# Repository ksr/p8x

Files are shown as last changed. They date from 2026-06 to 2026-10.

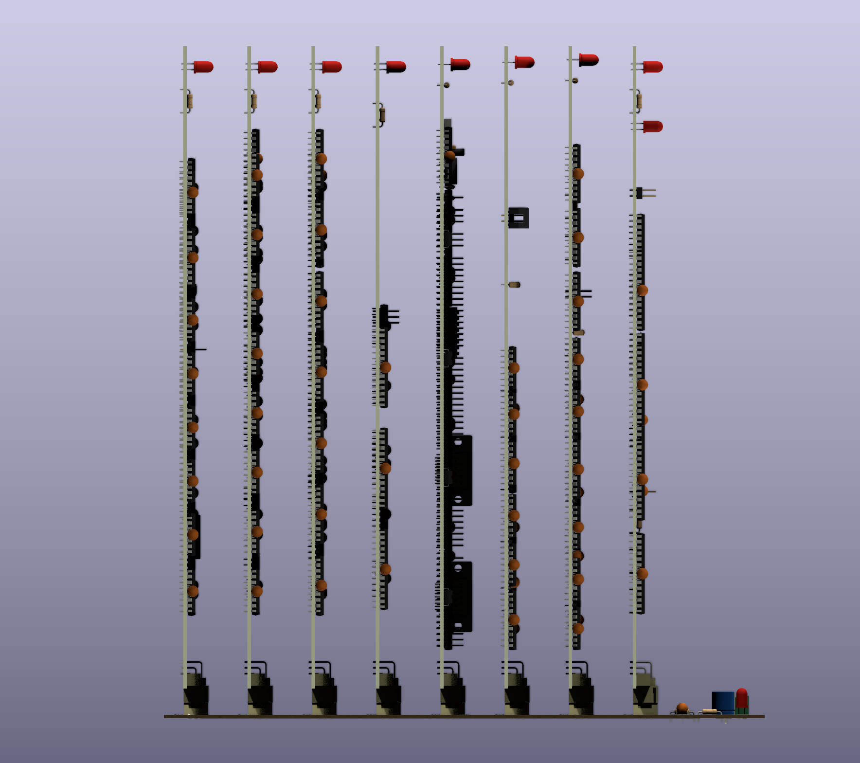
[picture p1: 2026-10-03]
hardware/assembly/p8x-assembly-render-side.png

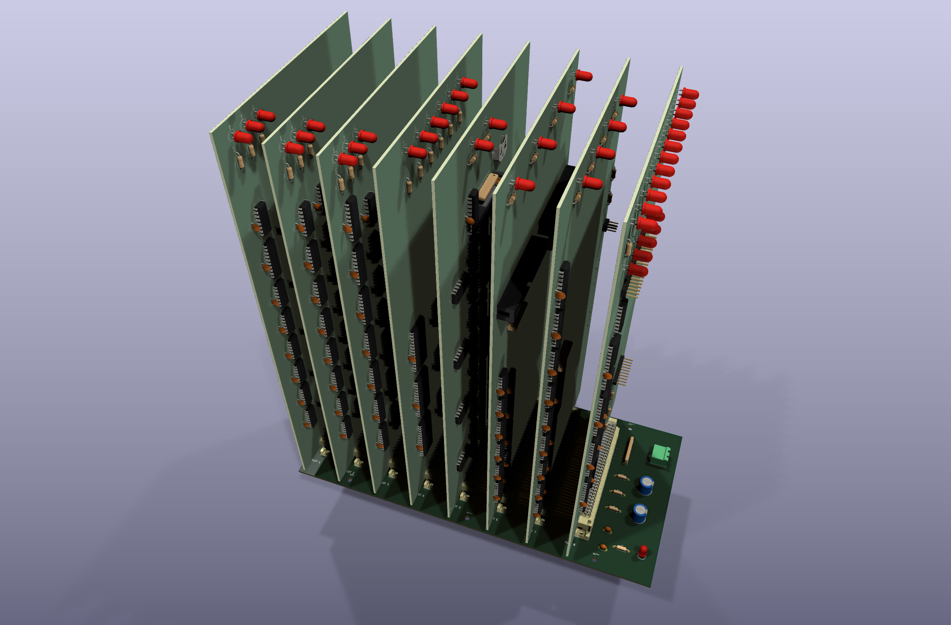
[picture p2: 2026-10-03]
hardware/assembly/p8x-assembly-render.png

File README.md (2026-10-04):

# P8X — Hand-Built 8-Bit TTL CPU

A from-scratch 8-bit CPU built from ~130 74HCT logic chips on an 8-slot DIN41612 backplane. Fully microcoded; the microcode ROM images burned to the EPROMs are the same images the emulator interprets.

The machine now exists **twice**: as the TTL card set, and as an [FPGA
implementation](fpga/) of the same microarchitecture that boots the same
unmodified monitor, OS and toolchain. Both run the microcode from
`microcode/genucode.py`, and the C emulator is the golden reference for both.

The FPGA build also carries a **PGC-class graphics engine** (480x272
RGB565 panel, hardware 3D transforms, command lists, a fabric-parsed
graphics language modeled on the Matrox PG-640A) — see the
[theory of operation](docs/p8x-graphics-theory.md) and the
[graphics programmer's guide](docs/p8x-graphics-guide.md).

New to the abbreviations and signal names? See [GLOSSARY.md](GLOSSARY.md).

**Who made it:** I designed P8X, and it runs on an FPGA. Claude, Anthropic's AI, has been directly involved in its design, coding and documentation. — Ken Rother

## Architecture

- **8-bit data bus, 16-bit address bus**
- **4 × 16-bit pointer registers** (74169 up/down counters): P0 = PC, P1/P2 = general-purpose, P3 = stack pointer (empty-descending). The address bus is *always* driven by one of these — no separate MAR.
- **Registers:** A, B (ALU operands), T/T2 (hidden microcode temporaries), FLAGS (C, Z, N, V)
- **ALU:** 2 × 74181 + 74182 carry-lookahead, with a post-ALU shifter
- **Microcoded control:** 4 × 28C64 EEPROMs; ROM address = IR | step<<8 | cond<<12; **143 opcodes** defined in `microcode/genucode.py` (256 encodings available)
- **Memory map (rev E):** `$0000–$17FF` ROM (6 KB; shrunk from 8 KB 2026-09-14), `$1800–$FEFF` RAM (2× 62256; $1800–$1FFF is a scratch island), `$FF00–$FFFF` I/O (every data address is single-sourced in [`generators/gen_memmap.py`](generators/gen_memmap.py) → `memmap.inc`/`.h`/`.py`; commands pull the scratch/graphics/TPA-base symbols via `//#use mem`)

## Cards

The TTL machine is six core cards plus a PS/2 input card on the backplane, and a
bus test card for bring-up. Every board is designed and routed in **KiCad** (4-layer;
the plug-in cards are 280 × 140 mm) with orderable Gerbers in `hardware/<board>/kicad/`;
none has been fabricated yet. See [hardware/KICAD-BOARDS.md](hardware/KICAD-BOARDS.md)
and [hardware/RECONCILIATION.md](hardware/RECONCILIATION.md) (build readiness).

| Card | Function |
|---|---|
| Control / Microcode | Clock, reset, sequencer, microcode EPROMs, IR, condition mux, front-panel |
| Register Bank | P0–P3 16-bit pointer registers, address bus drivers |
| ALU | A, B, T, T2 registers; 74181 ALU; shifter; FLAGS |
| Memory | 28C256 EEPROM (6 KB ROM window) + 2× 62256 SRAM, address decode (rev F) |
| I/O | Switches, LEDs, bus monitor, two 6850 ACIAs (RS-232, two DB9s) |
| CF-IDE | Two CompactFlash drives in 8-bit True IDE mode, at $FF10–$FF17 and $FF18–$FF1F |
| PS/2 | Keyboard + mouse ports at $FF58–$FF5F; an ATmega1284P behind a latch bridge |
| Bus test | Bring-up tool: a Raspberry Pi Pico drives the bus one microcycle at a time over USB |

The cards plug into a passive 8-slot backplane over a 96-pin DIN 41612 bus (rev C2).
The Eagle CAD of the first board generation is frozen (rev E) in each board's
`eagle-deprecated/` directory.

## Toolchain

| Tool | Location | Purpose |
|---|---|---|
| `microcode/genucode.py` | `microcode/` | Microcode generator → `u0–u3.bin` EPROM images |
| `assembler/p8xasm.py` | `assembler/` | Two-pass assembler, shares opcode table with genucode.py |
| `emulator/p8xemu.c` | `emulator/` | Cycle-accurate emulator, interprets the same u0–u3.bin images |
| `firmware/p8xmon.asm` | `firmware/` | ROM monitor (E/D/I/F/B/G/? commands) + BIOS jump table at `$0100` |
| `os/p8xos.asm` | `os/` | P8X/OS, RAM-resident disk OS booted from CF ([guide](os/README.md)) |
| `tools/p8xfs.py` | `tools/` | Host-side P8XFS disk-image tool (create/boot/put/get/ls) |
| `basic/p8xbasic.asm` | `basic/` | BASIC interpreter — disk-bootable or run-from-OS builds ([guide](basic/README.md)) |
| `apps/p8xedit.asm`, `apps/p8xasm.asm`, `apps/p8xcc.asm` | `apps/` | On-target toolchain: line editor + native two-pass assembler + native C compiler (`cc`), as `/bin` programs ([guide](apps/README.md)) |
| `compiler/p8cc.py` | `compiler/` | C cross-compiler (subset) → P8X asm → RUNnable `.bin` ([guide](compiler/README.md)) |
| `generators/gen_p8xopc.py` | `generators/` | Opcode table for the native assembler, generated from `genucode.OPC` |
| `generators/gen_eagle.py` | `generators/` | The canonical board netlists (`CARDS`, `busnet()`); its Eagle output is frozen at rev E |
| `generators/gen_kicad.py`, `build.sh` | `generators/` | KiCad boards from those netlists: placement, Freerouting, Gerbers, and the ERC/DRC readiness check |

**Generators are canon.** Never hand-edit board files (`.kicad_pcb`, and the frozen Eagle `.sch`/`.brd`) or ROM binaries — they are build artifacts. Edit the generator and regenerate. See [generators/README.md](generators/README.md) for what each script does and how to run it.

## Quick Start

Setting up a new machine? See [SETUP.md](SETUP.md) for the full toolchain, tier by
tier, and run `python3 tools/setup_check.py` to see what is installed and what each
work area still needs. Only the core-software tier is required to build and test.

```sh
# Build the emulator and regenerate microcode images
cd emulator && make

# Run the smoke tests (message print, JSR/RTS round-trip, branch countdown)
make test

# Rebuild a KiCad board: placement -> Freerouting -> Gerbers + renders -> the
# ERC/gate-sim/DRC/keepout/fab readiness check (needs KiCad 10 and a Freerouting
# jar; `all` builds every board). The netlists come from generators/gen_eagle.py.
cd ..
sh generators/build.sh memory-card
sh generators/check_card.sh memory-card          # the readiness check alone

# Reference PDFs (run from anywhere):
cd hardware
python3 ../generators/gen_bus_pdf.py              # bus definition PDF (hardware/backplane/)
python3 ../microcode/gen_progguide.py             # programmer's guide (-> docs/)
```

### EEPROM / programmer images

Both build paths emit **Intel HEX** alongside the raw `.bin`, for loading into an
EEPROM programmer:

- **Microcode** — `microcode/genucode.py` writes `u0–u3.bin` (what the emulator
  and tests load); the matching Intel HEX for the four 28C64 control-store EPROMs
  is produced into `rom/` by `make rom` (see below).
- **Program ROM** — the assembled monitor + BIOS for the 28C256 at `$0000`
  (about 4.9 KB of the 6 KB window; BASIC is no longer ROM-resident). `make rom` builds it into `rom/`.
- **Any other binary** — `python3 tools/bin2hex.py in.bin out.hex [base]`
  (e.g. a monitor built directly with `p8xasm.py`).

For a ready-to-burn set at fixed paths, run `cd emulator && make rom` (or
`sh tools/build_rom.sh`). It refreshes the four control-store EPROMs in
`microcode/` and writes the program ROM to `rom/p8x-prog-rom.{bin,hex}`. Both
are committed; see [rom/README.md](rom/README.md) for the chip map.

## Documentation

The documents below are also built into the project website, [p8x.cottageworker.com](https://p8x.cottageworker.com) (`website/`, MkDocs; published on every push to `main`).

| Document | Description |
|---|---|
| [hardware/backplane/p8x-bus-definition.md](hardware/backplane/p8x-bus-definition.md) | Authoritative 96-pin bus pinout, signal descriptions, DOE/DLD encoding, microcode word layout |
| [hardware/backplane/p8x-backplane-design.md](hardware/backplane/p8x-backplane-design.md) | PCB stackup, termination analysis, BOM |
| [docs/p8x-card-standards.md](docs/p8x-card-standards.md) | Design rules that apply to every plug-in card |
| [docs/p8x-system-design.md](docs/p8x-system-design.md) | System and card-by-card architecture reference |
| [hardware/cf-card/p8x-cf-os-design.md](hardware/cf-card/p8x-cf-os-design.md) | CF-IDE hardware + P8X/OS design |
| [hardware/cf-card/p8xfs-v2-hierarchical.md](hardware/cf-card/p8xfs-v2-hierarchical.md) | P8XFS v2 hierarchical filesystem spec |
| [docs/p8x-programmers-guide.pdf](docs/p8x-programmers-guide.pdf) | Generated instruction set reference |
| [basic/p8x-basic-guide.md](basic/p8x-basic-guide.md) | P8X BASIC language reference (statements, expressions, graphics, examples) |
| [fpga/README.md](fpga/README.md) | FPGA build: milestones, getting started, both paths |
| [fpga/docs/architecture.md](fpga/docs/architecture.md) | FPGA module hierarchy, peripheral map, graphics, co-sim spec |
| [fpga/rtl/README.md](fpga/rtl/README.md) | What is shared vs sim-only, and the `cen` / `sc_en` contracts |
| [fpga/sim/README.md](fpga/sim/README.md) | How the co-sim trace-diff works, and the graphics frame diff |
| [BACKLOG.md](BACKLOG.md) | Live work only: NEXT / IDEAS / VERIFY / WONT-DO |
| [BACKLOG-DONE.md](BACKLOG-DONE.md) | Completed work + the project log |

### Per-card guides

Each board has its own directory under `hardware/` holding everything about it —
the KiCad board and its Gerbers, placement PDF and renders (`kicad/`), a README
explaining how the circuit works chip by chip, any board-specific design docs, and
the frozen Eagle files (`eagle-deprecated/`):

| Card | Directory |
|---|---|
| Control / Microcode | [hardware/control-card/](hardware/control-card/README.md) |
| Register Bank | [hardware/regbank-card/](hardware/regbank-card/README.md) |
| ALU | [hardware/alu-card/](hardware/alu-card/README.md) |
| Memory | [hardware/memory-card/](hardware/memory-card/README.md) |
| I/O | [hardware/io-card/](hardware/io-card/README.md) |
| CF-IDE | [hardware/cf-card/](hardware/cf-card/README.md) |
| PS/2 | [hardware/ps2-card/](hardware/ps2-card/README.md) |
| Bus test | [hardware/bustest-card/](hardware/bustest-card/p8x-bustest-card-design.md) |
| Backplane | [hardware/backplane/](hardware/backplane/p8x-backplane-design.md) |

## FPGA implementation

A standalone [FPGA build](fpga/) on a **Sipeed Tang Nano 20K** (Gowin GW2AR-18)
runs the whole machine — CPU, memory, ACIA console, microSD disk, and a 4.3"
480x272 graphics panel — from one chip and a USB cable. It is a **parallel track to the TTL build, not a replacement**:
same horizontal microcode word, same sequencer, same pointer/address model, so
the monitor, OS, BASIC, C compiler and assembler run **unmodified**.

| Milestone | State |
|---|---|
| 0 First light (UART echo + heartbeat) | done |
| 1 CPU core in simulation, all 88 opcodes of the time | done |
| 2 ACIA + driven console in simulation | done |
| 3 Core on real hardware, full 64K map | done |
| 4 microSD disk — P8X/OS boots from card | done |
| 5 Clock-up + IRQ | next |
| 6 Graphics: 480x272 panel + drawing engine | done |

As built: **9 MHz** effective (27 MHz fabric, three phases per microcycle). The
CPU-only build is 40/46 block RAMs at ~48 MHz Fmax; adding the graphics panel takes
it to 44/46 and 13288/20736 LUT4, with Fmax measured at 38.8 MHz — still four times
the clock it runs at. P8X is programmed into the board's flash, so it comes up
standalone on power.

**Graphics** (`build.sh lcd`) adds the panel's native 480×272 framebuffer in
**RGB565 direct colour** — a pixel IS its colour, 65,536 of them — living in
the Tang Nano's in-package SDRAM behind a streaming controller, with a drawing
engine driven by BASIC in one window-space coordinate system (y up, the
PGC's own): `COLOR r,g,b` (or one packed value), `CLS`, `PIXELW`, `LINE`,
`BOX`, `CIRCLE` (a second radius gives an ellipse), `IMAGE` (draws a
P8I picture file — `tools/p8img.py` converts anything into one), the
`PIXELR(x,y)` and `RGB(r,g,b)` functions — plus the full PGC graphics
language as native statements (`MOVE`/`DRAW`/`POLY`/`RECT`, matrices, 3D,
command lists; see `man basic`). Text is the PGC's own stroke `TEXT`,
drawn card-side from the font the OS streams from `/FONT.GL` at boot
(GTEXT and its software rasterizer retired 2026-09-01). The drawing
statements emit that language; the engine lives in the device, so a
filled box costs the same handful of instructions as an empty one.
There is one geometry and no modes or palette to manage.
The same device is modelled in `p8xemu`, and the two are byte-compared frame
by frame.

**3D** (stages 7–8, `fpga/tang-nano-20k/sdram/STAGE*.md`): a wireframe
pipeline available three ways from C — all in software (`//#use gfx` +
`//#use g3d`), accelerated by the **MDU** (a memory-mapped hardware
multiply-divide unit at `$FF30`), or fully in fabric via the **geometry
engine** (`$FF40`): edge lists in SDRAM, an S7.8 matrix, one command to
transform/clip/project/draw, and page-flipped double buffering. The same
program picks the fastest fitted path at runtime; `cube` on the shipped disk
demonstrates all of them (`man cube`, `man g3d`).

**Verification is the point.** Every milestone is "make the RTL match the
emulator": the same program runs on both and their per-cycle architectural state
is diffed, so a divergence is a bug with an exact microcycle and signal rather
than a mystery. `fpga/sim/isa_test.asm` drives the original 88 opcodes through that diff;
the 55 added since are microcode only (no new hardware), and the RTL runs them from
the same images.

```sh
fpga/sim/run.sh 60000 isa_test.asm          # co-sim, the original 88 opcodes
fpga/sim/console.sh "" os/run-disk.img      # interactive console on the RTL
fpga/tang-nano-20k/build.sh cpu load        # build + program the board
```

## Status

- Emulator working: 143 opcodes, ACIA on stdin/stdout, CF-IDE disk model (`-c <img>`), interactive I/O card (switches `-s`, LED trace `-L`), verified against microcode images
- Assembler working: two-pass, full expression support, shares opcode table with microcode generator
- KiCad boards designed and routed for the six CPU cards, the PS/2 card, the bus test card and the backplane (9 boards, 0 unconnected, Gerbers in each `kicad/`); none fabricated yet. The Eagle files of the first generation are frozen in `eagle-deprecated/`. (The standalone LED test card was a CAD-workflow trial, never built — deprecated and moved to `hardware/deprecated/led-card/`; its I/O address `$FF0C` is now free.)
- ROM monitor boots in the emulator; its filesystem hooks (`I`/`F`/`B`) run end to end against a CF image (`make test-cf`)
- P8X/OS v1.0 — full shell over flat **and hierarchical (P8XFS v2)** volumes. Built-in commands: `cd`/`mkdir`/`rmdir`/`load`/`run`/`save`/`del`/`path`/`pack`/`fsck`/`format`/`mount`/`umount`/`help`/`exit`/`man`/`sh`/`make`/`bootload` (`make` builds a target from a CWD `Makefile`; `bootload file` installs a freshly-built OS image into the boot sectors so the next `exit`+`B` runs it — the on-target OS-update step, closing the self-hosting loop) (the minimal-kernel split moved the pure-viewer/memory commands to `/bin`, including `dump`/`dep` — only `pack`/`fsck` remain resident because they mutate/scan the filesystem). **Dual CompactFlash** — a second card is **mounted at `/d1`** in one unified namespace (drive 0 is the root), so ordinary paths reach it with drive-unaware commands: `cd /d1`, `cat /d1/NOTES`, `grep x /d1/SRC/*.C`, cross-mount `cp /d1/A /B`. A single mount redirect in `FRESOLVE`/`RV_START` does the routing; **`cp -r /d1/dir /dir`** recursively copies a subtree across the mount (card provisioning), creating directories via the `SYS_MKDIR` syscall. **Userland commands in `/bin`** (written in C, run by bare name via implicit RUN + a `/bin` search PATH, or explicit `run`): **`dir`/`pwd`/`tree`/`cat`/`wc`/`grep`/`cp`/`mv`/`head`/`tail`/`more`/`sort`/`uniq`/`sed`/`awk`/`find`/`diff`/`cmp`/`vi`/`touch`/`man`/`dump`/`dep`/`examine`/`disasm`** (`dir README.TXT` lists a file / `dir R*` a glob, `dir -R`, `cp -r`, a VT100 `vi` screen editor, `man <cmd>` reading `/man`, `awk '{print $2}'` field processing, `examine` = interactive memory examine/modify like the monitor's `E`, etc.) — see [os/commands/](os/commands/README.md). Path resolution + CWD-path prompt; I/O redirection (`<`/`>`) and two-stage pipes (`a | b`); line editing (backspace/DEL, Ctrl-D EOF, **up/down-arrow command history** — an 8-line RAM ring — and **Tab autocomplete** of commands/paths with common-prefix fill + a match list on the second Tab); **`pack`** compacts the directory tree and **`fsck`** checks integrity on-target; host-side `p8xfs.py` builds (`--v2`), navigates, and `fsck`s images (`make test-os`)
- BASIC builds two ways from one source: disk-bootable (`B`) and a run-from-OS TPA program (`run BASIC.bin`) — `make test-basic` (ROM-resident BASIC was removed to reclaim ROM space; the old standalone `$0000` build was retired in 2026-08 when BASIC's console I/O moved onto the BIOS, which needs the monitor resident)
- On-target toolchain: **EDIT** (line editor) + **ASM** (native two-pass assembler) + **CC** (a from-scratch C compiler written in asm) as `/bin` programs — edit → **compile (`cc x.c >x.asm`)** → assemble → run a program entirely on the machine; ASM output is byte-identical to the host assembler across the whole opcode table (`make test-os`, see [apps/](apps/README.md)). **Rebuild any command on-target** — every command's source rides along under `/src/commands/{c,asm}` (plus shared `lib_*` helpers), each dir carrying a real **`Makefile`** (`target: deps` + TAB recipe, with `all`/`clean`/`install` targets). The **`make`** built-in reads the CWD `Makefile`, resolves prerequisites depth-first (shared deps built once), and drives `cc`→`asm` (or `asm` alone): `cd /src/commands/c && make pwd` rebuilds one command, `make all` the whole dir into `bin/`, `make install` publishes them over `/bin`, `make clean` removes the build outputs — see [os/commands/](os/commands/README.md). (P8X shell scripts end in `.sh`; `make` uses proper Makefiles.)
- **Native C compiler — Milestone B achieved.** `apps/p8xcc.asm` (`/bin/cc`) is a from-scratch, single-pass C compiler written directly in assembly, small enough to compile C **entirely on the machine** (front *and* back end) where the optimizing `p8cc.c` codegen — ~82 KB, larger than the whole 64 KB address space — never could. Through v0.28 it covers: functions, direct **and mutual** recursion, pointers + pass-by-reference, `int`/`char` arrays with `[]` and decay, **structs** (`.`/`->`), globals, the full operator set (`+ - * / % << >> & ^ | && || ?:`, `++`/`--`/`+=`/`-=`, comparisons, unary `- ! * &`), hex/char/string literals with escapes, `//`+`/* */` comments, a recursive **`//#use`** preprocessor (splices `/lib/lib_*.c`) plus object-like **`//#define`** macros (e.g. `//#use abi` names the BIOS/OS addresses so a command writes `bios(FOPEN, RDBUF, 0)`), and the `putchar`/`puts`/`getchar`/`peek`/`poke`/`argstr`/`bios` builtins. It compiles real OS command source: **`pwd.c` → `cc` → `asm` → runs** correctly on-target. Known gaps are listed under "cc — KNOWN LIMITATIONS" in `BACKLOG-DONE.md` (with the Milestone A/B record).
- **Host C compiler** — `compiler/p8cc.py` (the primary build tool: every `/bin` command is compiled with it) plus `compiler/p8cc.c`, the same compiler rewritten in its own subset that **self-compiles** ("small C in small C", Milestone A). Full subset incl. `struct`/`union`, global initializers, and the operators above (`make test-c`, host-vs-self differential `c_selfhost_test`, see [compiler/](compiler/README.md)).
- BIOS **file API**: byte streams (`FOPEN`/`FGETB`, `FWOPEN`/`FPUTB`/`FCLOSE`), path resolution into subdirectories (`FRESOLVE`), name formatting (`FNORM`), and directory iteration (`FOPENDIR`/`FNEXT`) — the assembler rides on the streams and self-hosts (`make test-cf`)
- **FPGA (Tang Nano 20K):** the same microarchitecture in Verilog, verified against the emulator cycle-for-cycle across the original 88 opcodes, then run on real hardware — monitor over USB serial, full 64K map, and **P8X/OS booting from a microSD** with the whole `/bin` toolchain. The board wrote its own disk: `fpga/tang-nano-20k/tools/imgload.asm` streams a P8XFS image over the console and writes it with `CFWRITE`, so no host root or card reader is needed. See [fpga/](fpga/README.md)
- **Next:** multi-stage pipes (`a | b | c`); open-by-name as one syscall (`SYS_OPEN`); the IRQ-controller hardware card; hardware bring-up (DIN 41612 footprint check against the physical connectors, order the backplane first); FPGA milestone 5 (clock-up + IRQ). Current state in [docs/p8x-status.md](docs/p8x-status.md), the working list in [BACKLOG.md](BACKLOG.md)

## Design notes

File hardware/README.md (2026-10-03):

# hardware/

The physical machine: one passive backplane, six plug-in CPU cards, a PS/2 input
card, and a bus test card for bring-up. Each board has its own directory holding a
chip-by-chip README, a theory of operation or design doc, and the **KiCad** board
(`kicad/`: the `.kicad_pcb`, the Freerouting session, orderable Gerbers, a
placement PDF and renders). Every board is designed and routed; none has been
fabricated yet. Board status: **[KICAD-BOARDS.md](KICAD-BOARDS.md)**; build
readiness against the emulator and the FPGA: **[RECONCILIATION.md](RECONCILIATION.md)**.

| Board | Directory | Function |
|---|---|---|
| Control / Microcode | [control-card/](control-card/README.md) | Clock, reset, sequencer, microcode EPROMs, IR, condition mux, front panel |
| Register Bank | [regbank-card/](regbank-card/README.md) | P0–P3 16-bit pointer registers, address-bus drivers |
| ALU | [alu-card/](alu-card/README.md) | A/B/T/T2 registers, 74181 ALU, shifter, FLAGS |
| Memory | [memory-card/](memory-card/README.md) | 28C256 ROM (6 KB window, `$0000–$17FF`) + 2× 62256 SRAM, address decode (rev F) |
| I/O | [io-card/](io-card/README.md) | Switches, LEDs, bus monitor, two 6850 ACIAs (`$FF04/05`, `$FF08/09`) with two DB9s (rev B) |
| CF-IDE | [cf-card/](cf-card/README.md) | Two CompactFlash drives in 8-bit True IDE mode: `$FF10–$FF17` and `$FF18–$FF1F` (rev B) |
| PS/2 | [ps2-card/](ps2-card/README.md) | Keyboard + mouse at `$FF58–$FF5F`: an ATmega1284P behind a latch bridge (rev A) |
| Bus test | [bustest-card/](bustest-card/p8x-bustest-card-design.md) | Bring-up tool: a Raspberry Pi Pico drives the bus over USB, one microcycle at a time |
| Backplane | [backplane/](backplane/p8x-backplane-design.md) | 8-slot passive 96-pin DIN 41612 bus (rev C2), 262 × 128 mm |

The plug-in cards are all 280 × 140 mm, 4-layer (signals on the outer layers, GND
and +5 V planes inside).

**Eagle (frozen).** The first board generation was drawn in Eagle/Fusion from
`generators/gen_eagle.py`. On 2026-09-18 the KiCad flow replaced it: each board's
Eagle `.sch`/`.brd` and its schematic and placement PDFs moved to
`<board>/eagle-deprecated/`, frozen at rev E, and are no longer maintained (the
Eagle memory card still carries the old 8 KB ROM decode; the KiCad rev F board has
the 6 KB one). `gen_eagle.py` stays the source of the netlists.

> **Deprecated:** the standalone **LED test card** (a write-only 8-LED output
> latch that decoded `$FF0C`) was a CAD-workflow trial, never built. It has been
> moved to [`deprecated/led-card/`](deprecated/led-card/) and its I/O address
> `$FF0C` is now free. (This is unrelated to the `$FF02` LED latch the emulator
> traces, which stays.) The combined I/O + CF + PS/2 **peripheral card** is parked
> in `parked/peripheral-card/` (2026-09-19); the design went back to three cards.

### Not yet realised as TTL boards
See **[RECONCILIATION.md](RECONCILIATION.md)** for the full board-vs-emulator/FPGA
build-readiness pass. Subsystems the emulator and/or the FPGA already provide that
have **no TTL card** yet:

| Subsystem | Where it lives now | TTL board |
|---|---|---|
| MDU multiply/divide (`$FF30–$FF3F`) | emulator model + FPGA (`mdu_core.v`) | none yet |
| Graphics-language port (`$FF50–$FF54`) | emulator model + the Tang Nano 20K graphics card | none (the FPGA card *is* the graphics engine) |
| IRQ controller (`$FF06` device-IRQ model) | emulator model | none yet — the next card to design |

**[assembly/](assembly/README.md)** — 3D renders of the assembled machine: the
backplane with all eight cards standing in their slots, each card populated
(rendered from the boards by `generators/render_assembly.py`; slot order inside).

`p8x-bom.csv` — the orderable bill of materials for the whole machine
(ICs, sockets, connectors, passives), generated by
[`../generators/gen_bom.py`](../generators/).

## Rebuilding boards

**Generators are canon** — never hand-edit a `.kicad_pcb`. The netlists live in
[`../generators/gen_eagle.py`](../generators/) (`CARDS`, `busnet()`);
`gen_kicad.py` turns a card into a placed KiCad board (the memory, I/O, CF, PS/2
cards and the backplane have bespoke placement scripts in their `kicad/`
directories), Freerouting routes it, and `check_card.sh` runs the readiness check
(ERC, gate-level simulation where a testbench exists, DRC, mounting-hole keepout,
fab minimums). One command does all of it, from the repository root:

```sh
sh generators/build.sh memory-card      # one board (or: all)
sh generators/check_card.sh memory-card # the readiness check alone
```

It needs KiCad 10 and a Freerouting jar. See
[../generators/README.md](../generators/README.md) for the scripts and
[../docs/p8x-card-standards.md](../docs/p8x-card-standards.md) for the rules
every card follows.

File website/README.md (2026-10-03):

# website/ — the P8X project website

The project website is built from this repository's own documents with [MkDocs](https://www.mkdocs.org/) and the
[Material](https://squidfunk.github.io/mkdocs-material/) theme. The documents stay where they are; the site is
a readable view of them, with navigation and search.

| File | What |
|---|---|
| `home.md` | the visitor home page (the site's index) |
| `p8x-collage.jpg` | the home page's lead picture: the assembled-machine renders and the memory card (until there are photos of built boards) |
| `stage.py` | copies the documents the site uses into `stage/`, keeping their repository paths so the links between them work, and generates the extra pages |
| `hooks.py` | MkDocs hook: a link to a repository file that is not part of the site becomes a link to that file on GitHub (branch `main`) |
| `mkdocs.yml` | the site: navigation, theme, Markdown extensions |
| `mkdocs-publish.yml` | `mkdocs.yml` + the Google Analytics tag (G-X7P96DTCNE); only the published build carries it |
| `requirements.txt` | the Python packages, pinned |
| `build.sh` | stage + build (installs the packages into `venv/` on the first run, which needs the network) |

    website/build.sh            build into website/site/
    website/build.sh serve      ... and serve it at http://127.0.0.1:8766 (Ctrl-C stops it)
    website/build.sh publish    the build to publish (with Google Analytics)

`venv/`, `stage/` and `site/` are rebuilt each time and not committed. Previews leave the analytics tag out, so
looking at the site locally is not counted as a visit.

**Publishing.** `.github/workflows/website.yml` runs on every push to `main` (or by hand: Actions -> website -> Run
workflow): it builds `website/build.sh publish` on GitHub's machine, so every push proves the site builds. It deploys
to GitHub Pages only when the repository variable `PAGES_DEPLOY` is `true` (Settings -> Secrets and variables ->
Actions -> Variables) and Pages is on (Settings -> Pages -> Source: GitHub Actions); until then nothing is published.
The address will be `https://p8x.cottageworker.com` (a CNAME record at the domain's DNS host, Gandi, and the custom domain in
Settings -> Pages); `site_url` in `mkdocs-publish.yml` already names it.

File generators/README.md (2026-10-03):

# Generators

Python scripts that produce the P8X's boards, reference PDFs and shared tables from
code.

> **Generators are canon.** Board files (`.kicad_pcb`, and the frozen Eagle
> `.sch`/`.brd`), the schematic and reference PDFs and the ROM images are *build
> artifacts* — never hand-edit them. Change the generator and regenerate. See the
> project [CLAUDE.md](../CLAUDE.md) for the full rule set.

The PDF scripts need `reportlab` (`pip3 install reportlab`). The KiCad scripts run
under KiCad 10's bundled Python (they import `pcbnew`) and route with a Freerouting
jar (`FRJAR`, default `~/freerouting/freerouting.jar`).

## Boards (KiCad)

Every board is a 4-layer KiCad PCB in `hardware/<board>/kicad/` (signals on the
outer layers, GND and +5 V planes inside; plug-in cards 280 × 140 mm). The flow
replaced Eagle on 2026-09-18; see [`../hardware/KICAD-BOARDS.md`](../hardware/KICAD-BOARDS.md)
for the status of each board.

| Script | What it does |
|---|---|
| `gen_eagle.py` | **The netlists.** Device library (pin maps, packages), the 96-pin DIN 41612 bus map (`busnet()`), and every card's netlist (`CARDS`), imported by everything below. Its own Eagle output is frozen at rev E (see below). |
| `gen_kicad.py <card>` | Generic board builder: turns a `CARDS` netlist into a placed KiCad board — footprints, a bypass cap above each IC, the labelled LED bank, planes, outline |
| `hardware/<card>/kicad/gen_*.py` | Bespoke placement for the memory (`gen_mem.py`, which also applies the rev F 6 KB ROM decode), I/O (`gen_io.py`), CF (`gen_cf.py`) and PS/2 (`gen_ps2.py`) cards |
| `gen_backplane.py` | The backplane board (8 DIN 41612 sockets, power entry, bulk + per-slot caps, wired-OR pull-ups) |
| `kicad_tools.py` | DSN export, routing import, the heal steps after Freerouting, Gerbers and renders |
| `build_kicad_card.sh <card>` | The generic pipeline: generate → export DSN → Freerouting → import + stitch → Gerbers/renders → readiness check |
| `build.sh <card>` (or `all`) | One command per board: dispatches to the bespoke `kicad/build.sh` or to `build_kicad_card.sh` |
| `check_card.sh <card>` (or `all`) | The manufacture-readiness check: ERC, gate-level simulation (where a testbench exists), DRC, mounting-hole keepout, fab minimums → PASS/FAIL |
| `gen_erc.py` | The netlist electrical-rules check `check_card.sh` runs |
| `gen_bom.py` | The bill of materials → `hardware/p8x-bom.csv` |
| `render_assembly.py` | 3D renders of the assembled machine: each card exported as a STEP and seated in its backplane slot (transform derived from the connector pads and models) → `hardware/assembly/*.png`; driver `sh hardware/assembly/build.sh` |

```sh
sh generators/build.sh memory-card        # one board, build + verify
sh generators/build.sh all                # every board
sh generators/check_card.sh all           # the readiness check alone
```

### `gen_eagle.py` and the frozen Eagle boards

`gen_eagle.py` is the single source of truth for the hardware netlists. It also
still contains the Eagle emitter that drew the first board generation (Autodesk
Eagle/Fusion schematic + board pairs, forward-annotated but unplaced). Those files
were moved to each board's `eagle-deprecated/` directory on 2026-09-18 and are
frozen at rev E — the Eagle memory card keeps the old 8 KB ROM decode; the KiCad
rev F board has the 6 KB one. Running `gen_eagle.py` directly still writes the
Eagle pairs into per-board subdirectories of the current directory, so do not run
it from `hardware/` unless the Eagle files are what you want; the KiCad scripts
import it and do not need that step.

`render_traditional_auto.py` (schematic PDFs drawn from `CARDS`) and
`render_board_pdf.py` (placement views of the Eagle `.brd`) belong to the Eagle
flow; their PDFs are in the `eagle-deprecated/` directories with the boards. The
KiCad flow makes its own placement PDF per board.

## Reference documents and tables

| Script | Produces | Output |
|---|---|---|
| `gen_memmap.py` | **The memory map** — every data address: `memmap.inc` (assembler), `memmap.h` (C), `memmap.py`, and the command libraries `lib_mem.c`/`.inc` | `generators/`, `os/` |
| `gen_memmap_pdf.py` | The printable memory map | `docs/p8x-memory-map.pdf` |
| `gen_isa_card.py` | The instruction-set quick reference (Markdown + PDF), from `genucode.py` | `docs/p8x-isa-card.{md,pdf}` |
| `gen_bus_pdf.py` | Bus-definition PDF (pinout, DOE/DLD tables, microcode word layout) | `hardware/backplane/` |
| `gen_bus_card.py` | The bus reference card | `hardware/backplane/p8x-bus-card.pdf` |
| `render_bp_traditional.py` | Backplane schematic PDF (Eagle-era; the current copy is in `hardware/backplane/eagle-deprecated/`) | `hardware/backplane/` |
| `gen_p8xopc.py` | Opcode-table `.asm` for the native assembler (`OPCTAB`), from `genucode.OPC` | stdout / arg path |
| `gen_p8xdis.py` | The disassembler's opcode table, from `genucode.OPC` | `os/commands/lib_distab.c` (+ `.inc`) |
| `gen_glkw.py`, `gen_font.py`, `gen_chargen.py`, `gen_trig.py` | Graphics tables: the GL keyword table (`glkwtab.*`, `glvtab.inc`), the stroke font (`os/font.gl`), the text-overlay character generator (`chargen.h`/`.hex`), the trig tables (`trigtab.h`) | `generators/`, `basic/`, `os/` |
| `gen_logisim.py` | Logisim circuit export (proof of concept, memory card) | `hardware/memory-card/` |

`gen_p8xopc.py out.asm` emits the `(mnemonic, shape) → opcode` table that
[`apps/p8xasm.asm`](../apps/p8xasm.asm) (the on-target assembler) is built with;
the build concatenates it after the assembler logic. Sourcing it from
`genucode.OPC` keeps the native assembler's encodings locked to the microcode.

The programmer's guide (Markdown + PDF) is generated separately by
[`microcode/gen_progguide.py`](../microcode/gen_progguide.py).

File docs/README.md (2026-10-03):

# docs/

System-wide documentation. (Per-card guides live with their board under
[`../hardware/<card>/`](../hardware/); language and tool guides live next to
their source in `../basic/`, `../os/`, etc.)

| Document | Description |
|---|---|
| [p8x-status.md](p8x-status.md) | Where P8X stands (October 2026): what runs today, the TTL card set's state, what is next. The detail is in [`../BACKLOG.md`](../BACKLOG.md). |
| [p8x-system-design.md](p8x-system-design.md) | System and card-by-card architecture reference; §3.2 has the as-built control-word layout. |
| [p8x-card-standards.md](p8x-card-standards.md) | Design rules every plug-in card must follow (form factor, connector, decoupling, etc.). |
| [p8x-monitor.md](p8x-monitor.md) | ROM monitor command reference and memory map. |
| [p8x-graphics-theory.md](p8x-graphics-theory.md) | Graphics engine theory of operation — the machines inside the card, from bus window to panel. |
| [p8x-graphics-guide.md](p8x-graphics-guide.md) | Graphics programmer's guide — drawing from the shell, BASIC, C and assembly. |
| [p8x-programmers-guide.md](p8x-programmers-guide.md) | CPU programmer's guide (GENERATED — regenerate via `microcode/gen_progguide.py`, never edit; PDF twin beside it). |
| [p8x-isa-card.md](p8x-isa-card.md) | Instruction-set quick reference (GENERATED — `generators/gen_isa_card.py`; PDF twin beside it). |
| [mount-drives-design.md](mount-drives-design.md) | Design record for the Unix-style `/D1` mount of the second CF — shipped; kept for the reasoning. |
| [p8x-two-mode-design.md](p8x-two-mode-design.md) | Two-mode operation: the same OS runs headless-serial OR as a GL graphics desktop (Finder + full-screen apps), selected by a graphics-present flag. Design + phase log (P1–P5 shipped in the emulator). |
| [p8x-isa-c-extensions.md](p8x-isa-c-extensions.md) | **Design note (not shipped on the disk); Tier A implemented on the emulator 2026-09-11:** ISA additions to shrink `p8cc` output — Tier A pure-microcode ops (`(Pn+d8)` displacement addressing, 16-bit memory-word `LDW`/`STW`/`ADDW`/`SUBW`/`CMPW`/`INCW`/`DECW`, `LDPn #imm16`, `ADDP3`/`SUBP3`), Tier B one hardware register (frame pointer P4), Tier C a 16-bit accumulator — with opcodes, microcode step sketches, projected savings, ripple and open questions. Compiler-only wins (−15.1%) landed first; see BACKLOG. |
| [p8x-programmers-guide.pdf](p8x-programmers-guide.pdf) | Generated instruction-set reference (built by `../microcode/gen_progguide.py`). |

The **FPGA** track has its own documentation tree rather than living here:
[`../fpga/README.md`](../fpga/README.md) (milestones + layout),
[`../fpga/docs/architecture.md`](../fpga/docs/architecture.md) (module hierarchy,
memory/peripheral map, co-sim spec), [`../fpga/sim/README.md`](../fpga/sim/README.md)
(how the cycle-for-cycle diff against the emulator works) and
[`../fpga/tang-nano-20k/README.md`](../fpga/tang-nano-20k/README.md) (board build,
pinout, flashing).

The PDF is a generated artifact — regenerate it rather than editing:

```sh
python3 ../microcode/gen_progguide.py      # writes the guide PDF here
```

New to the abbreviations and signal names used throughout these docs? See the
root [GLOSSARY.md](../GLOSSARY.md).

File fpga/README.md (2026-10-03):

# P8X on FPGA

A **standalone** FPGA implementation of P8X — the whole machine (CPU, memory,
UART console, SD disk) in one FPGA, no backplane. It keeps the **same
microarchitecture** as the TTL build: the horizontal microcode word, the
sequencer, the pointer/address model, `DOE`/`DLD`/`PSEL` selects. The microcode
binary (from `microcode/genucode.py`) and the C emulator stay the reference, so
the monitor / OS / BASIC / C-compiler / assembler run **unmodified**.

This is a **parallel track** to the TTL / bus-connected hardware build, which
continues (just delayed). Nothing here touches `generators/` or the card designs.

Target board: **Sipeed Tang Nano 20K** (Gowin GW2AR-18). See
[`tang-nano-20k/`](tang-nano-20k/) for the board-specific files and the
Milestone-0 build.

## The verification spine

Every milestone is "make the RTL match the emulator." We run the **same program**
on an Icarus sim of the RTL and on the C emulator (`emulator/`), and **diff
architectural state** (PC, registers, flags, memory writes) cycle by cycle. The
emulator is the golden model; a divergence is a bug with an exact cycle and
signal. Same adversarial-diff discipline used elsewhere in the project.

## Getting started

Two independent paths. **The simulator needs no hardware** and is the whole of
Milestones 1-2; the board adds 0, 3 and 4.

### Prerequisites

| For | You need |
|-----|---|
| Everything | `python3`, a C compiler (Apple clang / gcc) |
| Simulation | **`iverilog`** — `brew install icarus-verilog` |
| The board | **oss-cad-suite** (yosys, nextpnr-himbaechel, apicula, openFPGALoader) |
| The board | a **Sipeed Tang Nano 20K** and a USB-C **data** cable |

oss-cad-suite is a tarball, not a package: download the `darwin-arm64` (or your
platform's) release from
[oss-cad-suite-build](https://github.com/YosysHQ/oss-cad-suite-build/releases),
extract to `~/oss-cad-suite`, then — on macOS, or every binary refuses to launch:

```sh
xattr -dr com.apple.quarantine ~/oss-cad-suite
```

No admin rights are needed for any of this; `build.sh` sources the environment
itself.

### Step 0 — build the emulator first (both paths need it)

The microcode images `u0-u3.bin` are build products and are **not** in the repo,
and the emulator is the co-sim's reference model. From the repo root:

```sh
cd emulator && make
```

### Path A — simulation only, no hardware

```sh
fpga/sim/run.sh 20000                        # monitor boot, RTL vs emulator
fpga/sim/run.sh 60000 isa_test.asm           # the original 88 opcodes
fpga/sim/run.sh 200000 "" console_in.txt     # driven monitor + console diff
fpga/sim/run.sh 2000000 "" boot_in.txt os/run-disk.img   # boots P8X/OS
```

Each prints `PASS: RTL matches emulator for N cycles`, or a `DIVERGENCE` dump
naming the exact microcycle. To drive the machine by hand instead of diffing:

```sh
fpga/sim/console.sh "" os/run-disk.img       # real terminal into the RTL
```

(The graphics engine is byte-compared against the emulator by the GL RTL
battery, `emulator/test/c_gl_rtl_test.sh` — the old `sim/gfx.sh` device-door
co-sim retired with the single-interface migration.)

`B` boots the OS, then `pwd` / `dir` / `cat README.TXT`. Ctrl-D or Ctrl-C quits.
Writes persist for the session — they land in `fpga/sim/work/disk.img`, a copy, so
your real image is untouched and your changes are replaced next launch.
It is slow but usable — roughly 30-50k CPU cycles/second.

### Path B — the real board

```sh
fpga/tang-nano-20k/build.sh cpu load     # build + program (volatile SRAM)
fpga/tang-nano-20k/build.sh cpu flash    # ... or persist it across power cycles
```

Then talk to it. The onboard bridge enumerates **two** serial devices and the
**higher-numbered one is the console** (the other is JTAG and returns garbage);
use `/dev/cu.*`, not `/dev/tty.*`:

```sh
tang-nano-20k/tools/term.py               # auto-picks the port; Ctrl-] quits
```

`term.py` is a dependency-free terminal that picks the console port for you and
quits with Ctrl-]. A stock terminal is equally fine —
`screen /dev/cu.usbserial-<N>1 115200`, exit with Ctrl-A then k — because the
firmware expands newlines itself (see [`docs/p8x-monitor.md`](../docs/p8x-monitor.md)).

Press Enter for the monitor's `*` prompt. `?` for help, `I` to identify the
microSD, `B` to boot the OS from it.

### Updating the board — TWO surfaces, not one

A change may live in either place, and a feature can need both:

| Surface | Carries | Update with |
|---|---|---|
| **bitstream** | CPU, microcode, monitor ROM, graphics RTL | `build.sh lcd load` |
| **SD card** | P8X/OS, `/bin`, BASIC | `tools/imgsend.py os/run-disk.img` |

The graphics ellipse is the cautionary example: it is RTL **and** a BASIC
statement. Rebuilding only the bitstream left the hardware understanding a
command that nothing on the card could issue, which presents as `?SYNTAX ERROR`
from BASIC — nothing about it points at the card being stale.

**Check `p8x_cpu.fs`'s timestamp after a build.** This concealed two separate
build failures here. The script itself is no longer the hole — it runs under
`set -euo pipefail` and each of synthesise / place-and-route / pack exits `1` on
failure, so `load` cannot be reached after a failed build. What remains is that
**`cpu` and `lcd` write the same `p8x_cpu.fs`**: a failed `lcd` build leaves the
previous file sitting there looking perfectly valid, and it may well be a `cpu`
bitstream with no graphics in it at all. Note also that a `| tail`-style pipeline
hides the exit status, which is how the failure reads as success. If a fix appears
to do nothing on the board, check the mtime before debugging anything else — and if that is current, reload once: a freshly loaded
bitstream has come up not answering more than once, and the same file loaded
again fixed it.

A card needs a P8XFS image on it. Writing one from the host needs root, so if you
do not have it the board can install its own over the serial console — see
[`tang-nano-20k/tools/`](tang-nano-20k/tools/README.md).

**If the board goes silent**, load the Milestone-0 echo bitstream
(`build.sh echo load`) as a known-good baseline; if that is silent too, the USB
bridge has wedged and a replug fixes it. After any replug, drain the port before
testing — the factory boot text sits buffered and reads like a reply.

## Milestones

| # | Milestone | Board? | Proves |
|---|---|---|---|
| **0** | First light: UART echo + heartbeat LED ✅ | yes | toolchain, bitstream, console path |
| **1** | CPU core in simulation ✅ | no | the microarchitecture is correct (all 88 opcodes) |
| **2** | Peripherals in simulation (ACIA-UART) ✅ | no | monitor boots to a sim console; console output diffed |
| **3** | Core on real hardware ✅ | yes | P8X talks over USB for real, full 64K map |
| **4** | SD disk (SD-over-SPI behind the BIOS block API) ✅ | yes | OS boots from SD, full FS |
| **5** | Polish: clock-up, IRQ (backlog #26), stretch goals | yes | performance + extras |
| **6** | Graphics: 480x272 panel + drawing engine ✅ | yes | BASIC draws on a real panel; the engine matches the emulator pixel for pixel across all three payloads |

Milestones 0–2 are most of the effort and only 0 needs the board — the CPU is
built and proven in simulation before the hardware ever runs it.

**Status 2026-08-12: 0–4 done.** P8X/OS boots from a microSD on the Tang Nano
20K. The CPU runs at 27/3 = 9 MHz (three fabric phases per microcycle, see
`tang-nano-20k/rtl/p8x_top.v`) with the full 64K map — affordable because the
microcode ROM is compacted from 8192 to 4096 words, so no SDRAM controller was
needed. Build and flash with `tang-nano-20k/build.sh cpu load`.

P8X is written to the board's **onboard flash**, so it comes up standalone on
power with no host involvement. (`build.sh cpu load` puts a build in volatile
SRAM instead, which is what you want while iterating — but note that a power
cycle then reverts to whatever is in flash, and the factory LiteX demo answers on
the same serial port and will silently swallow anything a script sends it.)

## Layout

```
fpga/
├── README.md                 this file
├── docs/architecture.md      module hierarchy, memory/peripheral map, co-sim spec
├── rtl/                      board-independent core (shared by sim and board)
│   ├── README.md             what is shared vs sim-only, and the `cen` contract
│   ├── p8x_cpu.v             the CPU. `cen` clock enable; otherwise one
│   │                         microcycle per clock, matching the emulator
│   ├── gfx.v                 graphics: registers, drawing engine, framebuffer
│   ├── video_rgb.v           480x272 panel timing + 2x-doubled scanout
│   └── p8x_soc.v             sim-only SoC: async-read arrays + modelled I/O
├── sim/                      co-simulation against the C emulator
│   ├── README.md             how the trace-diff works, and why -N exists
│   ├── run.sh                build + run + diff  [CYCLES] [ROM] [RX] [CF]
│   ├── console.sh            interactive console on the RTL (not diffed)
│   ├── mk_ucode_mem.py       4 ROM images → 32-bit ucode.hex
│   ├── tb_p8x.v              testbench: canonical per-cycle trace, ACIA, CF
│   ├── isa_test.asm          directed exerciser, the original 88 opcodes
│   └── console_in.txt, cf_id.txt, boot_in.txt   scripted keystrokes
└── tang-nano-20k/            the board build
    ├── README.md             toolchain, pinout, flashing, board-sim benches
    ├── build.sh              [echo|cpu|lcd] [build|load|flash]
    ├── mk_compact_ucode.py   8192→4096-word microcode remap (buys the 64K map)
    ├── tangnano20k.cst       pin constraints (verified)
    ├── rtl/
    │   ├── top.v             Milestone-0: UART echo + heartbeat
    │   ├── p8x_top.v         the real SoC: 3-phase microcycle, BRAM, ACIA, CF
    │   ├── uart.v            8N1 UART (TX+RX)
    │   ├── cf_sd.v           $FF10-$FF17 CF task file over the SD controller
    │   └── sd_spi.v          microSD in SPI mode: init, read block, write block
    ├── sim/                  board-level benches (see tang-nano-20k/README.md)
    │   ├── tb_top.v          Milestone-0 echo path
    │   ├── tb_p8x_top.v      whole board top: monitor + OS boot off a card
    │   ├── tb_video.v        panel frame geometry (480x272, 54.11 Hz)
    │   ├── tb_scanout.v      which fb pixel reaches which panel pixel
    │   ├── sd_model.v        behavioural SPI card, with +sdfail fault injection
    │   └── tb_sd_spi.v       sd_spi's error paths
    └── tools/                host-side helpers, none needing root
        ├── README.md
        ├── term.py           serial terminal; translates P8X's bare-LF output
        ├── osload.asm        N sectors → LBA 1.., patch OSCNT
        └── imgload.asm       clone a whole P8XFS image from LBA 0
```

## How we work

- RTL + testbenches + co-sim harness written here; board bitstreams flashed and
  reported from hardware.
- **Sim green before hardware** — never debug unproven RTL and an unproven board
  at once.
- Small commits into `fpga/`, docs alongside, emulator stays the spec.

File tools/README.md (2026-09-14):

# tools/

Host-side (Mac/PC) utilities for building images and managing disks.

| Tool | Purpose |
|---|---|
| `fput.py` | **The everyday transfer tool**: copy host files into the standard disk image (`os/run-disk.img`) — several at once, replacing existing names. The emulator mounts that image directly, so a put is live on its next boot; `--board` then clones the image to the FPGA's card via `imgsend`. |
| `p8xfs.py` | P8XFS disk-image tool — create, boot, put/get/rm/ls/mkdir/tree, and `fsck` disk images (v2 hierarchical, the only format; `rm` tombstones like the on-target FDELETE). `fput.py` is the friendly front end for the transfer case. |
| `p8img.py` | Convert any image (PNG/JPEG/…) to P8I, the display's own RGB565 format, for BASIC's `IMAGE` statement. Floyd–Steinberg dither by default; `--preview` renders what the panel will show. |
| `build_rom.sh` | Build the full persistent **burn set** into [`../rom/`](../rom/): the four control-store EPROM images and the program ROM (the assembled monitor — BASIC is no longer ROM-resident), each as `.bin` + `.hex`. Wired up as `make rom`. |
| `p8cc_sizes.sh` | **Compiler size benchmark**: compile every `/bin` C command through the `run.sh` pipeline (`clib.py` → `p8cc.py` → `p8xasm.py`) and print bytes per command plus a TOTAL; `FAIL` rows expose a compiler regression. Save a baseline before a codegen change and `diff` after. |
| `tierA_rewrite.py` | **Hand-asm Tier A pass**: rewrites the old byte-by-byte 16-bit idioms in a hand-written source (word moves, word constants, `TAPnL/H` pointer loads, `LDA #</#>` pointer constants, `INC`/`ADD #k`/`DEC` carry chains) into single `MOVW`/`LDW`/`LPWn`/`LDPn`/`INCW`/`ADDW`/`DECW` instructions -- only where the next executed instruction cannot observe the A/flags the old sequence left (`--allow` names callees that ignore A). Dry run by default; `--apply` writes in place. Emits native-parseable shapes only, so byte-identity with the on-target assembler holds. Always run the module's tests after it. |
| `bin2hex.py` | Convert any binary to Intel HEX for an EEPROM programmer. Importable (`write(data, path, base=0)`) or CLI (`bin2hex.py in.bin out.hex [base]`). |
| `mkbacklogpdf.py` | Render [`../BACKLOG.md`](../BACKLOG.md) to `../BACKLOG.pdf` — a full, readable render of the live backlog: each section (NEXT/IDEAS/VERIFY/WONT-DO) on its own page, colour-coded `[ ]`/`[x]`/`[~]` markers (kept as bracket tokens so state survives B/W printing), nested items hang-indented, bold/`code`/links inline. Done work lives in `BACKLOG-DONE.md` and is excluded. Needs `reportlab`. The PDF is generated and git-ignored; re-run after the backlog changes. |
| `mkgitignorepdf.py` | Render `../GITIGNORE-TREE.pdf` — a printable reference of everything git ignores: a count table by location, all tracked `.gitignore` files verbatim, and the complete indented tree of currently-ignored files (runs `git` itself). Needs `reportlab`. The PDF is generated and git-ignored; re-run after the ignore set changes. |

## Typical use

```sh
# Build everything an EEPROM programmer needs
cd ../emulator && make rom

# Make a bootable hierarchical OS disk and check it
python3 p8xfs.py create disk.img
python3 p8xfs.py fsck disk.img

# Put files on the standard image (and optionally the real board)
./fput.py notes.txt game.bas          # -> / of os/run-disk.img, replacing
./fput.py photo.p8i --board           # ...then clone the image to the FPGA card
```

See [`p8xfs.py`](p8xfs.py) `--help` for the full subcommand list, and
[GLOSSARY.md](../GLOSSARY.md) for filesystem terms.

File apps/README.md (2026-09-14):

# P8X applications

Standalone **TPA programs** — assembled to load and execute at `$5900` (the
transient program area), launched from P8X/OS with `RUN`. Each is built entirely
on the BIOS jump table (`$0100..`); none depend on OS internals, so they return
to the shell with a plain `RTS`.

Build one with the host assembler and place it on a disk:

```sh
python3 assembler/p8xasm.py apps/p8xedit.asm -o edit.bin --base 0x5900
python3 tools/p8xfs.py put disk.img edit.bin --name /BIN/EDIT.BIN --load 0x5900 --exec 0x5900
```

`os/run.sh` already builds and installs these into a fresh demo disk under
`/BIN`, so a clean `./os/run.sh` boots an OS where `RUN EDIT.BIN NAME` works.

## EDIT — line-oriented text editor (`p8xedit.asm`)

```
RUN EDIT.BIN NAME.EXT
```

On entry the OS hands the program its argument tail in `P2` (the program-arg
ABI); EDIT copies it to `FNAME` and loads that file if it exists, else starts an
empty buffer. Text is held as LF-separated lines in `$C000..$F000` (12 KB).

A file larger than that buffer is **refused** — `FILE TOO LARGE (MAX 12K)`, and
EDIT returns to the OS without a buffer or a filename. It deliberately does not
load the first 12 KB: a part-loaded file is indistinguishable from a short one,
and the first `W` would write it back over the original. Input lines are capped
at 255 characters (`LBUF` is one page at `$BE00`, and the editor's own state
begins at `$BF00`).

| cmd | action |
|-----|---|
| `L` | list every line with its 1-based number |
| `A` | append: type lines, end with a line containing only `.` |
| `I n` | insert before line `n` (n past the end appends); end with `.` |
| `D n` | delete line `n` |
| `W` | write the buffer back to the file (`FDELETE` then `FCREATE`) |
| `Q` | quit to the shell |
| `?` | command summary |

Notes / current limits: line numbers are 8-bit (≤255 lines); `W` rewrites the
whole file, orphaning the old data sectors until the next `PACK`; the editor
reads/writes the **root** directory (the BIOS FS layer is flat — path-aware
saves are a future item). Files use LF (`$0A`) line endings — the form the
on-target assembler (`ASM`) expects as input.

## ASM — native two-pass assembler (`p8xasm.asm`)

```
RUN ASM.BIN SRC.ASM OUT.BIN
```

Assembles `SRC.ASM` (read from the disk) and writes the binary `OUT.BIN`. The
output carries `load/exec = 0` from `FCREATE`, which the OS reads as the TPA
base `$5900` — so a program written `.org $5900` is **directly RUNnable** right
after assembling it. Pair with `EDIT` for a complete on-target edit → assemble →
run loop.

Accepted syntax is a subset of the host assembler, with identical encodings:

| form | example |
|---|---|
| label | `loop:` |
| equate | `COUNT = 3` |
| instruction | `LDA #COUNT` · `STA $C000` · `LDA (P1)+` · `JSR done` |
| two-operand forms | `MOVW __ax,__V+4` · `ADDW __ax,__t0` · `CMPW __ax,#300` · `LDW __V+2,(P3+3)` · `STW (P3+1),__ax` — since 2026-09-12 the native parser handles every Tier A shape the host assembler does (`a,b`, `a,#imm8`, `a,#imm16`, `(Pn+d)`, `a,(Pn+d)`, `(Pn+d),a`; `PARSEOP`/`CLASSOP`, byte-literal rule `LIT8` = the host's), so `cc`'s output and hand sources assemble byte-identically on both. Only the relative branches (`.relax`/`.R`) stay host-only |
| `LDPn #imm16` | `LDP1 #msg` → the 3-byte `LDPn` opcode (`$38`–`$3A`) + imm16 (Tier A; was the `LPLn`/`LPHn` pair) |
| directives | `.org .byte .word .ascii .asciiz .fill` — a string decodes `\n \t \r \0` and `\\ \" \'` as the host assembler does (since 2026-09-13; the on-board `cc` emits C escapes raw for the assembler to decode) |
| expressions | `$hex` · decimal · `'c'` · symbol, joined with `+`/`-`, optional `<`/`>` prefix |

A `;#use NAME` line (at column 0) appends the shared include `/lib/NAME.inc`
after the program body (up to 4 per file, in declared order) — the on-target
mirror of the host `mkasm.sh`, letting a hand-asm command share the same helper
includes (`stdin`/`glob`/`globx`/`regex`) that the C `//#use` shares.

> **`;#use` is live here but inert host-side.** The host `assembler/p8xasm.py`
> sees the leading `;` and skips the line as an ordinary comment; only this
> assembler acts on it. So a source spliced host-side must not keep the
> directive, or the on-target build hunts for an include that isn't on the disk
> while host builds stay green — `mkasm.sh` therefore rewrites the line as it
> splices. The same asymmetry applies to any `;`-prefixed pseudo-directive:
> reproduce toolchain bugs **on-target**, not just on the host. Both the
`SRC` and `OUT` arguments are **path-aware** (a full path, not a 12-char
root-only name), so a source under `/src` can be assembled straight into a
build-output dir: `asm /src/commands/asm/pwd.asm /src/commands/asm/bin/pwd.bin`.
Together these let ASM rebuild the hand-asm `/bin` commands from source on the
machine — the `asm` half of the on-target rebuild loop (`cc` handles the C
half); the `sh` built-in drives it (see
[os/commands/](../os/commands/README.md)).

The opcode table is **generated** from `genucode.OPC` by
`generators/gen_p8xopc.py` and concatenated after the assembler logic at build
time, so the mnemonic/encoding map can never drift from the microcode.

Source and output are both **streamed to/from disk** through the BIOS file
streams — input via `FOPEN`/`FGETB` (a line at a time), output via
`FWOPEN`/`FPUTB`/`FCLOSE` (a sector at a time). So source and output size are
bounded by the disk, not RAM, and the freed RAM gives a large symbol table
(1,664 entries at `$8000`–`$E7FF`). As a result the assembler can **assemble
its own source** on-target, producing a binary byte-identical to the host build
(`emulator/test/asm_selfhost_test.sh`, `make test-asm-selfhost`).

Correctness is checked by assembling a feature source both on-target and with
the host assembler and comparing the bytes (`emulator/test/os_asm_test.sh`).
Limits: 1,664 symbols, 12-char names, 127-char source lines, single `.org`
(use `.org $5900`; a backward `.org` is rejected).

**Redesigned for the Tier A ISA (2026-09-12).** `p8xasm.asm` was rewritten
from scratch as a drop-in (same syntax, same error messages, byte-identical
output; the four `os_asm*`/`asm_selfhost` tests lock it to the host): 16-bit
values are word variables handled with `ADDW`/`SUBW`/`CMPW`/`INCW`/`MOVW`; the
symbol table is a 256-bucket **chained hash** of 16-byte entries (`name[12]
value[2] next[2]`) read and written through `(P2+d)` — `LDW CNT,(P2+12)` fetches
a value in one instruction — instead of a linear scan comparing all 12 bytes of
every entry; the opcode table gets a first-letter index at startup so a mnemonic
lookup scans only its letter group, shape byte first; operand emission is a
jump table (`DISPTAB` + `LPW1`/`JSR (P1)`); `MOVW` and `LDPn` need no special
cases (a lone `#` that fails as imm8 is retried as imm16); `.org` pads forward
itself so `EMIT` is a plain write-and-`INCW`; fixed-size copies are `MOVW`/`STW`
runs. Binary 5,178 → 4,065 B. Cycles (`p8xemu -L`): the coverage source 6.40 M →
2.62 M (2.4×), assembling its own source 282 M → 49.5 M (5.7×), a 1,000-symbol
stress source > 900 M (did not finish) → 29 M. The code + opcode table must
stay below `$8000` (the table start); `os_asm_test.sh` asserts it.

**The C version (`asm.c`, 2026-09-13) — size and speed against the asm one.**
`apps/asm.c` is the same assembler in the p8cc subset: same syntax, error
messages and output, the same raw-memory map above the image (source and
include sectors, path buffers, chain heads). Built by the host toolchain — the
opcode table as C (`opctab.c`, from `gen_p8xopc.py --c`) concatenated ahead of
the source, `//#use abi` spliced, `p8cc.py` — and installed as `/binc/asm.bin`;
`emulator/test/asm_c_test.sh` assembles the coverage source, the feature
program, a `;#use` command, a relative `.include` and the asm assembler's own
source with it, all byte-identical to the host.

| | asm `p8xasm.asm` | C `asm.c` | ratio |
|---|---|---|---|
| binary | 4,116 B | 9,945 B | 2.4× |
| the all-opcode coverage source | 2.62 M cycles | 11.0 M | 4.2× |
| its own 71 KB source (self-host) | 49.5 M | 194 M | 3.9× |
| symbol capacity | 1,664 | 480 (the table starts above the larger image, at `$A800`) | |

Tuned for the compiler like the C BASIC (an add-only hash instead of a 7-step
shift per character, the identifier scan and the byte loop inlined), which
took it from 4.7× to the figures above. The remaining gap is the per-call frame
and the byte-at-a-time pointer walks the compiler emits around every `bios`
byte in and out.

## CC — native C compiler (`p8xcc.asm`)

A from-scratch, single-pass C compiler written directly in assembly — small
enough (~10 KB) to compile C **entirely on the machine**, front and back end.
It streams the source in (BIOS `FOPEN`/`FGETB`, one-char pushback) and emits P8X
assembly to stdout (`SYS_PUTC`, shell-redirectable), which the native `asm`
turns into a RUNnable binary — so C is compiled, assembled, and run on-target:

```
cc hello.c >hello.asm      # native compiler
asm hello.asm HELLO.BIN    # native assembler
run HELLO.BIN
```

This is **Milestone B** (the native route) — the host `p8cc.c` codegen compiles
to far more than the 64 KB address space (its tables are host-sized), so it
can't run on the machine; `cc` uses a deliberately small static-slot codegen
instead.

**Tier A output (2026-09-12).** `cc` now emits the new instructions: a literal is
`LDW __ax,#n`, `+ - & | ^` are `ADDW`/`SUBW`/`ANDW`/`ORW`/`XORW` on the `__ax`/`__t0`
words, a struct offset is `ADDW __ax,#k`, `++`/`--` are `INCW`/`DECW` in place, a
condition test is `CMPW __ax,#0`, an ordering is one `CMPW` and one branch (only
`==`/`!=` still call the 16-bit `__cmp`), unary minus is `XORW #65535`/`INCW`.
Arguments no longer go through the software arg stack: the caller pushes them
left to right with `PHW`, the callee copies them into its static slots with
`LDW __V+2s,(P3+d)` (arg *i* at `P3+3+2(n-1-i)`), and the caller drops them
with `ADDP3`; the caller's live-slot saves (re-entrancy) now precede the
arguments and are discarded rather than restored when an argument took an
address. Programs start like `p8cc`'s: the caller's `P3` is kept in `__sp0` and
the program runs on a stack below `CSTACKTOP` unless launched nested. The
`__add`/`__sub`/`__and`/`__or`/`__xor`/`__neg`/`__pusharg`/`__pop` runtime texts
are gone. **Condition mode:** `if`/`while`/`for` hand `GEXPR` a false-label
(`CONDF`/`CONDLBL`); a relational that ends the condition emits its compare and
ONE branch to that label (`EMITCF`) instead of a 0/1 value and a re-test, and
the statement skips its own `CMPW #0`/`JZ` (`CONDDONE`). A nested `GEXPR`
(call arguments, parentheses, an index) sees the flag cleared and still
produces a value. A statement-level `NAME++`/`NAME--` is one `INCW`/`DECW` on
the slot. Results on the same test program compiled and run on the board:
5,546 → 2,041 bytes (−63%), identical output; `vi.c` built on the board
26,632 → 25,228 bytes. For scale, the Python compiler makes 1,066 bytes of the
same (subset) program and the C-written host compiler 1,107: the on-board
compiler's static-slot model and single pass cost about 2× in size, by design.
**The compiler's own body** went through `tools/tierA_rewrite.py` too (88 word
moves / pointer loads / carry chains → one instruction each; `cc.bin`
22,924 → 20,905 bytes including the new condition-mode code), as did the
assembler's (36 sites; verified byte-identical by `asm_selfhost_test`).

**Rewritten from scratch for the Tier A ISA (2026-09-13).** `p8xcc.asm` is a
drop-in: the code it GENERATES is the same instruction for instruction (checked
by compiling the spliced `pwd`, `wc`, `grep` and `vi` sources with the old and
the new compiler on the machine and diffing the text; only the indentation of
the emitted lines changed, from eight spaces to one tab, which makes the output
about 35% smaller and the following `asm` step correspondingly quicker). What
changed inside: every name table (locals, globals, functions, macros, struct
tags and members, spliced libraries) is one mechanism — arena entries
`[next][len][flag][value][chars]` chained from a 32-way first-letter head
array, read and written through `(P1+d)`, an entry rejected on its length
before a character is compared (the old packed pools walked every name byte by
byte, and every identifier paid that for the macro table alone); the lexer
classifies keywords once (`KWFIND` → `CURKW`) instead of the parser running up
to ten string compares per statement; slot numbers, literals and the decimal
emitter use the word ops; emitted text is walked with one pointer (the OS's
`SYS_PUTC` preserves it); the tables live at `$B000`–`$DFFF` (free TPA while the
compiler runs, cleared at start) so the binary is code only. `cc.bin` 20,915 →
10,075 bytes (the old file carried 7.6 KB of tables as zeros; code alone
13.3 KB → 10.1 KB). Compile cycles on the machine: `pwd.c` 2.60 M → 2.10 M,
`wc.c` 30.8 M → 20.6 M, `grep.c` 55.8 M → 36.1 M, `vi.c` 48.8 M → 30.0 M (1.2–1.6×,
the rest being the BIOS byte stream and `SYS_PUTC` themselves). Three
behaviour changes, all fixes: a `char` array declared after an `int` array in
the same function was compiled with word elements (the differential run caught
it in `grep.c`'s `collect`; `puts` of such an array printed one character),
a call to a function not yet declared now emits its name (the assembler resolves
it) instead of a garbage label, and a syntax error stops with `cc: syntax
error` instead of looping. Limits (raised later the same day, for the C twin
below): 250 functions, 250 `//#define`s, 5 nested `//#use`; the arenas hold
11.5 KB of global names (the tables now start at `$A000`) and 768 bytes of
locals per function (`cc: symbol table full` past that).

**Three more fixes (2026-09-13, found by diffing the C twin's output against
this compiler's on the machine):** the right operand of `&&` now leaves
condition mode — `if (a && b == c)` emitted the relational's single branch and
then fell into the body when `a` was false (`||` was always right; the `&&`
form is what real sources use, e.g. `while (*a && *a == *b)`); label numbers
are 16-bit — the byte counter wrapped at 256, so any on-board build of
`grep.c` (600 labels) or `vi.c` (353) got duplicate labels; and a local
array's size is 16-bit arithmetic — `char b[300]` was given 21 slots instead
of 150. `cc.bin` 10,075 → 10,182 bytes. `cc_c_test.sh` guards all three.

**The C version (`cc.c`, 2026-09-13) — size and speed against the asm one.**
`apps/cc.c` is the same compiler in the p8cc subset, mirroring `p8xcc.asm`
routine for routine: the same static-slot codegen, the same name-table
mechanism (arena entries chained from first-letter heads, as raw memory above
the image from `$B800`), the same messages and — the point — the same emitted
text. `emulator/test/cc_c_test.sh` compiles six sources with both compilers on
the machine and diffs the text (that differential is what found the three
bugs above); compiling `cc.c` itself with both gives 136,032 identical bytes.
Built by the host toolchain (`//#use abi` spliced, `p8cc.py`) as `/binc/cc.bin`.

| | asm `p8xcc.asm` | C `cc.c` | ratio |
|---|---|---|---|
| binary | 10,182 B | 18,089 B | 1.8× |
| `pwd.c` | 2.09 M cycles | 4.54 M | 2.2× |
| `wc.c` | 20.6 M | 37.7 M | 1.8× |
| `vi.c` | 30.2 M | 54.4 M | 1.8× |
| `cc.c` (its own source) | 68.0 M | 130.2 M | 1.9× |

The gap is the smallest of the three twins (BASIC 3.6–4.9×, the assembler
3.9–4.2×) because both compilers spend most of their cycles in the BIOS byte
stream and `SYS_PUTC`. The source keeps to the subset BOTH compilers accept
(no `break`/`continue`, no initialised globals, no string literal over 127
characters, byte stores through pointers written `p[0] = v` because the
on-board compiler stores a word through `*p =`), so the on-board compiler
compiles it — and **the self-hosting round trip now WORKS** (2026-09-14): `cc.c`
uses the P3-stack-frame codegen (recursion-correct, ~13% smaller), which brings
its self-compile to 30,843 bytes; the native assembler assembles that (its
symbol table grew 1,120 → 1,664 for the 1,548-symbol output), and the
self-compiled compiler **runs and reproduces its own output byte-for-byte** — a
fixed point. It took the frame model plus the +2 KB of TPA (the ROM 8K → 6K
reclaim dropped `TPABASE` to `$5900`) plus a raised table layout so the 30.8 KB
image clears its own tables. Regression test: `emulator/test/cc_selfhost_test.sh`.

**Language (through v0.28):** functions, direct **and mutual** recursion (via a
forward prototype), pointers + pass-by-reference, `int`/`char`, arrays with `[]`
and name decay, **structs** (`.`/`->`), file-scope globals, the full operator set
(`+ - * / % << >> & ^ | && || ?:`, `++ -- += -=`, comparisons, unary `- ! * &`),
hex/char/string literals with escapes, `//` and `/* */` comments, a recursive
**`//#use`** preprocessor (splices `/lib/lib_*.c`) plus object-like **`//#define`**
macros, and the `putchar`/`puts`/`getchar`/`peek`/`poke`/`argstr`/`bios` builtins.
It compiles real OS command
source (e.g. `pwd.c`). Codegen is verified **behaviourally** (compile → asm →
run → diff output; `emulator/test/os_cc_test.sh`).

Known gaps are listed under "cc — KNOWN LIMITATIONS" in [`BACKLOG.md`](../BACKLOG.md)
(highlights: 16-bit `int` only; no `unsigned`/`typedef`/`enum`/`union`/`sizeof`;
struct member names must be unique program-wide, no struct params/returns; `+`
doesn't scale pointers by element size; preprocessor is `//#use` + object-like
`//#define` only — no `#include`/`#if`/function-like macros).

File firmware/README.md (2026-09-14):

# firmware/

`p8xmon.asm` — the P8X ROM monitor, the firmware that runs from the memory-card
EEPROM at reset (origin `$0000`).

## What it provides

- **Interactive monitor commands** over the ACIA: `E` (examine/edit memory),
  `D` (dump, with paging — CR = next block, `.` = exit), `I`/`F`/`B` (CF init /
  format / boot), `G` (go), `?`/`H` (help).
- **BIOS jump table at `$0100`** — a stable call interface (ABI) for P8X/OS and
  other programs: `CONIN`, `CONOUT`, `CONST`, `CFINIT`, `CFREAD`, `CFWRITE`,
  `PUTS`, `PHEX8`. Programs call fixed addresses here so they keep working even
  if the monitor internals move.

## Build

Assembled by [`../assembler/p8xasm.py`](../assembler/) into a 6 KB ROM image (`$0000–$17FF`; shrunk from 8 KB 2026-09-14)
(the monitor + BIOS use ~4.3 KB; the rest is erased). The burnable image (and its
Intel HEX) is built into [`../rom/`](../rom/) by:

```sh
cd ../emulator && make rom        # -> rom/p8x-prog-rom.{bin,hex}
```

## Reference

- Command reference: [docs/p8x-monitor.md](../docs/p8x-monitor.md)
- Memory map, BIOS ABI, signal names: [GLOSSARY.md](../GLOSSARY.md)

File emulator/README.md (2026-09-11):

# emulator/

`p8xemu.c` — a cycle-accurate P8X emulator. It does not hard-code instruction
behavior; it loads the microcode images `u0–u3.bin` and steps the same control
word the real hardware does, so it is a faithful model of the machine, not an
approximation.

## Build & run

```sh
make            # builds p8xemu and regenerates the microcode (u0-u3.bin)
./p8xemu [-t] [-T] [-N] [-i F] [-l N] [-c disk.img] [-c2 disk2.img] [-s NN] [-L]
         [-g out.ppm] [-G] rom.bin
```

- `rom.bin` — the EEPROM image (origin `$0000`), e.g. the monitor or combined
  the monitor. The emulator expects `u0–u3.bin` in the current directory.
- `-c disk.img` — attach a CompactFlash image as **drive 0** (boot); models the
  8-bit True IDE task file at `$FF10–$FF17`.
- `-c2 disk2.img` — attach a second CompactFlash image as **drive 1**. Both cards
  share the `$FF10` task-file port and are selected by the ATA device-select bit
  (`CFHEAD`/`$FF16` bit 0), which the firmware drives from its `DRVSEL`. An absent
  drive 1 (no `-c2`) reads back `$FF`, so the firmware's bounded CF waits detect
  it instead of hanging. The task-file (feature + LBA) is a **shared bus**: both
  drives latch those register writes and the device bit only picks who executes
  the command — so loading the LBA *before* selecting the drive (as `CFSETL` does)
  still targets the right card.
- `-s NN` — value the I/O card switches present at `$FF00` (hex or decimal, e.g.
  `-s 0xA5`); defaults to 0. So `PEEK(65280)` / monitor reads see it.
- `-L` — trace LED writes: each change to `$FF02` prints to stderr as
  `[LED $FF02] $NN  *.*..*.*` (`*` = lit). The final LED byte is always shown in
  the halt status line.
- `-g out.ppm` — write the graphics display to `out.ppm` when the run ends, and
  `-G` — render it as text to stderr. "Ends" includes **Ctrl-C**, so you can drive
  BASIC by hand and then quit to get the picture.
- **Ctrl-\\ shows the display without ending the run** (SIGQUIT), so you can draw,
  look, and carry on in the same session — which is the only way experimenting
  with graphics is bearable. It works with or without `-g`/`-G`: with neither, you
  get the text view anyway, since pressing it means you want to see something. The display itself is **always present** behind
  the GL port at `$FF50`; these flags only decide whether you get to see it. See
  [The graphics display](#the-graphics-display) below.
- `-t` — instruction trace. `-l N` — halt after N cycles.
- The 6850 ACIA is wired to stdin/stdout, so the monitor/OS/BASIC are interactive.

### FPGA co-simulation flags

These exist so [`fpga/sim/run.sh`](../fpga/sim/README.md) can diff the emulator
against the Verilog RTL cycle for cycle. They are all off by default and change
nothing about a normal run.

- `-T` — the **canonical machine trace**: one line per cycle on stderr,
  `cyc IR stp A B T T2 P0..P5 flags`. The RTL emits the identical line, so the
  two traces `diff` directly.
- `-N` — console RX always reports empty. Needed because `$FF04`'s RDRF bit
  otherwise depends on *what stdin happens to be*: a TTY with no keystrokes reads
  not-ready, but a redirected or closed stdin is at EOF, which `select()` calls
  readable. Without `-N` the same command passes from a terminal and fails from a
  script. `-N` also suppresses interactive mode, so an explicit `-l` is honoured
  rather than silently dropped.
- `-i FILE` — scripted console input. RDRF is simply "the script still has a
  byte" and one byte is consumed per `$FF05` read, with no host timing in it, so
  the RTL can mirror the rule exactly and both models step identically.

On halt it prints `PC/A/B/...` register state (`A=00` is the convention for "test
passed" in the self-checking suites).

## Tests

```sh
make test        # everything below
make test-quick  # representative ~3 min subset: ISA, compiler core + self-host
                 #   differential + BIOS-file library, a command pipeline, host/native
                 #   assembler identity, disassembler twins, nested launch, glass TTY.
                 #   After every change; the full `make test` before committing a
                 #   compiler/microcode/assembler/OS change and before a sync.
make test-isa    # per-instruction self-check (halts A=00 on success)
make test-cf     # monitor format/boot against the CF model
make test-os     # P8X/OS boot + shell on flat and v2 volumes
make test-basic  # monitor smoke test, disk BASIC (B), SAVE/LOAD
make test-io     # switch input (-s) -> $FF00 and LED writes ($FF02, -L)
make test-gfx    # graphics: the GL port, the C library, the image twins
```

Test scripts and fixtures live in [`test/`](test/); their build artifacts
(`*.bin`, `*.img`, `*.hex`, …) are gitignored.

## The graphics display

A 480x272 framebuffer in **RGB565 direct colour** — a pixel IS its colour —
with a drawing engine behind the GL/PGC graphics-language port at
`$FF50–$FF57`, the ONE graphics interface since the single-interface
migration. On the board the device is the Tang Nano 20K graphics card: two
framebuffer pages live in the FPGA's in-package SDRAM behind a streaming
controller (`FLIP` swaps them). The emulator is the golden model — the RTL
is byte-compared against it frame by frame.

(The original stage-4 device was 240x136 with four palettized pens in block
RAM; direct colour retired the palette, `SETPAL` and the modes in stages
5–6, and the SDRAM controller bought the full panel resolution. Until
2026-09-01 the engine was also CPU-poked directly through a register window
at `$FF20–$FF2F` — the "device door". That window is CLOSED: those
addresses float `$FF` here and on the fabric, and the register file behind
it survives only as the GL walker's internal property. Its primitives —
PIXELW, LINE, BOXFILL, PIXELR, ELLIPSE(FILL), the LINPAT latch — are
exactly what the walker issues while interpreting GL.)

**The drawing engine is in the card, not in software.** Software streams GL
bytes; the `gpu_*` functions here are the engine those bytes drive, and the
RTL must reproduce them step for step.

**Inside the walker's register file, coordinates are 16-bit pairs and a
low-byte write CLEARS its high partner** — the rule that once protected
8-bit software from stale high bytes, now simply how the walker loads its
own registers. The pairs exist because 480x272 needs 9 bits of X.

That matters for speed: a filled box is a handful of stream bytes instead of
a read-modify-write per pixel through a data port -- and bulk pixel traffic
rides the GL `BLIT` verb, whose payload is two wire bytes per pixel.

Two engine behaviours are load-bearing, and the GL RTL battery
(`test/c_gl_rtl_test.sh`) pins both down because the RTL engine has to match
them exactly:

- **Endpoints are inclusive.** A box from (0,0) to (479,271) paints all four
  extreme edges.
- **Off-screen pixels are discarded, not clipped.** The engine's coordinates
  are 16-bit, so far-off-screen values are reachable, and the address
  arithmetic would fold them onto the *start of the next row*. Discarding per
  pixel is the one rule that is trivially identical in C and in Verilog; a
  real clipper would be two implementations that have to agree. (The GL 2D
  primitives ALSO window-clip before the engine sees them -- this rule is
  about what the engine itself does with what arrives.)

`p8xemu` is the golden model for the FPGA, so this is the specification the
Verilog engine gets written against — including `gpu_line`'s Bresenham, which
the RTL must reproduce step for step. The battery streams identical GL bytes
to both and byte-compares whole frames.

### BUSY is real on hardware, and this model hides it

**Software must poll `GLSTAT` bit 6 to see its own GL work finish.** Here,
interpretation and drawing are instantaneous and busy always reads 0 — but the
RTL walker takes real clocks (a full-screen fill is milliseconds), and inside
the engine **a command issued while another is running aborts it** — which is
why the RTL walker polls the engine's busy between every primitive it issues,
the discipline software used to carry when the device door was open.

That asymmetry is deliberate and it is the same licence the CF model takes with
BSY, but it is worth stating plainly because of how it fails: code developed
against this model alone looks perfect here and misbehaves on the FPGA.
Because the poll costs nothing when busy is never set, one binary is correct
on both — which is exactly what makes the battery's frame comparisons
meaningful. BASIC drains through `glv_dn` after every drawing statement.

## Other targets

`make rom` builds the persistent burnable image set into [`../rom/`](../rom/).

---

# Theory of operation

This section explains, in detail, *how `p8xemu.c` works* — and therefore how the
real P8X works, because the emulator is a direct model of the hardware rather
than a behavioral re-implementation. If you understand this file you understand
the machine.

## 1. The central idea: a microcode interpreter

The P8X is a **microcoded** CPU. It has no hard-wired instruction logic; instead
every machine instruction is carried out by a short sequence of **micro-steps**,
and each micro-step is one 32-bit **control word** read from a control store
(four 28C64 EEPROMs on the real control card). The control word's bits are wired
directly to the datapath's enables, selects, and load lines.

The emulator does exactly the same thing. It loads the *same* four ROM images
(`u0.bin`…`u3.bin`, produced by [`../microcode/genucode.py`](../microcode/genucode.py))
that get burned to the hardware, and its main loop reads one control word per
iteration and applies its bits to a modeled datapath. There is no `switch` on
opcode that "implements ADD"; ADD happens because the microcode for opcode
`$09` drives the ALU select lines to the add function across a couple of steps.
**Emulator and silicon cannot drift, because they execute the identical control
store.** The only things the C file hard-codes are the *physical building blocks*
the control word commands: the 74181 ALU, the shifter, the register file, the
bus multiplexer, memory, and the I/O devices.

## 2. The micro-cycle

One pass of the `while(!halted && cycles<lim)` loop = one micro-step = one
hardware clock. Each pass does four things in order, mirroring a real clocked
datapath (combinational settle, then a clock edge that latches results):

1. **Form the micro-address** from current state and read the control word.
2. **Compute combinational results** — the ALU, the shifter, the next flags, and
   the value currently on the **bus** — from the *current* register contents.
3. **Commit on the (modeled) clock edge** — load whatever register/memory the
   control word selects from the bus, bump pointers, latch flags.
4. **Advance the micro-sequencer** — pick the next micro-step (or reset to step 0
   to fetch the next instruction).

## 3. The control store and the micro-address

The control store is addressed by a 13-bit micro-address built from three
fields (`int ad = IR | stp<<8 | cond<<12;`):

| Bits | Field | Meaning |
|---|---|---|
| 0–7  | `IR` | the current opcode (instruction register) — 256 instructions |
| 8–11 | `stp`  | the micro-step counter, 0–15 within the instruction |
| 12 | `cond` | the **condition plane** (A12): selects taken vs not-taken microcode |

Each ROM is 8 KB = 2¹³, so the four ROMs together supply a 32-bit word at every
address. The word is reassembled little-endian across the four images:

```c
uint32_t cw = rom[0][ad] | rom[1][ad]<<8 | rom[2][ad]<<16 | rom[3][ad]<<24;
```

## 4. The 32-bit control word

Every micro-step is fully described by these fields (exactly the bit positions
the C decodes, which match `genucode.py`'s packing — the single source of truth):

| Bits | Field | Function |
|---|---|---|
| 0–3 | `DOE` | **bus source** / output-enable — who drives the internal bus this cycle |
| 4–7 | `DLD` | **load destination** — who latches the bus on the clock edge |
| 8–10  | `PSEL`  | pointer select: `P0`=PC, `P1`, `P2`, `P3`=SP, `P4`=PT, `P5`=PT2 (hidden scratch) |
| 11 | `PINC`  | post-increment the selected pointer |
| 12 | `PDEC`  | post-decrement the selected pointer |
| 13–16 | `ALUS`  | 74181 function select S3–S0 |
| 17 | `M` | 74181 mode: 0 = arithmetic, 1 = logic |
| 18 | `CINP`  | 74181 carry-in **pin** (active-low at the silicon) |
| 19 | `SH0` | shifter stage 1 enable (shift **left**) |
| 20 | `SH1` | shifter stage 2 enable (shift **right**) |
| 21 | `LDF` | latch C/Z/N/V from the ALU+shifter result this cycle |
| 22–24 | `FCOND` | condition code that selects the **next** cycle's condition plane |
| 25 | `URST`  | micro-reset: next step = 0 (i.e. the instruction retires → fetch) |
| 26 | `HALT`  | stop the machine |
| 27 | `LDZN`  | set Z and N from the bus byte (used by load/move ops) |
| 28 | `SHCIN` | shift-in bit = current C (rotate-through-carry); else 0 |
| 29 | `SETC`  | force C = 1 (`SEC`) |
| 30 | `CLRC`  | force C = 0 (`CLC`) |
| 31 | `BSEL`  | ALU B-input mux: 0 = `B` register, 1 = `T` register |

## 5. The datapath and the internal bus

Registers modeled: accumulator `A`, operand `B`, temporaries `T`/`T2`, the
instruction register `IR`, and the six 16-bit pointers `P[0..5]`
(`P0`=program counter, `P1`/`P2` general, `P3`=stack pointer, `P4`=`PT` hidden
scratch for absolute addressing in call/return/16-bit-move microcode,
`P5`=`PT2` hidden scratch — the write cursor for `MOVW`).

Exactly one source drives the bus per cycle (`DOE`); exactly one destination
latches it (`DLD`). `addr = P[PSEL]` is the address presented to memory.

| `DOE` | bus source | | `DLD` | latches bus into |
|---|---|---|---|---|
| 1 | `A` | | 1 | `A` |
| 2 | `B` | | 2 | `B` |
| 3 | `T` | | 3 | `T` |
| 4 | `T2` | | 4 | `T2` |
| 5 | ALU+shifter result `r` | | 5 | flags (C/Z/N/V from bus bits 0–3) |
| 6 | flags packed as C,Z,N,V in bits 0–3 | | 6 | `IR` (instruction fetch) |
| 7 | `memrd(addr)` | | 7 | `memwr(addr, bus)` |
| 8 | `addr` low byte | | 8 | `P[PSEL]` low byte |
| 9 | `addr` high byte | | 9 | `P[PSEL]` high byte |
| 0 | idle (`0xFF`) | | 0 | nothing |

A memory→register move is thus two coordinated fields in one word: `DOE=7`
(read `[addr]`) and `DLD=1` (latch into `A`), with `PSEL` choosing which pointer
addresses memory and `PINC` optionally walking it — that is the `LDA (P1)+`
primitive.

## 6. The ALU (74181), flags, and shifter

`alu181()` models a 74181 with **active-high** data. It computes the arithmetic
result for the chosen function `ALUS`, adds the logical carry-in
(`c = !CINP`, because the pin is active-low), and reports the **conventional**
carry-out in `*cn4`: `C=1` means carry (after ADD) or "no borrow / A≥B" (after
SUB/CMP) — this rev-B convention is what the firmware's `JC`/`CMP` rely on. The
carry chain is computed **regardless of `M`**, so a logic op still latches the
carry the silicon would (a deliberate fidelity detail). When `M=1` the function
table switches to the bitwise-logic column.

The **shifter** is two stages fed by the ALU result `f`: stage 1 (`SH0`) shifts
left, stage 2 (`SH1`) shifts right. The bit shifted out is captured; with
`SHCIN` the bit shifted *in* is the current carry (rotate through carry),
otherwise 0. The final datapath result `r` is what `DOE=5` puts on the bus.

Flag updates at the clock edge:
- `LDF` → latch all four flags from this cycle's results: `C` = shifted-out bit
  for shift ops else the ALU carry-out; `Z` = (`r`==0); `N` = bit 7 of `r`;
  `V` = signed overflow.
- else `LDZN` → set only `Z`/`N` from the **bus byte** (so a plain load reflects
  the value moved).
- `SETC`/`CLRC` force `C` independently (the `SEC`/`CLC` instructions).

**V (signed overflow)** is derived by the sign-bit method, matching the ALU
card's XOR+AND nets exactly: `V = (A7 ^ F7) & (A7 ^ B7 ^ isADD)`, where `F7` is
the raw (pre-shifter) result sign and `isADD = ~ALUS2`. It is computed every op
but only *meaningful* after ADD/SUB/CMP — which is exactly where the signed
branches are documented.

## 7. The micro-sequencer and conditional branching

After the commit, the sequencer chooses the next micro-step:

```c
stp = URST ? 0 : (stp+1)&15;
```

`URST` ends an instruction (next address has `stp=0`, so the next fetch reads a
fresh opcode into `IR` via `DLD=6`). Otherwise the step counter simply advances.

**Conditional execution is pipelined.** The `FCOND` field of the word *currently*
in the pipeline selects the condition plane (ROM A12) used for the *next*
look-up — so the emulator remembers it in `prev_fcond` and evaluates it at the
top of the next loop:

| `FCOND` | condition | used by |
|---|---|---|
| 0 | false | (fall through) |
| 1 | true (unconditional) | `JMP`/`JSR` |
| 2 | `C` | `JC` / `BCP` |
| 3 | `Z` | `JZ` / `BZ` |
| 4 | `N` | (negative) |
| 5 | `V` | (overflow) |
| 6 | `N ^ V` | `BLT` / `BGE` (signed <) |
| 7 | `(N ^ V) \| Z` | `BLE` / `BGT` (signed ≤) |

The branch microcode places its two possible continuations on the `cond=0` and
`cond=1` planes; the condition simply routes the sequencer to one or the other,
so the hardware never "stalls" to decide.

## 8. Reset

```c
P[0]=0; P[1]=P[2]=0; P[3]=0xFEFF; P[4]=P[5]=0; stp=0; IR=0;
```

PC is forced to `$0000` (the reset vector — a `JMP` to the monitor cold start),
the stack pointer starts at `$FEFF` (top of RAM, growing down), and step 0 with
`IR=0` begins the first fetch.

## 9. Memory map and I/O

```
0000–1FFF  ROM   (8K, decoded from the EEPROM image)
2000–FEFF  RAM   (56K: 2×62256, $2000–7FFF and $8000–FEFF)
FF00–FFFF  I/O
```

`memrd`/`memwr` implement the decode. Writes below `$2000` are refused with a
warning (you can't write ROM). The I/O page:

| Addr | R/W | Device |
|---|-----|---|
| `$FF00` | R | I/O-card switches — value set with `-s` |
| `$FF02` | W | LEDs — traced with `-L` |
| `$FF04` | R | 6850 ACIA status: bit1 `TDRE` (always ready), bit0 `RDRF` (key waiting) |
| `$FF05` | R/W | ACIA data: read = next console byte, write = transmit |
| `$FF06` | W | raise a maskable IRQ (models an external device, rev C) |
| `$FF10–$FF17` | R/W | CF-IDE task file (only when `-c` attaches an image) |

## 10. The CompactFlash model

When `-c disk.img` is given, `$FF10–$FF17` model a CompactFlash in **8-bit True
IDE** mode, matching the driver in `firmware/p8xmon.asm`. The firmware writes the
24-bit LBA (`$FF13–$FF15`), sector count/head, then a command to `$FF17`, polls
the status register for `BSY`/`DRQ`, and streams 512 bytes through the data port
`$FF10`. The model implements that handshake: **`BSY` is never asserted** (the
host-side transfer is instantaneous), and `DRQ` is raised while a 512-byte buffer
is draining/filling and dropped when it empties. Commands handled: `SET FEATURES`
(`$EF`), `IDENTIFY` (`$EC`, returns a byte-swapped model string in words 27–46
for the monitor's `I` command), `READ SECTORS` (`$20`), `WRITE SECTORS` (`$30`).
The image is a flat file of 512-byte sectors at `LBA×512`; a missing file is
created and zero-filled to 256 sectors.

## 11. Interrupts (rev C)

Three pieces model the maskable-interrupt path:

- **`IE`** — interrupt-enable latch. It is *not* a microcode bit; it is set/cleared
  by an **opcode decode** as the instruction retires (`URST`): `EI`/`RTI`
  (`IR=$02`/`$04`) set it, `DI` (`IR=$03`) clears it. This mirrors the control
  card's discrete decode.
- **`irq_pending`** — raised when a device writes `$FF06`.
- **The forcing buffer** — at fetch (`stp==0`, `DOE==7`) with `IE` set and an IRQ
  pending, the buffer overrides the memory read and injects opcode **`$08`** onto
  the bus, then acknowledges the interrupt (`irq_pending=0; IE=0`, masking nesting).
  While the `$08` micro-routine then runs with an idle `DOE`, the buffer keeps
  driving `$08`, so the two pointer-load micro-steps build `P0 = $0808` — the
  ROM interrupt vector. `RTI` later re-enables `IE` and returns.

## 12. Console / ACIA host integration

The 6850 ACIA is bridged to the host's stdin/stdout so the monitor, OS, and
BASIC are interactive:

- **Interactive (a TTY):** the terminal is put in raw mode — `ICANON`/`ECHO` off
  (the firmware echoes), and `ICRNL` off so **Enter arrives as CR**, matching the
  hardware serial line. A one-character lookahead (`peeked`) lets the `RDRF`
  status read and the data read stay consistent.
- **Non-blocking RX with idle-block:** `$FF04` RX-ready must never block, because
  the same status register carries `TDRE`, which `PUTC` polls before every
  transmitted byte — a blocking status read would freeze all output until a key
  is pressed. So RX-ready is non-blocking; but to keep an idle prompt from
  spinning the host at 100% CPU, after `RX_SPIN` (4000) consecutive "no key, no
  output" polls it blocks for a single key. Any console output (`$FF05` write)
  resets that counter, so transmit and bulk output never block.
- **Batch (piped stdin):** RX-ready uses `select()`, reads consume the stream,
  and EOF exits cleanly — which is how the test scripts drive the machine.

The cycle cap (`-l`, default 200M) bounds batch runs; an interactive session
sets it to unlimited.

## 13. Fidelity summary

**Exact:** instruction semantics (same control store as hardware); the 74181
function set and conventional-carry convention; V by the card's sign-bit nets;
the two-stage shifter and rotate-through-carry; pipelined conditional branching;
the reset vector and stack origin; the CF True-IDE register handshake; switch and
LED I/O.

**Idealized (timing only, not behavior):** one host loop iteration ≈ one clock,
so the cycle count is a micro-step count, not wall-clock nanoseconds; CF
transfers complete instantly (`BSY` never set); propagation delays, refresh, and
bus capacitance are not modeled. None of these affect the values a program
computes — they are exactly why the emulator is trusted as the reference oracle
for the firmware and the differential compiler tests.

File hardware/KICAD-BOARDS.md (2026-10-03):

# P8X KiCad Boards — Status

KiCad 4-layer boards (F/B signals, In1=GND, In2=VCC planes), generated from the
canonical gen_eagle netlists by `generators/gen_kicad.py` (per-card) /
`gen_backplane.py`, autorouted with Freerouting via
`generators/build_kicad_card.sh <card>`. Standard per card: bypass cap above each
IC, LED/jumper labels + part values on silk, placement PDF + top/3D renders +
gerbers.

**Uniform card size: 280 × 140 mm** — status LEDs on the edge opposite the connector. Every plug-in card is the same dimensions
(the connector-edge is 140 mm — the DIN41612 is only ~94 mm, so the extra room
lets components use more rows and keeps the depth down). The backplane is the
motherboard (262 × 128 mm).

**None of these boards has been fabricated yet.** Each `kicad/` directory holds the
orderable Gerbers (`p8x-<board>-gerbers.zip`), the DRC report, a placement PDF and
the renders. The DRC reports list 0 unconnected pads on every board; the remaining
DRC items are silkscreen warnings.

| Board | Routed | Unconn. | Notes |
|---|---|---|---|
| memory-card | ✅ | 0 | rev F, bespoke `gen_mem.py` |
| cf-card | ✅ | 0 | **rev B: two 8-bit True IDE drives** — drive 0 `$FF10-17` (J2), drive 1 `$FF18-1F` (J5), each own 74245 buffer + strobe glue + pull-ups + activity LED; headers 71mm apart for two CF-IDE adapters; bespoke `gen_cf.py`. **NOTE:** drive 1 needs the firmware/emulator port-base change (pending); drive 0 works on current firmware |
| control-card | ✅ | 0 | 14-pin oscillator |
| alu-card | ✅ | 0 | |
| io-card | ✅ | 0 | **rev B: 2x ACIA/DB9** — ACIA1 `$FF04/5` + ACIA2 `$FF08`, two DB9 sockets with RX/TX-swap jumpers (one MAX232 for both), switches, LED bars, bus monitor; bespoke `gen_io.py` (DB9s+switch bottom, LED bars top). RTC/coin cell is DNP |
| ps2-card | ✅ | 0 | keyboard + mouse, **ATmega1284P** latch-bridge at `$FF58-5F`; custom mini-DIN-6 sockets (bottom edge), 4 status LEDs (right edge), ICSP; no level-shift (5V-native); bespoke `gen_ps2.py` |
| regbank-card | ✅ | 0 | 95 parts — routed (5m45s auto + ~13min optimizer) |
| bustest-card | ✅ | 0 | Pico (RP2040) + 5× MCP23S17 + 16 LEDs; routed with right-edge LED bank |
| backplane | ✅ | 0 | **8-slot** DIN41612 motherboard, 262×128mm (28mm slot pitch, slots left-justified, power/pull-up parts on the right; power entry = Phoenix MSTBA 2,5/2-G-5,08, Digikey 1729128). Routes clean at **0.13mm clearance** (netclass in the `.kicad_pro`) with **nylon-screw** 2mm keepouts. |

> **Deprecated:** the **led-card** (previously routed here) was a CAD-workflow
> test card, never planned to be built. It was moved to
> `hardware/deprecated/led-card/` on 2026-09-18 and its I/O address `$FF0C` freed.
> Not rebuilt or maintained going forward.

> **Parked:** the **peripheral-card** (combined I/O + CF + PS/2, bespoke
> `gen_periph.py`, routed + PASS) was moved to `hardware/parked/peripheral-card/`
> on 2026-09-19 when the design reverted to three separate cards (io + cf + ps2).
> Its netlist is kept intact behind `PARK_PERIPHERAL` in `gen_eagle.py` so it can
> return whole; it is not built or checked in the active flow. Its I/O extras (a
> 2nd ACIA at `$FF08` and two DB9s with RX/TX-swap jumpers) were carried over to
> the standalone io-card rev B the same day.

**Assembly render.** [`assembly/`](assembly/README.md) holds 3D renders of the
backplane with all eight cards seated in their slots, built from these boards by
`generators/render_assembly.py` (`sh hardware/assembly/build.sh`). Rebuild it after
a board's placement or parts change.

## Known follow-ups
- **Cosmetic silk crowding** on the densest cards — part values on every part get
  tight; readable and fab-clipped over pads, but not as clean as the memory card.
- **Placement is auto** (courtyard-spaced flow, 0 overlaps) — a hand pass would
  tidy grouping/silk further; the MiniDIN-6 / DB9 connectors are auto-placed, not
  yet guaranteed on a board edge for cable access.

## Not built
- **Graphics card** — Tang Nano 20K FPGA/video board; no TTL netlist.

Exotic parts use the closest standard KiCad footprint (flagged at build time).

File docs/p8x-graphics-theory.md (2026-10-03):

# P8X Graphics Engine — Theory of Operation

How the display subsystem actually works, from the bus window to the
panel. This is the hardware-facing narrative: what the machines inside
the card are, how work flows between them, and why the design is shaped
the way it is. For *using* the engine, see
[p8x-graphics-guide.md](p8x-graphics-guide.md); for the GL language
reference card, `man gl` on-target; for the design history with its
decision records, `fpga/tang-nano-20k/sdram/STAGE*-DESIGN.md`.

The authoritative register map is generated by
`generators/gen_memmap.py`; addresses quoted here are correct as of
stage 10f but the generator wins.

## 1. The one front door

The CPU sees the graphics engine as ONE register window on the I/O
page:

    $FF50-$FF57   the GL PORT       a byte FIFO speaking the graphics
                                    LANGUAGE (stage 10); text or hex

There used to be a second: the 2D DEVICE window at $FF20-$FF2F, a
coordinate/pen register file plus a command register where pokes drew
immediately. The single-interface migration (2026-09-01) closed it —
those addresses float $FF now, on the fabric and in the emulator alike
— but the register file it exposed did not go anywhere: the GL
interpreter's walker *masters it internally*, issuing the same
line/box/circle commands through the same registers a CPU poke used to
reach. One Bresenham, one span filler, one pixel path; one way of
asking.

Presence probe: `GLID` ($FF54) reads 'G' when the engine is fitted. An
absent card floats the bus — software must know before poking. Since
2026-09-09 the monitor probes `GLID` **once** at wake and records the
result in the resident byte `GFXPRES` ($1FA4); the OS re-affirms it at
boot. Programs read that flag — `has_graphics()` in `lib_gfx.c`, which
`gpresent()` now sources from — rather than re-probing the bus. This is
the two-mode selector (headless serial console vs. graphics desktop; see
p8x-two-mode-design.md). (The old two-byte "PG" signature at GID0/GID1
retired with its window.)

## 2. The 2D engine (the walker's private register file)

A register file (X0/Y0/X1/Y1 as low+high byte pairs, a 16-bit pen,
scalar parameters for radii) and a command register: PIXELW, LINE,
BOXFILL, PIXELR (a read), ELLIPSE, ELLIPSEFILL, and the LINPAT latch.
(BOX outline, CLS and CIRCLE/CIRCLEFILL were retired by the stage-10
diet: four LINEs, a full-screen BOXFILL and the ellipse with rx=ry are
the same pixels, and their walkers' fabric bought the PGC's curves,
patterns and text. RESET and the IDENT record retired with the CPU
window — GL RF owns reset, GLID and the bridge PING answer identity.)
Writing the command register starts the operation; the busy flag holds
until it completes, and a command issued while busy aborts the running
one — which is why the WALKER polls it between every primitive it
issues, the same discipline the libraries used from outside.

The drawing algorithms are integer state machines chosen to be
*step-for-step identical* to the emulator's C: Bresenham with dy held
negative, midpoint circle, two-region midpoint ellipse. That identity
is load-bearing — see §8.

Coordinates are 16-bit and treated as unsigned; off-screen pixels are
DISCARDED, not clipped (the one rule trivially identical in C and
Verilog). Screen space is 480x272, y down, RGB565 direct colour: a
pixel IS its colour.

`GMODE` ($FF2E's write side, stage 10f) selects the pixel-write mode
for lines, points and outlines: 0 replace, 1 complement (dest
inverted, pen ignored), 2 OR, 3 AND, 4 XOR. Fills and CLS always
replace — the burst filler is not modal. A nonzero mode turns the
single-pixel write into a read-modify-write against the framebuffer.

## 3. The GL port and its three FIFOs ($FF50)

    GLDATA $FF50  write: one command-stream byte
    GLSTAT $FF51  read:  bit7 command FIFO full, bit6 BUSY (interpreter
                         AND walker), bit1 error queued, bit0 read-back
                         byte available
    GLRB   $FF52  read:  pop one read-back byte (reserved; live when a
                         read-back stage is fitted)
    GLERR  $FF53  read:  pop one error byte (0 = none)
    GLID   $FF54  read:  'G'

The PGC's three-FIFO contract shrunk to a byte port. The host checks
bit7 before pushing (or trusts a depth-guaranteed burst), drains GLERR
after a stream, and treats bit6 as "the card is still working". Errors
are code bytes: 1 unknown command, 2 bad parameter, 4 FIFO overflow,
5 list op out of place, 6 undefined list, 7 list full.

Two encodings share the stream, switchable in-band: HEX (opcode byte +
int16 little-endian parameters; power-up default) and ASCII (keywords +
decimal numbers, any of space/tab/comma/semicolon/CR/LF as
separators). `CA` enters ASCII, `CX` returns to hex — each is its own
byte sequence in both modes, and in hex mode the switch is the literal
three bytes `"CA "` (space-terminated).

## 4. The interpreter: translator, consumer, walker

Three machines in a pipeline, all in `fpga/rtl/p8x_geom.v`:

**The translator** (stage 10d) sits ahead of the byte source in ASCII
mode. It matches keywords against a 118-entry ROM (long and short
forms, generated by `generators/gen_glkw.py` — the same table the
emulator and BASIC use), converts decimal numbers to width-correct
parameters, and feeds the result — pure hex — through a small queue
into the consumer. Error recovery is deterministic: an unknown keyword
logs 1 and swallows its numbers; a keyword arriving early logs 2 and
zero-fills; an orphaned number logs 2. The stream stays in sync.

**The consumer** decodes one command at a time: opcode → parameter
count (a wire table), collect parameters, dispatch. Most 2D state
changes (pen, window, current point) happen in the dispatch cycle;
anything that draws or computes launches the walker and waits — the
consumer only dispatches when the walker is idle, which is what makes
GLSTAT bit6 a single honest busy flag.

**The walker** is the execution back end, a ~110-state FSM that owns
three resources: the scratchpad RAM, the muldiv core, and the 2D
device's register port. Its jobs: the vertex transform MAC, near/far
clipping, perspective projection, Cohen-Sutherland window clipping,
viewport mapping, polygon fan filling, the box issuer
(CLEARS/FLOOD/RECT), matrix composition, single-register device
writes (the LINFUN mode, which must WAIT for the device to go idle so
a mode change never overtakes a primitive still drawing), and the
AREA flood-fill walker (stage 10g): a scanline seed fill that probes
the framebuffer through real device POINT commands, paints spans as
device LINEs, and keeps its 16384-entry seed stack in SDRAM at
$180000 — the emulator's `gl_afill` reproduced state for state, with
error 2 for an off-window seed and error 8 (deterministic partial
fill) when the stack caps out. Vector text (stage 10h) adds almost no
datapath at all: a glyph IS a command list in a second SDRAM slot bank
($140000), TDEFIN records into it through the unchanged recording
machinery (one bank-select bit), and TEXT is a small per-char loop
that replays glyph lists through the unchanged replay fetcher --
TSIZE/TANGLE are compose aliases of MDSCAL/MDROTZ, so size, angle and
the baseline advance all ride the ordinary matrix path.

## 5. Transforms: the matrix pipeline (stage 10b)

All 3D state lives on the card. Two master matrices — modeling M
(composed by MD* verbs about the MDORG pivot) and viewing VR (VW*
verbs, angles negated: the viewer orbits) — are kept in a scratchpad
RAM and recomposed into a parameter file on every matrix verb:

    v_screen = project( (VR*((M*v>>8) + Tm - r))>>8 + (0,0,dist) )

Everything expensive happens at COMMAND time (a matrix verb costs a
compose microprogram run); the per-vertex datapath is untouched from
stage 9. Angles are integer degrees through a shared quarter-wave sine
table (`generators/gen_trig.py` emits both the emulator's C table and
the RTL ROM from one formula). Projection: K = 256 native at power-up
(the stage-9 camera; DISTAN 0 keeps old streams pixel-identical), or
PGC-style `PROJCT angle` deriving K from the window width. Hither/yon
planes live in the parameter file; the near clip is always on (floor
16 — the divide guard), the far clip costs nothing when disabled.

The scratchpad is ONE true-dual-port BSRAM (port A write-else-read,
port B read-only) holding the master matrices, compose scratch, the
polygon lanes, the working vertices, and the keyword ROM — the
register arrays that once made placement impossible, serialized behind
two registered read ports.

## 6. Command lists (stage 10c)

64 slots x 4KB in SDRAM at $100000 (a second, identical bank at
$140000 holds the stage-10h GLYPHS -- same format, one address bit);
slot n holds a byte length in its first halfword and hex command bytes
from byte 2. The stage-10g fill's seed stack lives at $180000. CLBEG records —
bytes ride the normal decoder (execution suppressed, boundaries
tracked, unknown opcodes skipped not stored), CLEND finalizes, CLAPP
(P8X-only) appends. CLRUN replays once; CLOOP replays n times — the
interpreter's byte source switches from the FIFO to a fetcher walking
the slot, and the decode machinery neither knows nor cares. Matrix
deltas inside a looped list accumulate: a list that nudges MDROTY,
erases, draws and FLIPs is a self-running animation with the CPU
idle. Lists store hex regardless of the input encoding, so an
ASCII-recorded scene replays identically. Nesting is refused (error
5); an undefined slot is error 6; outgrowing a slot aborts the
recording and leaves the slot undefined (error 7).

## 7. Pixels: memory, spans, scanout, pages

The framebuffer lives in the in-package SDRAM behind an arbiter that
serves four masters: the pixel back-end (`gfx_mem` — single pixel
reads/writes, and the LINFUN read-modify-write), the span filler
(`gfx_span` — burst fills for boxes/CLS/triangle spans), the GL list
fetcher/recorder, and the scanout.

The address is pure wiring: stride 1024 bytes means
{page, y[8:0], x[8:0], 0} — no multiplier, no width-wrap bugs. Scanout
streams each line into a line buffer with its CAS issued every OTHER
cycle: gapless bursts proved electrically marginal on real hardware
(snow, missing edges), and half-rate streaming is still 3x faster than
the panel needs.

Two pages. Drawing targets the DRAW page, the panel shows the DISPLAY
page; `FLIP` (applied at a frame boundary) swaps them and `PGSYNC`
rejoins them. `CLEARS` erases BOTH pages (they power up as garbage).
`WAIT n` paces on real frame ticks — the pacing primitive inside
animation lists.

## 8. The golden-model discipline

The emulator (`emulator/p8xemu.c`) is the reference implementation:
the RTL must reproduce it byte-for-byte, and the claim is enforced,
not asserted. The proof chain, in escalating strength:

1. Directed op-level benches (`tb_gl.v`): the interpreter's exact
   operation stream, error sequences, FIFO backpressure.
2. Eleven cross-implementation FRAMES (`emulator/test/c_gl_rtl_test.sh`):
   the same command bytes rendered by the emulator on the emulated
   machine and by the real RTL stack (geometry + gfx + arbiter + SDRAM
   controller + a protocol-checking chip model), compared pixel for
   pixel — the 10a scene, the 10b matrix scene, the 10c fly-through,
   the 10d ASCII scene, the 10f LINFUN scene, the 10g AREA fills, the
   10h TEXT scene (the whole generated font TDEFIN'd, then sized,
   tilted and folded), the 10i curve scene (both midpoint regions,
   both aspects, the r=1/r=0 edges), the 10j pattern scene, the 10k
   text2 scene and the BLIT frame — plus self-checking PIXRD/BLIT
   read-back rungs that compare RB words instead of frames.
3. On-board probes: the same programs typed at the real machine, with
   PIXELR read-backs checked against the emulator's golden values.

The corollary rules: algorithms are written once in C and transcribed,
never re-derived; a divergence is a bug in the RTL by definition; and
anything the frame tests cannot see (scanout mapping, electrical
margin) needs its own bench or a human eye on the panel.

## 9. What is deliberately NOT here

Read-back (FLAGRD/MATXRD/CLRD/CLMOD — stage 10e) is built and proven
in simulation but not fitted: it costs more logic than the current
FPGA has free. Its port plumbing (GLRB, GLSTAT bit0) is already in the
contract. AREA seed fill (10g) and vector TEXT (10h) are scoped in
BACKLOG.md. The stage-8 record engine and its $FF40 window are retired
— a scene is a command list now.

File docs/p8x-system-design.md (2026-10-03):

# P8X: An 8-Bit TTL CPU — Bus/Backplane Card Architecture

Reorganized around a passive backplane with six plug-in CPU cards (plus a PS/2 input card) and the 4×16-bit pointer register bank as the architectural centerpiece. The PC, SP, and MAR of the original SAP-8X design are all subsumed by the pointer bank.

**Cards:**
1. Control / Microcode card (clock, reset, sequencer, microcode EPROMs, IR, front-panel run controls)
2. Register Bank card (P0–P3, the 16-bit up/down pointer set)
3. ALU card (A, B, T, T2 registers, 74181 ALU, shifter, flags)
4. Memory card (ROM, RAM, address decode)
5. I/O card (toggle-switch input port, LED output port, RS-232 via 6850 ACIA)
6. CF-IDE card (CompactFlash in 8-bit True IDE mode, memory-mapped at $FF10–$FF17)
7. PS/2 card (keyboard + mouse at $FF58–$FF5F; optional — see [ps2-card/](../hardware/ps2-card/README.md))

(The optional front-panel LED display card of the first plan was dropped; the I/O
card carries the bus-monitor LEDs. A bus test card for bring-up, and the backplane,
complete the board set: [hardware/](../hardware/README.md). All boards are designed
and routed in KiCad, 280 × 140 mm for the plug-in cards; none is fabricated yet.)

Total: ~130 logic ICs across the six CPU cards. Each card is independently testable on the backplane.
(The per-card "≈ N chips" notes below are original design estimates; the
authoritative live count is `generators/gen_bom.py` → `hardware/p8x-bom.csv`.)

---

## 1. Programmer's Model

| Register | Width | Role |
|---|---|---|
| P0 | 16 | Program counter |
| P1, P2 | 16 | General pointers (Forth IP/W, BASIC text pointer, etc.) |
| P3 | 16 | Stack pointer (empty-descending: points at next free byte) |
| A | 8 | Accumulator (ALU operand A) |
| B | 8 | Operand register (ALU operand B) |
| FLAGS | 4 | C, Z, N, V |
| T, T2 | 8 | Hidden microcode temporaries (not programmer-visible) |

Every pointer supports synchronous **load, hold, increment, decrement** (full 16-bit carry/borrow). The address bus is *always* driven by the currently selected pointer — there is no separate MAR and no address mux. An instruction fetch is simply "select P0, read memory, increment."

All I/O is memory-mapped in page **$FF00–$FFFF**.

Memory map (rev E, single-sourced in `generators/gen_memmap.py` — see the memory card):
- `$0000–$17FF` EEPROM, 6 KB (monitor + BIOS, ~4.9 KB used; a 28C256, or a 28C64) — shrunk from 8 KB on 2026-09-14
- `$1800–$FEFF` SRAM, 58 KB (2× 62256); `$1800–$1FFF` is the OS/BIOS scratch island, the OS loads at `$2000`, programs at `$5900`
- `$FF00–$FFFF` I/O page (RAM disabled here)

Reset forces P0 to $0000 (pointer clear via 74169 synchronous load of zeros — see §4.2).

---

## 2. Backplane

Passive backplane, **DIN 41612 96-pin (rows A/B/C)** connectors; the cards were first planned as 100×160 mm Eurocards and are laid out in KiCad at 280×140 mm. Row B is mostly ground guard between the signal rows, but B3–B26 alternate: odd pins are GND, even pins are spare bus lines SPARE12–SPARE23 (rev D); B27 = CLRC, B28 = BSEL, B29 = IRQ (rev C), B30 = SPARE11. See [p8x-bus-definition.md](../hardware/backplane/p8x-bus-definition.md) for the full pin map.

### 2.1 Bus signals

| Group | Signals | Count | Driven by |
|---|---|---|---|
| Data bus | D0–D7 | 8 | one card per microcycle (one-hot by decode) |
| Address bus | A0–A15 | 16 | Register Bank card (always) |
| Data source select | DOE0–3 | 4 | Control card |
| Data destination select | DLD0–3 | 4 | Control card |
| Pointer select | PSEL0–2 | 3 | Control card |
| Pointer count | PINC, PDEC | 2 | Control card |
| ALU function | ALUS0–3, ALUM, CIN | 6 | Control card |
| Shifter | SH0–SH1 | 2 | Control card |
| Flag latch | LDF | 1 | Control card |
| Clock | CLK, CLK̄ | 2 | Control card |
| Reset | RES̄ | 1 | Control card |
| Power | +5 V, GND | rest | PSU |

≈ 48 signals + power/ground, plus FC/FZ/FN/FV flag lines and 20 spares (SPARE4–11 plus the rev-D row-B SPARE12–23) — fits the 96-pin connector with room to spare.

### 2.2 Distributed field decoding

The 4-bit **DOE** (data output enable) and **DLD** (data load) fields are broadcast *encoded* on the backplane; **each card carries its own 74154 (or 74138) decoder** and responds only to its assigned codes. This keeps the backplane narrow, makes bus contention structurally impossible (one-hot per field), and means adding a card never requires rewiring the others.

**DOE field assignments (who drives D0–D7):**

| Code | Source | Card |
|---|---|---|
| 0 | none (bus idle, pulled up) | — |
| 1 | A | ALU |
| 2 | B | ALU |
| 3 | T | ALU |
| 4 | T2 | ALU |
| 5 | ALU result (via shifter) | ALU |
| 6 | FLAGS | ALU |
| 7 | MEM (read) | Memory / I/O |
| 8 | PTRL — low byte of selected pointer | Reg Bank |
| 9 | PTRH — high byte of selected pointer | Reg Bank |

**DLD field assignments (who latches D0–D7 at the clock edge):**

| Code | Destination | Card |
|---|---|---|
| 0 | none | — |
| 1 | A | ALU |
| 2 | B | ALU |
| 3 | T | ALU |
| 4 | T2 | ALU |
| 5 | FLAGS (restore) | ALU |
| 6 | IR | Control |
| 7 | MEMW — memory/I-O write strobe | Memory / I/O |
| 8 | PTRL — low byte of selected pointer | Reg Bank |
| 9 | PTRH — high byte of selected pointer | Reg Bank |

Note `MEMW` is just another destination: the Memory and I/O cards decode DLD=7 and generate a write pulse (gated with CLK̄ for clean timing).

---

## 3. Control / Microcode Card

### 3.1 Microcode addressing (13 bits → 8K × 32)

| Bits | Source |
|---|---|
| 12–5 | IR (opcode, 74273) |
| 4–1 | Step counter (74161) |
| 0 | Selected condition (74151 mux: 0, 1, C, Z, N, V, …) |

### 3.2 Control word (32 bits, 4× 28C64 EPROM)

As implemented (rev C). The authoritative bit map is the `w()` encoder + header
comment in `microcode/genucode.py`; this table mirrors it.

| Bits | Field |
|---|---|
| 0–3 | DOE |
| 4–7 | DLD |
| 8–10 | PSEL (P0–P3 + PT=4 + PT2=5 hidden scratch; 3-bit since rev B) |
| 11 | PINC |
| 12 | PDEC |
| 13–16 | ALU S0–S3 |
| 17 | ALU M |
| 18 | CIN (pin, active-low carry) |
| 19 | SH0 (shift left) |
| 20 | SH1 (shift right) |
| 21 | LDF (latch all four flags) |
| 22–24 | FCOND (condition mux: never/always/C/Z/N/V/LT=N^V/LE=(N^V)\|Z) |
| 25 | µRESET (step counter → 0, ends instruction) |
| 26 | HALT (gates clock off; resume via front panel) |
| 27 | LDZN (latch Z,N from the bus on loads) |
| 28 | SHCIN (shifter shift-in = C, for rotates) |
| 29 | SETC (force C=1) |
| 30 | CLRC (force C=0) |
| 31 | BSEL (ALU B-input mux: 0=B register, 1=T register) |

**Pipeline latch:** the 32 EPROM outputs are registered in 4× **74374** clocked on the opposite edge (CLK̄), so glitching ROM outputs never reach the backplane. Non-negotiable for reliability.

### 3.3 Also on this card
- Crystal oscillator + 74161 divider (÷1/2/4/8 selectable)
- Power-on/pushbutton reset (RC + 7414), drives RES̄ and clears step counter and IR
- **Front-panel run controls:** RUN/HALT toggle, single-STEP pushbutton (debounced 74279), clocked through a 7474 synchronizer so the machine always stops on a microcycle boundary. HALT microcode bit ORs into the same stop logic.

**BOM:** 4× 28C64, 4× 74374, 74273 (IR), 74161 (step), 74161 (clk div), 74151 (cond), 74154 (DLD decode for IR), 7414, 7474, 74279, osc, glue ≈ **15 chips**

---

## 4. Register Bank Card

The biggest card, and the heart of the machine.

### 4.1 Structure
- **16× 74169** synchronous up/down counters: 4 chips per pointer, RCO→ENT cascaded for full 16-bit carry
- **Pointer selection:** PSEL → 74139; the selected pointer's outputs are enabled onto an on-card 16-bit *pointer bus* via 2× 74244 per pointer (8× 74244 total)
- **Address bus drivers:** pointer bus → 2× 74244 → backplane A0–A15 (always enabled — this card owns the address bus)
- **Byte readback:** pointer bus hi/lo → 2× 74257 mux → 74244 → data bus (DOE codes 8/9)
- **Byte loads:** DLD codes 8/9 + PSEL → 74138 → eight load strobes (4 pointers × 2 bytes). A byte load asserts L̄D̄ on just the two 74169s of that byte; the other byte's chips hold
- **Inc/Dec:** PINC ∨ PDEC → count-enable on the selected pointer's slices (gated through the 74139 selection); PDEC drives U/D̄. Count direction/enable apply to all 4 slices so carry propagates 16 bits

### 4.2 Reset behavior
RES̄ forces a synchronous load of $0000 into P0 (gates the P0 load strobes and pulls the load inputs low via the data-bus pull-downs / forced-zero buffer). One 74244 wired to all-zeros, enabled at reset, does this cleanly.

### 4.3 Timing note
74169s are synchronous: during a microcycle the *current* value drives the address bus; load/inc/dec take effect at the clock edge. So "read MEM at P3 and decrement P3" in one microcycle uses the pre-decrement address — which is exactly what the empty-descending stack convention wants (write-then-dec for push, inc-then-read for pop).

**BOM:** 16× 74169, 8× 74244 (select), 2× 74244 (addr drive), 2× 74257 + 74244 (readback), 74139, 74138, zero-buffer 74244, gates ≈ **32 chips**

(If one Eurocard gets crowded, this splits naturally into two half-bank cards — P0/P1 and P2/P3 — sharing the bus pinout.)

---

## 5. ALU Card

- **A, B, T, T2:** each 74377 (load) + 74244 (bus drive) = 8 chips. A and B feed the 74181 inputs directly
- **ALU:** 2× 74181 + 74182, function lines straight from backplane
- **Shifter:** 2× 74157 after the ALU (pass / <<1 / >>1, carry in/out for rotates), then 74244 to the bus
- **Flags:** 74175 (C, Z, N, V), Z from 74260+gate over the shifter output, latched on LDF. FLAGS↔bus paths for push/pop of status
- **Decode:** 1× 74154 for DOE codes 1–6, 1× 74154 for DLD codes 1–5

**BOM:** ≈ **18 chips**

---

## 6. Memory Card

- **28C256** EEPROM, selected when A15 = 0
- **62256** SRAM, selected when A15 = 1 **and not** the I/O page: 7430 (8-input NAND on A8–A15) detects $FFxx and inhibits RAM CS
- **74245** transceiver to the data bus: direction from read (DOE=7) vs write (DLD=7); enabled only for on-card addresses
- Write pulse: DLD=7 ∧ CLK̄ → W̄Ē, giving address/data setup in the first half-cycle and a clean strobe in the second

**BOM:** 28C256, 62256, 74245, 7430, 74154 or 74138 + gates ≈ **6 chips**

---

## 7. I/O Card

Decodes the $FFxx page (same 7430 trick) plus A1–A2 via a 74138 → up to 8 port selects.

| Address | Port |
|---|---|
| $FF00 | **Switch input**: 8 toggle switches → 74244 → data bus on read |
| $FF02 | **LED output**: 74374 latch → 8 LEDs (write) |
| $FF04–05 | **6850 ACIA** control/status + data, RS-232 |

- **6850 ACIA** + **MAX232** (the one non-TTL concession for RS-232 levels — alternatively 1488/1489 with ±12 V) + baud clock from a 74161 divider chain or a dedicated 2.4576 MHz can ÷16
- **Bus-monitor LEDs (passive)**: 3× 74244 permanently buffering A0–A15 and D0–D7 to LED banks. Costs nothing logically, and with the single-step button on the control card it gives you a full Altair-style "watch the machine think" front panel
- Software handles everything: the monitor program in ROM polls the switches and ACIA — no bus-mastering front panel needed since the ROM bootstraps the machine

**BOM:** 6850, MAX232, 74244 (switches), 74374+LEDs, 7430, 74138, baud divider, 3× 74244 monitors ≈ **10 chips**

> **Expansion I/O beyond this card.** The I/O card owns only `$FF00–$FF0F`.
> Later ports live on their own cards / on the FPGA graphics card and are
> recorded in [p8x-bus-definition.md §5](../hardware/backplane/p8x-bus-definition.md):
> the 2nd ACIA (`$FF08`), the MDU (`$FF30–$FF3F`), the GL graphics port
> (`$FF50–$FF54`), and the PS/2 keyboard+mouse window (`$FF58–$FF5F`, see
> [ps2-card/](../hardware/ps2-card/README.md) — a standalone design). Every I/O
> symbol is single-sourced in `generators/gen_memmap.py`.

---

## 8. Microcode Examples

Notation: one line per microcycle. Every instruction begins with the shared fetch cycle.

### Fetch (all instructions, step 0)
```
PSEL=P0, DOE=MEM, DLD=IR, PINC
```

### LDA (P1)+   — load A indirect via P1, post-increment
```
0: fetch
1: PSEL=P1, DOE=MEM, DLD=A, PINC, LDF, µRESET
```
**Two cycles.** This is the instruction that makes the interpreter easy.
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

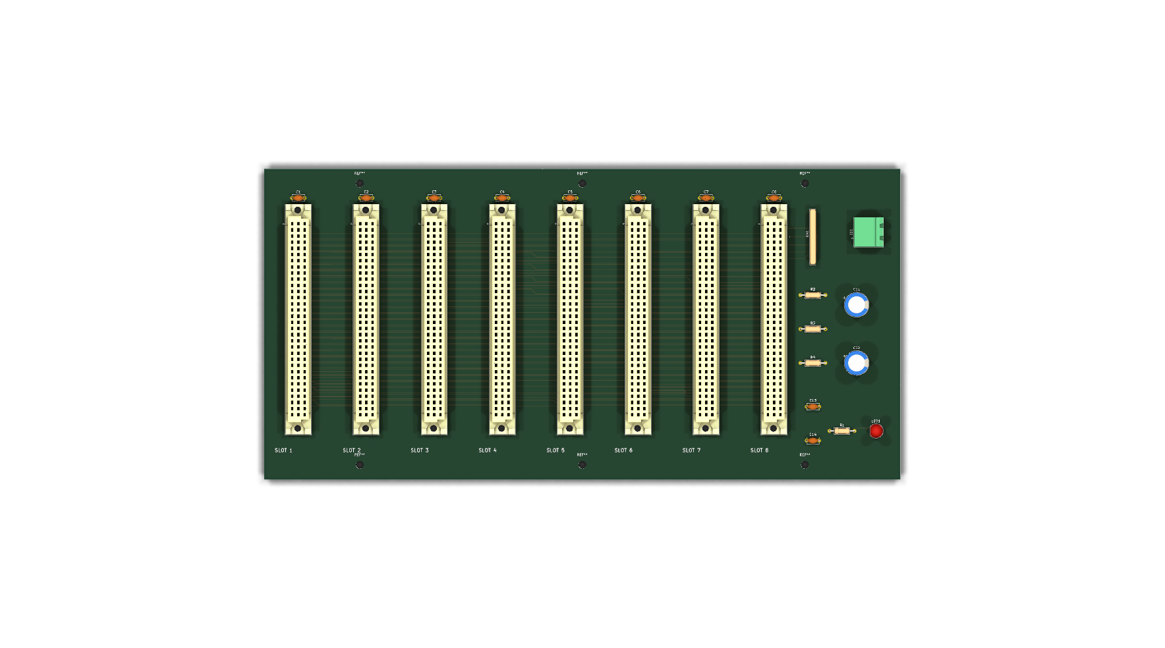
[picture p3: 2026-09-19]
hardware/backplane/kicad/p8x-backplane-render-top.png

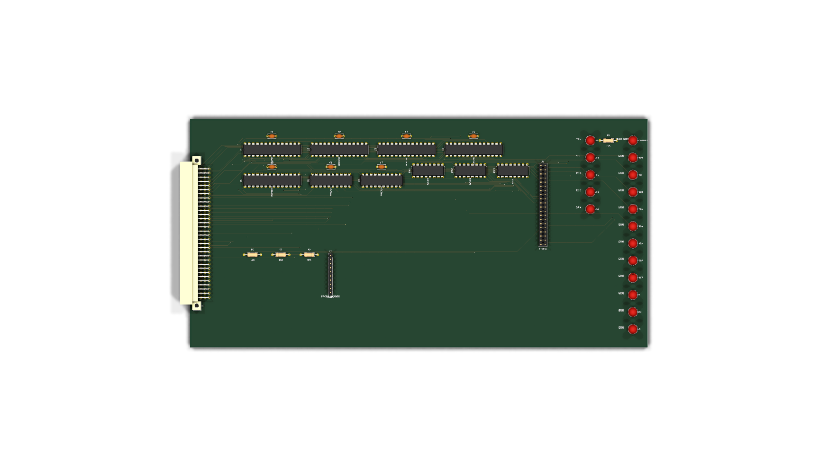
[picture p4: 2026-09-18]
hardware/bustest-card/kicad/p8x-bustest-card-render-top.png

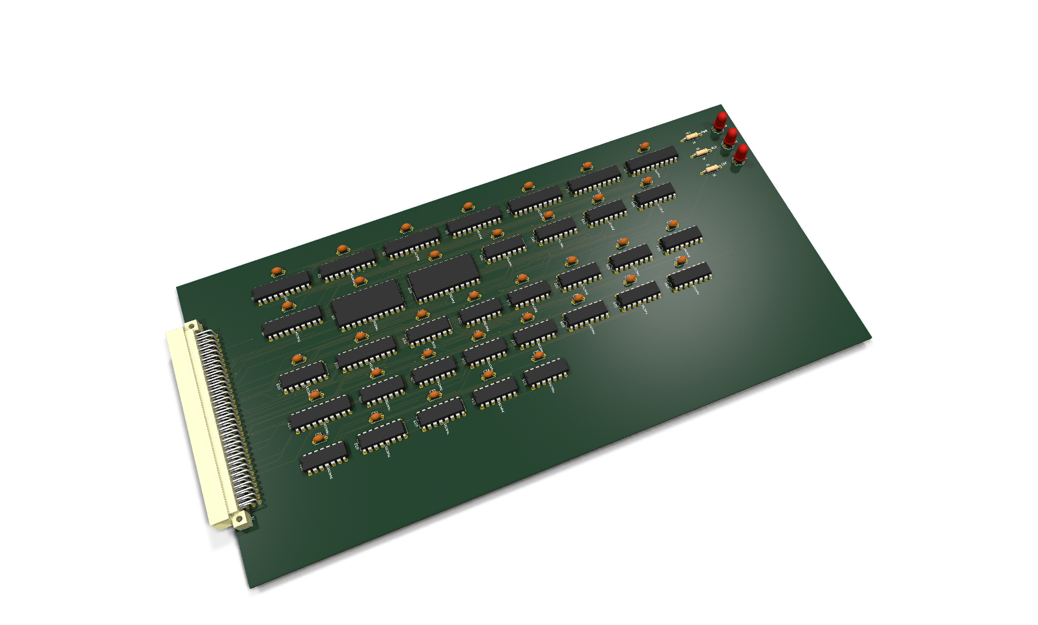
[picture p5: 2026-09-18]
hardware/alu-card/kicad/p8x-alu-card-render-3d.png

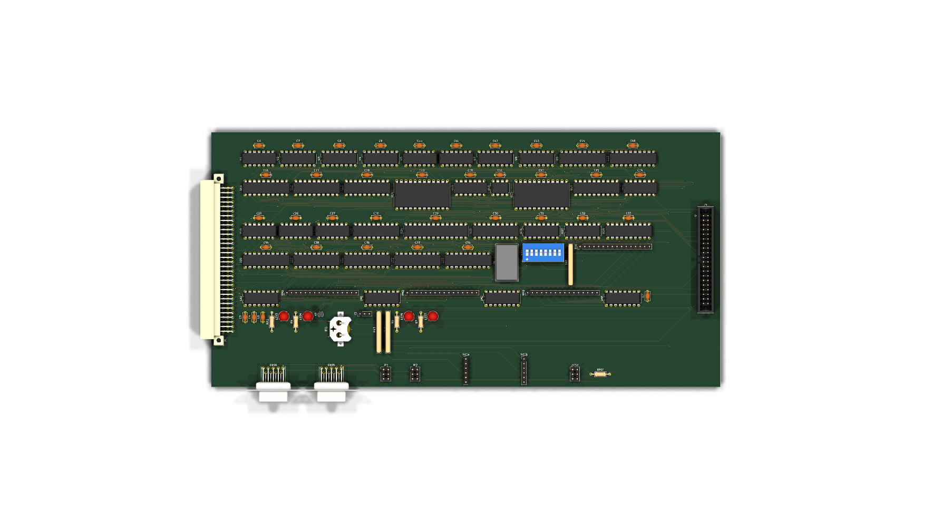
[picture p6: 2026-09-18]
hardware/parked/peripheral-card/kicad/p8x-peripheral-card-render-top.png

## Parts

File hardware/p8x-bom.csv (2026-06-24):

Qty | Part (generic — verify on DigiKey) | Package | Category | Populate | Notes | RefDes
1 | CR2032 coin-cell holder | CP_RADIAL | Battery | yes |  | io:BT1
2 | Ceramic cap 150P | C_DISC | Capacitor | yes |  | backplane:CT1 backplane:CT2
5 | Ceramic cap 1U | C_DISC | Capacitor | yes |  | control:C1 io:C2 io:C3 io:C4 io:C5
2 | Electrolytic cap 470U | CP_RADIAL | Capacitor | yes |  | backplane:CB1 backplane:CB2
1 | 40-pin boxed header (IDC, CF/IDE) | HDR40 | Connector | yes |  | cf:J2
10 | DIN41612 96-pin (backplane receptacle, mates FABC96R) | FABC96S | Connector | yes |  | backplane:J1 backplane:J10 backplane:J2 backplane:J3 backplane:J4 backplane:J5 backplane:J6 backplane:J7 backplane:J8 backplane:J9
7 | DIN41612 96-pin, FABC96R (card edge connector, +M2.5 mounting holes) | MABC96R | Connector | yes |  | alu:J1 cf:J1 control:J1 io:J1 led:J1 memory:J1 regbank:J1
3 | Pin header 3-pin 0.1in | HDR3 | Connector | yes |  | io:J2 io:J3 memory:JWP
1 | Pin header 4-pin 0.1in | HDR4 | Connector | yes |  | control:JP1
1 | Terminal block, 4-pos 5mm | TB4 | Connector | yes |  | backplane:J11
1 | 32.768kHz crystal | C_DISC | Crystal | yes |  | io:X3
13 | LED 3mm green | LED5 | LED | yes |  | alu:LED3 alu:LED4 backplane:LED1 cf:LED3 cf:LED5 control:LED3 control:LED4 io:LED3 led:LED3 memory:LED3 memory:LED5 regbank:LED3 regbank:LED4
2 | LED 3mm red | LED5 | LED | yes |  | control:LED5 memory:LED6
8 | LED 3mm yellow | LED5 | LED | yes |  | alu:LED5 cf:LED4 io:LED4 led:LED4 memory:LED2 memory:LED4 memory:LED7 regbank:LED5
5 | LED bar array, 8-segment (DIP) | DIP16 | LED | yes |  | io:LA1 io:LM1 io:LM2 io:LM3 led:LA1
4 | 74HCT00 | DIP14 | Logic IC | yes |  | alu:U25 control:U4 io:U15 memory:U7
1 | 74HCT02 | DIP14 | Logic IC | yes |  | regbank:U34
9 | 74HCT08 | DIP14 | Logic IC | yes |  | alu:U19 alu:U31 alu:U35 cf:U8 control:U5 io:U6 memory:U9 regbank:U37 regbank:U38
2 | 74HCT10 | DIP14 | Logic IC | yes |  | cf:U6 cf:U7
15 | 74HCT138 | DIP16 | Logic IC | yes |  | alu:U20 alu:U21 cf:U3 cf:U4 control:U8 io:U2 io:U3 io:U4 led:U2 led:U3 memory:U5 memory:U6 regbank:U30 regbank:U31 regbank:U33
2 | 74HCT139 | DIP16 | Logic IC | yes |  | regbank:U32 regbank:U39
4 | 74HCT14 | DIP14 | Logic IC | yes |  | cf:U5 control:U2 led:U5 regbank:U35
1 | 74HCT151 | DIP16 | Logic IC | yes |  | control:U9
10 | 74HCT157 | DIP16 | Logic IC | yes |  | alu:U12 alu:U13 alu:U14 alu:U15 alu:U22 alu:U28 alu:U29 alu:U30 alu:U32 alu:U33
3 | 74HCT161 | DIP16 | Logic IC | yes |  | control:U1 control:U18 io:U7
16 | 74HCT169 | DIP16 | Logic IC | yes |  | regbank:U1 regbank:U10 regbank:U11 regbank:U12 regbank:U13 regbank:U14 regbank:U15 regbank:U16 regbank:U2 regbank:U3 regbank:U4 regbank:U5 regbank:U6 regbank:U7 regbank:U8 regbank:U9
1 | 74HCT175 | DIP16 | Logic IC | yes |  | alu:U17
2 | 74HCT181 | DIP24W | Logic IC | yes | ALU slice — HCT uncommon; may need 74F181/NOS | alu:U10 alu:U9
1 | 74HCT182 | DIP16 | Logic IC | yes | look-ahead carry — uncommon; 74F182/NOS | alu:U11
25 | 74HCT244 | DIP20 | Logic IC | yes |  | alu:U16 alu:U2 alu:U23 alu:U4 alu:U6 alu:U8 control:U20 io:U11 io:U12 io:U13 io:U9 regbank:U17 regbank:U18 regbank:U19 regbank:U20 regbank:U21 regbank:U22 regbank:U23 regbank:U24 regbank:U25 regbank:U26 regbank:U29 regbank:U36 regbank:U43 regbank:U44
2 | 74HCT245 | DIP20 | Logic IC | yes |  | cf:U1 memory:U3
2 | 74HCT257 | DIP16 | Logic IC | yes |  | regbank:U27 regbank:U28
2 | 74HCT260 | DIP14 | Logic IC | yes | dual 5-in NOR — uncommon; verify HCT avail or NOS | alu:U18 alu:U27
4 | 74HCT30 | DIP14 | Logic IC | yes |  | cf:U2 io:U1 led:U1 memory:U4
6 | 74HCT32 | DIP14 | Logic IC | yes |  | alu:U24 control:U6 io:U5 led:U4 memory:U8 regbank:U40
7 | 74HCT374 | DIP20 | Logic IC | yes |  | cf:U9 control:U14 control:U15 control:U16 control:U17 io:U10 led:U6
7 | 74HCT377 | DIP20 | Logic IC | yes |  | alu:U1 alu:U3 alu:U5 alu:U7 control:U7 regbank:U41 regbank:U42
3 | 74HCT74 | DIP14 | Logic IC | yes |  | alu:U26 control:U21 control:U3
2 | 74HCT86 | DIP14 | Logic IC | yes |  | alu:U34 control:U19
2 | 62256 SRAM | DIP28W | Memory IC | yes | 32Kx8 SRAM (e.g. AS6C62256-55) | memory:U10 memory:U2
1 | AT28C256 | DIP28W | Memory IC | yes | parallel EEPROM 32Kx8, 150ns | memory:U1
4 | AT28C64 | DIP28W | Memory IC | yes | parallel EEPROM 8Kx8 (microcode ROMs) | control:U10 control:U11 control:U12 control:U13
1 | 2.4576MHZ full-can oscillator | OSC4 | Oscillator | yes |  | io:X2
1 | 4MHZ full-can oscillator | OSC4 | Oscillator | yes |  | control:X1
151 | 100N | C_DISC1 | Other | yes |  | alu:CD1 alu:CD10 alu:CD11 alu:CD12 alu:CD13 alu:CD14 alu:CD15 alu:CD16 alu:CD17 alu:CD18 alu:CD19 alu:CD2 alu:CD20 alu:CD21 alu:CD22 alu:CD23 alu:CD24 alu:CD25 alu:CD26 alu:CD27 alu:CD28 alu:CD29 alu:CD3 alu:CD30 alu:CD31 alu:CD32 alu:CD33 alu:CD34 alu:CD35 alu:CD4 alu:CD5 alu:CD6 alu:CD7 alu:CD8 alu:CD9 backplane:C1 backplane:C10 backplane:C2 backplane:C3 backplane:C4 backplane:C5 backplane:C6 backplane:C7 backplane:C8 backplane:C9 cf:CD1 cf:CD2 cf:CD3 cf:CD4 cf:CD5 cf:CD6 cf:CD7 cf:CD8 cf:CD9 control:CD1 control:CD10 control:CD11 control:CD12 control:CD13 control:CD14 control:CD15 control:CD16 control:CD17 control:CD18 control:CD19 control:CD2 control:CD20 control:CD21 control:CD3 control:CD4 control:CD5 control:CD6 control:CD7 control:CD8 control:CD9 io:CD1 io:CD10 io:CD11 io:CD12 io:CD13 io:CD14 io:CD15 io:CD16 io:CD2 io:CD3 io:CD4 io:CD5 io:CD6 io:CD7 io:CD8 io:CD9 led:CD1 led:CD2 led:CD3 led:CD4 led:CD5 led:CD6 memory:CD1 memory:CD10 memory:CD2 memory:CD3 memory:CD4 memory:CD5 memory:CD6 memory:CD7 memory:CD8 memory:CD9 regbank:CD1 regbank:CD10 regbank:CD11 regbank:CD12 regbank:CD13 regbank:CD14 regbank:CD15 regbank:CD16 regbank:CD17 regbank:CD18 regbank:CD19 regbank:CD2 regbank:CD20 regbank:CD21 regbank:CD22 regbank:CD23 regbank:CD24 regbank:CD25 regbank:CD26 regbank:CD27 regbank:CD28 regbank:CD29 regbank:CD3 regbank:CD30 regbank:CD31 regbank:CD32 regbank:CD33 regbank:CD34 regbank:CD35 regbank:CD36 regbank:CD37 regbank:CD38 regbank:CD39 regbank:CD4 regbank:CD40 regba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
1 | DS1302 | DIP8 | Peripheral IC | yes | RTC (DNP option) | io:U16
1 | MAX232 | DIP16 | Peripheral IC | yes | RS-232 level shifter (+ its 1uF caps) | io:U8
1 | MC6850 | DIP24W | Peripheral IC | yes | ACIA — OBSOLETE, source NOS (eBay/specialist) | io:U14
2 | Resistor 100R | R_AXIAL | Resistor | yes |  | backplane:RT1 backplane:RT2
3 | Resistor 10K | R_AXIAL | Resistor | yes |  | control:R1 control:R2 control:R3
22 | Resistor 1K | R_AXIAL | Resistor | yes |  | alu:R4 alu:R5 alu:RP1 backplane:RL1 cf:R4 cf:RP1 control:R4 control:R5 control:RP1 io:R4 io:RP1 led:R4 led:RP1 memory:RP1 memory:RS1 memory:RS2 memory:RS3 memory:RS4 memory:RS5 regbank:R4 regbank:R5 regbank:RP1
1 | Resistor 330R | R_AXIAL | Resistor | yes |  | cf:R5
3 | Resistor network 8X10K (bussed, 9-pin SIP) | SIP9 | Resistor network | yes |  | backplane:RN1 cf:RN1 io:RNP
4 | Resistor network 8X330R (isolated, SIP) | SIP16 | Resistor network | yes |  | io:RL1 io:RM1 io:RM2 io:RM3
1 | Resistor network 8x330R (isolated, SIP) | SIP16 | Resistor network | yes |  | led:RL1
1 | DIP switch, 8-position | DIP16 | Switch | yes |  | io:SW1
3 | Switch SPST (momentary/toggle) | SW2P | Switch | yes |  | control:SWR control:SWS control:SWT

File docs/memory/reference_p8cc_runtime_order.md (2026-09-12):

---
name: p8cc-runtime-order-gate
description: "compiler/p8cc.py emit_runtime only emits helpers named in its explicit `order` list; a new __helper missing from it makes EVERY command fail with \"undefined symbol\""
metadata: 
  node_type: memory
  type: reference
  originSessionId: 6ffcfef7-73ca-445b-bcdb-f57735fdc98f
  modified: 2026-09-11T11:15:02.778Z
---

In `compiler/p8cc.py`, `emit_runtime` builds a dict `R["__name"] = [...]` of
runtime routines, but only the names in the explicit `order` list are emitted
(in that order). Adding a routine to `R` without adding it to `order` compiles
silently and then fails at ASSEMBLY of every command that references it:
`undefined symbol '__cmp16'` across 44/45 /bin commands (2026-09-05, the
compiler-only size wins: `__cmp16`, `__ldtw`, `__ldtb` all needed `order` entries).

Since 2026-09-11 the runtime is only `__mul`, `__div`/`__mod`/`__divmod`,
`__shl`/`__shr` and `__cmp16` (var==var equality); `+ - & | ^` and every other
compare are inline word instructions (`gen_wordop`/`gen_relcond`), and the
`__add/__sub/__and/__or/__xor/__eq/__lt/__not` helpers no longer exist — do not
re-add them, emit the instruction.

**How to apply:** any new p8cc runtime helper = two edits (R[...] AND `order`).
Measure size with `sh tools/p8cc_sizes.sh` (compiles all /bin C commands via the
run.sh pipeline, prints per-command bytes + TOTAL, FAIL rows for regressions);
diff against a saved baseline. Related: [[p8cc-int-is-unsigned]] — `__cmp16`
compares are deliberately UNSIGNED (JC/JNC after 16-bit CMP), matching the old
helpers; signed compares are a separate deliberate change, not a bug fix.

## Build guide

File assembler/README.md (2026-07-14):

# assembler/

`p8xasm.py` — the P8X two-pass assembler.

It shares its opcode table with the microcode generator: mnemonics and encodings
come straight from `genucode.OPC`, so the assembler and the hardware can never
disagree about what an opcode means. (Edit the instruction set in
[`../microcode/genucode.py`](../microcode/genucode.py), not here.)

## Usage

```sh
python3 p8xasm.py src.asm [-o out.bin] [-l listing.txt] [--base ADDR] [-D NAME=VAL ...]
```

- **No `--base`** → an 8 KB ROM image (origin `$0000`, `$0000–$1FFF`), ready for the
  memory-card EEPROM. This is how the monitor (program ROM) is built.
- **`--base A`** → a RAM-resident blob: labels resolve to run address `A`, and
  only the `A..high` bytes are emitted. This is how P8X/OS and disk BASIC are
  assembled to load somewhere other than `$0000`.
- **`-D NAME=VAL`** → define an assembly-time symbol (used to parameterize BASIC
  via `BASORG`/`BASRAM`, for example).
- **`-l`** → write a listing file (address + bytes + source per line).

## Directives

- `.org`, `.byte`, `.word`, `.fill`, `.ascii`, `.asciiz`, `.equ`
- **`.include "file"`** → splice another source file at this point (recursively;
  path resolved relative to the *including* file; cycles are an error). Lets
  sources share a committed equates file — e.g. the generated `memmap.inc` — so a
  memory-map constant lives in one place instead of being copied into firmware,
  the OS, and `p8xcc`.

## Notes

- Two passes: pass 1 builds the symbol table, pass 2 emits bytes.
- `;` starts a comment **even inside a quoted string** — avoid `;` in `.ascii`
  strings.

See [GLOSSARY.md](../GLOSSARY.md) for mnemonics and the [programmer's guide](../docs/p8x-programmers-guide.pdf)
for the full instruction set.

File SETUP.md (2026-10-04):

# Setting up a machine to work on P8X

P8X is a macOS project. The whole machine — every KiCad board, the emulator,
microcode, OS, compiler, firmware, docs, and the committed ROM/Gerber artifacts
— lives in this one repository, so setup is: install the toolchain, clone, and
verify.

The toolchain splits into four tiers. **Only Tier 1 is required** — it is enough
to write and build the emulator, microcode, assembler, OS, compiler and firmware,
and to run the tests. The higher tiers are needed only for the work that uses
them, so a machine meant purely for software development can stop after Tier 1.

| Tier | Area | Needed for |
|---|---|---|
| 1 | Core software | emulator, microcode, assembler, OS, compiler, `make test` |
| 2 | Hardware / CAD | regenerating the KiCad boards (placement → Freerouting → Gerbers → DRC) |
| 3 | Documentation | the reference PDFs (programmer's guide, bus definition, memory map) |
| 4 | Website & FPGA | the MkDocs site and the Icarus/Tang-Nano simulation + board flow |

## Check what is already present

After cloning, run the checker. It reports every tier and names the fix for
anything missing; its exit code is non-zero only when a **Tier 1** tool is absent.

```sh
python3 tools/setup_check.py
```

Re-run it after installing something to confirm the gap is closed. `--tier N`
limits it to one tier; `-q` prints only the summary line.

## Clone

The remote is HTTPS, so cloning needs no special setup:

```sh
git clone https://github.com/ksr/p8x.git ~/Developer/p8x
```

Pushing over HTTPS needs a credential. The simplest is the GitHub CLI, which
stores a token in the macOS keychain — install it (Tier-0 tools, below), then run
`gh auth login` and choose HTTPS.

## Verify Tier 1

```sh
cd ~/Developer/p8x/emulator && make && make test
```

A healthy machine prints `P8X lives! same ucode as the EPROMs` and then HALTs.
Once that passes, the machine is ready for all core development.

---

## Tier 0 — base system

On a Mac with administrator access, the base tools come from Apple's Command Line
Tools and Homebrew.

Command Line Tools provide `cc`/clang, `make` and `git`:

```sh
xcode-select --install
```

Homebrew is the package manager for everything else:

```sh
/bin/bash -c "$(curl -fsSL https://raw.githubusercontent.com/Homebrew/install/HEAD/install.sh)"
```

The GitHub CLI handles push authentication:

```sh
brew install gh
```

### A managed Mac without administrator access

On an IT-managed Mac the standard Homebrew install fails (it cannot write to
`/opt/homebrew` and cannot use `sudo`). Two facts make this a non-problem for
software development:

1. **Core development needs no administrator rights.** If the checker shows
   Tier 1 already green — managed dev Macs usually ship with the Command Line
   Tools — clone and build straight away; nothing else is required.
2. **Homebrew installs into a home directory without `sudo`.** Unpack it under
   `~/homebrew` and add it to the shell:

   ```sh
   mkdir -p ~/homebrew && curl -L https://github.com/Homebrew/brew/tarball/master | tar xz --strip-components 1 -C ~/homebrew
   ```

   ```sh
   echo 'eval "$($HOME/homebrew/bin/brew shellenv)"' >> ~/.zprofile && eval "$($HOME/homebrew/bin/brew shellenv)"
   ```

   A home-directory Homebrew cannot use Apple's prebuilt bottles, so some
   formulae compile from source (slower), but it installs CLI tools —  `gh`,
   `temurin`, `icarus-verilog` — without administrator rights.

Casks that install into `/Applications` (KiCad, Google Chrome) still need a
writable `/Applications`; where that is locked down, those Tier 2–3 tools need
IT to install them, or a copy kept in a home directory with the generator paths
pointed at it. A machine doing only Tier 1 software work needs none of them.

## Tier 1 — core software

Provided entirely by Tier 0 (clang + `make` + `git` + `python3`). No third-party
Python packages are required to build the emulator or run the tests.

## Tier 2 — hardware / KiCad board regeneration

The board generators call KiCad's **bundled** Python (for `pcbnew`) and
`kicad-cli` at fixed paths under `/Applications/KiCad/KiCad.app`, and route with
Java-based Freerouting.

```sh
brew install --cask kicad
```

```sh
brew install temurin
```

Freerouting is a single jar. The build scripts look for it at
`~/freerouting/freerouting.jar` (override with the `FRJAR` environment variable).
Download the Freerouting 1.9.0 release jar and place it there:

```sh
mkdir -p ~/freerouting
```

With those present, a board regenerates and passes its readiness check end to
end — for example:

```sh
sh generators/build.sh memory-card
```

## Tier 3 — documentation PDFs

The reportlab PDFs (programmer's guide, bus definition, ISA card) import
`reportlab` into the **host** Python:

```sh
python3 -m pip install reportlab
```

The memory-map PDF renders through headless Google Chrome (override the binary
with the `CHROME` environment variable):

```sh
brew install --cask google-chrome
```

Regenerate, for example:

```sh
python3 microcode/gen_progguide.py
```

```sh
python3 generators/gen_memmap_pdf.py
```

## Tier 4 — website and FPGA

The website build creates its own Python virtual environment from
`website/requirements.txt`, so it needs no manual package install — only a
working `python3` with `venv`:

```sh
sh website/build.sh serve
```

The FPGA co-simulation needs Icarus Verilog; the Tang Nano 20K board build and
flashing additionally need oss-cad-suite (which provides `openFPGALoader`):

```sh
brew install icarus-verilog
```

---

## Working from two machines

With more than one machine on the same branch, pull before starting and push when
finishing on each, or the two clones diverge. Commit directly per the project
workflow; branch only when a feature needs it, and never merge a branch to `main`
without explicit confirmation.

Claude Code's cross-session memory is **not** part of the repository — it lives
under `~/.claude/` on each machine — so a fresh Claude Code on another Mac starts
without those notes. The repository's own documentation (CLAUDE.md, the READMEs,
BACKLOG.md) travels with the clone and carries the load-bearing facts.

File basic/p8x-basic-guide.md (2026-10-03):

# P8X BASIC — Programmer's Guide

P8X BASIC is a small integer BASIC that runs on the P8X TTL CPU, written in P8X
assembly (`p8xbasic.asm`) and assembled by `p8xasm.py`. It talks to you over the
6850 ACIA serial console. This guide documents the language **as implemented** —
if something isn't listed here, it isn't supported yet (see *Limits*).

> Source of truth: `basic/p8xbasic.asm`. The companion [README](README.md) covers
> build internals and milestones; this is the language reference.

## Running it

From the repo root:

```sh
./basic/run.sh
```

That assembles BASIC, builds the microcode, compiles the emulator, and drops you
at a live prompt. Type lines and press **Enter**. Quit with **Ctrl-C** (or
**Ctrl-D**). The terminal runs raw/no-echo (BASIC echoes), so it behaves like a
real serial console.

### Versions of BASIC

The same interpreter ships four ways (identical language; they differ only in
where the code and its data live and how you start it):

| Build | Code | Data | Invoked by |
|---|---|---|---|
| ~~Standalone~~ | `$0000` | `$8000` | **retired 2026-08** — BASIC's console I/O now goes through the BIOS, which this build replaces. See [README](README.md). |
| Disk | `$2000` | `$A000` | a bootable P8XFS image, started with the monitor's `B` command (rev E loads the OS region at `$2000`) |
| Run-from-OS | `$5900` | `$C500` | a TPA program (`BASIC.BIN`); `RUN` it from the OS, `BYE` returns to the OS |

`Code` is where the interpreter runs and `Data` is the base of its variables and
program storage; everything else about the language is the same. The usual way
in is **`RUN BASIC.BIN`** from the OS (`BYE` returns to the OS); a standalone
BASIC disk also boots with the monitor's **`B`**. (BASIC is no longer in the
monitor ROM — the old `X` command was removed.) Build commands are in the
[README](README.md).

## The two modes

- **Immediate mode** — a line with *no* leading line number runs at once:
  ```
  PRINT 2+3*4      ->  14
  LET A=10 : PRINT A*A   ->  100
  ```
- **Program mode** — a line that *starts with a number* is stored, not run:
  ```
  10 PRINT "HELLO"
  20 GOTO 10
  ```
  Type `RUN` to execute the stored program.

### Editing a program

| You type | Effect |
|---|---|
| `30 PRINT X` | insert line 30 (or **replace** it if it exists) |
| `30` (number alone) | **delete** line 30 |
| `LIST` | print the program in line-number order |
| `NEW` | erase the whole program |
| `SAVE "NAME"` | write the program to a file on the CompactFlash card (`Saved`) |
| `LOAD "NAME"` | replace the program with a saved file (`Loaded`) |

Lines are always kept sorted by number regardless of entry order. Keywords are
tokenized on entry (stored as single bytes) and expanded again by `LIST`.

`SAVE`/`LOAD` store programs as files in the P8XFS filesystem (via the
BIOS filesystem calls), so they work in the **disk** and **run-from-OS** builds —
the standalone whole-ROM build has no card access and can't use them.

The name may be a **path**. A bare name (`SAVE "GAME"`) is relative to the
**current directory**, so under P8X/OS `cd SRC` then `SAVE "GAME"` writes
`/SRC/GAME`; a leading slash is absolute (`SAVE "/SRC/GAME"`, `LOAD "/SRC/GAME"`)
and works from anywhere. BASIC resolves the path through the same filesystem
resolver the OS uses, so it can save into any existing directory — make one with
`MKDIR` in the OS first.

> Before 2026-08 a bare name always went to the **root**, whatever directory you
> were in, because BASIC handed the name straight to the BIOS resolver (which
> starts at the root) without first prefixing the current directory the way the
> `/bin` commands do. The disk-boot build still resolves from the root, correctly:
> there is no OS underneath it and so no current directory to be relative to.

Each leaf name is up to 12 characters and
**case-sensitive** (`GAME` and `game` are different files). `SAVE` reports
`?Save failed` if the name exists or the disk is full, `LOAD` reports `?No file`
if it isn't found. Files created here are visible to P8X/OS (`DIR`) and the host
`p8xfs.py` too.

## Numbers, variables, strings

- **Numbers** are **signed 16-bit integers**, range **−32768 to 32767**, written
  in decimal *or* hex with a `0x` prefix (`0x1F`, `0xFF`, up to `0xFFFF`).
  Arithmetic wraps modulo 65536, so `0xFFFF` prints as `-1`.
- **Variables** have **names** that start with a letter and continue with
  letters or digits (e.g. `X`, `I`, `COUNT`, `X1`, `TOTAL`). Names are
  case-insensitive and **significant to 6 characters** (`COUNTER` and `COUNTED`
  are the same variable); up to 32 distinct variables. Each holds one integer
  and starts at 0 on first use. A name may begin with a keyword (`TOTAL`,
  `FORK`) as long as it's followed by more letters/digits — `TO X` is the `TO`
  keyword, `TOTAL` is a variable. (No arrays.)
- **Strings** are sequences of characters, up to **32** long. They appear as
  **literals** (`"HI"`) and as **string variables**, whose names end in `$`
  (`A$`, `NAME$`). A string variable is a *separate* variable from the numeric
  one of the same base name (`A` and `A$` are unrelated) and starts out empty
  (`""`). Up to **16** string variables. Strings are joined with `+`
  (`A$ + "!"`), and a value longer than 32 characters is truncated to 32.

## Expressions

Operators, highest precedence first:

| Level | Operators | Notes |
|---|---|---|
| unary | `-` `+` | `-5`, `--A` (both apply to the following factor) |
| 1 | `*` `/` `%` | integer multiply / divide (`/` truncates toward zero) / modulus (remainder of `/`) |
| 2 | `+` `-` | add / subtract |
| 3 | `=` `<>` `<` `>` `<=` `>=` | comparisons; yield **1** (true) or **0** (false) |

Parentheses override precedence: `(2+3)*4` → 20. Comparisons are signed and can
be used anywhere a number can: `PRINT 5>3` prints `1`; `LET F = A<0`.

**String expressions** use `+` to concatenate (`A$ + "!"`), and the same six
comparison operators compare two strings, character by character (a shorter
string sorts before a longer one with the same prefix) — yielding `1`/`0` just
like numeric comparisons, so they slot straight into `IF`:
`IF A$ = "Y" THEN ...`, `IF N$ < "M" THEN ...`.

### Functions

| Call | Returns |
|---|---|
| `ABS(x)` | absolute value of `x` |
| `RND(n)` | a pseudo-random integer **1..n** (LCG; `RND(6)` is a die) |
| `PIXELR(x,y)` | the COLOUR at a pixel — the GL `PIXRD` verb, so it maps through the current `WINDOW`/`VWPORT` like `PIXELW`; 0 if off-screen (was `POINT()`) |
| `PEEK(addr)` | the byte (0–255) at memory address `addr` |
| `LEN(s$)` | number of characters in the string `s$` |
| `ASC(s$)` | code (0–255) of the first character (0 if empty) |
| `CHR$(n)` | a one-character string with character code `n` |
| `LEFT$(s$,n)` | the first `n` characters of `s$` |
| `RIGHT$(s$,n)` | the last `n` characters of `s$` |
| `MID$(s$,i[,n])` | `n` characters of `s$` starting at position `i` (1-based); to the end if `n` is omitted |
| `STR$(x)` | the decimal text of number `x` (e.g. `STR$(-7)` is `"-7"`) |
| `VAL(s$)` | the number parsed from the start of `s$` (signed; stops at the first non-digit; `0` if none) |
| `EOF(n)` | `1` if the input data file is at end (or not open), else `0` (see *Data files*) |

`LEN`/`ASC`/`VAL`/`EOF` return numbers; `CHR$`/`LEFT$`/`RIGHT$`/`MID$`/`STR$`
return strings (their names end in `$`). `STR$` and `VAL` are inverses — the
number↔string conversion pair. Counts are clamped to what the source actually holds, so
`LEFT$("HI",9)` is just `"HI"`. `POKE addr,val` is a *statement* (below).

## Statements

A line may hold several statements separated by `:` —
`A=1 : B=2 : PRINT A+B`.

| Statement | Meaning |
|---|---|
| `PRINT items` | print numbers/strings (see below); empty `PRINT` = blank line |
| `LET v = expr` | assign; the `LET` is optional, so `A=5` works too. Works for string variables too: `A$ = "HI"`, `N$ = F$ + L$` |
| `IF expr THEN ...` | if `expr` is non-zero, run the rest of the line; the `THEN` part may be a statement (`THEN PRINT X`) **or** a line number (`THEN 100`, an implicit `GOTO`) |
| `FOR v = a TO b [STEP s]` | begin a counting loop (`STEP` defaults to 1; negative start/limit OK) |
| `NEXT [v]` | end of loop body: add the step, loop back if still ≤ limit |
| `GOTO line` | jump to `line` |
| `GOSUB line` | call a subroutine; execution resumes after the `GOSUB` on `RETURN` |
| `RETURN` | return from the most recent `GOSUB` |
| `INPUT v` | print `? ` and read a value from the console into `v`; for a string variable (`INPUT A$`) the whole reply line becomes the string |
| `REM text` | comment; the rest of the line is ignored |
| `END` | stop the running program |
| `OPEN s$ [FOR] OUTPUT` / `OPEN s$ [FOR] INPUT` | open the data-file channel for writing / reading (see *Data files*) |
| `PRINT# expr` | write one value + newline as a record to the open output file |
| `INPUT# v` | read one record from the open input file into `v` (numeric or string) |
| `CLOSE` | close the data-file channel (commits an output file) |
| `COLOR r,g,b` / `COLOR c` | set the drawing colour: three numbers (`r`,`b` 0–31, `g` 0–63), or one PACKED RGB565 value (for `RGB()` and `PIXELR()` round-trips) — see *Graphics* |
| `CLS` | clear the screen; the current `COLOR` is **not** changed |
| `PIXELW x,y` | one pixel (was `PLOT`) |
| `LINE x0,y0,x1,y1` | draw a line, both endpoints included |
| `BOX x0,y0,x1,y1[,FILL\|,NOFILL]` | rectangle — outline by default, solid with `FILL` |
| `CIRCLE x,y,r[,FILL\|,NOFILL]` | circle of radius `r` about `x,y` |
| `CIRCLE x,y,rx,ry[,FILL\|,NOFILL]` | **ellipse** — a second radius gives separate x and y radii |
| `RGB(r,g,b)` | *function*: pack a colour — `r`,`b` 0–31, `g` 0–63 |
| `IMAGE x,y,name$` | draw a P8I image file with its bottom-left at `x,y` |
| `GL s$` | send one raw graphics-language line as text — see *The graphics language* |
| `WINDOW` `VWPORT` `MOVE3` `DRAW3` `POLY3` `MDROTY` `CLBEG` `FLIP` … | the GL engine's verbs as native statements (51 of them) — see *The graphics language* |

### Graphics

Drawing goes to the display device. If none is fitted these statements print
`?No display` rather than quietly doing nothing.

> **Seeing it under the emulator.** There is no live window: press **Ctrl-\\** to
> render the screen to your terminal and keep going, or **Ctrl-C** to render it
> and quit. Run `p8xemu` with `-g out.ppm` as well and each of those also writes
> a real image file.

The screen is **480 × 272** in **RGB565 direct colour** — a pixel *is* its
colour, 0 is black; see *The screen* below for the colour model.

**One coordinate system: window space, y UP** — `x` runs 0–479 left to
right and `y` runs 0–271 **bottom to top**, mathematical convention,
the PGC's own, for *every* graphics statement. The drawing statements
emit the graphics language directly: they transform under
`WINDOW`/`VWPORT`, honour `LINPAT`/`LINFUN`, clip to the window, and
RECORD inside `CLBEG`/`CLEND`. BASIC establishes the full-screen window
at startup and again after a `RESETF` statement. `IMAGE` is the GL
`BLIT` verb since 2026-09-01 (one per row, the P8I file bytes streamed
verbatim), anchored at the image's **bottom-left** corner and mapped
through the current window like everything else — the last caveat is
gone, and BASIC no longer writes the device door at all; `PIXELW x,y` /
`PIXELR(x,y)` round-trip the same pixel through the GL port. Image
pixels stay 1:1 device pixels and do not scale
under a program's `WINDOW`/`VWPORT`.

```basic
10 COLOR 31,63,31               : REM white
20 BOX 0,0,479,271              : REM a border, outline
30 COLOR 0,63,0                 : REM green
40 LINE 0,0,479,271             : REM corner to corner
50 LINE 479,0,0,271
60 COLOR RGB(31,0,0)            : REM red, via the packing function
70 BOX 180,100,300,172,FILL     : REM a solid block
80 END
```

Any two opposite corners work for `BOX` — they are sorted for you, so
`BOX 150,86,90,50` draws the same rectangle.

**Ellipses.** A second radius turns `CIRCLE` into an ellipse — `rx` first, then
`ry`:

```basic
10 CIRCLE 240,136,80            : REM circle, radius 80
20 CIRCLE 240,136,180,60        : REM wide ellipse
30 CIRCLE 240,136,40,120,FILL   : REM tall, filled
```

The parser tells a second radius from the `FILL` modifier by looking at the
token: `FILL` and `NOFILL` are keywords, anything else begins an expression. That
is the second reason `NOFILL` had to be a real keyword rather than merely the
default — otherwise `CIRCLE x,y,r,NOFILL` would try to evaluate `NOFILL` as a
radius.

**Reading the screen back.** `PIXELR(x,y)` is a *function*, not a statement, and
returns the COLOUR at a pixel — 0 for anything off-screen — so a colour read
back compares exactly against the `RGB()` you drew with:

```basic
100 IF PIXELR(X,Y) = 0 THEN PIXELW X,Y
```

**Text on the screen** is the PGC's own stroke text: the OS streams
`/FONT.GL` to the card at boot, and `GTEXT` (reborn 2026-09-01 as *pure GL
emission* — the PGC port, never the device) is the easy way to use it:

```basic
10 COLOR 1
20 GTEXT 4,250,2,"P8X BASIC"    : REM window coords, absolute 2x
30 COLOR 2
40 GTEXT 4,236,1,"SCORE "+S$    : REM any string expression
```

It places correctly in *any* session state because it resets the modeling
matrix and camera itself (`PROJCT 0 : MDIDEN : TSIZE : MDTRAN : MOVE3 :
TEXT` under the hood) — which is also its deliberate cost: 3D programs
should use the raw verbs instead:

```basic
50 MOVE3 4,220,0 : TEXT "RAW"   : REM composes with TSIZE/TANGLE/TJUST
```

The anchor is the **baseline-left at the 3D current point** (`MOVE3 x,y,0`
— the 2D `MOVE` does not feed it), glyphs rising 7 units. `TSIZE n`
(256 = 1×) and `TANGLE` **compose into the modeling matrix** like every
matrix verb — `TSIZE 512` twice is 4×, and `TSIZE 256` is a ×1 no-op,
*not* a restore: reset with `MDIDEN` (or `RESETF`, which also restores
the native camera — reissue `PROJCT 0` after it). The anchor transforms
too: under 2×, `MOVE3` coordinates are model units, so model (30,20)
lands at screen (60,40). `TJUST h,v` justifies. Codes `$20`–`$5F` have glyphs, lowercase folds to uppercase, and
off-window strokes clip. BASIC cold-starts with `PROJCT 0` because text
strokes live at z=0, which the native camera near-clips; a `RESETF`
restores the native camera, so issue `PROJCT 0` again before text after it.
The glyph bank survives `RESETF` — a font is *installed*, not drawn — and a
program may replace any glyph with `TDEFIN`.

**The screen.** 480×272 in **RGB565 direct colour** — a pixel *is* its
colour, 65,536 of them, no palette and no modes. `RGB(r,g,b)` packs one:
five bits of red, six of green (the eye is fussiest there), five of blue.

```basic
10 COLOR 31,0,0 : BOX 0,0,479,271,FILL    : REM a red screen
20 COLOR 31,63,31                          : REM white
30 C=PIXELR(240,136) : COLOR C              : REM draw with a colour off the screen
```

`COLOR` takes either three numbers — `r,g,b` — or one *packed* colour: what
`RGB(r,g,b)` builds and `PIXELR(x,y)` returns. The comma decides, the same
way `CIRCLE`'s optional second radius does.

Arguments are masked to their fields. One wart, worn openly: BASIC's
integers are signed 16-bit, so a bright colour **prints** as a negative
number — `PRINT RGB(31,0,0)` says `-2048` — but stores and compares
bit-for-bit, so `IF PIXELR(x,y) = RGB(31,0,0)` works exactly.

`PALETTE` is gone with the palette: there is nothing to install a colour
into. Recolour-by-redraw is the trade stage 6 made for true colour.

**Images.** `IMAGE x,y,name$` draws a **P8I** file — the machine's own
picture format, ten self-describing header bytes (magic, version, geometry,
depth) and raw RGB565. The file knows its own size, so the statement cannot
be lied to about it; anything that is not P8I says `?NOT P8I`. Convert any
picture on the host with `tools/p8img.py photo.png` — it scales to fit the
screen and dithers to the 565 grid. Off-screen pixels are discarded, so an
image may hang off any edge. `IMAGE` borrows the data channel: a file
`OPEN`'d for `INPUT` is closed by it, like `SAVE` and `LOAD`.

**Colours.** There is no palette and no `PALETTE` statement (both retired
with direct colour, stage 6): the pen IS a colour. Set it either way —

```basic
10 COLOR 31,0,0                 : REM three numbers: r,b 0-31, g 0-63
20 COLOR RGB(0,63,0)            : REM or one packed value
30 C=PIXELR(10,10) : COLOR C     : REM ...including one read off the screen
```

Bright colours *print* as negative numbers (`PRINT RGB(31,0,0)` says
`-2048` — signed 16-bit ints), but store and compare bit-for-bit.

`NOFILL` exists so you can say it out loud; it is the default. It is a real
keyword rather than just an absence, because otherwise `NOFILL` would be read as
the word `NO` followed by the keyword `FILL` — and your outline would silently
come out solid.

**The device does the drawing, not BASIC.** `LINE` and `BOX` load a few hardware
registers and issue one command, so a filled box costs the same handful of
instructions as an empty one. That is why there is no speed penalty for `FILL`,
and why these statements are far faster than the equivalent `POKE` loop.

`GTEXT` is the exception, and deliberately so. The display has no text command,
and adding one would mean a font ROM and a glyph state machine in the FPGA, which
that build has no room for. So BASIC walks the glyph itself and issues one device
operation per lit pixel — fast enough for labels and titles, and it needs no
bitstream change at all, which is why `GTEXT` reached the board as nothing more
than a new `BASIC.BIN`.

Pen colours are chosen from 4096; the defaults are 0 black, 1 white, 2 red,
3 green. Every drawing command the device implements is now reachable from
BASIC; the one exception is its built-in self-test, which exists only in the
emulator (see [BACKLOG.md](../BACKLOG.md)) and can be triggered with `POKE` —
see the port table below.

### The graphics language (3D)

With a GL engine fitted (stage 10 — `man gl` on the machine documents the
device itself), the graphics language's verbs are **BASIC statements in
their own right**. Arguments are ordinary expressions, comma-separated,
the first one bare — so a rotation angle can be a variable, and a vertex
can be computed:

```basic
10 RESETF                       : REM power-up state (see below!)
20 CLEARS 0,0,0                 : REM both pages black (r,g,b)
30 WINDOW -120,120,-120,120     : REM 2D window -- x1,x2,y1,y2 order!
40 VWPORT 104,375,0,271         : REM where it lands on the screen
50 COLOR RGB(31,0,0)            : REM ONE pen statement, BOTH engines
60 PRMFIL 1                     : REM closed primitives fill
70 MDROTY A                     : REM compose a rotation, in degrees
80 POLY3 3,-80,-80,300,80,-80,300,0,40,420
90 FLIP
```

The full set, grouped the way `man gl` groups the device's verbs:

| Group | Statements |
|---|---|
| 2D | `MOVE` `MOVER` `DRAW` `DRAWR` `RECT` `RECTR` `POLY` `POLYR` `PRMFIL` `WINDOW` `VWPORT` `FLOOD` `CLEARS` |
| 3D | `MOVE3` `MOVER3` `DRAW3` `DRAWR3` `POINT3` `POLY3` `POLYR3` `CONVRT` |
| modeling matrix | `MDIDEN` `MDORG` `MDROTX` `MDROTY` `MDROTZ` `MDSCAL` `MDTRAN` `MDMATX` |
| viewing matrix | `VWIDEN` `VWRPT` `VWROTX` `VWROTY` `VWROTZ` `VWMATX` `DISTAN` `PROJCT` `DISTH` `DISTY` `CLIPH` `CLIPY` |
| command lists | `CLBEG` `CLEND` `CLRUN` `CLOOP` `CLDEL` `CLAPP` |
| pages & control | `FLIP` `PGSYNC` `WAIT` `RESETF` |

Parameters, units and order are exactly the device's — angles in degrees,
`WINDOW`/`VWPORT` in the PGC's `x1,x2,y1,y2` order, `FLOOD`/`CLEARS`
taking `r,g,b`. `POLY`/`POLY3` take a count and then that many vertices.
Two deliberate absences: `COLOR` (the ordinary `COLOR` statement now
sets the GL pen too, so one pen statement drives both drawing paths)
and `NOOP`. The GL `POINT` verb IS native now: the pixel-read function
became `PIXELR()` and freed the name (`GL "CIRCLE r"` remains the only
name BASIC's own centre-taking `CIRCLE x,y,r` still shadows).

**Recording.** Between `CLBEG n` and `CLEND` these statements *record*
into command list `n` instead of drawing, so a BASIC loop can build a
scene once and replay it — `CLOOP n,count` replays with matrix deltas
accumulating, which is how a stored scene spins with the CPU idle:

```basic
10 CLBEG 1 : MDROTY 5 : CLEND   : REM a list that nudges the world 5deg
20 CLOOP 1,7                    : REM 35 degrees, applied by the card
```

**Start with `RESETF`.** The machine draws its on-screen console text through
this same engine, and matrix verbs *compose* — without a reset, your first
rotation lands on top of whatever the console (or the last program) left
behind.

**`GL s$` is the text escape hatch** for anything without a native
statement — short forms, verbs newer than this guide:

```basic
50 GL "MDY "+STR$(A)
```

Mind the 32-character string limit: a GL line longer than that
truncates — a 9-coordinate `POLY3` does not fit in a string, which is
precisely why the native statements exist. Native statements also skip
the card's ASCII translator entirely (BASIC sends the binary opcode and
parameters), so they are faster and cannot mis-tokenize.

Native statements are **synchronous**: each one waits for the card to
finish before BASIC continues, so `PIXELR()` right after a draw reads
finished pixels — on silicon exactly as in the emulator. The price is
that a native `CLOOP` blocks until the whole replay ends; launch a
long fly-through with `GL "CLOOP 0 100"` instead — the text path does
not wait, and the card animates while BASIC runs on.

### Drawing modes — LINFUN (stage 10f)

`LINFUN m` picks how drawn pixels combine with what is already on the
screen: `0` replace (the default), `1` complement (invert the pixel
underneath — the pen is ignored), `2` OR, `3` AND, `4` XOR. It applies
to **lines, points and outlines from every drawing statement** — the
mode lives in the display device, so BASIC's own `LINE` and `PIXELW`
honour it just like the GL verbs. Fills always replace.

XOR is the one to know: drawing the same thing twice removes it and
restores whatever was underneath, pixel-perfect — rubber-band cursors,
crosshairs, and erase-by-redraw animation without touching the scene:

```
10 LINFUN 4 : COLOR RGB(31,0,0)
20 FOR I=1 TO 20
30 LINE 50,100,430,200
40 LINE 50,100,430,200
50 NEXT I
60 LINFUN 0
```

The line strobes across the picture and everything under it survives.
`RESETF` (and a reboot) returns the mode to replace, so a scene that
begins with `RESETF` never inherits a stale mode.

### Flood fill — AREA / AREABC (stage 10g)

`AREA` seed-fills from the GL 2D current point (set it with `MOVE`)
using the pen, bounded by pen-coloured pixels: outline any closed
shape, `MOVE` inside it, `AREA`. `AREABC r,g,b` bounds on a stated
colour instead, so the fill and the outline can differ:

```
10 RESETF : CLEARS 0,0,0
20 WINDOW 0,479,0,271 : VWPORT 0,479,0,271
30 COLOR RGB(0,0,31)
40 POLY 4,300,200,350,150,400,200,350,250
50 COLOR RGB(0,63,0) : MOVE 350,200
60 AREABC 0,0,31
```

draws a blue diamond and fills it green. The fill walks real
framebuffer pixels, so anything already drawn bounds it. A seed
outside the window raises a GL error; a seed sitting on the boundary
(or on pen-coloured pixels) quietly fills nothing. `PRMFIL 1` remains
the way to draw primitives filled in the first place; `AREA` fills
what exists only as an outline — always in replace mode, whatever
`LINFUN` says.

### Vector text — TEXT / TSIZE / TANGLE / TDEFIN (stage 10h)

`TEXT s$` draws vector text at the GL current 3D point — any string
expression. The font is a set of stroke glyphs the OS ships as
`/FONT.GL`; load it once per power-up (`gl /FONT.GL` from the shell,
or stream it with `GL` from a program). Text rides the 3D pipeline, so
use the ortho camera and place with `MOVE3`:

```
10 RESETF : PROJCT 0 : CLEARS 0,0,0
20 WINDOW 0,479,0,271 : VWPORT 0,479,0,271
30 COLOR RGB(31,63,0) : TSIZE 512
40 MOVE3 40,100,0 : TEXT "HELLO"
```

`TSIZE s` (8.8 fixed point — 256 is design size, 512 doubles) and
`TANGLE d` (degrees) are compose aliases of `MDSCAL s,s,s` and
`MDROTZ d`: they transform the letterforms and the baseline together,
compose like every matrix verb (`MDIDEN` resets), and scale about
`MDORG` — anchor big or tilted text with `MDORG` at the same point as
the `MOVE3`. `TDEFIN c` records a custom glyph for char c from native
stroke statements (`MOVER3`/`DRAWR3`, closed by `CLEND`), so a program
can add its own symbols. Characters without a glyph skip silently;
lowercase folds to uppercase (the font covers ASCII 32–95).

### PRINT details

Items are separated by `,` or `;`:
- `;` — no space between items.
- `,` — one space between items.
- A **trailing** `;` or `,` suppresses the newline (so the next `PRINT`
  continues the same line).

```
PRINT "X="; X            ->  X=42
PRINT 1, 2, 3            ->  1 2 3
FOR I=1 TO 3 : PRINT I; : NEXT   ->  123
```

## Commands (immediate mode)

`RUN` (execute the stored program from the lowest line), `LIST`, `NEW`,
`SAVE "NAME"` / `LOAD "NAME"` (persist the program to the CompactFlash
filesystem — ROM/disk builds; see *Editing a program* above),
`HELP` (print the supported statements, commands, functions, and operators),
and `BYE` (leave BASIC — returns to the monitor in the ROM/disk builds).

## Data files

Beyond `SAVE`/`LOAD` (which store the *program*), BASIC can read and write its own
**data files** on the CompactFlash card — one sequential channel at a time, in the
disk and run-from-OS builds (the standalone whole-ROM build has no card access).

```
10 OPEN "SCORES" FOR OUTPUT      write mode: creates/overwrites the file
20 FOR I=1 TO 3
30   PRINT# I*I                  each PRINT# writes ONE value as a record
40 NEXT
50 PRINT# "DONE"                 numbers and strings both work
60 CLOSE                         CLOSE commits the file

70 OPEN "SCORES" FOR INPUT       read mode
80 IF EOF(1) THEN 120            EOF(n) is 1 once the file is exhausted
90 INPUT# N : PRINT N            read until end — no count needed
100 GOTO 80
120 CLOSE
```

- The filename is any string expression (`OPEN F$ FOR INPUT`) and may be a
  **path** — a bare name is relative to the **current directory**, and a leading
  slash is absolute: `OPEN "/LOGS/A" FOR OUTPUT` writes into that subdirectory
  wherever you are (like `SAVE`/`LOAD` above; the leaf is up to 12 characters).
  Under P8X/OS that means `cd LOGS` then `OPEN "A" FOR OUTPUT` and
  `OPEN "/LOGS/A" FOR OUTPUT` are the same file. The files are visible to `DIR`
  and the host `p8xfs.py`. The `FOR` is optional.
- `PRINT#` writes exactly **one value per record** (its text form followed by a
  newline). `INPUT#` reads exactly **one record**: into a numeric variable it
  parses the decimal number, into a string variable (`INPUT# A$`) it takes the
  whole record text.
- One channel is open at a time. Opening a missing file `FOR INPUT` prints
  `?No file`. `EOF(n)` returns `1` once the input file is exhausted (and `1` if
  no file is open), so `IF EOF(1) THEN ...` cleanly ends a read loop; the channel
  number `n` is accepted but there is only one channel.

## Memory & hardware access

`PEEK`/`POKE` reach the full memory map (addresses in decimal):

| Address (dec / hex) | What |
|---|---|
| 0–6143 / `$0000–$17FF` | EEPROM (the monitor + BIOS ROM — read-only; 6 KB on rev-E hardware) |
| 6144–8191 / `$1800–$1FFF` | RAM — the OS/BIOS scratch island (input line, sector buffer, BIOS scratch); leave it alone |
| 8192–65279 / `$2000–$FEFF` | RAM, 56 KB (the OS from `$2000`; the run-from-OS BASIC at `$5900`, its data from `$C500`) |
| 65280 / `$FF00` | switch input port (`PEEK`) |
| 65282 / `$FF02` | LED output port (`POKE`) |
| 65284–65285 / `$FF04–05` | 6850 ACIA status / data |
| 65360–65367 / `$FF50–57` | the graphics display's GL port (see below) |

So `POKE 65282, 170` lights an LED pattern, and `PRINT PEEK(65280)` reads the
switches.

The display's GL port is reachable too. The statements above cover the whole
language, so this is for poking at the hardware directly rather than for
reaching anything you otherwise could not:

| Address | |
|---|---|
| 65360 | `GLDATA` — write one GL command byte |
| 65361 | `GLSTAT` — bit 7 FIFO full, bit 6 busy, bit 1 error queued, bit 0 read-back byte ready |
| 65362 | `GLRB` — pop one read-back byte (a `PIXRD` reply, low then high) |
| 65363 | `GLERR` — pop one error byte (0 = none) |
| 65364 | `GLID` — reads `"G"` (71) when the engine is fitted |

Poll `GLSTAT` bit 7 before each `GLDATA` write (the FIFO can fill), and use
`GLID` to tell a missing display from a broken one — an absent card floats
every address to 255. A hand-poked white pixel at the centre of the window:

```basic
10 POKE 65360,6 : POKE 65360,31 : POKE 65360,63 : POKE 65360,31
20 POKE 65360,16 : POKE 65360,240 : POKE 65360,0 : POKE 65360,136 : POKE 65360,0
30 POKE 65360,8
```

(The `GL` statement does exactly this with less typing.) The old device
register window at `$FF20–2F` closed with the single-interface migration —
those addresses read 255 now. **Caution:** BASIC keeps its program and
variables from its data base upward (`$C500` in the run-from-OS build, `$A000` in
the disk build); poking there can corrupt your program.

## Examples

Countdown:

```
10 LET I=5
20 PRINT I
30 LET I=I-1
40 IF I>0 THEN 20
50 END
```

Sum 1..N with INPUT and a loop:

```
10 INPUT N
20 LET S=0
30 FOR I=1 TO N
40 LET S=S+I
50 NEXT
60 PRINT "SUM="; S
```

Subroutine called from a loop (prints 1, 4, 9, 16, 25, one per line):

```
10 FOR I=1 TO 5 : GOSUB 100 : NEXT
20 END
100 PRINT I*I
110 RETURN
```

Guess-a-number (uses RND and INPUT):

```
10 LET T=RND(100)
20 INPUT G
30 IF G=T THEN PRINT "GOT IT" : END
40 IF G<T THEN PRINT "LOW"
50 IF G>T THEN PRINT "HIGH"
60 GOTO 20
```

## Error messages

| Message | Cause |
|---|---|
| `?` | unrecognized statement/command |
| `?SYNTAX ERROR` | malformed expression or statement (e.g. unbalanced `)`) |
| `?SYNTAX ERROR IN 100` | the same, hit during `RUN` — names the failing line |
| `?UNDEF'D LINE` | `GOTO`/`GOSUB` to a line that doesn't exist |
| `?RETURN WITHOUT GOSUB` | `RETURN` with no matching `GOSUB` |

On any error the running program stops and returns to the prompt. A syntax error
raised while a program is running reports the line it happened on
(`?SYNTAX ERROR IN 100`); the bare form is used for mistakes typed at the prompt.

### Syntax checking at entry

Every line is checked for structural problems **the moment you enter it**, before
it is stored or run — so a typo is caught immediately, with the program left
unchanged, instead of only surfacing later at `RUN`. A line is rejected with
`?SYNTAX ERROR` (and *not* stored) if it has:

- **unbalanced parentheses** — `10 PRINT (1+2` or a stray `)`;
- an **unterminated string** — `20 PRINT "HI`;
- an **illegal statement start** — a line that begins with `THEN`, `TO`, `STEP`,
  or a function name (`ABS`/`RND`/`PEEK`), an operator, or a digit.

The check is deliberately *structural* only. It does **not** validate forward
references — `GOTO 100` before line 100 exists is legal and is still checked at
`RUN` (`?UNDEF'D LINE`) — and the tail of a `REM` is treated as free-form text,
so `10 REM (unbalanced "quotes` is accepted.

## Limits (current implementation)

- Numbers are integers only (16-bit signed); no floating point.
- Numeric variables: names ≤ 6 significant chars, up to 32; no arrays.
- String variables (`A$`): up to 16, each holding up to 32 characters; longer
  values are truncated. Not arrays. (`STR$`/`VAL` convert number↔string.)
- `FOR` loops nest **3 deep**; `GOSUB` nests **3 deep** (one more of either is a
  `?SYNTAX ERROR`).
- Data files: one channel open at a time, one value per record; `EOF(n)` tests
  for end of file — see *Data files*.
- No `DATA`/`READ`, `DIM`, `DEF FN`, `ON…GOTO`, or `WHILE`.
- Numbers are decimal only on input; `PRINT` shows signed decimal.

These reflect what `p8xbasic.asm` implements today; see [README](README.md) and
the project `BACKLOG.md` for what may come next.

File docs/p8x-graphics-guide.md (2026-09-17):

# P8X Graphics Engine — Programmer's Guide

How to draw things, from every seat in the house. The engine has four
doors, cheapest first:

| From | You write | Best for |
|---|---|---|
| the shell | `gl DRAW3 90,-90,300` or `gl FILE.GL` | exploring, scene files, demos |
| BASIC | native verbs: `MDROTY 20 : POLY3 3,...` | programs, animation, teaching |
| C | `//#use gfx` / `//#use g3d` / GL bytes | commands, tools |
| assembly | `;#use gfx` equates + the same registers | when it must be small |

All four reach the same silicon; the same scene renders identically
from any of them, and identically in the emulator and on the board.
Hardware internals: [p8x-graphics-theory.md](p8x-graphics-theory.md).
Reference cards on-target: `man gl`, `man gfx`, `man g3d`, `man basic`.

## 1. First light (any door)

Probe first — an absent display floats the bus:

    BASIC:  IF PIXELR(0,0) ... only after the OS booted with a display
    C:      if (!gpresent()) { puts("?No display"); return 1; }
    shell:  gl (prints ?No display / ?No GL engine itself)

Then, at the shell:

    gl VWPORT 0 479 0 271 WINDOW 0 479 0 271
    gl COLOR 0 63 0 PRMFIL 1
    gl MOVE 100,100 RECT 380,171

Everything after `gl` is one ASCII GL line (wrapped `CA ... CX` for
you). Numbers separate on spaces or commas; `man gl` is the verb card.

## 2. Coordinate spaces — the one thing to internalize

- **Screen space**: 480x272, origin top-left, y DOWN. The C gfx
  library and the shell `image` command keep this historical contract
  as an API convention — underneath they emit GL and map y through the
  identity flip (271−y); nothing speaks the old $FF20 device door any
  more. BASIC doesn't use screen space at all: since 2026-08-30/31
  EVERY BASIC graphics statement takes window coordinates (y up). The
  drawing statements emit GL; PIXELR() is the GL `PIXRD` verb
  (2026-08-31) and maps through the CURRENT window; text is PGC `TEXT`
  with the boot-loaded font (GTEXT is pure-GL 2D sugar over it); IMAGE
  is the GL `BLIT` verb (2026-09-01, one per row, bottom-left anchor
  mapped through the current window).
- **Window space**: the GL 2D world, y UP. `WINDOW x1 x2 y1 y2` (PGC
  order: both x's first!) declares the world extent; `VWPORT x1 x2 y1
  y2` maps it to screen pixels, flipping y. GL 2D primitives
  (MOVE/DRAW/POLY/RECT) are clipped to the window — off-window
  geometry is CUT, not discarded.
- **Model space**: 3D verbs (MOVE3/DRAW3/POLY3) pass through the
  modeling matrix, the viewing matrix, projection, and near/far
  clipping before landing in window space.

A faithful PGC stream may set WINDOW and assume the PGC's power-on
full-screen viewport; the P8X powers up with a degenerate viewport, so
lead scene files with `VWPORT 0 479 0 271` (BACKLOG has the note).

## 3. Drawing 2D

    gl COLOR 31 0 0                       red pen (r 0-31, g 0-63, b 0-31)
    gl MOVE 0,0 DRAW 239,135              line in window space
    gl PRMFIL 1 POLY 4 10 10 100 10 100 80 10 80    filled quad
    gl RECT 200,100                       rect from current point
    gl FLOOD 0 0 0                        erase the viewport

BASIC's statements ARE this language now (migrated 2026-08-30/31):
`LINE 0,0,479,271` is `MOVE`+`DRAW` in window space, corner to corner
under the default window and re-mapped by `WINDOW`/`VWPORT` like any
GL drawing. The C gfx library remains the raw screen-space path.

## 4. Drawing 3D

    gl RESETF
    gl VWPORT 104 375 0 271 WINDOW -120 120 -120 120
    gl COLOR 0 63 0 PRMFIL 1
    gl MDY 30                             compose: rotate model 30 deg
    gl POLY3 3 -80 -80 300 80 -80 300 0 40 420

Rules of thumb:

- **Matrices compose.** `MDY 20` twice is 40 degrees. `MDIDEN` resets
  the modeling matrix; `VWIDEN` the camera; `RESETF` everything.
- **The camera**: `VWRPT x y z` picks the point the viewer orbits,
  `VWX/VWY/VWZ deg` orbit it, `DISTAN d` backs the viewer off, `PROJCT
  angle` sets the lens (0 = orthographic; power-up = the native
  focal-256 camera, which is also what `DISTAN 0` means).
- **Fills are fans**: `PRMFIL 1` + `POLY3 n ...` fan-fills convex
  polygons through the triangle engine. Outlines clip per edge.
- **Depth**: near clipping is always on (z >= 16 in eye space); yon
  arrives with `DISTY d CLIPY 1`.

## 5. Scenes that persist: command lists

Immediate commands draw and are gone. A LIST is a recorded byte stream
on the card (64 slots x 4KB):

    gl CLBEG 2 CLEARS 0 0 0 POLY3 3 ... FLIP CLEND
    gl CLRUN 2                            one full frame
    gl MDIDEN MDY 40 CLRUN 2              redraw at a new angle

Record the erase and the FLIP INSIDE the list and every CLRUN is a
complete frame. For self-running animation, put the matrix delta
inside and loop — deltas accumulate per pass, the CPU is idle:

    gl CLBEG 1 MDY 5 CLRUN 2 CLEND       (a list may not run a list --
    gl CLOOP 1 72                         so spin via a second list that
                                          redraws the scene... see below)

(Nesting is refused, so the idiomatic spinner records the WHOLE frame
— delta, erase, draw, FLIP, WAIT 1 — in one list and CLOOPs it; `cube`
is the worked example, `man cube`.) `tri`/`rotate`/`camera` maintain
list 0 as "the scene"; `CLAPP` grows a list in place; `CLDEL` frees a
slot. Lists survive anything except power (SDRAM) and `RESETF`.

## 6. Drawing modes (LINFUN)

    gl LINFUN 4                           XOR mode
    gl MOVE 10,10 DRAW 200,200            draw...
    gl MOVE 10,10 DRAW 200,200            ...and un-draw: ground restored
    gl LINFUN 0                           back to replace

Modes: 0 replace, 1 complement (invert dest, pen ignored), 2 OR,
3 AND, 4 XOR. They apply to lines, points and outlines from EVERY door
(the mode lives in the display device), take effect between
primitives, and fills always replace. XOR is the rubber-band idiom;
complement is visible on any background. `RESETF`, reset, and power-up
restore replace mode.

## 7. Filling arbitrary shapes (AREA)

    gl COLOR 31,0,0                       red pen
    gl MOVE 100,100 RECT 200,150          an outline...
    gl MOVE 150,125 AREA                  ...seed-filled from inside

`AREA` flood-fills from the 2D current point with the pen, bounded by
pen-coloured pixels. `AREABC r g b` bounds on a stated colour instead,
so the fill and the outline can differ:

    gl COLOR 0,0,31                       blue outline
    gl POLY 4 300,200 350,150 400,200 350,250
    gl COLOR 0,63,0 MOVE 350,200          green pen, seed at centre
    gl AREABC 0,0,31                      fill up to the blue

The fill walks real framebuffer pixels (a scanline flood), so anything
already drawn is a boundary candidate. A seed outside the window is
error 2; a seed sitting ON the boundary colour (or on pen-coloured
pixels) quietly fills nothing. `PRMFIL 1` remains the right tool for
filled primitives you are about to draw; `AREA` is for shapes that
exist only as outlines — and it always paints in replace mode,
whatever `LINFUN` says.

## 8. Curves and patterns

    gl M 240,136 CI 60                    a circle at the current point
    gl PF 1 CI 40                         a filled disc
    gl EL 80,30                           an ellipse

`CIRCLE`/`ELIPSE` rasterize on the device with radii mapped through the
window→viewport scale (they clip to the screen; radii cap at 255 device
pixels). The PGC's `ARC` and `SECTOR` were removed 2026-08-30 for card
placement headroom (opcodes 3C/3D report error 1) — draw a partial arc
as a chain of short `D` segments; the card stepped 4° per segment, and
so can you.

    gl LPT -21846                         dashed lines ($AAAA)
    gl LPT -1                             solid again

`LINPAT` lives in the device like the LINFUN mode — every line from
every door is patterned, BASIC's `LINE` included, restarting at the
pattern's MSB each primitive. `AREA` forces solid+replace to protect
its own fill invariant, and `RESETF` restores everything. (The PGC's
`AREAPT` patterned fill mask was removed 2026-08-30 to buy placement
headroom on the full card — a successor-board candidate; its opcode
E7 reports error 1.)

## 9. Vector text (TEXT)

    gl /FONT.GL                           load the font (once per power-up)
    gl PRO 0                              text lives in window space
    gl M3 40,200,0 TX "HELLO WORLD!"      draw at the current 3D point

A glyph is a command list of relative strokes in a second 64-slot
bank — `TDEFIN c` records one exactly like `CLBEG`…`CLEND` records a
list, and the shipped `/FONT.GL` defines ASCII 32–95 (lowercase folds
to uppercase). Because strokes ride the ordinary 3D pipeline, `TSIZE`
(an alias of `MDSCAL s s s`, 8.8 fixed point: 256 = design size) and
`TANGLE` (an alias of `MDROTZ deg`) scale and rotate the letterforms
*and* the baseline walk together:

    gl MDI MDO 240,136,0 TS 1024 TA 20    4x, tilted 20 degrees,
    gl M3 240,136,0 TX "BIG"              anchored by MDORG

The aliases compose like every matrix verb — `MDIDEN` resets, and big
or tilted text wants `MDORG` at its anchor (scaling happens about the
model origin). Use `PROJCT 0` (ortho): at the perspective camera's
power-up settings, z=0 geometry sits behind the near plane and nothing
draws. Chars without a glyph skip silently; a font survives `RESETF`
but not power loss (it lives in SDRAM — stream `/FONT.GL` again).

Justify with `TJUST h v` (1/2/3 = left/centre/right and
bottom/middle/top): the offset applies in model units, so size and
angle transform it with the string. `TEXTP` is the same engine under
its PGC name, and since 10k `TEXT` records into command lists and
replays with the scene.

## 10. From BASIC

Every GL verb is a native statement (no quotes, expressions allowed):

    10 RESETF : CLEARS 0,0,0
    20 WINDOW -120,120,-120,120 : VWPORT 104,375,0,271
    30 COLOR RGB(0,63,0) : PRMFIL 1
    40 FOR A=0 TO 350 STEP 10
    50 MDIDEN : MDROTY A
    60 POLY3 3,-80,-80,300,80,-80,300,0,40,420
    70 NEXT A

`COLOR` is the GL pen, nothing else (GTEXT's old GPEN colour shadow retired 2026-09-01 -- GTEXT itself lives on as pure-GL 2D sugar that draws with the COLOR pen); `GL s$` sends a raw ASCII line when you need
string-building (`GL "MDY "+STR$(A)`); native list verbs
(CLBEG/CLEND/CLRUN) are synchronous, `GL "CLOOP 1 72"` is the
non-blocking spin. PIXELR(x,y) reads pixels through the GL `PIXRD` verb (single-interface, 2026-08-31): window coordinates through the CURRENT window map, fully symmetric with PIXELW in any window. The full
statement list: `man basic`, GRAPHICS; the language guide chapter in
`basic/p8x-basic-guide.md`.

## 11. From C

    //#use gfx      screen-space primitives, GL underneath (man gfx)
    //#use g3d      the software 3D pipeline / GL-era compatibility (man g3d)

For the GL port itself the idiom is three lines (as used by gl.c,
tri.c, cube.c):

    int glb(int v) { while (peek(0xFF51) & 128) { } poke(0xFF50, v); return 0; }
    int glw(int v) { glb(v & 255); glb((v / 256) & 255); return 0; }
    /* hex: glb(opcode); params glw(...)  --  drain GLERR when done */

Wait for idle with `while (peek(0xFF51) & 64) { }` before reading
results or exiting. Named constants: `//#use abi` + the `//#define`
header pattern; never raw magic numbers in shipped code.

## 12. Scene files

A `.GL` file is the ASCII language verbatim — `gl FILE.GL` streams it.
Start files with `CA ` (the hex-mode escape is the literal
space-terminated three bytes) and end with `CX `; lead with a VWPORT.
The PG-640A manual's examples convert mechanically (its hex files
carry 4-byte coordinates; re-emit as ASCII). `docs/reference/pg640a.pdf`
chapter 3 is effectively this engine's extended manual.

## 13. Performance model

- Command bytes are cheap; PIXELS are the cost. A fullscreen fill is
  ~65k pixel-pairs through the burst filler; a spinning cube is ~40
  bytes per frame.
- Matrix verbs cost a compose run at COMMAND time (microseconds);
  vertices then transform at fixed per-vertex cost.
- LINFUN modes add a read-modify-write per pixel — noticeable only in
  principle; invisible at panel rates.
- `WAIT n` inside lists paces to real frames; poll GLSTAT bit6 from
  outside rather than sleeping.
- The serial console is slower than everything above: stream scene
  FILES rather than typing long lines (the line editor keeps 63
  chars).

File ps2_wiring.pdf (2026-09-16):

# PS/2 keyboard + mouse → Tang Nano 20K

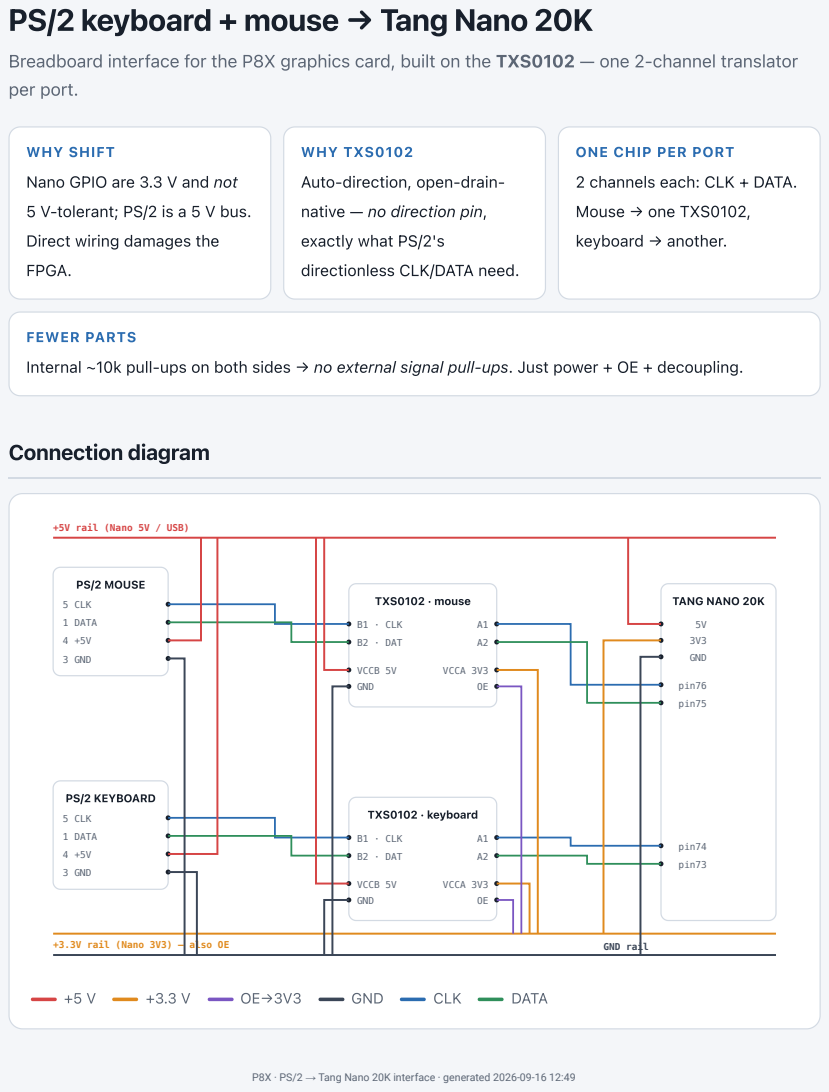
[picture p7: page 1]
Connection diagram; +3.3V rail (Nano 3V3) —; also OE; GND rail; PS/2 MOUSE; 5 CLK; 1 DATA; 3 GND; PS/2 KEYBOARD; TXS0102 · mouse; B1 · CLK; B2 · DAT; VCCB 5V GND; VCCA 3V3 OE; TXS0102 · keyboard; TANG NANO 20K; 5V 3V3 GND; pin76; pin75; pin74; pin73; GND; CLK; DATA

Breadboard interface for the P8X graphics card, built on the TXS0102 — one 2-channel translator
per port.

WHY SHIFT
Nano GPIO are 3.3 V and not
5 V-tolerant; PS/2 is a 5 V bus.
Direct wiring damages the
FPGA.

WHY TXS0102
Auto-direction, open-drain-
native — no direction pin,
exactly what PS/2's
directionless CLK/DATA need.

ONE CHIP PER PORT
2 channels each: CLK + DATA.
Mouse → one TXS0102,
keyboard → another.

FEWER PARTS
Internal ~10k pull-ups on both sides → no external signal pull-ups. Just power + OE + decoupling.

+5V rail (Nano 5V / USB)

P8X · PS/2 → Tang Nano 20K interface · generated 2026-09-16 12:49

No external pull-ups on the signal lines. The TXS0102 has ~10 kΩ pull-ups to VCCA and VCCB built into each channel — that is the PS/2 bus pull-up. Adding your own would fight the chip's edge-rate one-

## Wiring table — the authoritative reference

PS/2 | PIN | NET | TXS0102 | → B SIDE | A SIDE → | NANO
Mouse | 5 | CLK | #1 (mouse) | B1 | A1 | pin76
Mouse | 1 | DATA | #1 (mouse) | B2 | A2 | pin75
Keyboard | 5 | CLK | #2 (kbd) | B1 | A1 | pin74
Keyboard | 1 | DATA | #2 (kbd) | B2 | A2 | pin73
Both | 4 | +5V | both | VCCB | Nano 5V
— | — | +3.3V | both | VCCA + OE (both chips) | 3V3
Both | 3 | GND | both | chip GND | | GND

Nano pins 76/75/74/73 are examples — free on the current card build (used: 4, 15–20, 27–42, 48, 69, 70, 77, 81–84). Confirm they're broken out on your board and add them to tangnano20k.cst (below). Any four free GPIO work.

## How the TXS0102 does it (one channel)

Each channel is a bidirectional pass gate with an edge-rate accelerator (a one-shot that briefly drives hard on a rising edge, then hands back to the internal pull-up) and ~10 kΩ pull-ups to VCCA and VCCB. It senses which side goes low first and mirrors it to the other — no direction pin, which is why it suits PS/2, where either the host or the device can pull a line low at any time.

VCCA ≤ VCCB (3.3 ≤ 5 ✓) sets the two voltage domains. OE high enables all channels — tie it to VCCA so it comes up after both supplies. 0.1 µF on each VCC.

TXS0102 PIN | CONNECT TO
VCCA | 3.3 V (the lower rail)
VCCB | 5 V (the higher rail)
GND | GND
OE | 3.3 V (enable)
A1 / A2 | FPGA GPIO (3.3 V side)
B1 / B2 | PS/2 CLK / DATA (5 V side)

## Bill of materials

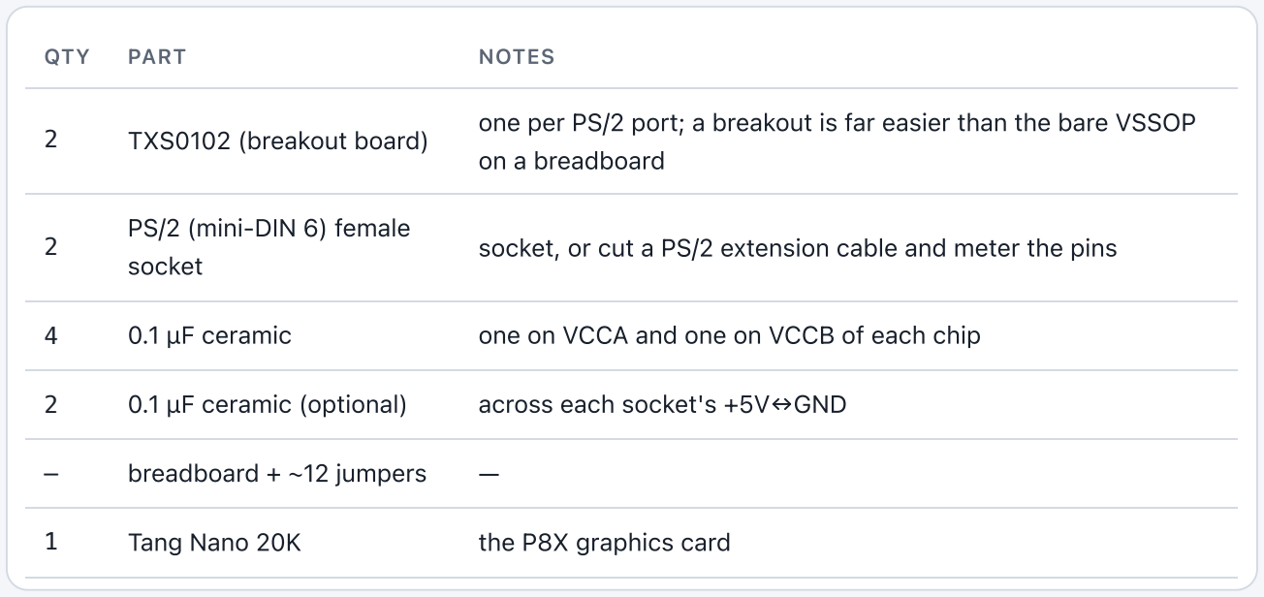
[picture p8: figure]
QTY; PART; NOTES; 2 TXS0102 (breakout board); on a breadboard; PS/2 (mini-DIN 6) female socket; 0.1 µF ceramic (optional); across each socket's +5V↔GND; breadboard + ~12 jumpers; Tang Nano 20K; the P8X graphics card

one per PS/2 port; a breakout is far easier than the bare VSSOP

socket, or cut a PS/2 extension cable and meter the pins

4 | 0.1 µF ceramic | one on VCCA and one on VCCB of each chip

No BSS138s, no discrete pull-up resistors — the two TXS0102s replace the 4-channel module and its pull-ups.

## Build order

### 1. Rails first. Nano 5V → red rail, 3V3 → a second rail, GND → blue rail. Meter 5.0 V and

3.3 V before anything else.

### 2. Each TXS0102: VCCB→5 V, VCCA→3.3 V, GND→GND, OE→3.3 V, 0.1 µF on each VCC. (OE low = all channels Hi-Z, so don't forget it.)

3. Sockets. pin 4→5 V, pin 3→GND, optional 0.1 µF across them. Meter the pins if you cut a cable — colours aren't standard.
4. Signals. Mouse CLK(5)→#1 B1, DATA(1)→#1 B2; keyboard CLK(5)→#2 B1, DATA(1)→#2 B2. Then #1 A1→pin76, A2→pin75; #2 A1→pin74, A2→pin73.

### 5. Constrain + build. Add the pins to tangnano20k.cst, wire them to the (future) PS/2

receiver in the RTL, rebuild the bitstream.

## FPGA side — constraints & the open-drain rule

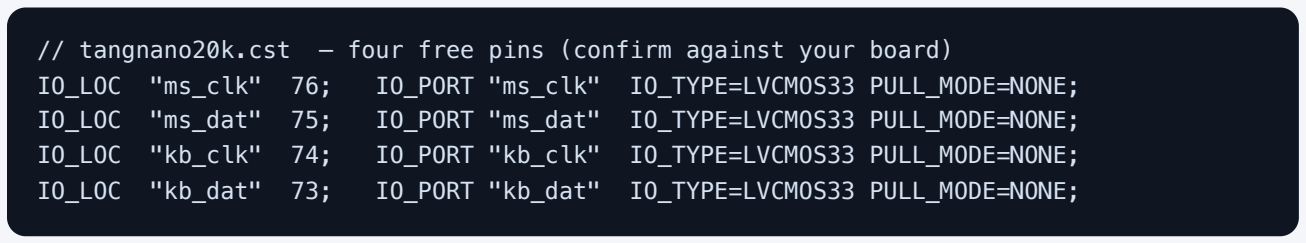
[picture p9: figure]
IO_LOC "ms_clk" 76;; IO_PORT "ms_clk" IO_TYPE=LVCMOS33 PULL_MODE=NONE;; IO_LOC "ms_dat" 75;; IO_PORT "ms_dat" IO_TYPE=LVCMOS33 PULL_MODE=NONE;; IO_LOC "kb_clk" 74;; IO_PORT "kb_clk" IO_TYPE=LVCMOS33 PULL_MODE=NONE;; IO_LOC "kb_dat" 73;; IO_PORT "kb_dat" IO_TYPE=LVCMOS33 PULL_MODE=NONE;

// tangnano20k.cst — four free pins (confirm against your board)

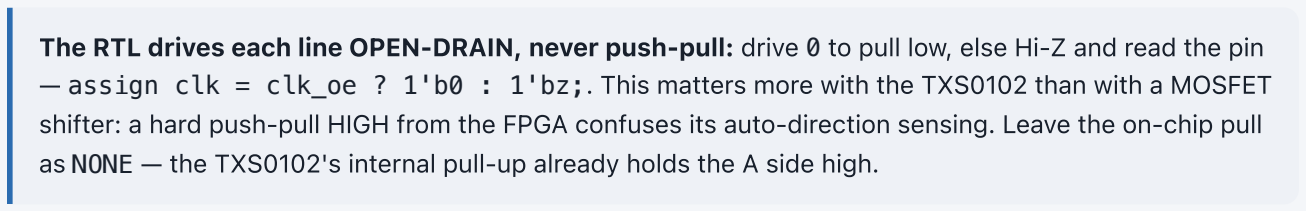
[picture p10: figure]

The RTL drives each line OPEN-DRAIN, never push-pull: drive 0 to pull low, else Hi-Z and read the pin — assign clk = clk_oe ? 1'b0 : 1'bz;. This matters more with the TXS0102 than with a MOSFET shifter: a hard push-pull HIGH from the FPGA confuses its auto-direction sensing. Leave the on-chip pull as NONE — the TXS0102's internal pull-up already holds the A side high.

Don't wire any PS/2 pin straight to the Nano, don't add external pull-ups on A/B, and don't power the devices from 3.3 V — a PS/2 keyboard/mouse needs 5 V.

P8X · PS/2 interface (TXS0102) for the Tang Nano 20K graphics card. Pairs with the emulator $FF58 model and lib_ps2; the RTL receiver (a shift register clocked by the device CLK) is the next hardware step.

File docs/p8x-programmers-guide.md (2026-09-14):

# P8X Programmer's Guide

Instruction set rev 1 — generated from the microcode source (`genucode.py`); opcode values, byte and cycle counts are extracted from the same tables that build the EPROM images, so this document cannot drift from the hardware.

## Programming model

**A, B** — 8-bit ALU operand registers; results land in A. **P0-P3** — four 16-bit pointer registers; the address bus is always driven by one of them. **P0** is the program counter. **P3** is the stack pointer (empty-descending: push writes then decrements; initialise it early — see note 3). P1 and P2 are general pointers used by the (Pn) addressing modes. **FLAGS** — C, Z, N, V, latched only by instructions marked in the Flags column.

**Memory map** (single-sourced in generators/gen_memmap.py): $0000-$17FF ROM (6K) | $1800-$FEFF RAM ($1800-$1FFF scratch island) | $FF00-$FFFF I/O: $FF00 switches (r), $FF02 LEDs (w), $FF04 ACIA status (bit0 RX ready, bit1 TX ready), $FF05 ACIA data.

**Reset:** P0 is forced to $0000; execution begins there. All other registers (including P3) are undefined on real hardware.

## Instruction set

### System

| Op | Mnemonic | Bytes | Cycles | Flags | Description |
|---|---|---|---|---|---|
| $00 | `NOP` | 1 | 2 | - | No operation. |
| $01 | `HLT` | 1 | 2 | - | Halt the clock. Resume only by reset (or emulator exit). |
| $72 | `CLC` | 1 | 2 | C | C := 0. |
| $73 | `SEC` | 1 | 2 | C | C := 1. |

### Interrupts (rev C)

| Op | Mnemonic | Bytes | Cycles | Flags | Description |
|---|---|---|---|---|---|
| $02 | `EI` | 1 | 2 | - | Enable maskable interrupts (IE := 1). |
| $03 | `DI` | 1 | 2 | - | Disable maskable interrupts (IE := 0). |
| $04 | `RTI` | 1 | 8 | - | Return from interrupt: pop flags then PC; re-enables IE. |
| $08 | `IRQ` | 1 | 10 | - | Software interrupt: push PC+flags, vector to $0808. Also the opcode the hardware forcing buffer injects on a maskable IRQ. |

### Load / store

| Op | Mnemonic | Bytes | Cycles | Flags | Description |
|---|---|---|---|---|---|
| $10 | `LDA #imm` | 2 | 2 | - | A := immediate byte. |
| $11 | `LDB #imm` | 2 | 2 | - | B := immediate byte. |
| $12 | `LDA addr` | 3 | 6 | Z N | A := byte at addr (absolute). |
| $13 | `LDB addr` | 3 | 6 | Z N | B := byte at addr (absolute). |
| $14 | `STA addr` | 3 | 6 | - | Byte at addr := A (absolute). |
| $15 | `LDA (P1)+` | 1 | 2 | - | A := memory at P1, then P1 := P1 + 1. |
| $16 | `LDA (P2)+` | 1 | 2 | - | A := memory at P2, then P2 := P2 + 1. |
| $17 | `LDA (P3)+` | 1 | 2 | - | A := memory at P3, then P3 := P3 + 1. |
| $19 | `STA (P1)+` | 1 | 2 | - | Memory at P1 := A, then P1 := P1 + 1. |
| $1A | `STA (P2)+` | 1 | 2 | - | Memory at P2 := A, then P2 := P2 + 1. |
| $1B | `STA (P3)+` | 1 | 2 | - | Memory at P3 := A, then P3 := P3 + 1. |
| $1D | `STA (P1)` | 1 | 2 | - | Memory at P1 := A. |
| $1E | `STA (P2)` | 1 | 2 | - | Memory at P2 := A. |
| $1F | `STA (P3)` | 1 | 2 | - | Memory at P3 := A. |
| $51 | `LDA (P1)` | 1 | 2 | Z N | A := memory at P1 (P1 unchanged). |
| $52 | `LDA (P2)` | 1 | 2 | Z N | A := memory at P2 (P2 unchanged). |
| $53 | `LDA (P3)` | 1 | 2 | Z N | A := memory at P3 (P3 unchanged). |
| $88 | `LDA (P1+d)` | 2 | 7 | C Z N | A := byte at P1 + d (d unsigned 0..255). C/V from the address add, then Z/N from A. P1 unchanged. |
| $89 | `LDA (P2+d)` | 2 | 7 | C Z N | A := byte at P2 + d (d unsigned 0..255). C/V from the address add, then Z/N from A. P2 unchanged. |
| $8A | `LDA (P3+d)` | 2 | 7 | C Z N | A := byte at P3 + d (d unsigned 0..255). C/V from the address add, then Z/N from A. P3 unchanged. |
| $8C | `STA (P1+d)` | 2 | 9 | C Z N | Byte at P1 + d := A. A preserved; flags clobbered by the address add. |
| $8D | `STA (P2+d)` | 2 | 9 | C Z N | Byte at P2 + d := A. A preserved; flags clobbered by the address add. |
| $8E | `STA (P3+d)` | 2 | 9 | C Z N | Byte at P3 + d := A. A preserved; flags clobbered by the address add. |

### ALU  (operands A,B; result to A unless noted)

| Op | Mnemonic | Bytes | Cycles | Flags | Description |
|---|---|---|---|---|---|
| $20 | `ADD` | 1 | 2 | C Z N | A := A + B. |
| $21 | `SUB` | 1 | 2 | C Z N | A := A - B. |
| $22 | `AND` | 1 | 2 | C Z N | A := A AND B. |
| $23 | `OR` | 1 | 2 | C Z N | A := A OR B. |
| $24 | `XOR` | 1 | 2 | C Z N | A := A XOR B. |
| $25 | `CMP` | 1 | 2 | C Z N | Flags from A - B; A unchanged. |
| $26 | `INC` | 1 | 2 | C Z N | A := A + 1. (B not used.) |
| $27 | `DEC` | 1 | 2 | C Z N | A := A - 1. (B not used.) |
| $28 | `SHL` | 1 | 2 | C Z N | A := A << 1, 0 into bit 0. (1) |
| $29 | `SHR` | 1 | 2 | C Z N | A := A >> 1, 0 into bit 7. (1) |
| $2A | `ROL` | 1 | 2 | C Z N | Rotate A left through carry. |
| $2B | `ROR` | 1 | 2 | C Z N | Rotate A right through carry. |

### ALU with T (rev C; 2nd operand = T register via B-mux; B preserved)

| Op | Mnemonic | Bytes | Cycles | Flags | Description |
|---|---|---|---|---|---|
| $80 | `ADDT` | 1 | 2 | C Z N | A := A + T. (B preserved.) |
| $81 | `SUBT` | 1 | 2 | C Z N | A := A - T. (B preserved.) |
| $82 | `ANDT` | 1 | 2 | C Z N | A := A AND T. (B preserved.) |
| $83 | `ORT` | 1 | 2 | C Z N | A := A OR T. (B preserved.) |
| $84 | `XORT` | 1 | 2 | C Z N | A := A XOR T. (B preserved.) |
| $85 | `CMPT` | 1 | 2 | C Z N | Flags from A - T; A and B unchanged. |
| $86 | `LDT #imm` | 2 | 2 | - | T := immediate byte. (No flags.) |
| $87 | `LDT addr` | 3 | 6 | - | T := byte at addr (absolute). (No flags.) |

### Pointer registers

| Op | Mnemonic | Bytes | Cycles | Flags | Description |
|---|---|---|---|---|---|
| $31 | `LPL1 #imm` | 2 | 3 | - | Low byte of P1 := immediate. |
| $32 | `LPL2 #imm` | 2 | 3 | - | Low byte of P2 := immediate. |
| $33 | `LPL3 #imm` | 2 | 3 | - | Low byte of P3 := immediate. |
| $35 | `LPH1 #imm` | 2 | 3 | - | High byte of P1 := immediate. |
| $36 | `LPH2 #imm` | 2 | 3 | - | High byte of P2 := immediate. |
| $37 | `LPH3 #imm` | 2 | 3 | - | High byte of P3 := immediate. |
| $54 | `INP1` | 1 | 2 | - | P1 := P1 + 1. |
| $55 | `INP2` | 1 | 2 | - | P2 := P2 + 1. |
| $56 | `INP3` | 1 | 2 | - | P3 := P3 + 1. |
| $58 | `DEP1` | 1 | 2 | - | P1 := P1 - 1. |
| $59 | `DEP2` | 1 | 2 | - | P2 := P2 - 1. |
| $5A | `DEP3` | 1 | 2 | - | P3 := P3 - 1. |
| $5E | `TAP1L` | 1 | 2 | - | Low byte of P1 := A. |
| $5F | `TAP1H` | 1 | 2 | - | High byte of P1 := A. |
| $60 | `TAP2L` | 1 | 2 | - | Low byte of P2 := A. |
| $61 | `TAP2H` | 1 | 2 | - | High byte of P2 := A. |
| $62 | `TAP3L` | 1 | 2 | - | Low byte of P3 := A. |
| $63 | `TAP3H` | 1 | 2 | - | High byte of P3 := A. |
| $68 | `TPA1L` | 1 | 2 | Z N | A := low byte of P1. |
| $69 | `TPA1H` | 1 | 2 | Z N | A := high byte of P1. |
| $6A | `TPA2L` | 1 | 2 | Z N | A := low byte of P2. |
| $6B | `TPA2H` | 1 | 2 | Z N | A := high byte of P2. |
| $6C | `TPA3L` | 1 | 2 | Z N | A := low byte of P3. |
| $6D | `TPA3H` | 1 | 2 | Z N | A := high byte of P3. |

### Stack

| Op | Mnemonic | Bytes | Cycles | Flags | Description |
|---|---|---|---|---|---|
| $70 | `PHA` | 1 | 2 | - | Push A onto the P3 stack. |
| $71 | `PLA` | 1 | 3 | Z N | Pop A from the P3 stack. |

### 16-bit memory ops (rev D; compiler space savers). PHW/PLW/LPW pure-microcode; MOVW adds the PT2 scratch pointer

| Op | Mnemonic | Bytes | Cycles | Flags | Description |
|---|---|---|---|---|---|
| $74 | `PHW addr` | 3 | 9 | - | Push the 16-bit word at addr onto the P3 stack: high byte first, then low, so the word lies LITTLE-ENDIAN at P3+1..P3+2 (readable with LDW a,(P3+d); same layout as a JSR return address). |
| $75 | `PLW addr` | 3 | 10 | - | Pop a 16-bit word from the P3 stack into addr (low then high). |
| $76 | `LPW1 addr` | 3 | 9 | - | P1 (16-bit) := the word at addr. |
| $77 | `LPW2 addr` | 3 | 9 | - | P2 (16-bit) := the word at addr. |
| $78 | `MOVW dst,src` | 5 | 13 | - | 16-bit memory->memory move: the word at src -> dst (via the PT/PT2 scratch pointers). |
| $79 | `LPW3 addr` | 3 | 9 | - | P3 (16-bit) := the word at addr -- restore a saved stack pointer. |
| $BD | `PHW (P1+d)` | 2 | 10 | C Z N | Push the 16-bit word at P1 + d onto the P3 stack, high byte first (little-endian at the new P3+1) -- the C compiler's argument push straight from a frame slot. A! (the address add); flags from that add. |
| $BE | `PHW (P2+d)` | 2 | 10 | C Z N | Push the 16-bit word at P2 + d onto the P3 stack, high byte first (little-endian at the new P3+1) -- the C compiler's argument push straight from a frame slot. A! (the address add); flags from that add. |
| $BF | `PHW (P3+d)` | 2 | 10 | C Z N | Push the 16-bit word at P3 + d onto the P3 stack, high byte first (little-endian at the new P3+1) -- the C compiler's argument push straight from a frame slot; d is measured BEFORE the push. A! (the address add); flags from that add. |

### Tier A: the C-compiler ISA (2026-09; pure microcode. A! = clobbers A; d = unsigned 8-bit displacement)

| Op | Mnemonic | Bytes | Cycles | Flags | Description |
|---|---|---|---|---|---|
| $38 | `LDP1 #imm16` | 3 | 5 | - | P1 := imm16. A real 3-byte instruction (was the LPL1/LPH1 pseudo-op pair). |
| $39 | `LDP2 #imm16` | 3 | 5 | - | P2 := imm16. |
| $3A | `LDP3 #imm16` | 3 | 5 | - | P3 := imm16. |
| $3C | `ADDP3 #imm` | 2 | 6 | C Z N | P3 := P3 + imm8 (free a stack frame). A!; flags are the low byte's. |
| $3D | `SUBP3 #imm` | 2 | 6 | C Z N | P3 := P3 - imm8 (allocate a stack frame). A!; flags are the low byte's. |
| $90 | `LDW addr,(P1+d)` | 4 | 14 | C Z N | Word at addr := the word at P1 + d (a frame local into a memory word). A! |
| $91 | `LDW addr,(P2+d)` | 4 | 14 | C Z N | Word at addr := the word at P2 + d (a frame local into a memory word). A! |
| $92 | `LDW addr,(P3+d)` | 4 | 14 | C Z N | Word at addr := the word at P3 + d (a frame local into a memory word). A! |
| $94 | `STW (P1+d),addr` | 4 | 14 | C Z N | Word at P1 + d := the word at addr (a memory word into a frame local). A! |
| $95 | `STW (P2+d),addr` | 4 | 14 | C Z N | Word at P2 + d := the word at addr (a memory word into a frame local). A! |
| $96 | `STW (P3+d),addr` | 4 | 14 | C Z N | Word at P3 + d := the word at addr (a memory word into a frame local). A! |
| $98 | `LDW addr,#imm8` | 4 | 8 | - | Word at addr := imm8 zero-extended (4 bytes; the compiler's constant idiom). |
| $99 | `LDW addr,#imm16` | 5 | 9 | - | Word at addr := imm16 (5 bytes). |
| $9A | `ADDW dst,src` | 5 | 15 | C Z N V | Word a := a + b (16-bit, carry chained). C = carry out; N/V from the high byte; Z from the HIGH byte only. A! |
| $9B | `SUBW dst,src` | 5 | 15 | C Z N V | Word a := a - b (16-bit, borrow chained). C=1 means no borrow (unsigned a >= b). Z high byte only. A! |
| $9C | `CMPW dst,src` | 5 | 15 | C Z N V | Flags from a - b (16-bit), memory unchanged: C = unsigned a >= b; BLT/BGE/BLE/BGT give the signed order. Z high byte only. A! |
| $9E | `INCW addr` | 3 | 9 | C Z N | Word at addr := word + 1. A!; flags are the low byte's (C = carry out of it). |
| $9F | `DECW addr` | 3 | 9 | C Z N | Word at addr := word - 1. A!; flags are the low byte's (C=1: no borrow). |
| $A0 | `ADDW addr,#imm8` | 4 | 15 | C Z N V | Word a := a + imm8 (zero-extended), 16-bit; C = carry out; Z of the FULL word. A! |
| $A1 | `SUBW addr,#imm8` | 4 | 15 | C Z N V | Word a := a - imm8; C=1 means no borrow (unsigned a >= imm); Z of the full word. A! |
| $A2 | `CMPW addr,#imm8` | 4 | 15 | C Z N V | Flags from a - imm8 (16-bit), memory unchanged: C = unsigned a >= imm; Z = (a == imm) over the full word; BLT/BGE signed. A! |
| $A4 | `LEAW addr,(P1+d)` | 4 | 14 | C Z N | Word at addr := P1 + d -- the ADDRESS of a frame local (arrays, &x). A! |
| $A5 | `LEAW addr,(P2+d)` | 4 | 14 | C Z N | Word at addr := P2 + d -- the ADDRESS of a frame local (arrays, &x). A! |
| $A6 | `LEAW addr,(P3+d)` | 4 | 14 | C Z N | Word at addr := P3 + d -- the ADDRESS of a frame local (arrays, &x). A! |
| $B1 | `ADDW addr,#imm16` | 5 | 15 | C Z N V | Word a := a + imm16; C = carry out; Z of the full word. A! (5 bytes: `x + &table`.) |
| $B2 | `SUBW addr,#imm16` | 5 | 15 | C Z N V | Word a := a - imm16; C=1 means no borrow; Z of the full word. A! |
| $B3 | `CMPW addr,#imm16` | 5 | 15 | C Z N V | Flags from a - imm16, memory unchanged: C = unsigned a >= imm; Z = (a == imm); BLT/BGE/BLE/BGT signed. A! |
| $B4 | `ANDW dst,src` | 5 | 15 | Z N | Word a := a AND b (16-bit). Z from the high byte only. A! |
| $B5 | `ORW dst,src` | 5 | 15 | Z N | Word a := a OR b (16-bit). Z high byte only. A! |
| $B6 | `XORW dst,src` | 5 | 15 | Z N | Word a := a XOR b (16-bit). Z high byte only. A! |
| $B7 | `ANDW addr,#imm8` | 4 | 15 | Z N | Word a := a AND imm8 -- the high byte is ANDed with 0, i.e. cleared (a mask is a mask). Z of the full word, so `ANDW x,#1 ; JZ` tests a bit of a word. A! |
| $B8 | `ORW addr,#imm8` | 4 | 15 | Z N | Word a := a OR imm8 (high byte kept). Z of the full word. A! |
| $B9 | `XORW addr,#imm8` | 4 | 15 | Z N | Word a := a XOR imm8 (high byte kept). Z of the full word. A! |
| $BA | `ANDW addr,#imm16` | 5 | 15 | Z N | Word a := a AND imm16. Z of the full word. A! |
| $BB | `ORW addr,#imm16` | 5 | 15 | Z N | Word a := a OR imm16. Z of the full word. A! |
| $BC | `XORW addr,#imm16` | 5 | 15 | Z N | Word a := a XOR imm16; #$FFFF is a 16-bit bitwise NOT (the compiler's ~x, and -x with INCW). Z of the full word. A! |

### Control flow

| Op | Mnemonic | Bytes | Cycles | Flags | Description |
|---|---|---|---|---|---|
| $40 | `JMP addr` | 3 | 4 | - | P0 (PC) := addr. |
| $41 | `JSR (P1)` | 1 | 9 | - | Push return address (high byte first) onto P3 stack, then P0 := P1. Target must already be in P1. |
| $42 | `RTS` | 1 | 6 | - | Pop return address from P3 stack into P0. |
| $43 | `JSR addr` | 3 | 10 | - | Push return address, then P0 := addr (absolute call). |
| $48 | `BZ addr` | 3 | 4 | - | Branch to addr if Z=1. |
| $49 | `BNZ addr` | 3 | 4 | - | Branch to addr if Z=0. |
| $4A | `BCP addr` | 3 | 4 | - | Branch if C=1, i.e. the RAW 74181 Cn+4 pin is high. Pin high means NO carry out - see note (2). |
| $4C | `JNC addr` | 3 | 4 | - | Branch to addr if C=0. (JC/JZ/JNZ are aliases of BCP/BZ/BNZ.) |
| $A8 | `JMP rel8` | 2 | 9 | C Z N V | P0 := P0 + rel8 (signed, from the next instruction). 2 bytes; A! flags!; via .relax or JMP.R. An always-taken jump is cheaper as the 3-step absolute JMP (JMP.A), which the compiler emits. |
| $A9 | `BZ rel8` | 2 | 9 | C Z N V | Branch rel8 if Z=1. Taken: A and the flags are clobbered (8 steps); not taken: 2 steps, nothing changes. (JZ.R alias.) |
| $AA | `BNZ rel8` | 2 | 9 | C Z N V | Branch rel8 if Z=0. Taken: A and the flags are clobbered (8 steps); not taken: 2 steps, nothing changes. (JNZ.R alias.) |
| $AB | `BCP rel8` | 2 | 9 | C Z N V | Branch rel8 if C=1. Taken: A and the flags are clobbered (8 steps); not taken: 2 steps, nothing changes. (JC.R alias.) |
| $AC | `JNC rel8` | 2 | 9 | C Z N V | Branch rel8 if C=0. Taken: A and the flags are clobbered (8 steps); not taken: 2 steps, nothing changes. |

### Signed branches (rev C; after CMP — N^V/Z)

| Op | Mnemonic | Bytes | Cycles | Flags | Description |
|---|---|---|---|---|---|
| $44 | `BLT addr` | 3 | 4 | - | Branch if signed A <  B (N^V=1). Use after CMP. |
| $45 | `BGE addr` | 3 | 4 | - | Branch if signed A >= B (N^V=0). Use after CMP. |
| $46 | `BLE addr` | 3 | 4 | - | Branch if signed A <= B ((N^V)\|Z). Use after CMP. |
| $47 | `BGT addr` | 3 | 4 | - | Branch if signed A >  B (not (N^V)\|Z). Use after CMP. |
| $AD | `BLT rel8` | 2 | 9 | C Z N V | Branch rel8 if signed A < B (N^V=1). Use after CMP. Taken: A and the flags are clobbered (8 steps); not taken: 2 steps, nothing changes. |
| $AE | `BGE rel8` | 2 | 9 | C Z N V | Branch rel8 if signed A >= B (N^V=0). Taken: A and the flags are clobbered (8 steps); not taken: 2 steps, nothing changes. |
| $AF | `BLE rel8` | 2 | 9 | C Z N V | Branch rel8 if signed A <= B ((N^V)\|Z). Taken: A and the flags are clobbered (8 steps); not taken: 2 steps, nothing changes. |
| $B0 | `BGT rel8` | 2 | 9 | C Z N V | Branch rel8 if signed A > B. Taken: A and the flags are clobbered (8 steps); not taken: 2 steps, nothing changes. |

## Notes

1. **Shifts & rotates:** SHL/SHR shift in 0 and latch the shifted-out bit into C. ROL/ROR rotate through C (the shifted-in bit is the current C). This makes multi-byte shifts work the conventional way (SHL low byte, then ROL high byte).
2. **C flag (rev B):** CONVENTIONAL active-high carry. After ADD, C=1 means a carry occurred; after SUB/CMP, C=1 means no borrow (A >= B). JC/BCP branch on C=1, JNC on C=0. CLC/SEC clear/set C without disturbing Z/N/V.
3. **Stack:** JSR pushes the return address high byte then low byte, decrementing after each write (empty-descending). RTS increments then reads. Software must initialise P3 (e.g. `LDP3 #$FEFF`) before the first JSR.
4. **V flag:** reads 0 in rev A.
5. **Absolute addressing:** LDA/LDB/STA/JSR accept an absolute address; the hardware forms it in the hidden PT scratch pointer.

## Assembler quick reference (p8xasm.py)

```
label:  MNEMONIC operand        ; comment
operands:   #expr (immediate)  |  (Pn) / (Pn)+  |  expr (16-bit address)
exprs:      $1F  0x1F  31  'c'  symbol   with +/-,  <expr = low byte, >expr = high
directives: .org e   .byte e,...   .word e,...   .ascii "s"   .asciiz "s"
            .fill n[,v]    NAME = expr    .equ NAME, expr
pseudo-op:  LDPn #imm16              ; expands to LPLn #<imm, LPHn #>imm
usage:      python3 p8xasm.py prog.asm -o eeprom.bin [-l prog.lst]
```

## Example: print a string

```
ACIA_D = $FF05
        .org 0
        LDP2 #ACIA_D        ; P2 -> ACIA data register
        LDP1 #msg           ; P1 -> string
        LDB  #0
loop:   LDA  (P1)+          ; fetch byte, advance
        OR                  ; A := A|0 - sets Z on the terminator
        BZ   done
        STA  (P2)           ; transmit
        JMP  loop
done:   HLT
msg:    .asciiz "P8X lives!\r\n" 
```

## Writing a program for P8X/OS

Programs launched by the OS **RUN** command load into the transient program area at **$5900** and run via a **JSR** to their exec address. The program ABI: **return to the shell with RTS** (P3, the stack, is the OS's — leave it balanced); on entry **P2 points at the argument tail** — the command text after the program name, NUL-terminated (so `RUN EDIT FOO.ASM` enters with P2 -> `"FOO.ASM"`); programs that take no arguments ignore P2. Build with `.org $5900` and the host assembler's `--base 0x5900`, or assemble on-target with ASM. A file created on-target carries load/exec 0, which the OS maps to $5900, so it is directly RUNnable. The BIOS jump table at $0100 (console + CF, the FFIND/FCREATE/FDELETE/FCOMMIT file calls, the FOPEN/FGETB and FWOPEN/FPUTB/FCLOSE byte streams, and FRESOLVE/FNORM/FOPENDIR/FNEXT) is the only entry point a program needs — it must not call into OS internals.

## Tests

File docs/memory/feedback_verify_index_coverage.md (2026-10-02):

---
name: feedback-verify-index-coverage
description: Before saying a file "is not in any copy", prove the index covers the disk (count files on disk vs indexed per folder); the YACCS inventory silently skipped every CAMOutputs dir for a day
metadata:
  type: feedback
---

On 2026-09-20 I told Ken the Index Registers 1.1 gerbers were "in none of the 13 copies nor anywhere on this Mac".
They were in `PCB/Production/Index Registers 1.1/CAMOutputs/` all along: my `inventory.py` had `CAMOutputs` in
SKIP_DIRS (2,984 files invisible), so every "none in tree" claim and the whole first fab layout were built on a
hole in the index. Ken caught it by asking "did you look into PCB/Production in the original tree?".

**Why:** an index is only as good as its skip list; negative claims ("not anywhere") are the ones that mislead.
**How to apply:** before any "X does not exist" statement, run `find <dir> -type f | wc -l` against the indexed
count for the same dir; whenever a skip list exists, print it in the report. Keep both index files
(`yaccs-index-2026-09-19.json` = the broken one, `-20` = complete). See [[project-yacc1-kicad]].

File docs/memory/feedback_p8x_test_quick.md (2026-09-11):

---
name: p8x-test-quick
description: user wants a representative fast test subset (`make test-quick`) instead of the ~25-minute full suite for routine changes; full suite only before commits that touch compiler/microcode/assembler/OS and before sync
metadata:
  type: feedback
---

The user asked (2026-09-11) for "a representative set of tests that gives a high
degree of confidence without running such a large suite". Agreed set, added as
`make test-quick` in emulator/Makefile (measured 3 min 10 s vs ~25 for `make test`):
test-isa (ISA + wordops + include), c_test, c_struct, c_bios (self-host
differential), c_libfile (caught the P3-frame buffer bug), c_filters (real
commands piped), asm_selfhost (host = native assembler), c_disasm (C/asm twin;
caught the relative-branch A clobber), c_finder_ret (nested launch; caught the
startup relocation bug), c_glasstty.

**Why:** the slow soak tests (os_bigfile, c_desk's 8 runs, c_textutils,
c_findiff, wm_*) rarely fail alone and cost most of the wall time.

**How to apply:** run `make test-quick` after every change; run the full
`make test` only before committing a change to the compiler, microcode,
assembler or OS, and before a sync. Report the numbers of both. Related:
[[p8x-test-scope]], [[p8x-test-streaming]].

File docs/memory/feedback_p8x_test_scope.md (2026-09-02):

---
name: feedback_p8x_test_scope
description: "P8X — run only the relevant test(s); full `make test` suite only for broad changes or on request"
metadata: 
  node_type: memory
  type: feedback
  originSessionId: df90e3f3-8668-416d-bc7b-83f2952ba723
---

On P8X, be selective about test scope. Run only the test(s) relevant to the change; do NOT default to the full `make test` suite after every edit.

**Why:** the full suite is slow (~10 min, dominated by `asm_selfhost`), and most changes are localized. The user called this out after I reran the complete suite repeatedly during the wildcards-on-filters work.

**How to apply:**
- Single command change (e.g. one `.c` in `os/commands/`) → run just its test (`sh emulator/test/c_<area>_test.sh`), e.g. cat→c_cat, wc/grep→c_filters, sort/uniq/sed→c_textutils, head/tail/more→c_pager, dir→c_dir/c_dirglob.
- Run the **full suite** when the change is broad and could affect everything: the **compiler** (`p8cc.py`/`p8cc.c`/`p8lib.c`), **microcode** (`genucode.py`), **firmware** (`p8xmon.asm`), the **assembler**, or **shared `//#use` libs** every command pulls in (`lib_stdin.c`, etc.) — or when the user asks. (The full reruns during the compiler/ISA-shrink/remap work WERE justified for this reason.)
- Still stream `make test` to a logfile, not through grep — see [[feedback_p8x_test_streaming]].

c_demo_test.sh (b2adee6) closes the demo-fleet gap: all ten C graphics
clients compile via clib.py and are asserted BELOW CSTACKTOP (read from
generators/memmap.py), plus frame-pixel smoke for house/tri/camera/
rotate/page. Any lib_gfx/lib_g3d/lib_g3cam growth now fails loudly
instead of corrupting a client's pool at run time. Part of make
test-gfx.

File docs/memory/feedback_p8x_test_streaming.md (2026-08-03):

---
name: feedback_p8x_test_streaming
description: "Run P8X regression suite with raw streaming output to a logfile, not piped through grep"
metadata: 
  node_type: memory
  type: feedback
  originSessionId: df90e3f3-8668-416d-bc7b-83f2952ba723
---

When running the P8X regression suite (`make test` in `emulator/`), write **raw, unbuffered** output to a logfile so progress streams line-by-line and can be watched live — e.g. `make test > /tmp/reg.log 2>&1` run in the background, then tail/read the log.

**Why:** piping `make test` through `grep` (to count PASS/FAIL) block-buffers the output when stdout isn't a TTY, so nothing appears until the whole run finishes — the user can't see running progress. Writing straight to a file flushes per line (the test scripts echo `NAME TEST: PASS` on completion).

**How to apply:** background the run writing to a logfile; for a status check, read the log and count `TEST: PASS` lines and show the last line. Do the PASS/FAIL tally by grepping the finished log afterward, not in the live pipe. The full suite is ~50 tests; `test-c` (C compiler) is the slowest phase. See [[project_p8x]] and [[feedback_p8x_docs_before_sync]].

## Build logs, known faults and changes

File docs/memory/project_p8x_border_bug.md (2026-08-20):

---
name: p8x-border-bug-open
description: "RESOLVED — p8x border-edge bug was marginal capture on gapless CAS; stream now half-rate; lesson: snow = analogue, sim-exact + panel-wrong = electrical"
metadata: 
  node_type: memory
  type: project
  originSessionId: eb839e7b-2183-47af-84cd-a059555f72b5
  modified: 2026-08-19T17:56:47.213Z
---

RESOLVED 2026-08-19 (commit 985d896): the splash border's missing-left/
doubled-right edges were marginal electrical capture on fully gapless CAS
streams — first burst word lost at bus turn-on, last word mangled at drain,
mid-burst bit flips visible as SNOW in drawn lines. Fixed by half-rate stream
issue (every other cycle) in p8x_sdram.v; verified on the panel; flashed.
Full story in fpga/tang-nano-20k/sdram/HANDOFF.md "RESOLVED" section.

Durable lessons (also in the HANDOFF traps list):
- The chip model cannot see electrical margin: sim-exact + panel-wrong means
  analogue, and temporal noise (snow) is the discriminator — logic bugs are
  deterministic, sparkle is not.
- Pasted images never reach the filesystem; have the user save to ~/Desktop.
- The board's serial-open reset is UNRELIABLE (sometimes fires, sometimes
  not) — never assume a fresh boot from a connect.
- TWO serial clients (user terminal + script) silently shred each other's
  characters — no error either side. ASK if the user's terminal is closed
  before scripting the board. And chars sent while a command RUNS are lost
  (no flow control): scripted waits must exceed the slowest command — a
  256x256 image draw is ~2+ MINUTES. Cheap on-board tests should grab the
  BOOT SPLASH (already on screen) instead of drawing something big first.

Related: [[p8x-project]] [[p8x-fpga-plan]]

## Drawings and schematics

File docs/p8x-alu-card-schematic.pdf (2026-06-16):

P8X ALU CARD REV A (V FLAG UNIMPLEMENTED - SEE BACKLOG) - traditional wiring (auto-drafted)

Bus rails top with taps in column gaps; dot = junction, plain crossing = no connection; rail glyphs = +5V/GND; X = no connect.

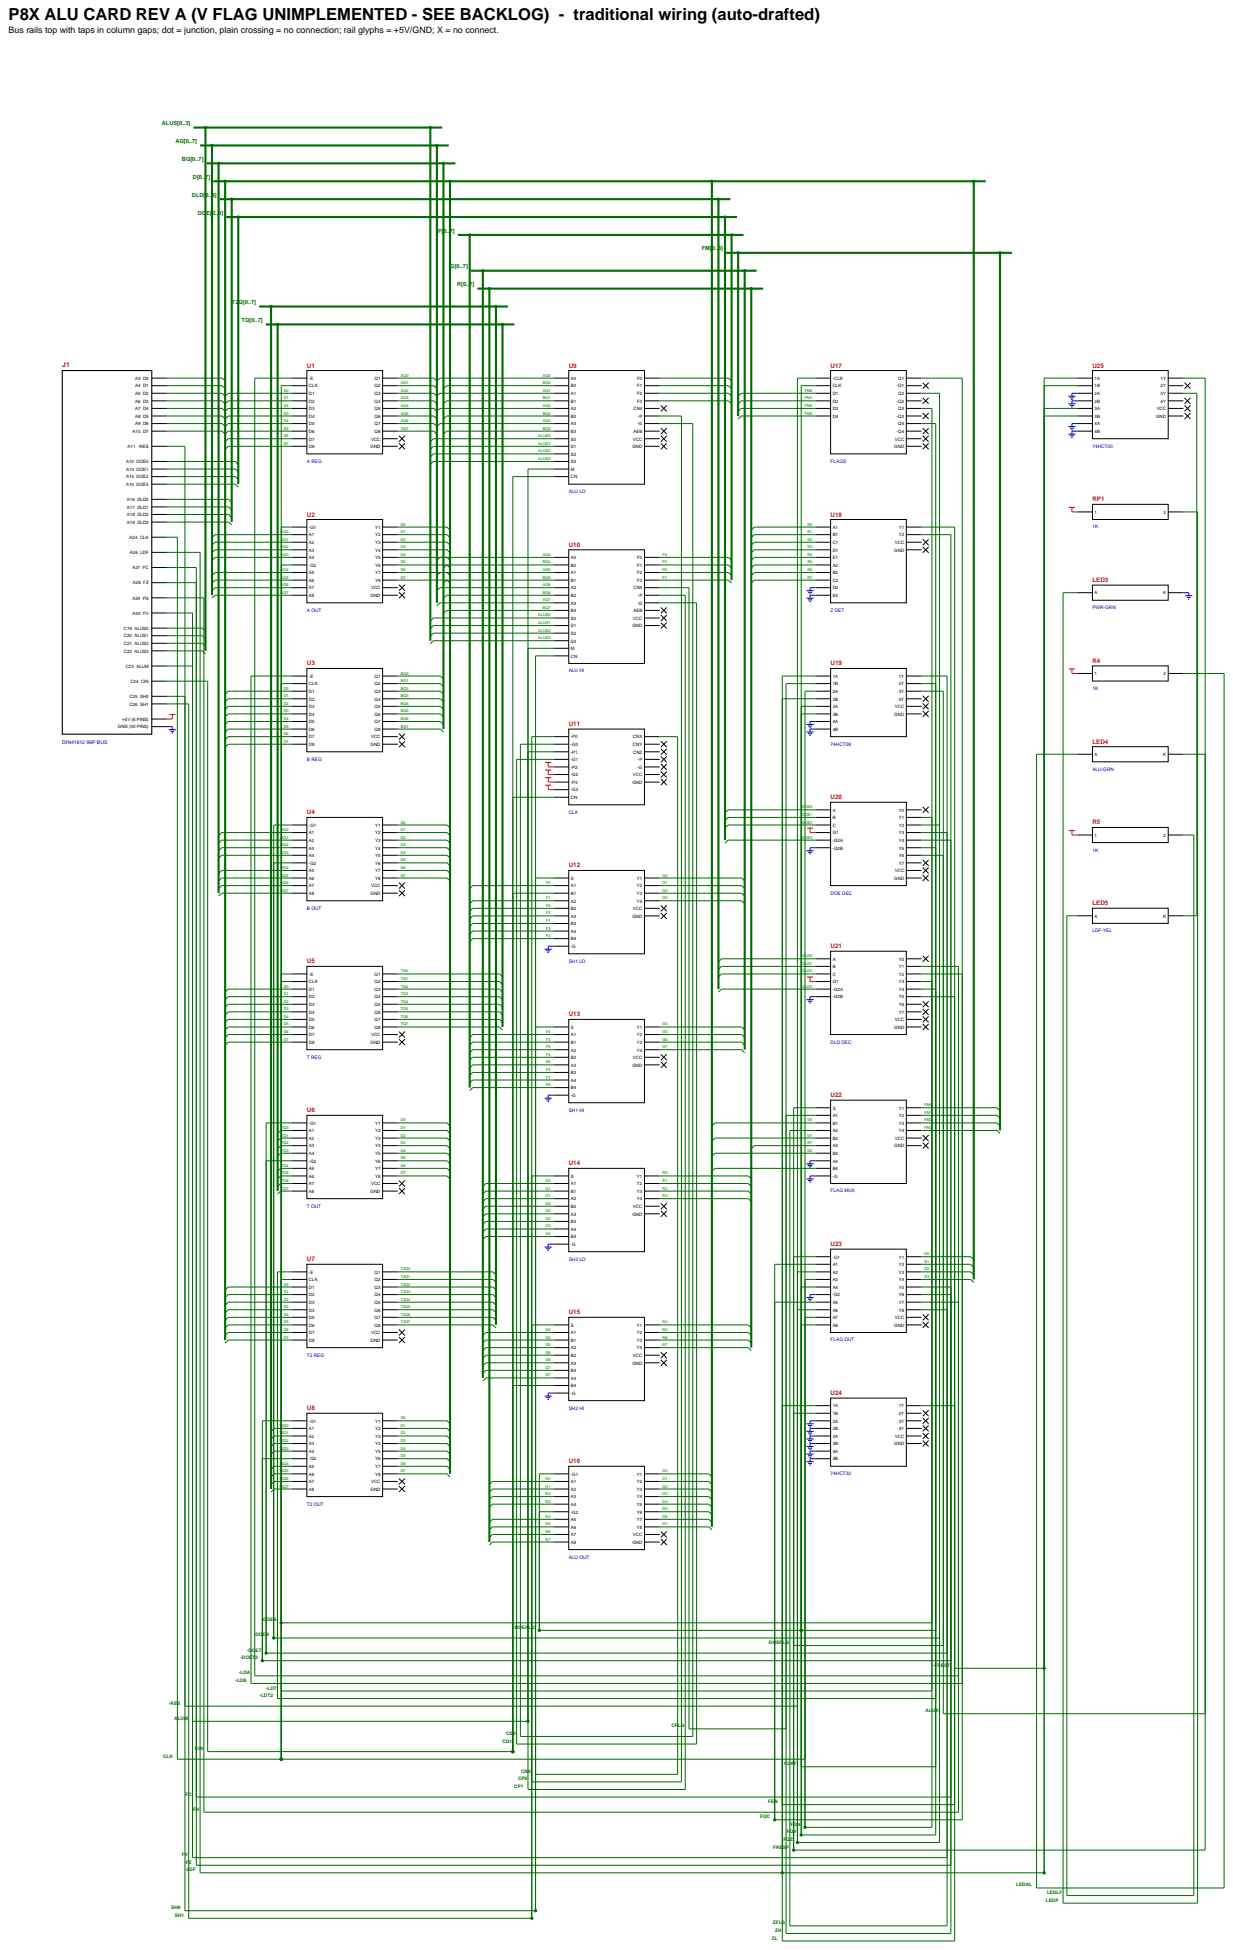
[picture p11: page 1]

-DOEALU

-DOEFLG

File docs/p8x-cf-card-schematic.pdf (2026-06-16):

# P8X CF-IDE CARD REV A - 8-BIT TRUE IDE AT 0xFF10 - traditional wiring (auto-drafted)

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

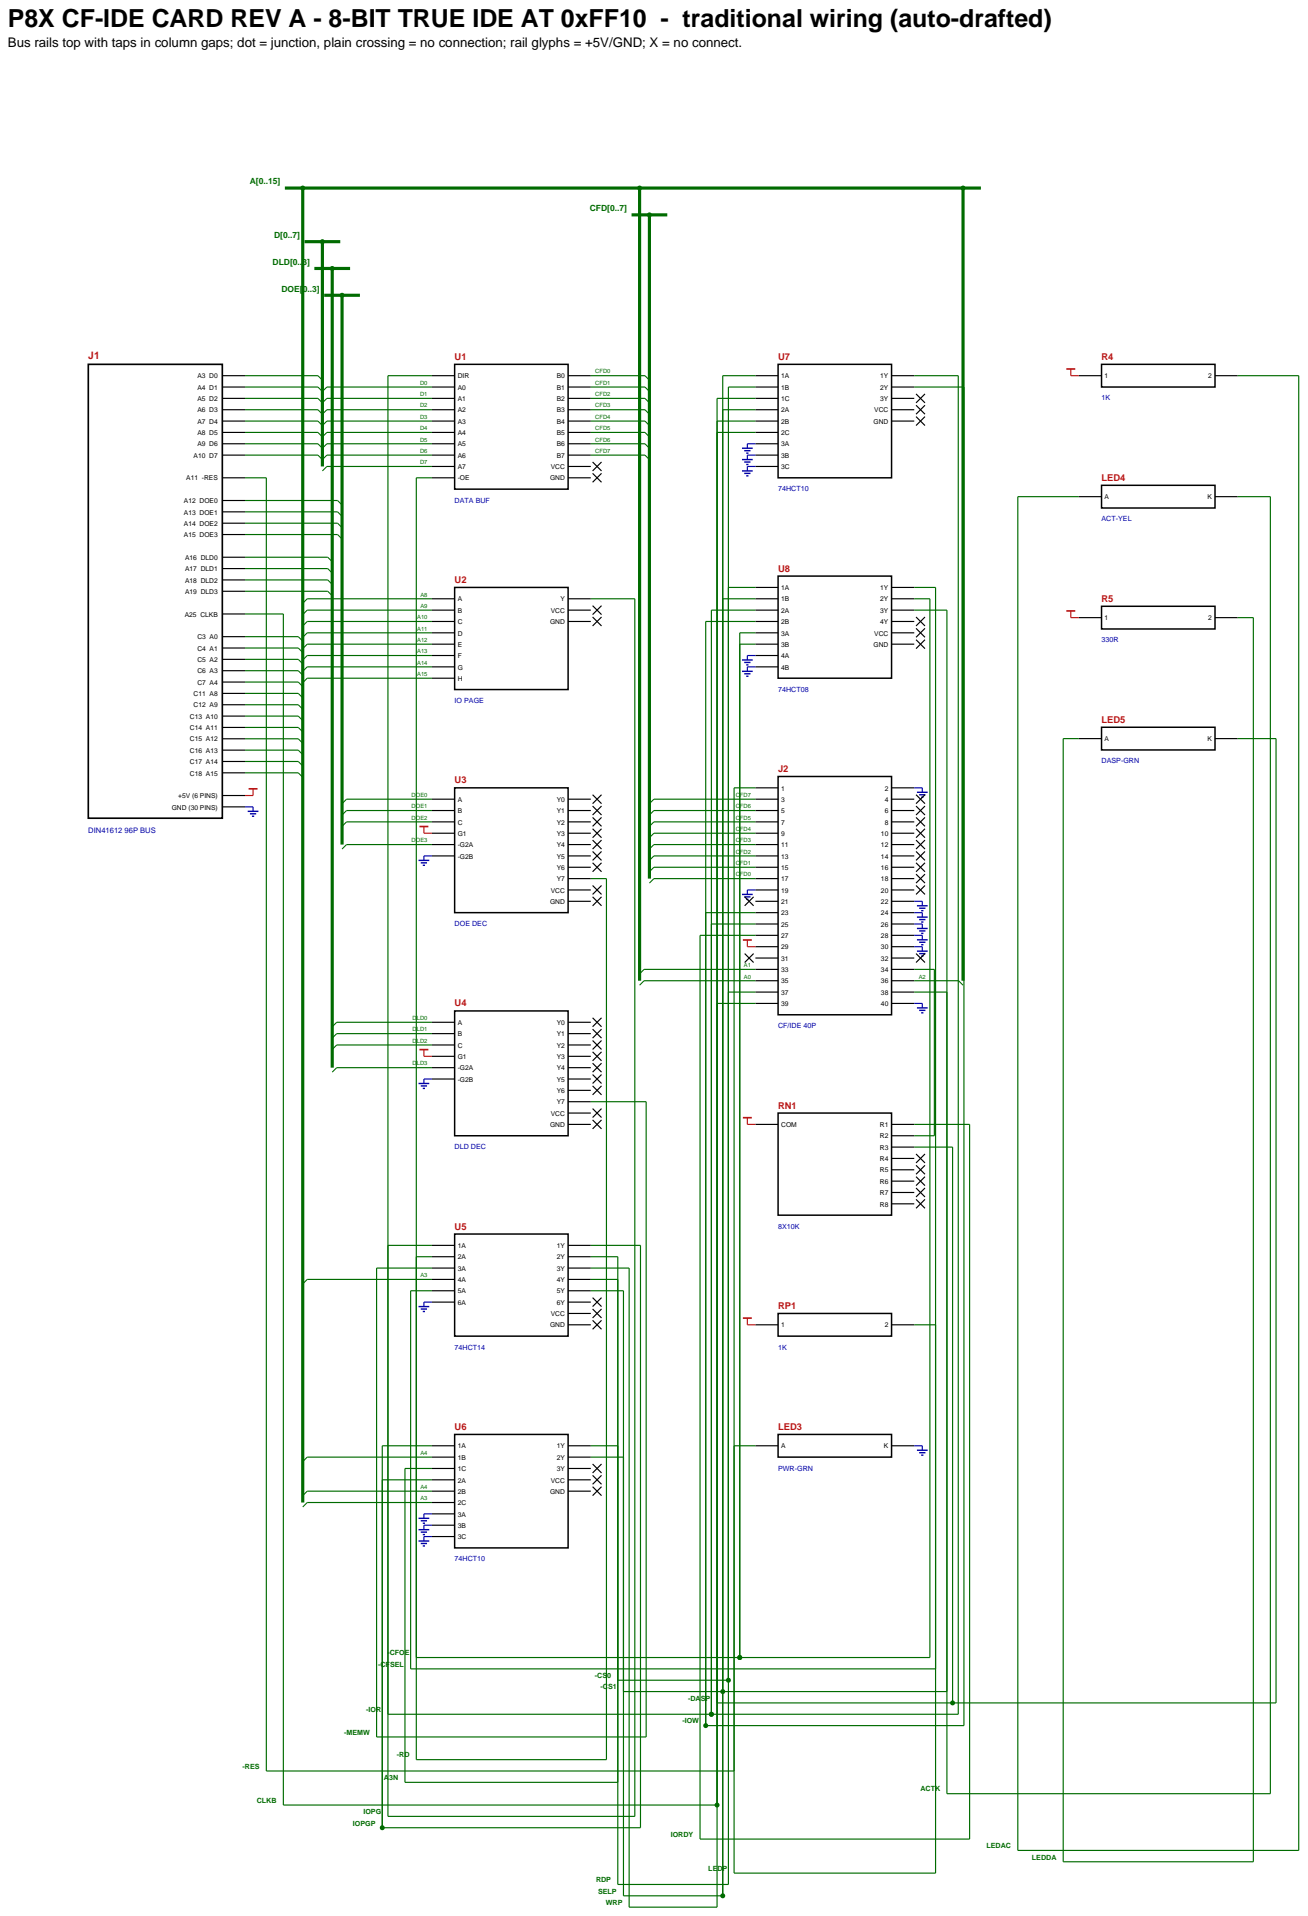
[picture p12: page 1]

-DASP

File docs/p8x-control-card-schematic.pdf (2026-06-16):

# P8X CONTROL/MICROCODE CARD REV A - traditional wiring (auto-drafted)

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

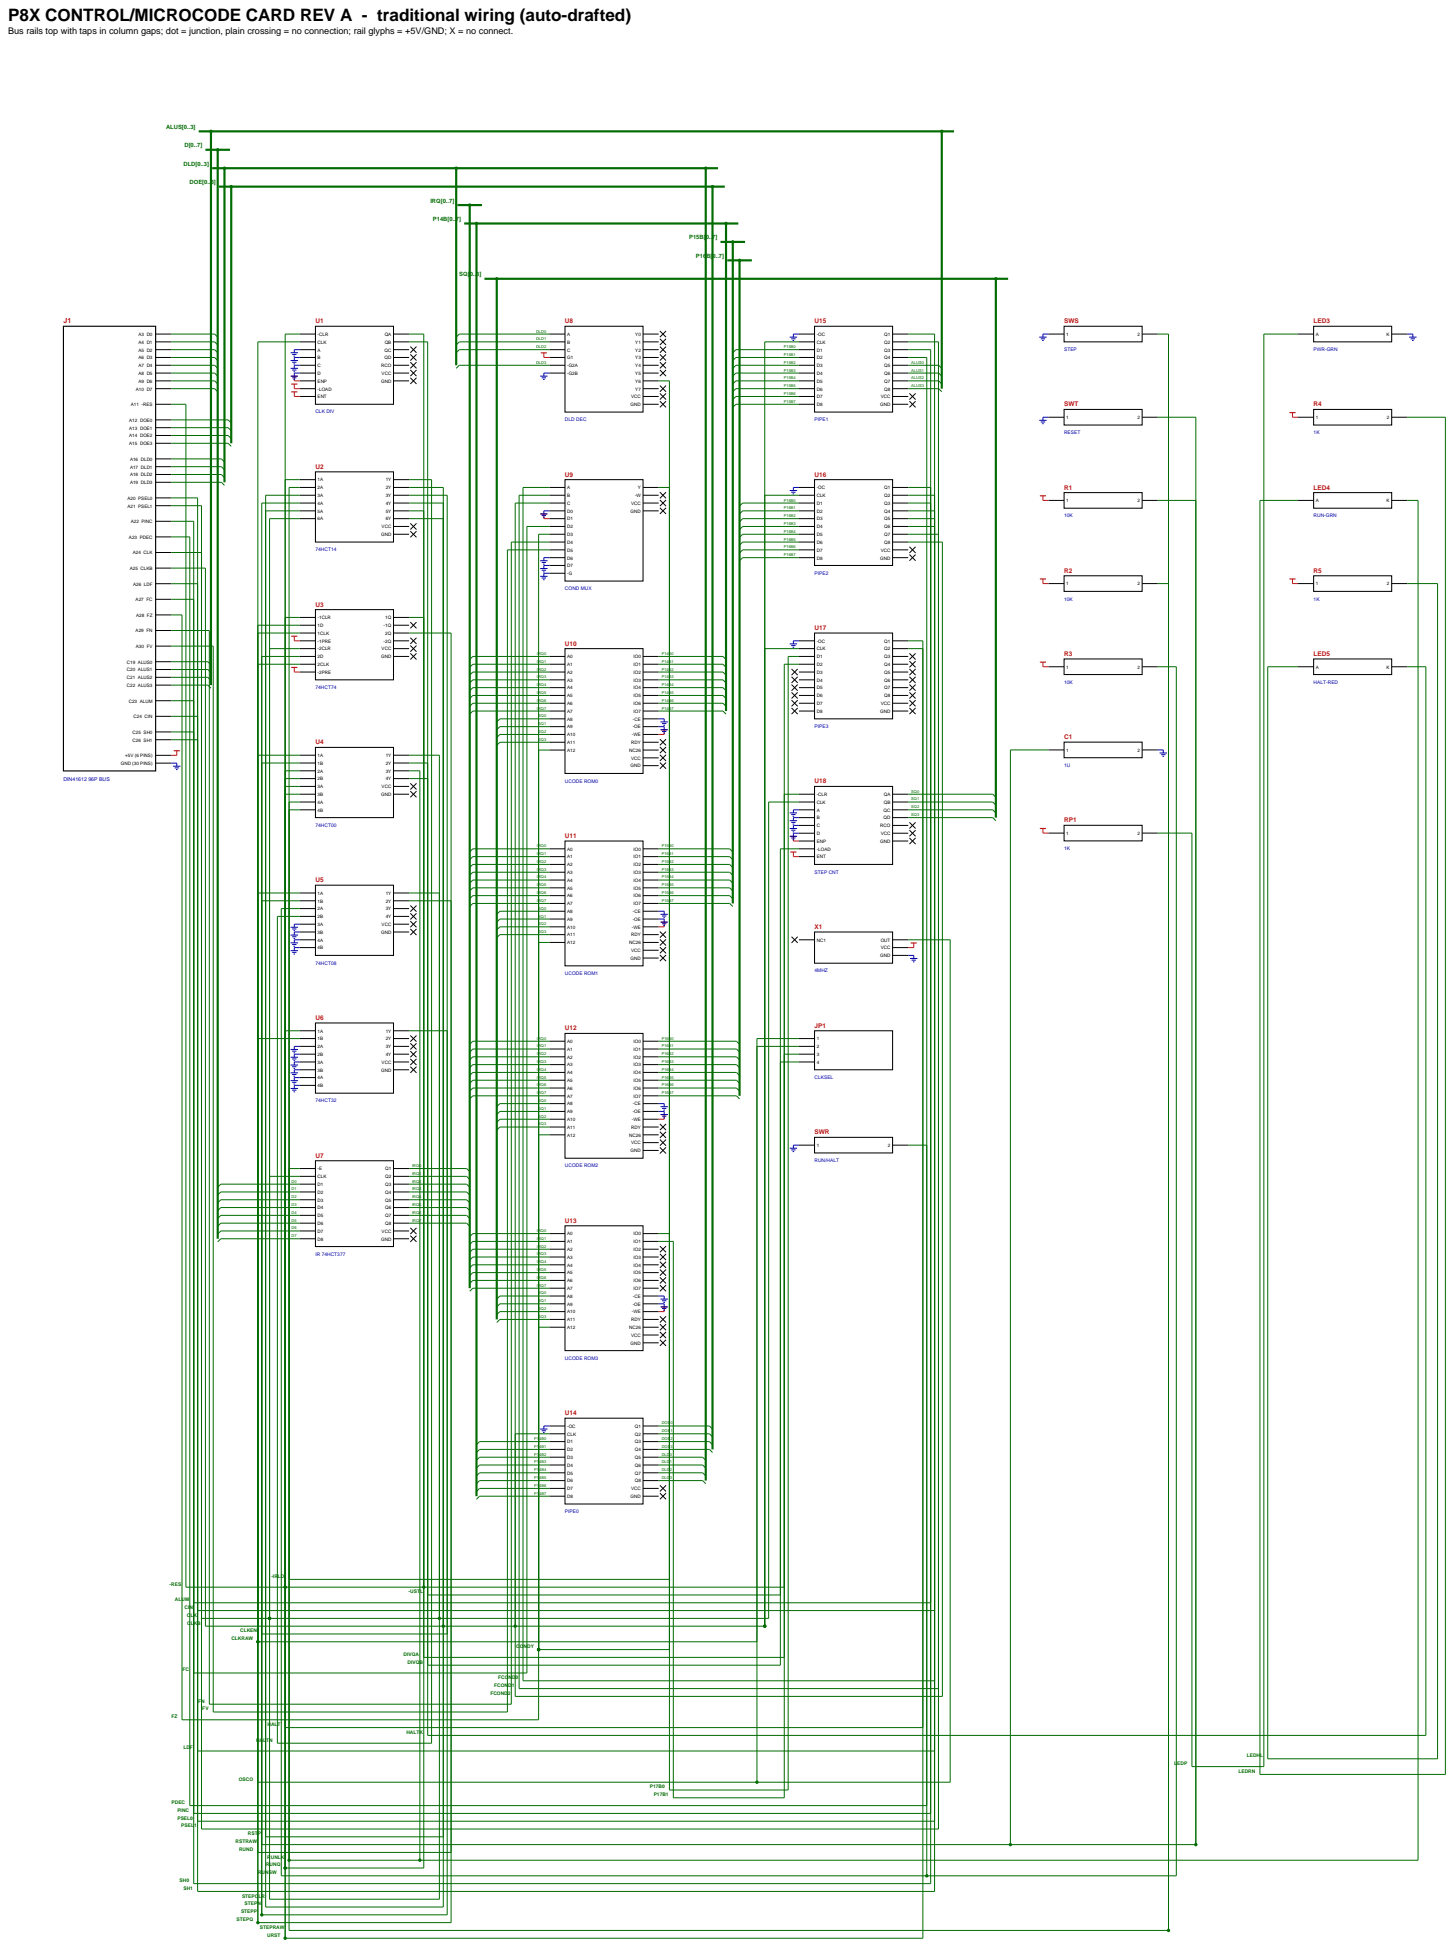
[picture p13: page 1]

CLKEN CLKRAW

FCOND2

HALT

OSCO

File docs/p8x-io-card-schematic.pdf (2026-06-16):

P8X I/O CARD REV A - ACIA + SWITCHES + LEDS + BUS MONITOR - traditional wiring (auto-drafted)

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

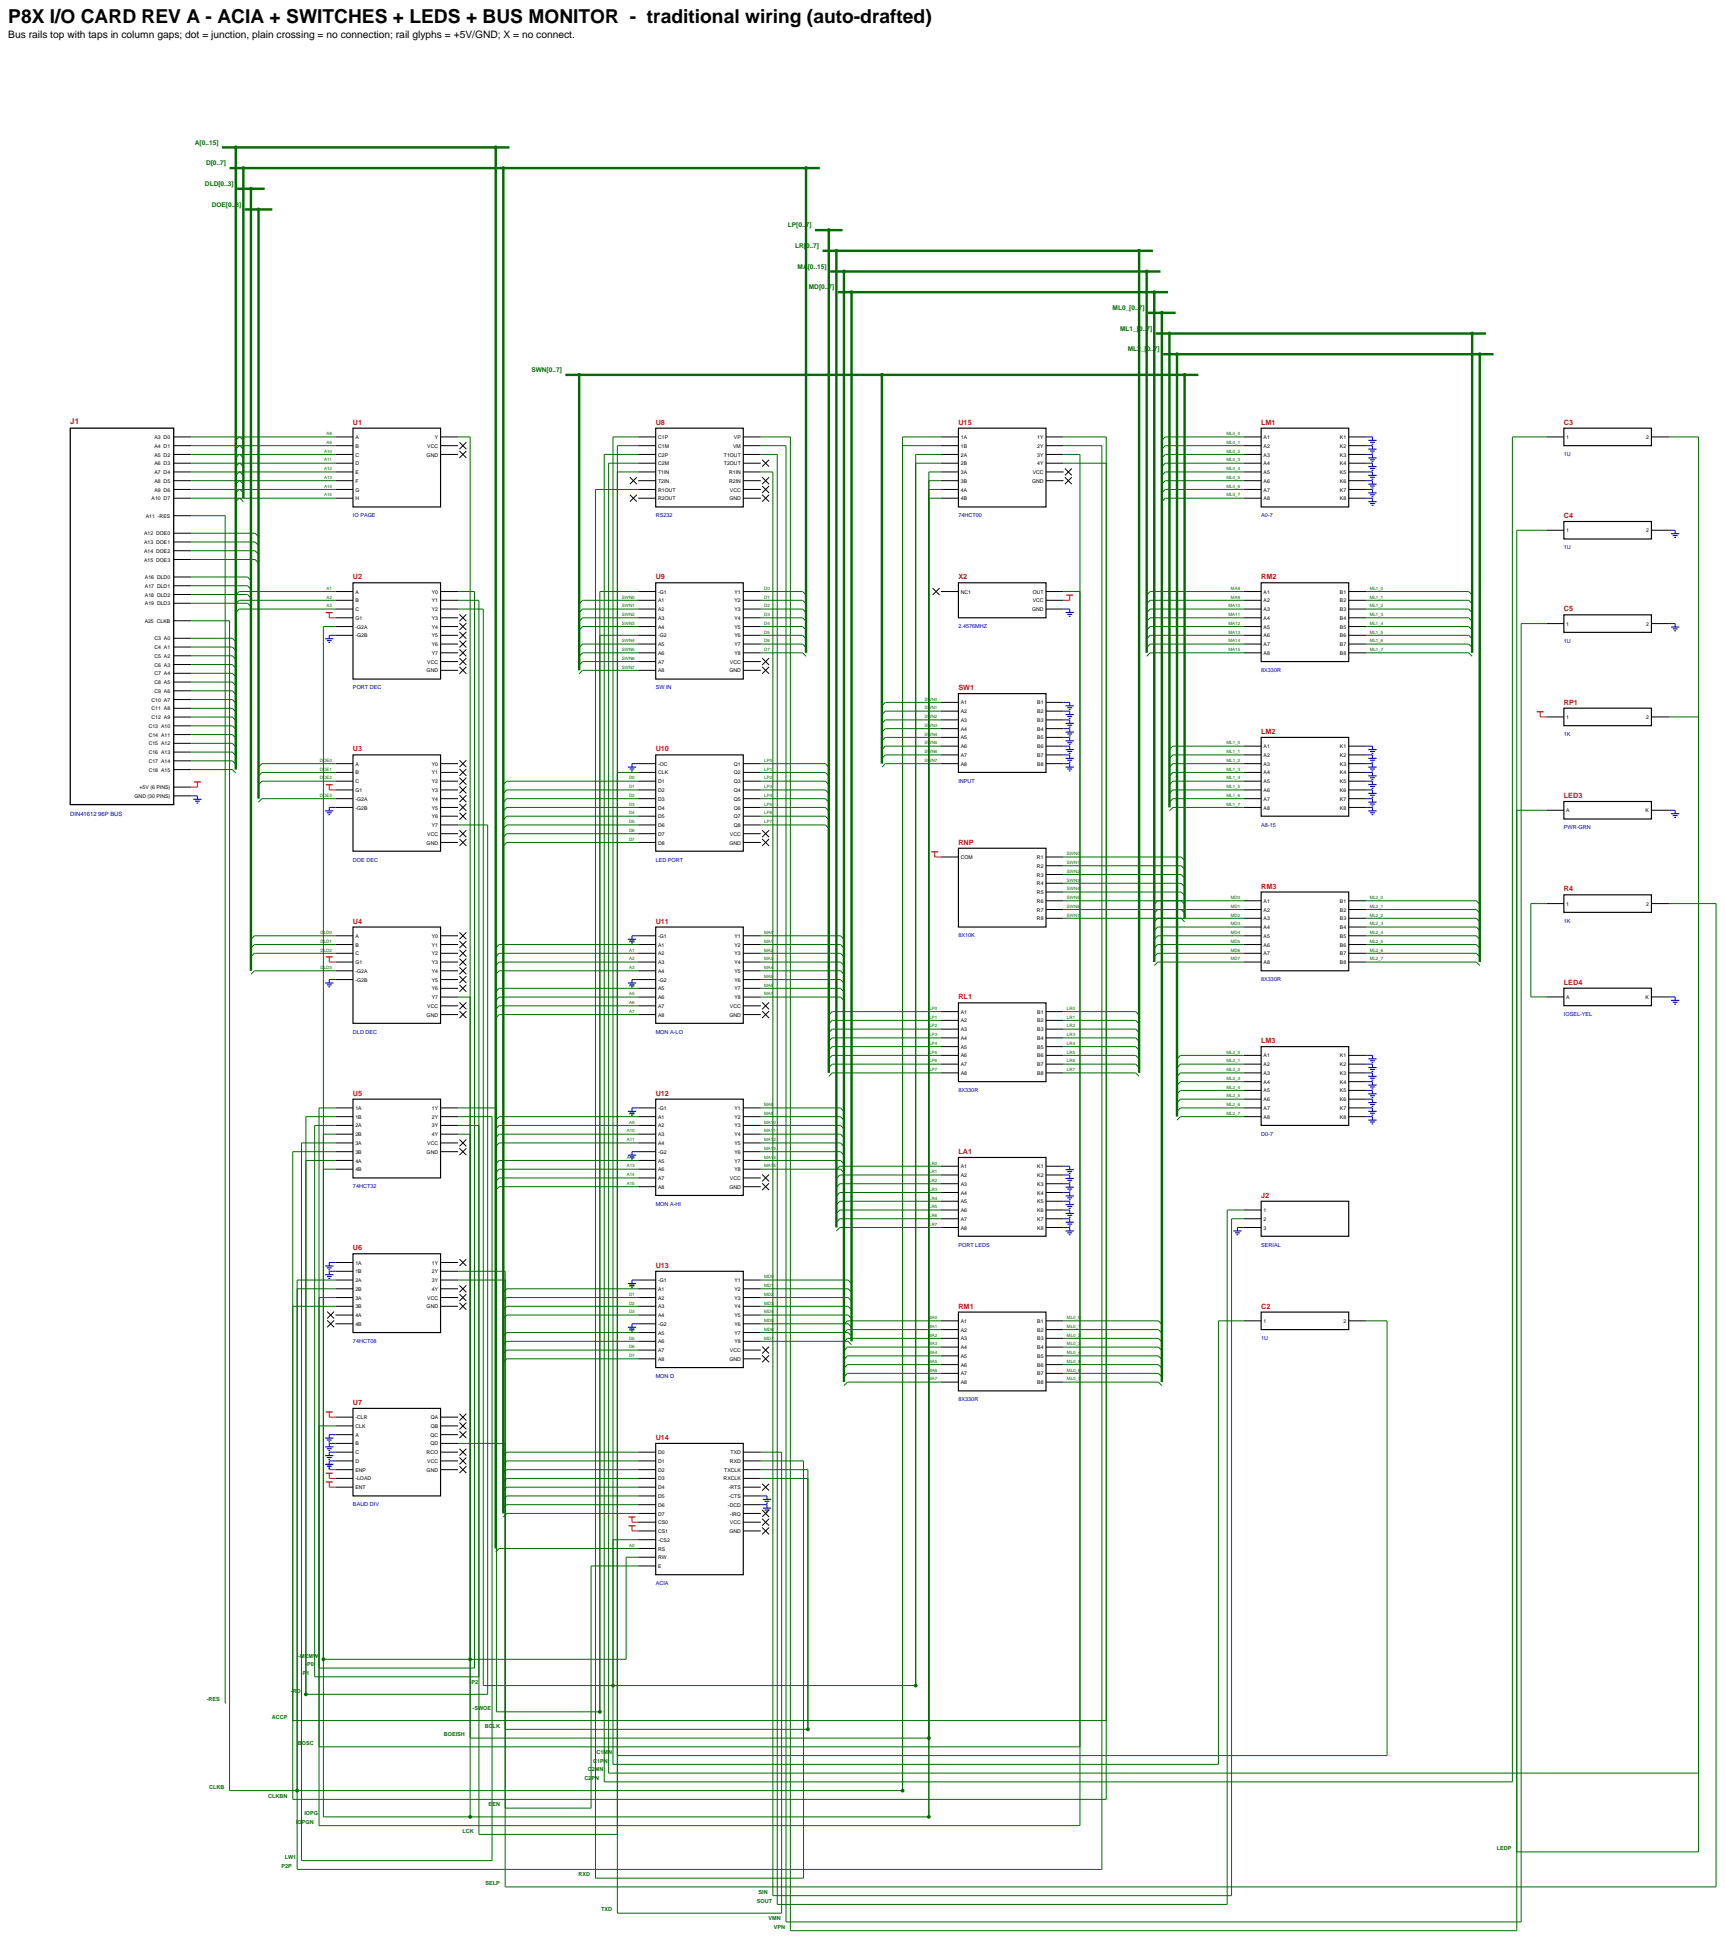
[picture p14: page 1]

-SWOE

BOSC | BOEISH | BCLK

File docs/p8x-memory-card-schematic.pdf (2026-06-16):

# P8X MEMORY CARD REV C - SCHEMATIC (traditional wiring)

Buses drawn as spines with angled entries; junction dot = connection, plain crossing = no connection; rail glyphs = +5V/GND planes.

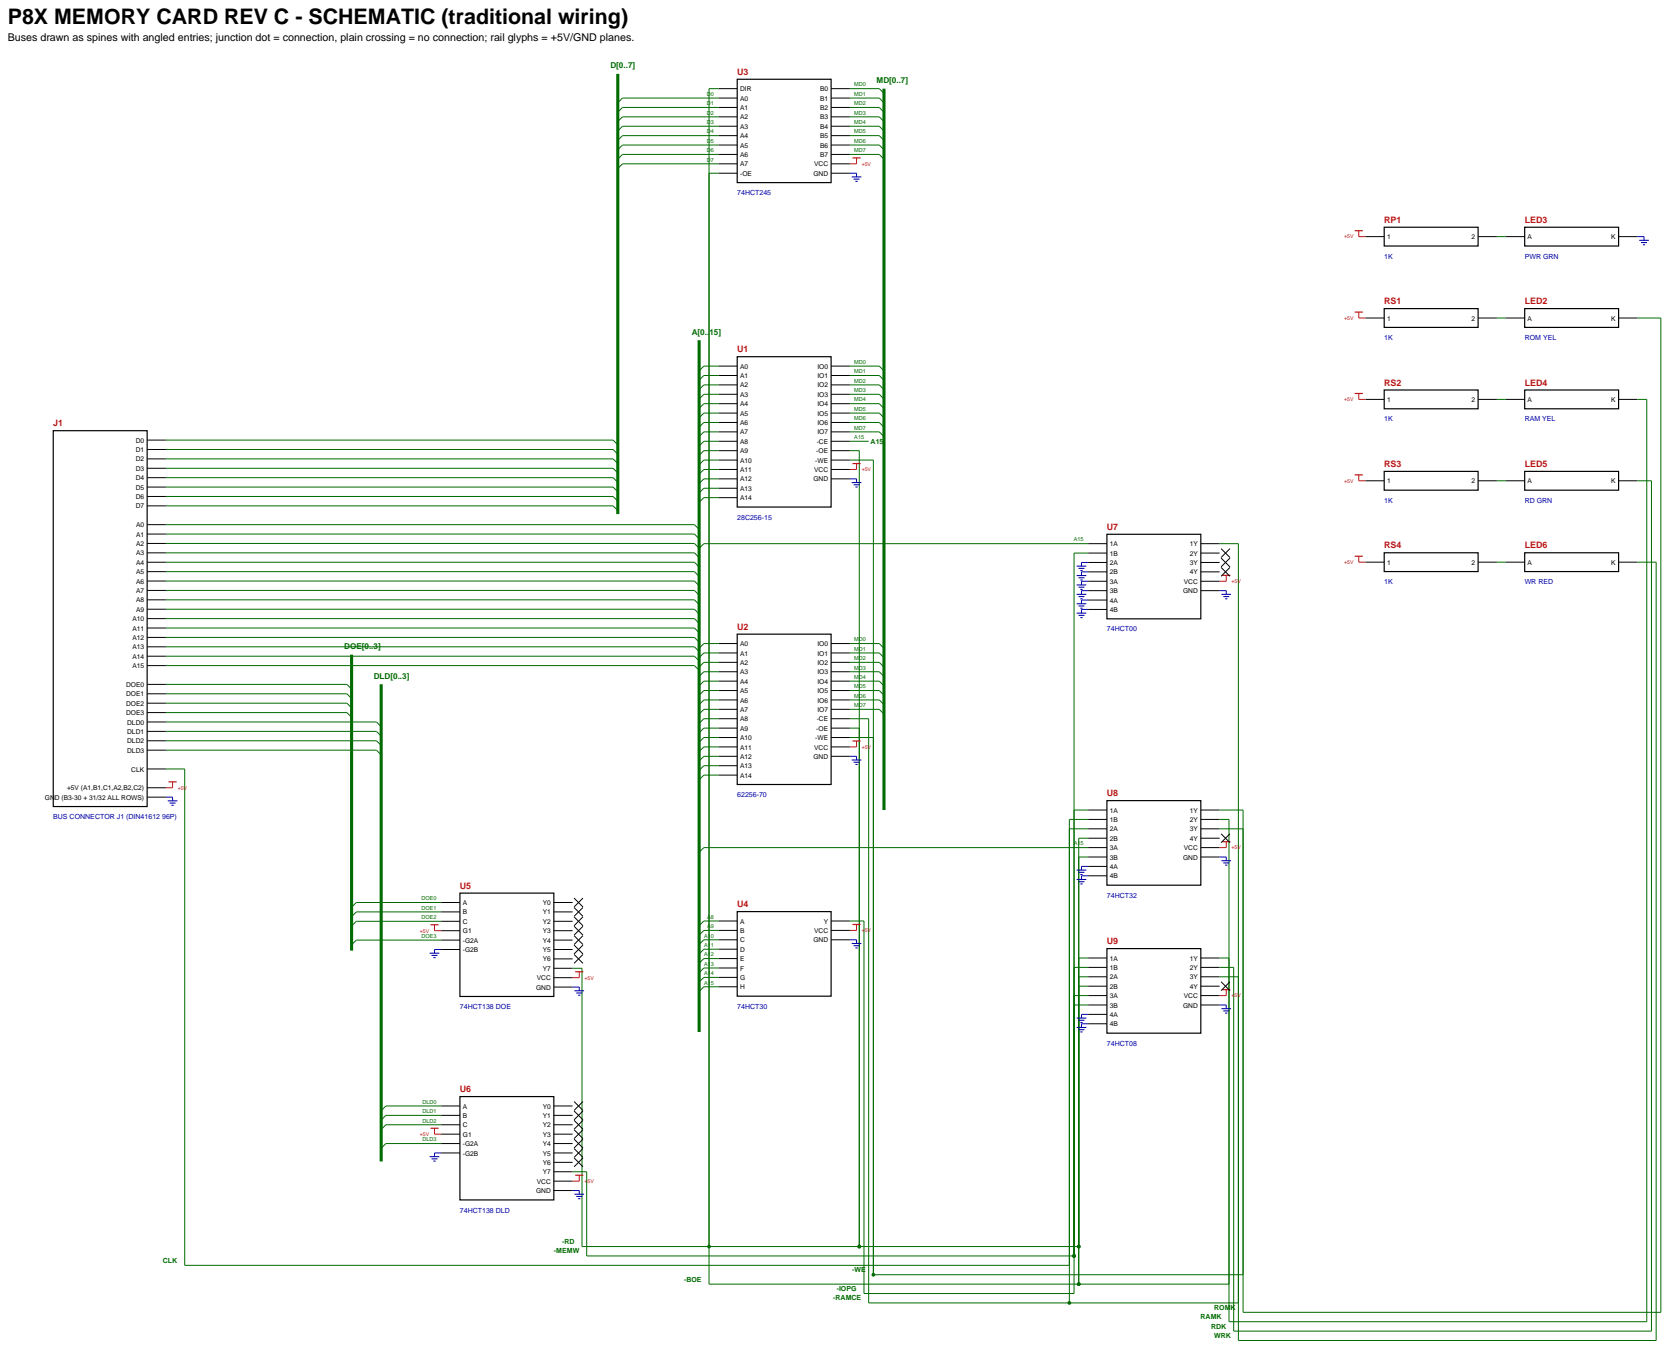
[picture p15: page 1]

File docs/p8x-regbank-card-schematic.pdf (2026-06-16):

# P8X REGISTER BANK CARD REV A (P0=PC P3=SP) - traditional wiring (auto-drafted)

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

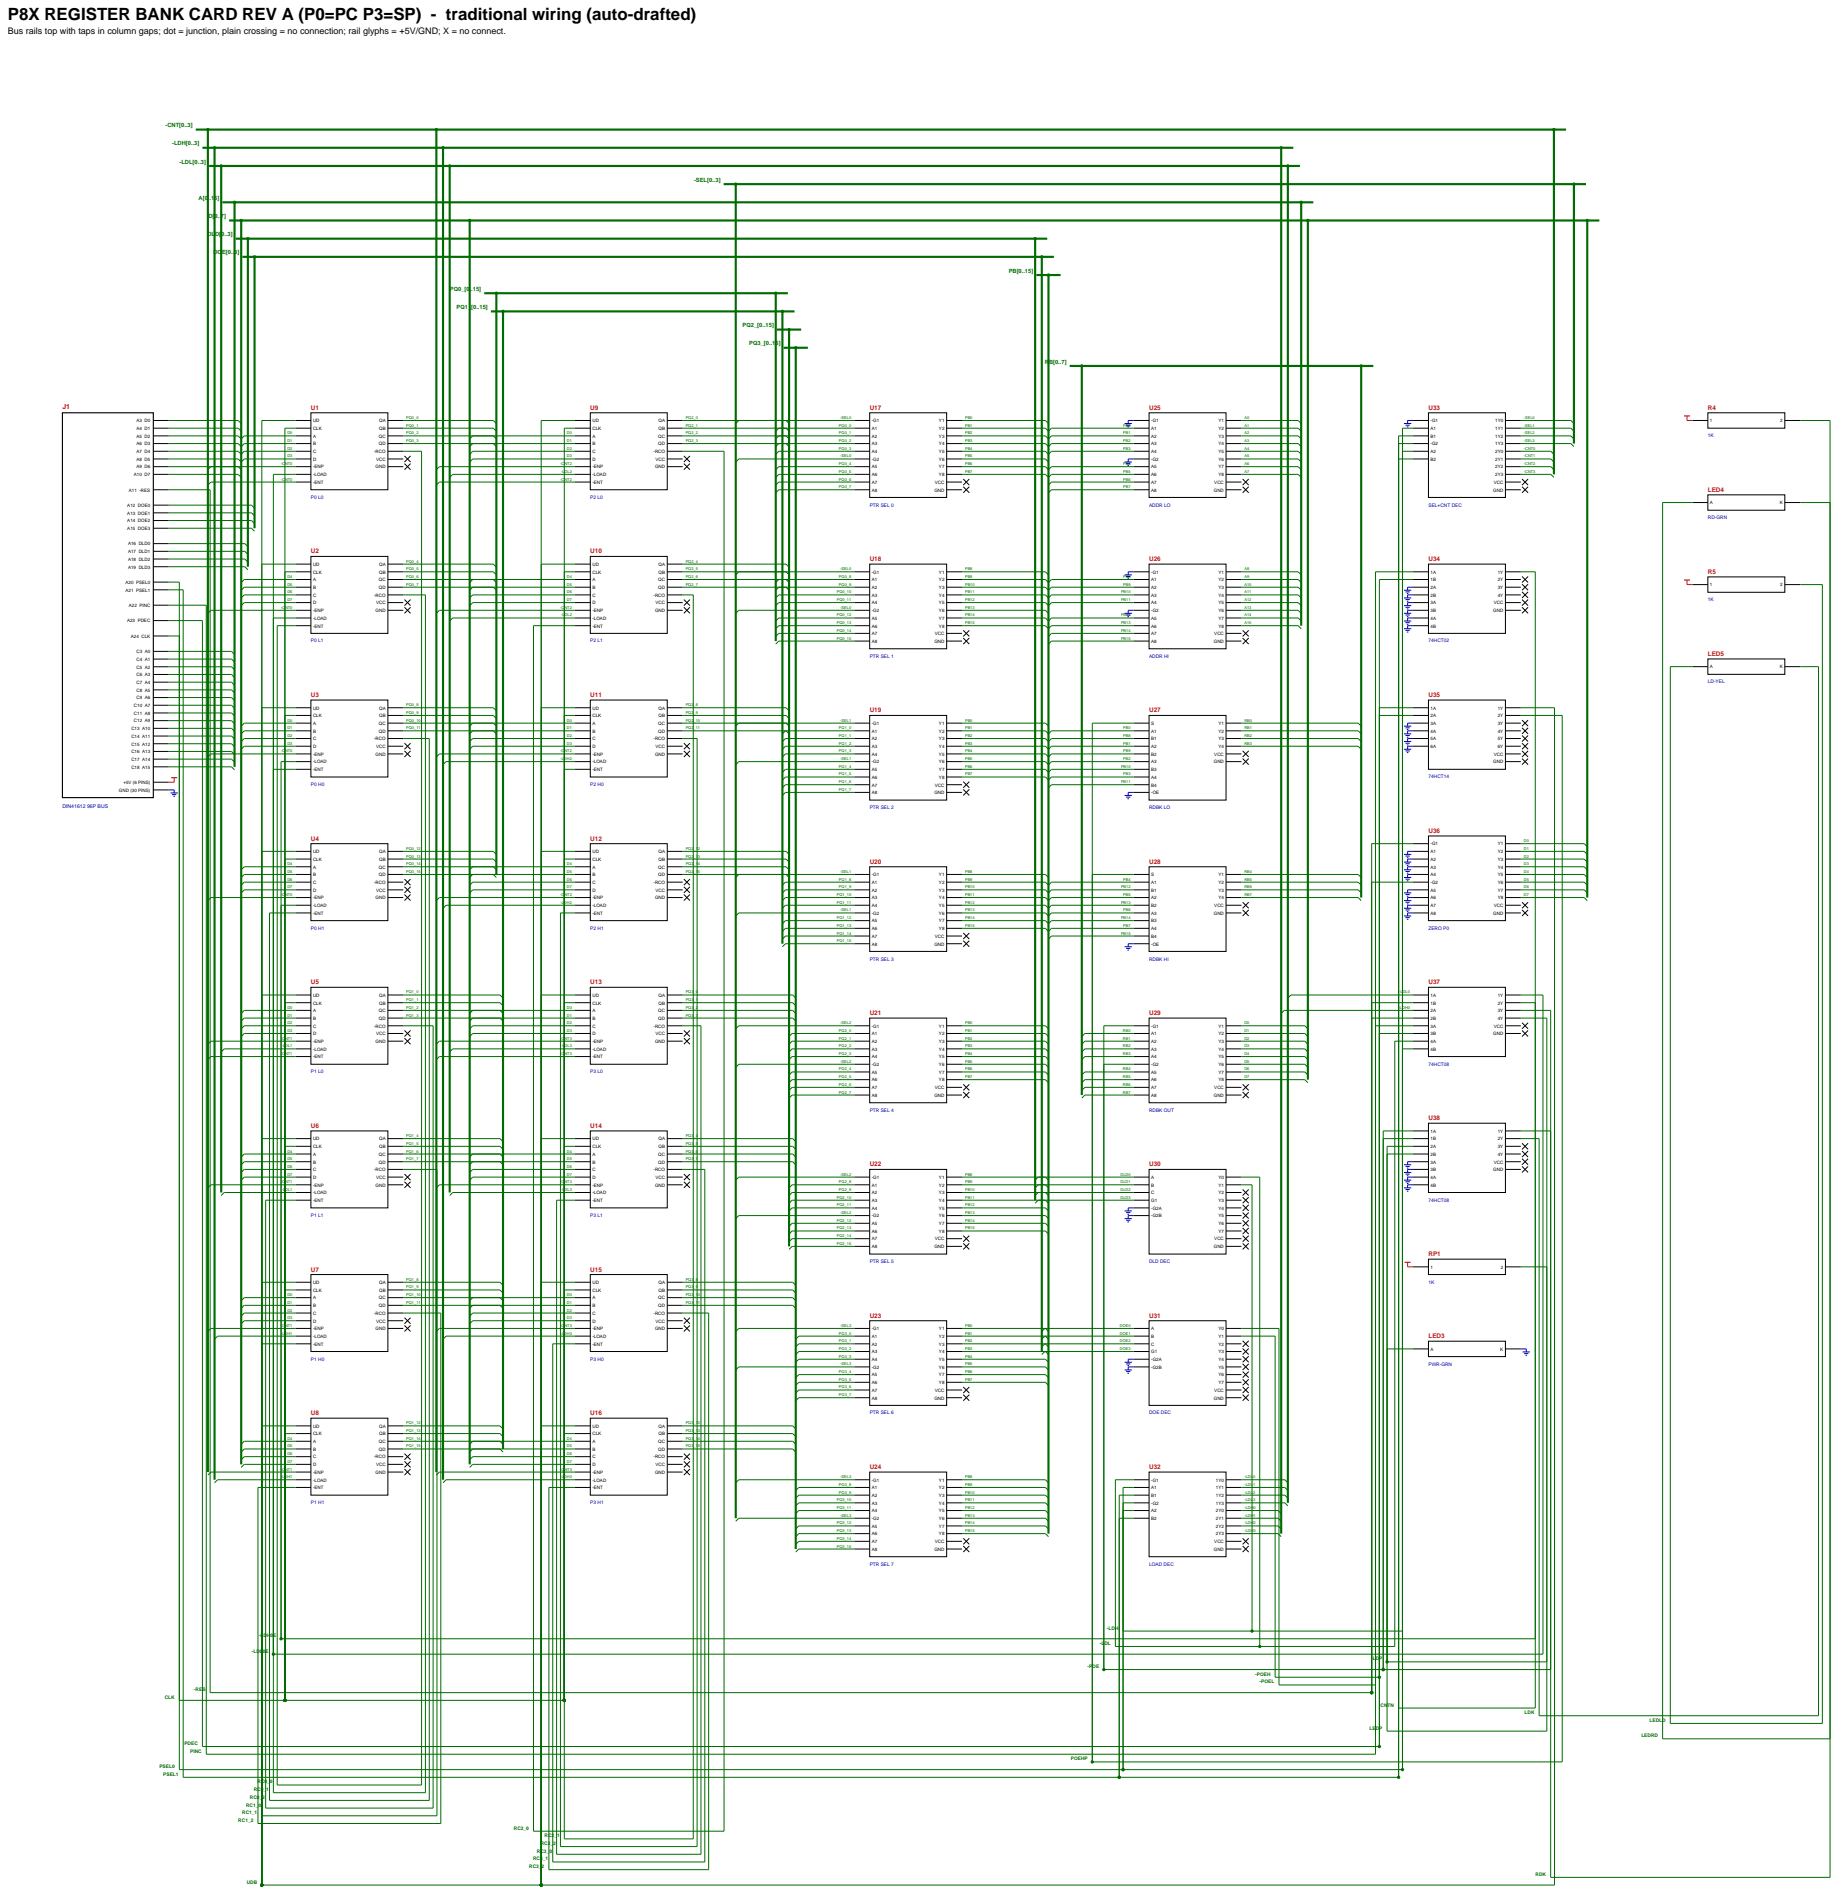
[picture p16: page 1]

-LDP

CNTN

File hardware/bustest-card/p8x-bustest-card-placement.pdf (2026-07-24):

U1 MCP23S17 | C1 | U2 MCP23S17 | C2 | U3 MCP23S17 | C3 | U4 MCP23S17 | C4 | U5 MCP23S17 | C5 | U6 74HCT244 | C6 | U7 74HCT244 | C7

## LED1

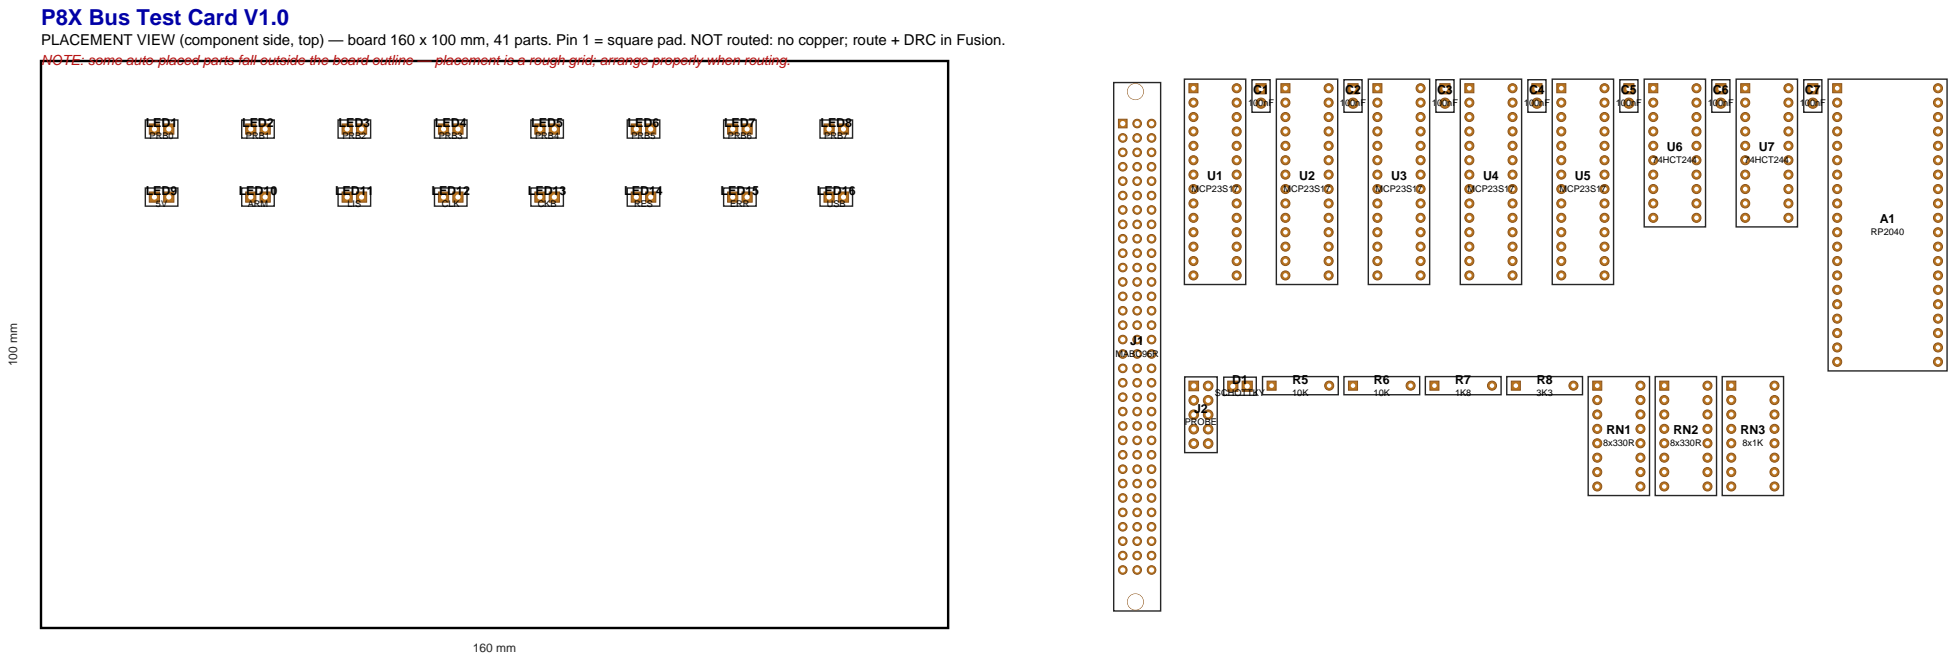
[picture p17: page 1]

P8X Bus Test Card V1.0
PLACEMENT VIEW (component side, top) — board 160 x 100 mm, 41 parts. Pin 1 = square pad. NOT routed: no copper; route + DRC in Fusion.
NOTE: some auto-placed parts fall outside the board outline — placement is a rough grid; arrange properly when routing.

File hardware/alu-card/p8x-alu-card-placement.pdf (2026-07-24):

U1 74HCT377 | C1 | U2 74HCT244 | C2 | U3 74HCT377 | C3 | U4 74HCT244 | C4 | U5 74HCT377 | C5 | U6 74HCT244 | C6 | U7 74HCT377 | C7 | U8 74HCT244 | C8

# P8X ALU CARD REV B (conventional carry, LDZN, SETC/CLRC, carry-coupled shifter)

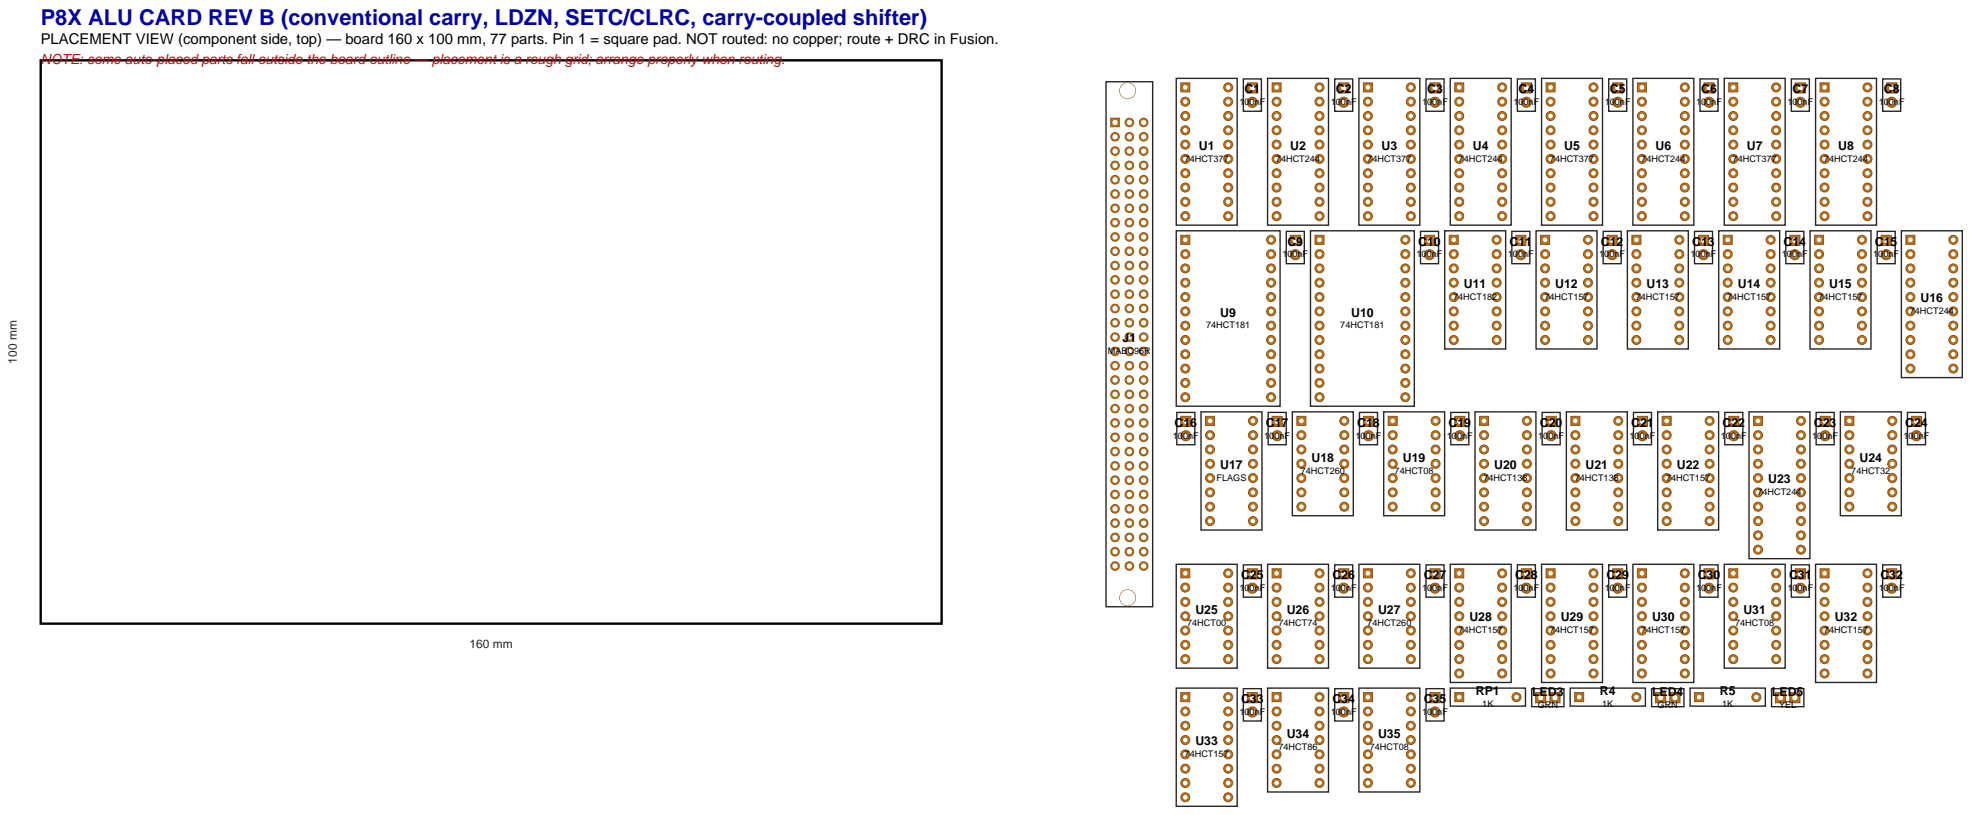
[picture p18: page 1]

PLACEMENT VIEW (component side, top) — board 160 x 100 mm, 77 parts. Pin 1 = square pad. NOT routed: no copper; route + DRC in Fusion.
NOTE: some auto-placed parts fall outside the board outline — placement is a rough grid; arrange properly when routing.

U9 74HCT181 | C9 | U10 74HCT181 | C10 | 74HCT182 | U11 | C11 | 74HCT157 | U12 | C12 | 74HCT157 | U13 | C13 | 74HCT157 | U14 | C14 | 74HCT157 | U15 | C15 | 74HCT244 | U16

U25 74HCT00 | C25 | U26 74HCT74 | C26 | U27 74HCT260 | C27 | U28 74HCT157 | C28 | U29 74HCT157 | C29 | U30 74HCT157 | C30 | U31 74HCT08 | C31 | U32 74HCT157 | C32

U33 74HCT157 | C33 | U34 74HCT86 | C34 | U35 74HCT08 | C35 | 1K | LED3 GRN | 1K | LED4 GRN | 1K | LED5 YEL

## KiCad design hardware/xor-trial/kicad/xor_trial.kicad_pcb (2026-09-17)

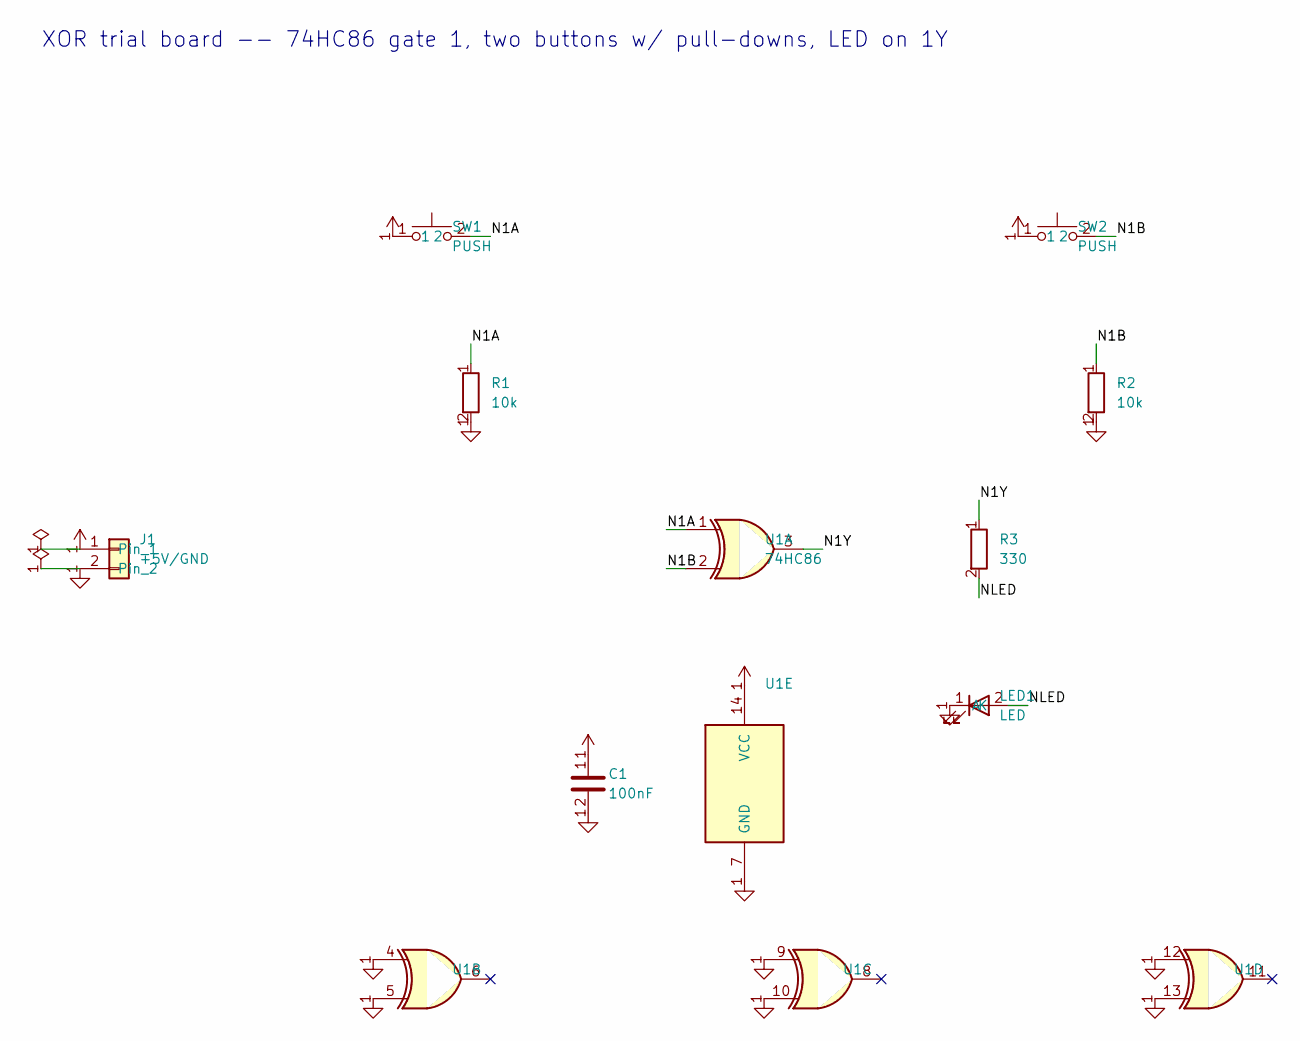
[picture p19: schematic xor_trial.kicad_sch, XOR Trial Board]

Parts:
C1: 100nF
J1: +5V/GND
LED1: LED
R1, R2: 10k
R3: 330
SW1, SW2: PUSH
U1: 74HC86

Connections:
GND: C1.2, J1.2, LED1.1 (K), R1.2, R2.2, U1.4, U1.5, U1.7 (GND), U1.9, U1.10, U1.12, U1.13
N1A: R1.1, SW1.2, U1.1
N1B: R2.1, SW2.2, U1.2
N1Y: R3.1, U1.3
NLED: LED1.2 (A), R3.2
VCC: C1.1, J1.1, SW1.1, SW2.1, U1.14 (VCC)

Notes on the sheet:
XOR trial board -- 74HC86 gate 1, two buttons w/ pull-downs, LED on 1Y

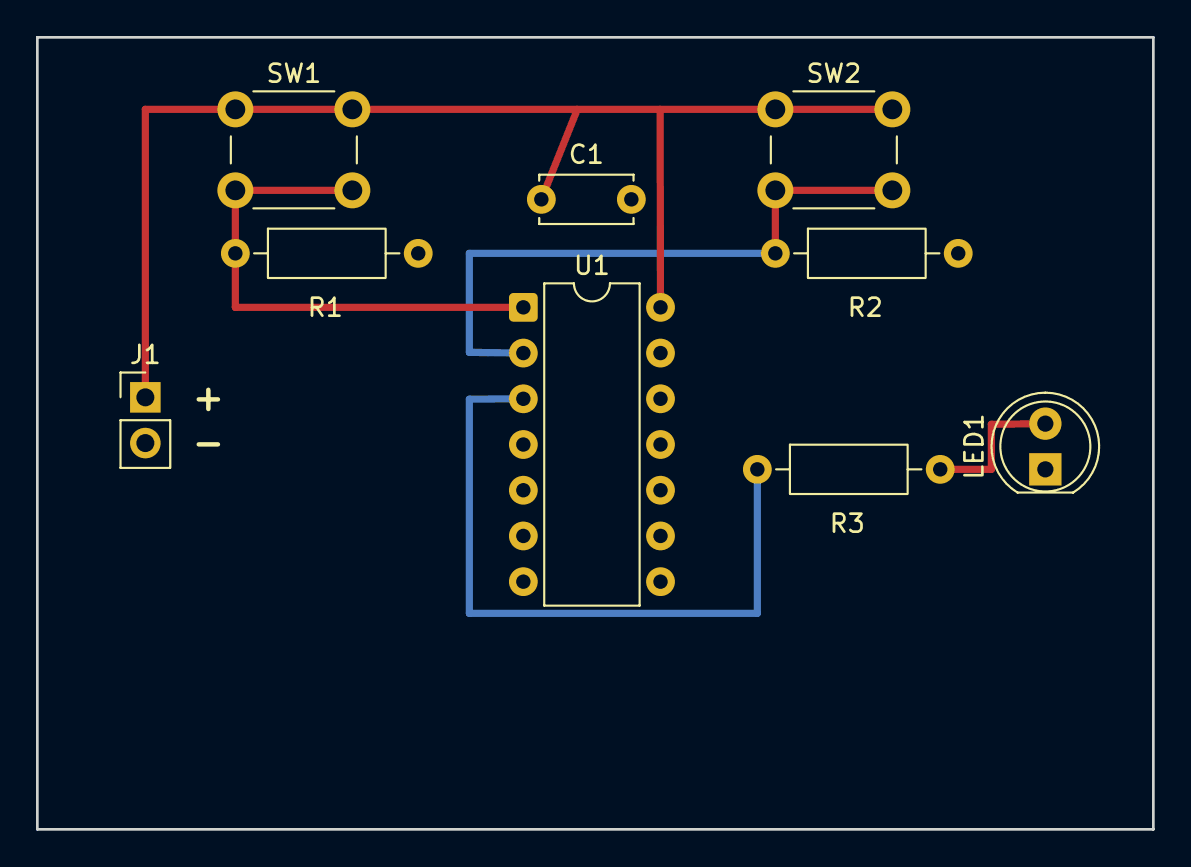
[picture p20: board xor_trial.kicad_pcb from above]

Board: 2 copper layers, 62.0 x 44.0 mm, 9 parts (0 on the bottom side), 6 nets.

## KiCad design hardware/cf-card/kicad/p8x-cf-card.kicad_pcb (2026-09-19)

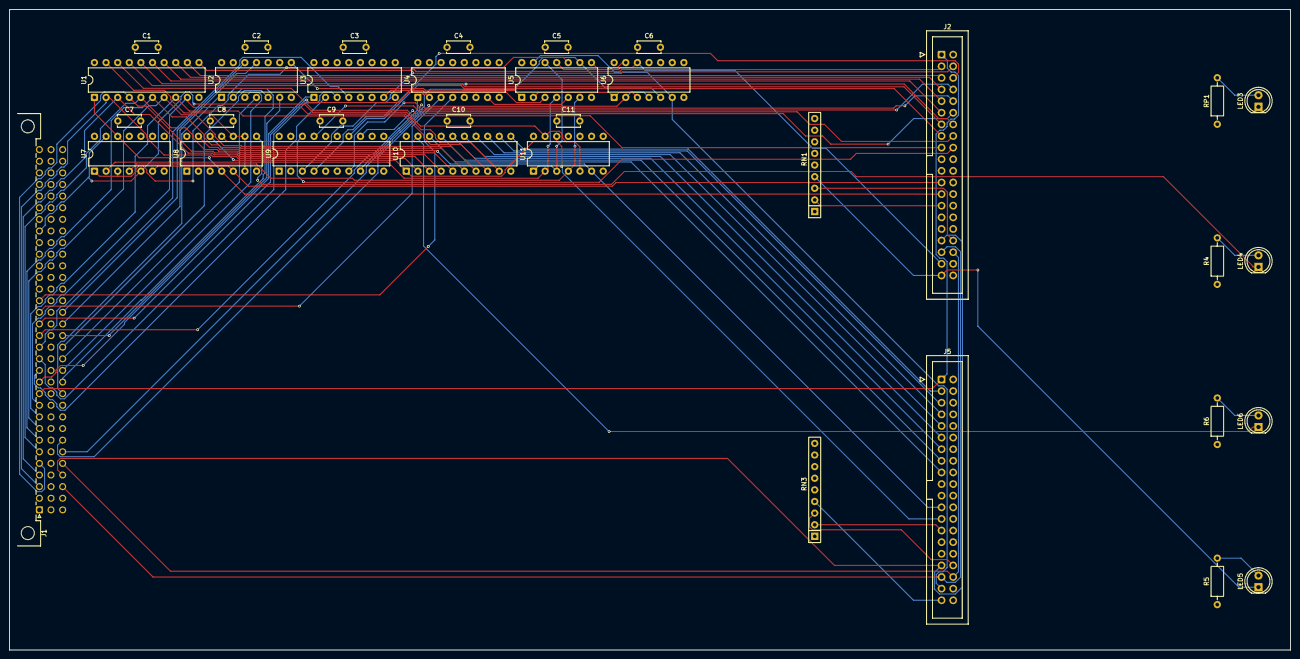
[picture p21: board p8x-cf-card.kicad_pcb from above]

Board: 4 copper layers, 280.0 x 140.0 mm, 35 parts (0 on the bottom side), 85 nets.

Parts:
C1, C2, C3, C4, C5, C6, C7, C8, C9, C10, C11: 100nF; C_Disc_D5.0mm_W2.5mm_P5.00mm
J1: MABC96R; DIN41612_C_3x32_Male_Horizontal_THT
J2: IDE-40 D0; IDC-Header_2x20_P2.54mm_Vertical
J5: IDE-40 D1; IDC-Header_2x20_P2.54mm_Vertical
LED3, LED5: GRN; LED_D5.0mm
LED4, LED6: YEL; LED_D5.0mm
R4, R6: 1K; R_Axial_DIN0207_L6.3mm_D2.5mm_P10.16mm_Horizontal
R5: 330R; R_Axial_DIN0207_L6.3mm_D2.5mm_P10.16mm_Horizontal
RN1, RN3: 8X10K; R_Array_SIP9
RP1: 1K; R_Axial_DIN0207_L6.3mm_D2.5mm_P10.16mm_Horizontal
U1, U10: 74HCT245; DIP-20_W7.62mm
U2: 74HCT30; DIP-14_W7.62mm
U3, U4: 74HCT138; DIP-16_W7.62mm
U5: 74HCT14; DIP-14_W7.62mm
U6, U7, U11: 74HCT10; DIP-14_W7.62mm
U8: 74HCT08; DIP-14_W7.62mm
U9: 74HCT374; DIP-20_W7.62mm

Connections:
-CFOE: U1.19, U8.6, U8.9, U8.10
-CFOE1: LED6.1, U8.11, U10.19
-CS0: J2.37, U5.11, U6.12
-CS1: J5.37, U5.13, U6.6
-DASP: J2.39, LED5.1, RN1.4
-DASP1: J5.39, RN3.4
-IOR: J2.25, U1.1, U7.12, U8.4
-IOR1: J5.25, U8.12, U10.1, U11.12
-IOW: J2.23, U7.6, U8.5
-IOW1: J5.23, U8.13, U11.6
-MEMW: U4.7, U5.5
-PDIAG: J2.34, RN1.3
-PDIAG1: J5.34, RN3.3
-RD: U3.7, U5.3
-RES: J1.a11, J2.1, J5.1
A0: J1.c3, J2.35, J5.35
A1: J1.c4, J2.33, J5.33
A2: J1.c5, J2.36, J5.36
A3: J1.c6, U5.9, U6.5
A3N: U5.8, U6.13
A4: J1.c7, U6.2, U6.4
A8: J1.c11, U2.1
A9: J1.c12, U2.2
A10: J1.c13, U2.3
A11: J1.c14, U2.4
A12: J1.c15, U2.5
A13: J1.c16, U2.6
A14: J1.c17, U2.11
A15: J1.c18, U2.12
ACTK: LED4.1, U8.8
CF1D0: J5.17, U10.18
CF1D1: J5.15, U10.17
CF1D2: J5.13, U10.16
CF1D3: J5.11, U10.15
CF1D4: J5.9, U10.14
CF1D5: J5.7, U10.13
CF1D6: J5.5, U10.12
CF1D7: J5.3, U10.11
CFD0: J2.17, U1.18
CFD1: J2.15, U1.17
CFD2: J2.13, U1.16
CFD3: J2.11, U1.15
CFD4: J2.9, U1.14
CFD5: J2.7, U1.13
CFD6: J2.5, U1.12
CFD7: J2.3, U1.11
CFD8: J2.4, U9.3
CFD9: J2.6, U9.4
CFD10: J2.8, U9.7
CFD11: J2.10, U9.8
CFD12: J2.12, U9.13
CFD13: J2.14, U9.14
CFD14: J2.16, U9.17
CFD15: J2.18, U9.18
CLKB: J1.a25, U7.5, U7.13, U11.5, U11.13
D0: J1.a3, U1.2, U10.2
D1: J1.a4, U1.3, U10.3
D2: J1.a5, U1.4, U10.4
D3: J1.a6, U1.5, U10.5
D4: J1.a7, U1.6, U10.6
D5: J1.a8, U1.7, U10.7
D6: J1.a9, U1.8, U10.8
D7: J1.a10, U1.9, U10.9
DLD0: J1.a16, U4.1
DLD1: J1.a17, U4.2
DLD2: J1.a18, U4.3
DLD3: J1.a19, U4.4
DOE0: J1.a12, U3.1
DOE1: J1.a13, U3.2
DOE2: J1.a14, U3.3
DOE3: J1.a15, U3.4
GND: C1.2, C2.2, C3.2, C4.2, C5.2, C6.2, C7.2, C8.2, C9.2, C10.2, C11.2, J1.a31, J1.a32, J1.b3, J1.b5, J1.b7, J1.b9, J1.b11, J1.b13, J1.b15, J1.b17, J1.b19, J1.b21, J1.b23, J1.b25, J1.b31, J1.b32, J1.c31, J1.c32, J2.2, J2.19, J2.22, J2.24, J2.26, J2.28, J2.30, J2.40, J5.2, J5.19, J5.22, J5.24, J5.26, J5.28, J5.30, J5.40, LED3.1, U1.10, U2.7, U3.5, U3.8, U4.5, U4.8, U5.7, U6.7, U6.9, U6.10, U6.11, U7.7, U7.9, U7.10, U7.11, U8.1, U8.2, U8.7, U9.10, U9.11, U10.10, U11.7, U11.9, U11.10, U11.11
IOPG: U2.8, U5.1
IOPGP: U5.2, U6.1, U6.3
IORDY: J2.27, RN1.2
IORDY1: J5.27, RN3.2
LEDAC: LED4.2, R4.2
LEDAC1: LED6.2, R6.2
LEDDA: LED5.2, R5.2
LEDP: LED3.2, RP1.2
RDP: U5.4, U7.2, U11.2
SELP: U5.10, U7.1, U7.3
SELP1: U5.12, U11.1, U11.3
VCC: C1.1, C2.1, C3.1, C4.1, C5.1, C6.1, C7.1, C8.1, C9.1, C10.1, C11.1, J1.a1, J1.a2, J1.b1, J1.b2, J1.c1, J1.c2, J2.29, J2.38, J5.29, J5.38, R4.1, R5.1, R6.1, RN1.1, RN3.1, RP1.1, U1.20, U2.14, U3.6, U3.16, U4.6, U4.16, U5.14, U6.14, U7.14, U8.14, U9.1, U9.20, U10.20, U11.14
WRP: U5.6, U7.4, U11.4

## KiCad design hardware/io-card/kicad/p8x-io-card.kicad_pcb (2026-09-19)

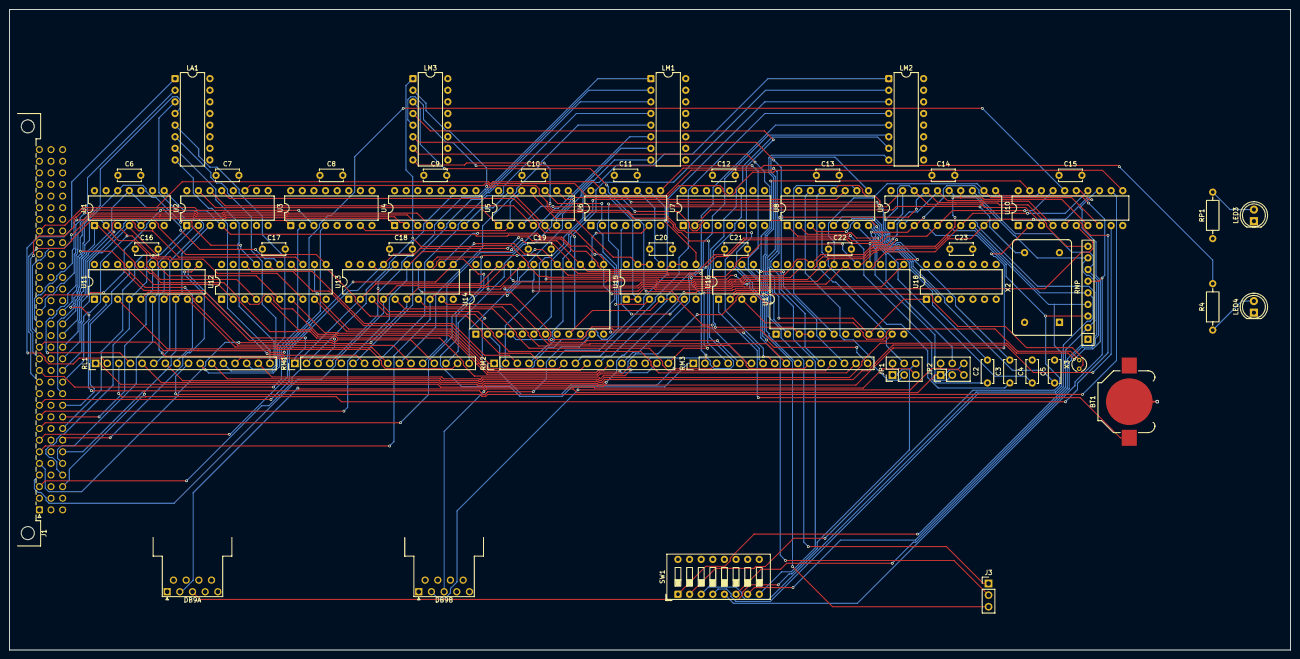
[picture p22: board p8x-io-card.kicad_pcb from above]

Board: 4 copper layers, 280.0 x 140.0 mm, 63 parts (0 on the bottom side), 154 nets.

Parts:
BT1: CR2032; BatteryHolder_Keystone_3000_1x12mm
C2, C3, C4, C5: 1uF; C_Disc_D5.0mm_W2.5mm_P5.00mm
C6, C7, C8, C9, C10, C11, C12, C13, C14, C15, C16, C17, C18, C19, C20, C21, C22, C23: 100nF; C_Disc_D5.0mm_W2.5mm_P5.00mm
DB9A: SERIAL1; DSUB-9_Socket_Horizontal_P2.77x2.54mm_EdgePinOffset9.40mm
DB9B: SERIAL2; DSUB-9_Socket_Horizontal_P2.77x2.54mm_EdgePinOffset9.40mm
J1: MABC96R; DIN41612_C_3x32_Male_Horizontal_THT
J3: 1x3; PinHeader_1x03_P2.54mm_Vertical
JP1: S1 SWAP; PinHeader_2x03_P2.54mm_Vertical
JP2: S2 SWAP; PinHeader_2x03_P2.54mm_Vertical
LA1: 8-LED BAR; DIP-16_W7.62mm
LED3: GRN; LED_D5.0mm
LED4: YEL; LED_D5.0mm
LM1: A0-7; DIP-16_W7.62mm
LM2: A8-15; DIP-16_W7.62mm
LM3: D0-7; DIP-16_W7.62mm
R4: 1K; R_Axial_DIN0207_L6.3mm_D2.5mm_P10.16mm_Horizontal
RL1: 8X330R; PinHeader_1x16_P2.54mm_Vertical
RM1, RM2, RM3: 8X330R; PinHeader_1x16_P2.54mm_Vertical
RNP: 8X10K; R_Array_SIP9
RP1: 1K; R_Axial_DIN0207_L6.3mm_D2.5mm_P10.16mm_Horizontal
SW1: INPUT; SW_DIP_SPSTx08_Slide_9.78x22.5mm_W7.62mm_P2.54mm
U1: 74HCT30; DIP-14_W7.62mm
U2, U3, U4: 74HCT138; DIP-16_W7.62mm
U5: 74HCT32; DIP-14_W7.62mm
U6: 74HCT08; DIP-14_W7.62mm
U7: 74HCT161; DIP-16_W7.62mm
U8: MAX232; DIP-16_W7.62mm
U9, U11, U12, U13: 74HCT244; DIP-20_W7.62mm
U10: 74HCT374; DIP-20_W7.62mm
U14, U17: 6850; DIP-24_W15.24mm
U15: 74HCT00; DIP-14_W7.62mm
U16: DS1302; DIP-8_W7.62mm
U18: 74HCT14; DIP-14_W7.62mm
X2: 2.4576MHZ; Oscillator_DIP-14
X3: 32.768KHZ; Crystal_Round_D3.0mm_Vertical

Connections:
-MEMW: U4.7, U5.5, U5.13, U14.13, U17.13
-P0: U2.15, U5.1
-P1: U2.14, U5.4
-P2: U2.13, U14.9, U15.4, U15.5
-P4: U2.11, U17.9, U18.1
-RD: U3.7, U5.2, U5.12
-SWOE: U5.3, U9.1, U9.19
A0: J1.c3, U11.2, U14.11, U17.11
A1: J1.c4, U2.1, U11.4
A2: J1.c5, U2.2, U11.6
A3: J1.c6, U2.3, U11.8
A4: J1.c7, U11.11
A5: J1.c8, U11.13
A6: J1.c9, U11.15
A7: J1.c10, U11.17
A8: J1.c11, U1.1, U12.2
A9: J1.c12, U1.2, U12.4
A10: J1.c13, U1.3, U12.6
A11: J1.c14, U1.4, U12.8
A12: J1.c15, U1.5, U12.11
A13: J1.c16, U1.6, U12.13
A14: J1.c17, U1.11, U12.15
A15: J1.c18, U1.12, U12.17
ACCP: U6.10, U15.11
BCLK: U7.11, U14.3, U14.4, U17.3, U17.4
BOEISH: U5.11, U15.12, U15.13
BOSC: U7.2, X2.8
C1MN: C2.2, U8.3
C1PN: C2.1, U8.1
C2MN: C3.2, U8.5
C2PN: C3.1, U8.4
CLKB: J1.a25, U6.5, U6.13, U15.1, U15.2
CLKBN: U5.10, U15.3
D0: J1.a3, U9.18, U10.3, U13.2, U14.22, U17.22
D1: J1.a4, U9.16, U10.4, U13.4, U14.21, U17.21
D2: J1.a5, U9.14, U10.7, U13.6, U14.20, U17.20
D3: J1.a6, U9.12, U10.8, U13.8, U14.19, U17.19
D4: J1.a7, U9.9, U10.13, U13.11, U14.18, U17.18
D5: J1.a8, U9.7, U10.14, U13.13, U14.17, U17.17
D6: J1.a9, U9.5, U10.17, U13.15, U14.16, U17.16
D7: J1.a10, U9.3, U10.18, U13.17, U14.15, U17.15
DLD0: J1.a16, U4.1
DLD1: J1.a17, U4.2
DLD2: J1.a18, U4.3
DLD3: J1.a19, U4.4
DOE0: J1.a12, U3.1
DOE1: J1.a13, U3.2
DOE2: J1.a14, U3.3
DOE3: J1.a15, U3.4
E2: U6.11, U17.14
EEN: U6.6, U14.14
GND: BT1.2, C4.2, C5.2, C6.2, C7.2, C8.2, C9.2, C10.2, C11.2, C12.2, C13.2, C14.2, C15.2, C16.2, C17.2, C18.2, C19.2, C20.2, C21.2, C22.2, C23.2, DB9A.5, DB9B.5, J1.a31, J1.a32, J1.b3, J1.b5, J1.b7, J1.b9, J1.b11, J1.b13, J1.b15, J1.b17, J1.b19, J1.b21, J1.b23, J1.b25, J1.b31, J1.b32, J1.c31, J1.c32, LA1.9, LA1.10, LA1.11, LA1.12, LA1.13, LA1.14, LA1.15, LA1.16, LED3.1, LED4.1, LM1.9, LM1.10, LM1.11, LM1.12, LM1.13, LM1.14, LM1.15, LM1.16, LM2.9, LM2.10, LM2.11, LM2.12, LM2.13, LM2.14, LM2.15, LM2.16, LM3.9, LM3.10, LM3.11, LM3.12, LM3.13, LM3.14, LM3.15, LM3.16, SW1.9, SW1.10, SW1.11, SW1.12, SW1.13, SW1.14, SW1.15, SW1.16, U1.7, U2.5, U2.8, U3.5, U3.8, U4.5, U4.8, U5.7, U6.1, U6.2, U6.7, U7.3, U7.4, U7.5, U7.6, U7.8, U8.15, U9.10, U10.1, U10.10, U11.1, U11.10, U11.19, U12.1, U12.10, U12.19, U13.1, U13.10, U13.19, U14.1, U14.23, U14.24, U15.7, U16.4, U17.1, U17.23, U17.24, U18.3, U18.5, U18.7, U18.9, U18.11, U18.13, X2.7
IOPG: U1.8, U2.4, U15.9, U15.10
IOPGN: U6.9, U15.8
LCK: U5.8, U10.11
LED4A: LED4.2, R4.1
LEDP: LED3.2, RP1.2
LP0: RL1.1, U10.2
LP1: RL1.3, U10.5
LP2: RL1.5, U10.6
LP3: RL1.7, U10.9
LP4: RL1.9, U10.12
LP5: RL1.11, U10.15
LP6: RL1.13, U10.16
LP7: RL1.15, U10.19
LR0: LA1.1, RL1.2
LR1: LA1.2, RL1.4
LR2: LA1.3, RL1.6
LR3: LA1.4, RL1.8
LR4: LA1.5, RL1.10
LR5: LA1.6, RL1.12
LR6: LA1.7, RL1.14
LR7: LA1.8, RL1.16
LW1: U5.6, U5.9
MA0: RM1.1, U11.18
MA1: RM1.3, U11.16
MA2: RM1.5, U11.14
MA3: RM1.7, U11.12
MA4: RM1.9, U11.9
MA5: RM1.11, U11.7
MA6: RM1.13, U11.5
MA7: RM1.15, U11.3
MA8: RM2.1, U12.18
MA9: RM2.3, U12.16
MA10: RM2.5, U12.14
MA11: RM2.7, U12.12
MA12: RM2.9, U12.9
MA13: RM2.11, U12.7
MA14: RM2.13, U12.5
MA15: RM2.15, U12.3
MD0: RM3.1, U13.18
MD1: RM3.3, U13.16
MD2: RM3.5, U13.14
MD3: RM3.7, U13.12
MD4: RM3.9, U13.9
MD5: RM3.11, U13.7
MD6: RM3.13, U13.5
MD7: RM3.15, U13.3
ML0_0: LM1.1, RM1.2
ML0_1: LM1.2, RM1.4
ML0_2: LM1.3, RM1.6
ML0_3: LM1.4, RM1.8
ML0_4: LM1.5, RM1.10
ML0_5: LM1.6, RM1.12
ML0_6: LM1.7, RM1.14
ML0_7: LM1.8, RM1.16
ML1_0: LM2.1, RM2.2
ML1_1: LM2.2, RM2.4
ML1_2: LM2.3, RM2.6
ML1_3: LM2.4, RM2.8
ML1_4: LM2.5, RM2.10
ML1_5: LM2.6, RM2.12
ML1_6: LM2.7, RM2.14
ML1_7: LM2.8, RM2.16
ML2_0: LM3.1, RM3.2
ML2_1: LM3.2, RM3.4
ML2_2: LM3.3, RM3.6
ML2_3: LM3.4, RM3.8
ML2_4: LM3.5, RM3.10
ML2_5: LM3.6, RM3.12
ML2_6: LM3.7, RM3.14
ML2_7: LM3.8, RM3.16
P2P: U6.4, U15.6
P4P: U6.12, U18.2
RTCCE: J3.1, U16.5
RTCIO: J3.3, U16.6
RTCSCLK: J3.2, U16.7
RTCX1: U16.2, X3.1
RTCX2: U16.3, X3.2
RXD: U8.12, U14.2
RXD2: U8.9, U17.2
S1RXD: DB9A.2, JP1.2, JP1.5
S1TXD: DB9A.3, JP1.1, JP1.6
S2RXD: DB9B.2, JP2.2, JP2.5
S2TXD: DB9B.3, JP2.1, JP2.6
SELP: R4.2, U6.8
SIN: JP1.4, U8.13
SIN2: JP2.4, U8.8
SOUT: JP1.3, U8.14
SOUT2: JP2.3, U8.7
SWN0: RNP.2, SW1.1, U9.2
SWN1: RNP.3, SW1.2, U9.4
SWN2: RNP.4, SW1.3, U9.6
SWN3: RNP.5, SW1.4, U9.8
SWN4: RNP.6, SW1.5, U9.11
SWN5: RNP.7, SW1.6, U9.13
SWN6: RNP.8, SW1.7, U9.15
SWN7: RNP.9, SW1.8, U9.17
TXD: U8.11, U14.6
TXD2: U8.10, U17.6
VBAT: BT1.1, U16.1
VCC: C6.1, C7.1, C8.1, C9.1, C10.1, C11.1, C12.1, C13.1, C14.1, C15.1, C16.1, C17.1, C18.1, C19.1, C20.1, C21.1, C22.1, C23.1, J1.a1, J1.a2, J1.b1, J1.b2, J1.c1, J1.c2, RNP.1, RP1.1, U1.14, U2.6, U2.16, U3.6, U3.16, U4.6, U4.16, U5.14, U6.14, U7.1, U7.7, U7.9, U7.10, U7.16, U8.16, U9.20, U10.20, U11.20, U12.20, U13.20, U14.8, U14.10, U14.12, U15.14, U16.8, U17.8, U17.10, U17.12, U18.14, X2.14
VMN: C5.1, U8.6
VPN: C4.1, U8.2

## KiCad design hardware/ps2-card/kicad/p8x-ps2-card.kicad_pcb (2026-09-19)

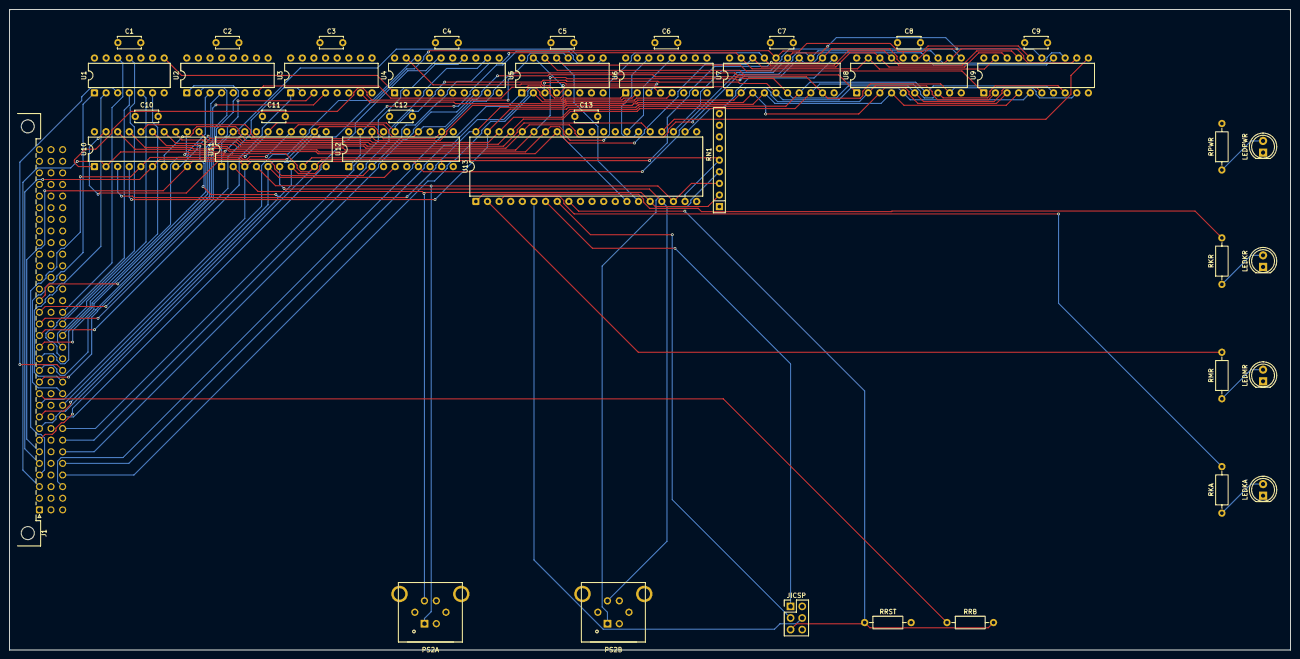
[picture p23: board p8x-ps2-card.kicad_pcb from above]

Board: 4 copper layers, 280.0 x 140.0 mm, 41 parts (0 on the bottom side), 74 nets.

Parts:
C1, C2, C3, C4, C5, C6, C7, C8, C9, C10, C11, C12, C13: 100nF; C_Disc_D5.0mm_W2.5mm_P5.00mm
J1: MABC96R; DIN41612_C_3x32_Male_Horizontal_THT
JICSP: ICSP; PinHeader_2x03_P2.54mm_Vertical
LEDKA: GRN; LED_D5.0mm
LEDKR: YEL; LED_D5.0mm
LEDMR: YEL; LED_D5.0mm
LEDPWR: GRN; LED_D5.0mm
PS2A: PS2-KBD; MiniDIN6_RA_PS2
PS2B: PS2-MOUSE; MiniDIN6_RA_PS2
RKA: 1K; R_Axial_DIN0207_L6.3mm_D2.5mm_P10.16mm_Horizontal
RKR: 1K; R_Axial_DIN0207_L6.3mm_D2.5mm_P10.16mm_Horizontal
RMR: 1K; R_Axial_DIN0207_L6.3mm_D2.5mm_P10.16mm_Horizontal
RN1: 4X10K; R_Array_SIP9
RPWR: 1K; R_Axial_DIN0207_L6.3mm_D2.5mm_P10.16mm_Horizontal
RRB: 470R; R_Axial_DIN0207_L6.3mm_D2.5mm_P10.16mm_Horizontal
RRST: 10K; R_Axial_DIN0207_L6.3mm_D2.5mm_P10.16mm_Horizontal
U1: 74HCT30; DIP-14_W7.62mm
U2, U3, U5, U6: 74HCT138; DIP-16_W7.62mm
U4: WIN CMP; DIP-20_W7.62mm
U7, U8, U9, U10: 74HCT374; DIP-20_W7.62mm
U11, U12: 74HCT244; DIP-20_W7.62mm
U13: PS/2 MCU; DIP-40_W15.24mm

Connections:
-MEMW: U3.7, U6.5
-PSSEL: U4.19, U5.4, U6.4
-RD: U2.7, U5.5
-RES: J1.a11, RRB.1
-RESET: JICSP.5, RRB.2, RRST.1, U13.9
-RR0: U5.15, U7.1, U13.14
-RR1: U5.14, U8.1
-RR2: U5.13, U9.1, U13.15
-RR3: U5.12, U10.1
-RR4: U5.11, U11.1, U11.19
-RR6: U5.9, U12.1, U12.19
-WR1: U6.14, U13.26
-WR3: U6.12, U13.27
A0: J1.c3, U5.1, U6.1
A1: J1.c4, U5.2, U6.2
A2: J1.c5, U5.3, U6.3
A3: J1.c6, U4.8
A4: J1.c7, U4.12
A5: J1.c8, U4.14
A6: J1.c9, U4.16
A7: J1.c10, U4.18
A8: J1.c11, U1.1
A9: J1.c12, U1.2
A10: J1.c13, U1.3
A11: J1.c14, U1.4
A12: J1.c15, U1.5
A13: J1.c16, U1.6
A14: J1.c17, U1.11
A15: J1.c18, U1.12
D0: J1.a3, U7.2, U8.2, U9.2, U10.2, U11.18, U12.18
D1: J1.a4, U7.5, U8.5, U9.5, U10.5, U11.16, U12.16
D2: J1.a5, U7.6, U8.6, U9.6, U10.6, U11.14, U12.14
D3: J1.a6, U7.9, U8.9, U9.9, U10.9, U11.12, U12.12
D4: J1.a7, U7.12, U8.12, U9.12, U10.12, U11.9, U12.9
D5: J1.a8, U7.15, U8.15, U9.15, U10.15, U11.7, U12.7
D6: J1.a9, U7.16, U8.16, U9.16, U10.16, U11.5, U12.5
D7: J1.a10, U7.19, U8.19, U9.19, U10.19, U11.3, U12.3
DLD0: J1.a16, U3.1
DLD1: J1.a17, U3.2
DLD2: J1.a18, U3.3
DLD3: J1.a19, U3.4
DOE0: J1.a12, U2.1
DOE1: J1.a13, U2.2
DOE2: J1.a14, U2.3
DOE3: J1.a15, U2.4
GND: C1.2, C2.2, C3.2, C4.2, C5.2, C6.2, C7.2, C8.2, C9.2, C10.2, C11.2, C12.2, C13.2, J1.a31, J1.a32, J1.b3, J1.b5, J1.b7, J1.b9, J1.b11, J1.b13, J1.b15, J1.b17, J1.b19, J1.b21, J1.b23, J1.b25, J1.b31, J1.b32, J1.c31, J1.c32, JICSP.6, LEDKA.1, LEDKR.1, LEDMR.1, LEDPWR.1, PS2A.3, PS2A.SH, PS2B.3, PS2B.SH, U1.7, U2.5, U2.8, U3.5, U3.8, U4.2, U4.3, U4.4, U4.5, U4.6, U4.7, U4.10, U4.13, U4.17, U5.8, U6.8, U7.10, U8.10, U9.10, U10.10, U11.10, U11.11, U11.13, U11.15, U11.17, U12.6, U12.10, U12.11, U12.13, U12.17, U13.11, U13.31
IOPG: U1.8, U4.1
LDA: U7.11, U13.22
LDB: U9.11, U13.24
LDSA: U8.11, U13.23
LDSB: U10.11, U13.25
LKA: RKA.2, U13.3
LKAA: LEDKA.2, RKA.1
LKR: RKR.2, U13.1
LKRA: LEDKR.2, RKR.1
LMR: RMR.2, U13.2
LMRA: LEDMR.2, RMR.1
LPWRA: LEDPWR.2, RPWR.1
MB0: U7.3, U8.3, U9.3, U10.3, U13.40
MB1: U7.4, U8.4, U9.4, U10.4, U13.39
MB2: U7.7, U8.7, U9.7, U10.7, U13.38
MB3: U7.8, U8.8, U9.8, U10.8, U13.37
MB4: U7.13, U8.13, U9.13, U10.13, U13.36
MB5: U7.14, U8.14, U9.14, U10.14, U13.35
MB6: U7.17, U8.17, U9.17, U10.17, U13.34
MB7: U7.18, U8.18, U9.18, U10.18, U13.33
MISO: JICSP.1, U13.7
MOSI: JICSP.4, U13.6
PS2CKA: PS2A.5, RN1.2, U11.2, U13.16
PS2CKB: PS2B.5, RN1.4, U11.6, U13.17
PS2DA: PS2A.1, RN1.3, U11.4, U13.18
PS2DB: PS2B.1, RN1.5, U11.8, U13.19
SCK: JICSP.3, U13.8
VCC: C1.1, C2.1, C3.1, C4.1, C5.1, C6.1, C7.1, C8.1, C9.1, C10.1, C11.1, C12.1, C13.1, J1.a1, J1.a2, J1.b1, J1.b2, J1.c1, J1.c2, JICSP.2, PS2A.4, PS2B.4, RN1.1, RPWR.2, RRST.2, U1.14, U2.6, U2.16, U3.6, U3.16, U4.9, U4.11, U4.15, U4.20, U5.6, U5.16, U6.6, U6.16, U7.20, U8.20, U9.20, U10.20, U11.20, U12.2, U12.4, U12.8, U12.15, U12.20, U13.10, U13.30

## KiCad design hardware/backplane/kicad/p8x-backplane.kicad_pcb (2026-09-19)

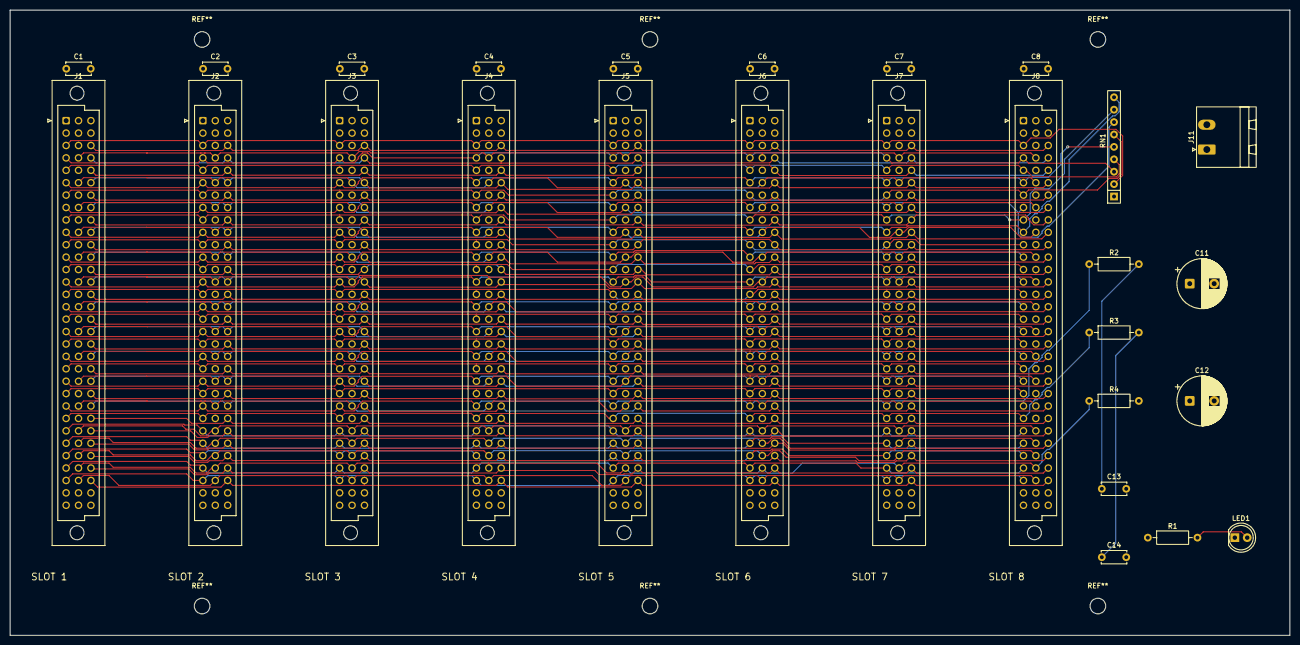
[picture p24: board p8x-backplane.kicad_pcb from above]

Board: 4 copper layers, 262.0 x 128.0 mm, 27 parts (0 on the bottom side), 77 nets.

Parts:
C1, C2, C3, C4, C5, C6, C7, C8: 100nF; C_Disc_D5.0mm_W2.5mm_P5.00mm
C11, C12: 470uF; CP_Radial_D10.0mm_P5.00mm
C13, C14: 150pF; C_Disc_D5.0mm_W2.5mm_P5.00mm
J1: SLOT1; DIN41612_C_3x32_Female_Vertical_THT
J2: SLOT2; DIN41612_C_3x32_Female_Vertical_THT
J3: SLOT3; DIN41612_C_3x32_Female_Vertical_THT
J4: SLOT4; DIN41612_C_3x32_Female_Vertical_THT
J5: SLOT5; DIN41612_C_3x32_Female_Vertical_THT
J6: SLOT6; DIN41612_C_3x32_Female_Vertical_THT
J7: SLOT7; DIN41612_C_3x32_Female_Vertical_THT
J8: SLOT8; DIN41612_C_3x32_Female_Vertical_THT
J11: PWR-5V; PhoenixContact_MSTBA_2,5_2-G-5,08_1x02_P5.08mm_Horizontal
LED1: PWR; LED_D5.0mm
R1: 1K; R_Axial_DIN0207_L6.3mm_D2.5mm_P10.16mm_Horizontal
R2, R3: 100R; R_Axial_DIN0207_L6.3mm_D2.5mm_P10.16mm_Horizontal
R4: 10K; R_Axial_DIN0207_L6.3mm_D2.5mm_P10.16mm_Horizontal
RN1: 8X10K; R_Array_SIP9

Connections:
-RES: J1.a11, J2.a11, J3.a11, J4.a11, J5.a11, J6.a11, J7.a11, J8.a11
A0: J1.c3, J2.c3, J3.c3, J4.c3, J5.c3, J6.c3, J7.c3, J8.c3
A1: J1.c4, J2.c4, J3.c4, J4.c4, J5.c4, J6.c4, J7.c4, J8.c4
A2: J1.c5, J2.c5, J3.c5, J4.c5, J5.c5, J6.c5, J7.c5, J8.c5
A3: J1.c6, J2.c6, J3.c6, J4.c6, J5.c6, J6.c6, J7.c6, J8.c6
A4: J1.c7, J2.c7, J3.c7, J4.c7, J5.c7, J6.c7, J7.c7, J8.c7
A5: J1.c8, J2.c8, J3.c8, J4.c8, J5.c8, J6.c8, J7.c8, J8.c8
A6: J1.c9, J2.c9, J3.c9, J4.c9, J5.c9, J6.c9, J7.c9, J8.c9
A7: J1.c10, J2.c10, J3.c10, J4.c10, J5.c10, J6.c10, J7.c10, J8.c10
A8: J1.c11, J2.c11, J3.c11, J4.c11, J5.c11, J6.c11, J7.c11, J8.c11
A9: J1.c12, J2.c12, J3.c12, J4.c12, J5.c12, J6.c12, J7.c12, J8.c12
A10: J1.c13, J2.c13, J3.c13, J4.c13, J5.c13, J6.c13, J7.c13, J8.c13
A11: J1.c14, J2.c14, J3.c14, J4.c14, J5.c14, J6.c14, J7.c14, J8.c14
A12: J1.c15, J2.c15, J3.c15, J4.c15, J5.c15, J6.c15, J7.c15, J8.c15
A13: J1.c16, J2.c16, J3.c16, J4.c16, J5.c16, J6.c16, J7.c16, J8.c16
A14: J1.c17, J2.c17, J3.c17, J4.c17, J5.c17, J6.c17, J7.c17, J8.c17
A15: J1.c18, J2.c18, J3.c18, J4.c18, J5.c18, J6.c18, J7.c18, J8.c18
ALUM: J1.c23, J2.c23, J3.c23, J4.c23, J5.c23, J6.c23, J7.c23, J8.c23
ALUS0: J1.c19, J2.c19, J3.c19, J4.c19, J5.c19, J6.c19, J7.c19, J8.c19
ALUS1: J1.c20, J2.c20, J3.c20, J4.c20, J5.c20, J6.c20, J7.c20, J8.c20
ALUS2: J1.c21, J2.c21, J3.c21, J4.c21, J5.c21, J6.c21, J7.c21, J8.c21
ALUS3: J1.c22, J2.c22, J3.c22, J4.c22, J5.c22, J6.c22, J7.c22, J8.c22
BSEL: J1.b28, J2.b28, J3.b28, J4.b28, J5.b28, J6.b28, J7.b28, J8.b28
CIN: J1.c24, J2.c24, J3.c24, J4.c24, J5.c24, J6.c24, J7.c24, J8.c24
CLK: J1.a24, J2.a24, J3.a24, J4.a24, J5.a24, J6.a24, J7.a24, J8.a24, R2.1
CLKB: J1.a25, J2.a25, J3.a25, J4.a25, J5.a25, J6.a25, J7.a25, J8.a25, R3.1
CLKB_T: C14.1, R3.2
CLK_T: C13.1, R2.2
CLRC: J1.b27, J2.b27, J3.b27, J4.b27, J5.b27, J6.b27, J7.b27, J8.b27
D0: J1.a3, J2.a3, J3.a3, J4.a3, J5.a3, J6.a3, J7.a3, J8.a3, RN1.2
D1: J1.a4, J2.a4, J3.a4, J4.a4, J5.a4, J6.a4, J7.a4, J8.a4, RN1.3
D2: J1.a5, J2.a5, J3.a5, J4.a5, J5.a5, J6.a5, J7.a5, J8.a5, RN1.4
D3: J1.a6, J2.a6, J3.a6, J4.a6, J5.a6, J6.a6, J7.a6, J8.a6, RN1.5
D4: J1.a7, J2.a7, J3.a7, J4.a7, J5.a7, J6.a7, J7.a7, J8.a7, RN1.6
D5: J1.a8, J2.a8, J3.a8, J4.a8, J5.a8, J6.a8, J7.a8, J8.a8, RN1.7
D6: J1.a9, J2.a9, J3.a9, J4.a9, J5.a9, J6.a9, J7.a9, J8.a9, RN1.8
D7: J1.a10, J2.a10, J3.a10, J4.a10, J5.a10, J6.a10, J7.a10, J8.a10, RN1.9
DLD0: J1.a16, J2.a16, J3.a16, J4.a16, J5.a16, J6.a16, J7.a16, J8.a16
DLD1: J1.a17, J2.a17, J3.a17, J4.a17, J5.a17, J6.a17, J7.a17, J8.a17
DLD2: J1.a18, J2.a18, J3.a18, J4.a18, J5.a18, J6.a18, J7.a18, J8.a18
DLD3: J1.a19, J2.a19, J3.a19, J4.a19, J5.a19, J6.a19, J7.a19, J8.a19
DOE0: J1.a12, J2.a12, J3.a12, J4.a12, J5.a12, J6.a12, J7.a12, J8.a12
DOE1: J1.a13, J2.a13, J3.a13, J4.a13, J5.a13, J6.a13, J7.a13, J8.a13
DOE2: J1.a14, J2.a14, J3.a14, J4.a14, J5.a14, J6.a14, J7.a14, J8.a14
DOE3: J1.a15, J2.a15, J3.a15, J4.a15, J5.a15, J6.a15, J7.a15, J8.a15
FC: J1.a27, J2.a27, J3.a27, J4.a27, J5.a27, J6.a27, J7.a27, J8.a27
FN: J1.a29, J2.a29, J3.a29, J4.a29, J5.a29, J6.a29, J7.a29, J8.a29
FV: J1.a30, J2.a30, J3.a30, J4.a30, J5.a30, J6.a30, J7.a30, J8.a30
FZ: J1.a28, J2.a28, J3.a28, J4.a28, J5.a28, J6.a28, J7.a28, J8.a28
GND: C1.2, C2.2, C3.2, C4.2, C5.2, C6.2, C7.2, C8.2, C11.2, C12.2, C13.2, C14.2, J1.a31, J1.a32, J1.b3, J1.b5, J1.b7, J1.b9, J1.b11, J1.b13, J1.b15, J1.b17, J1.b19, J1.b21, J1.b23, J1.b25, J1.b31, J1.b32, J1.c31, J1.c32, J2.a31, J2.a32, J2.b3, J2.b5, J2.b7, J2.b9, J2.b11, J2.b13, J2.b15, J2.b17, J2.b19, J2.b21, J2.b23, J2.b25, J2.b31, J2.b32, J2.c31, J2.c32, J3.a31, J3.a32, J3.b3, J3.b5, J3.b7, J3.b9, J3.b11, J3.b13, J3.b15, J3.b17, J3.b19, J3.b21, J3.b23, J3.b25, J3.b31, J3.b32, J3.c31, J3.c32, J4.a31, J4.a32, J4.b3, J4.b5, J4.b7, J4.b9, J4.b11, J4.b13, J4.b15, J4.b17, J4.b19, J4.b21, J4.b23, J4.b25, J4.b31, J4.b32, J4.c31, J4.c32, J5.a31, J5.a32, J5.b3, J5.b5, J5.b7, J5.b9, J5.b11, J5.b13, J5.b15, J5.b17, J5.b19, J5.b21, J5.b23, J5.b25, J5.b31, J5.b32, J5.c31, J5.c32, J6.a31, J6.a32, J6.b3, J6.b5, J6.b7, J6.b9, J6.b11, J6.b13, J6.b15, J6.b17, J6.b19, J6.b21, J6.b23, J6.b25, J6.b31, J6.b32, J6.c31, J6.c32, J7.a31, J7.a32, J7.b3, J7.b5, J7.b7, J7.b9, J7.b11, J7.b13, J7.b15, J7.b17, J7.b19, J7.b21, J7.b23, J7.b25, J7.b31, J7.b32, J7.c31, J7.c32, J8.a31, J8.a32, J8.b3, J8.b5, J8.b7, J8.b9, J8.b11, J8.b13, J8.b15, J8.b17, J8.b19, J8.b21, J8.b23, J8.b25, J8.b31, J8.b32, J8.c31, J8.c32, J11.2, LED1.1
IRQ: J1.b29, J2.b29, J3.b29, J4.b29, J5.b29, J6.b29, J7.b29, J8.b29, R4.1
LDF: J1.a26, J2.a26, J3.a26, J4.a26, J5.a26, J6.a26, J7.a26, J8.a26
LDZN: J1.c28, J2.c28, J3.c28, J4.c28, J5.c28, J6.c28, J7.c28, J8.c28
LED_A: LED1.2, R1.2
PDEC: J1.a23, J2.a23, J3.a23, J4.a23, J5.a23, J6.a23, J7.a23, J8.a23
PINC: J1.a22, J2.a22, J3.a22, J4.a22, J5.a22, J6.a22, J7.a22, J8.a22
PSEL0: J1.a20, J2.a20, J3.a20, J4.a20, J5.a20, J6.a20, J7.a20, J8.a20
PSEL1: J1.a21, J2.a21, J3.a21, J4.a21, J5.a21, J6.a21, J7.a21, J8.a21
PSEL2: J1.c27, J2.c27, J3.c27, J4.c27, J5.c27, J6.c27, J7.c27, J8.c27
SETC: J1.c30, J2.c30, J3.c30, J4.c30, J5.c30, J6.c30, J7.c30, J8.c30
SH0: J1.c25, J2.c25, J3.c25, J4.c25, J5.c25, J6.c25, J7.c25, J8.c25
SH1: J1.c26, J2.c26, J3.c26, J4.c26, J5.c26, J6.c26, J7.c26, J8.c26
SHCIN: J1.c29, J2.c29, J3.c29, J4.c29, J5.c29, J6.c29, J7.c29, J8.c29
SPARE11: J1.b30, J2.b30, J3.b30, J4.b30, J5.b30, J6.b30, J7.b30, J8.b30
SPARE12: J1.b4, J2.b4, J3.b4, J4.b4, J5.b4, J6.b4, J7.b4, J8.b4
SPARE13: J1.b6, J2.b6, J3.b6, J4.b6, J5.b6, J6.b6, J7.b6, J8.b6
SPARE14: J1.b8, J2.b8, J3.b8, J4.b8, J5.b8, J6.b8, J7.b8, J8.b8
SPARE15: J1.b10, J2.b10, J3.b10, J4.b10, J5.b10, J6.b10, J7.b10, J8.b10
SPARE16: J1.b12, J2.b12, J3.b12, J4.b12, J5.b12, J6.b12, J7.b12, J8.b12
SPARE17: J1.b14, J2.b14, J3.b14, J4.b14, J5.b14, J6.b14, J7.b14, J8.b14
SPARE18: J1.b16, J2.b16, J3.b16, J4.b16, J5.b16, J6.b16, J7.b16, J8.b16
SPARE19: J1.b18, J2.b18, J3.b18, J4.b18, J5.b18, J6.b18, J7.b18, J8.b18
SPARE20: J1.b20, J2.b20, J3.b20, J4.b20, J5.b20, J6.b20, J7.b20, J8.b20
SPARE21: J1.b22, J2.b22, J3.b22, J4.b22, J5.b22, J6.b22, J7.b22, J8.b22
SPARE22: J1.b24, J2.b24, J3.b24, J4.b24, J5.b24, J6.b24, J7.b24, J8.b24
SPARE23: J1.b26, J2.b26, J3.b26, J4.b26, J5.b26, J6.b26, J7.b26, J8.b26
VCC: C1.1, C2.1, C3.1, C4.1, C5.1, C6.1, C7.1, C8.1, C11.1, C12.1, J1.a1, J1.a2, J1.b1, J1.b2, J1.c1, J1.c2, J2.a1, J2.a2, J2.b1, J2.b2, J2.c1, J2.c2, J3.a1, J3.a2, J3.b1, J3.b2, J3.c1, J3.c2, J4.a1, J4.a2, J4.b1, J4.b2, J4.c1, J4.c2, J5.a1, J5.a2, J5.b1, J5.b2, J5.c1, J5.c2, J6.a1, J6.a2, J6.b1, J6.b2, J6.c1, J6.c2, J7.a1, J7.a2, J7.b1, J7.b2, J7.c1, J7.c2, J8.a1, J8.a2, J8.b1, J8.b2, J8.c1, J8.c2, J11.1, R1.1, R4.2, RN1.1

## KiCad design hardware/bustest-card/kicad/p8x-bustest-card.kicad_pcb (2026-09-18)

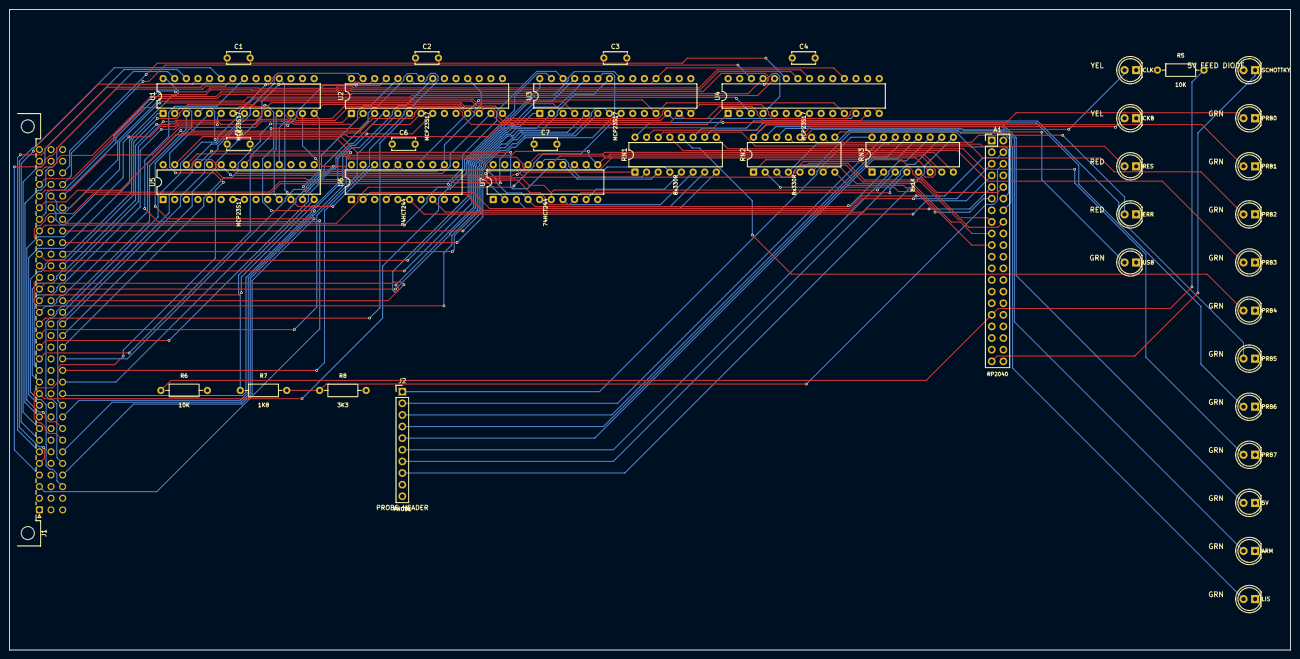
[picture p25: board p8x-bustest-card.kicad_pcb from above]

Board: 4 copper layers, 280.0 x 140.0 mm, 41 parts (0 on the bottom side), 120 nets.

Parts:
A1: RP2040; PinHeader_2x20_P2.54mm_Vertical
C1, C2, C3, C4, C5, C6, C7: 100nF; C_Disc_D5.0mm_W2.5mm_P5.00mm
D1: SCHOTTKY; LED_D5.0mm
J1: MABC96R; DIN41612_C_3x32_Male_Horizontal_THT
J2: PROBE; PinHeader_1x10_P2.54mm_Vertical
LED1: PRB0; LED_D5.0mm
LED2: PRB1; LED_D5.0mm
LED3: PRB2; LED_D5.0mm
LED4: PRB3; LED_D5.0mm
LED5: PRB4; LED_D5.0mm
LED6: PRB5; LED_D5.0mm
LED7: PRB6; LED_D5.0mm
LED8: PRB7; LED_D5.0mm
LED9: 5V; LED_D5.0mm
LED10: ARM; LED_D5.0mm
LED11: LIS; LED_D5.0mm
LED12: CLK; LED_D5.0mm
LED13: CKB; LED_D5.0mm
LED14: RES; LED_D5.0mm
LED15: ERR; LED_D5.0mm
LED16: USB; LED_D5.0mm
R5, R6: 10K; R_Axial_DIN0207_L6.3mm_D2.5mm_P10.16mm_Horizontal
R7: 1K8; R_Axial_DIN0207_L6.3mm_D2.5mm_P10.16mm_Horizontal
R8: 3K3; R_Axial_DIN0207_L6.3mm_D2.5mm_P10.16mm_Horizontal
RN1, RN2: 8x330R; DIP-16_W7.62mm
RN3: 8x1K; DIP-16_W7.62mm
U1, U2, U3, U4, U5: MCP23S17; DIP-28_W7.62mm
U6, U7: 74HCT244; DIP-20_W7.62mm

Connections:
-RES: J1.a11, U3.28
A0: J1.c3, U1.1
A1: J1.c4, U1.2
A2: J1.c5, U1.3
A3: J1.c6, U1.4
A4: J1.c7, U1.5
A5: J1.c8, U1.6
A6: J1.c9, U1.7
A7: J1.c10, U1.8
A8: J1.c11, U2.21
A9: J1.c12, U2.22
A10: J1.c13, U2.23
A11: J1.c14, U2.24
A12: J1.c15, U2.25
A13: J1.c16, U2.26
A14: J1.c17, U2.27
A15: J1.c18, U2.28
ALUM: J1.c23, U3.5
ALUS0: J1.c19, U3.1
ALUS1: J1.c20, U3.2
ALUS2: J1.c21, U3.3
ALUS3: J1.c22, U3.4
BSEL: J1.b28, U4.25
CIN: J1.c24, U3.6
CLK: J1.a24, U3.26
CLKB: J1.a25, U3.27
CLRC: J1.b27, U4.24
CS5: U1.11, U2.11, U3.11, U4.11, U5.11, U6.14
D0: J1.a3, U1.21
D1: J1.a4, U1.22
D2: J1.a5, U1.23
D3: J1.a6, U1.24
D4: J1.a7, U1.25
D5: J1.a8, U1.26
D6: J1.a9, U1.27
D7: J1.a10, U1.28
DLD0: J1.a16, U2.5
DLD1: J1.a17, U2.6
DLD2: J1.a18, U2.7
DLD3: J1.a19, U2.8
DOE0: J1.a12, U2.1
DOE1: J1.a13, U2.2
DOE2: J1.a14, U2.3
DOE3: J1.a15, U2.4
FC: J1.a27, U4.1
FN: J1.a29, U4.3
FV: J1.a30, U4.4
FZ: J1.a28, U4.2
GND: A1.3, A1.33, C1.2, C2.2, C3.2, C4.2, C5.2, C6.2, C7.2, J1.a31, J1.a32, J1.b3, J1.b5, J1.b7, J1.b9, J1.b11, J1.b13, J1.b15, J1.b17, J1.b19, J1.b21, J1.b23, J1.b25, J1.b31, J1.b32, J1.c31, J1.c32, J2.9, J2.10, LED1.1, LED2.1, LED3.1, LED4.1, LED5.1, LED6.1, LED7.1, LED8.1, LED9.1, LED10.1, LED11.1, LED12.1, LED13.1, LED14.1, LED15.1, LED16.1, R6.2, R8.2, U1.10, U1.15, U1.16, U1.17, U1.19, U1.20, U2.10, U2.16, U2.17, U2.19, U2.20, U3.10, U3.15, U3.17, U3.19, U3.20, U4.10, U4.17, U4.19, U4.20, U5.10, U5.15, U5.16, U5.19, U5.20, U6.1, U6.10, U6.11, U6.13, U6.15, U6.17, U6.19, U7.1, U7.10, U7.19
LDF: J1.a26, U4.21
LDZN: J1.c28, U4.22
LK_PR0: LED1.2, RN1.16
LK_PR1: LED2.2, RN1.15
LK_PR2: LED3.2, RN1.14
LK_PR3: LED4.2, RN1.13
LK_PR4: LED5.2, RN1.12
LK_PR5: LED6.2, RN1.11
LK_PR6: LED7.2, RN1.10
LK_PR7: LED8.2, RN1.9
L_PR0: RN1.1, U7.18
L_PR1: RN1.2, U7.16
L_PR2: RN1.3, U7.14
L_PR3: RN1.4, U7.12
L_PR4: RN1.5, U7.9
L_PR5: RN1.6, U7.7
L_PR6: RN1.7, U7.5
L_PR7: RN1.8, U7.3
P5V: A1.39, D1.1
PDEC: J1.a23, U3.25
PINC: J1.a22, U3.24
PR0: RN3.1, U5.21, U7.2
PR1: RN3.2, U5.22, U7.4
PR2: RN3.3, U5.23, U7.6
PR3: RN3.4, U5.24, U7.8
PR4: RN3.5, U5.25, U7.11
PR5: RN3.6, U5.26, U7.13
PR6: RN3.7, U5.27, U7.15
PR7: RN3.8, U5.28, U7.17
PRJ0: J2.1, RN3.16
PRJ1: J2.2, RN3.15
PRJ2: J2.3, RN3.14
PRJ3: J2.4, RN3.13
PRJ4: J2.5, RN3.12
PRJ5: J2.6, RN3.11
PRJ6: J2.7, RN3.10
PRJ7: J2.8, RN3.9
PSEL0: J1.a20, U3.21
PSEL1: J1.a21, U3.22
PSEL2: J1.c27, U3.23
P_CS: A1.7, U6.6
P_MISO: A1.6, R7.2, R8.1
P_RST: A1.9, U6.8
P_SCK: A1.4, U6.2
P_SI: A1.5, U6.4
RST5: U1.18, U2.18, U3.18, U4.18, U5.18, U6.12
SCK5: U1.12, U2.12, U3.12, U4.12, U5.12, U6.18
SENSE5: A1.31, R5.2, R6.1
SETC: J1.c30, U4.23
SH0: J1.c25, U3.7
SH1: J1.c26, U3.8
SHCIN: J1.c29, U4.26
SI5: U1.13, U2.13, U3.13, U4.13, U5.13, U6.16
SO5: R7.1, U1.14, U2.14, U3.14, U4.14, U5.14
ST0: A1.10, RN2.1
ST1: A1.11, RN2.2
ST2: A1.12, RN2.3
ST3: A1.14, RN2.4
ST4: A1.15, RN2.5
ST5: A1.16, RN2.6
ST6: A1.17, RN2.7
ST7: A1.19, RN2.8
STK0: LED9.2, RN2.16
STK1: LED10.2, RN2.15
STK2: LED11.2, RN2.14
STK3: LED12.2, RN2.13
STK4: LED13.2, RN2.12
STK5: LED14.2, RN2.11
STK6: LED15.2, RN2.10
STK7: LED16.2, RN2.9
VCC: C1.1, C2.1, C3.1, C4.1, C5.1, C6.1, C7.1, D1.2, J1.a1, J1.a2, J1.b1, J1.b2, J1.c1, J1.c2, R5.1, U1.9, U2.9, U2.15, U3.9, U3.16, U4.9, U4.15, U4.16, U5.9, U5.17, U6.20, U7.20

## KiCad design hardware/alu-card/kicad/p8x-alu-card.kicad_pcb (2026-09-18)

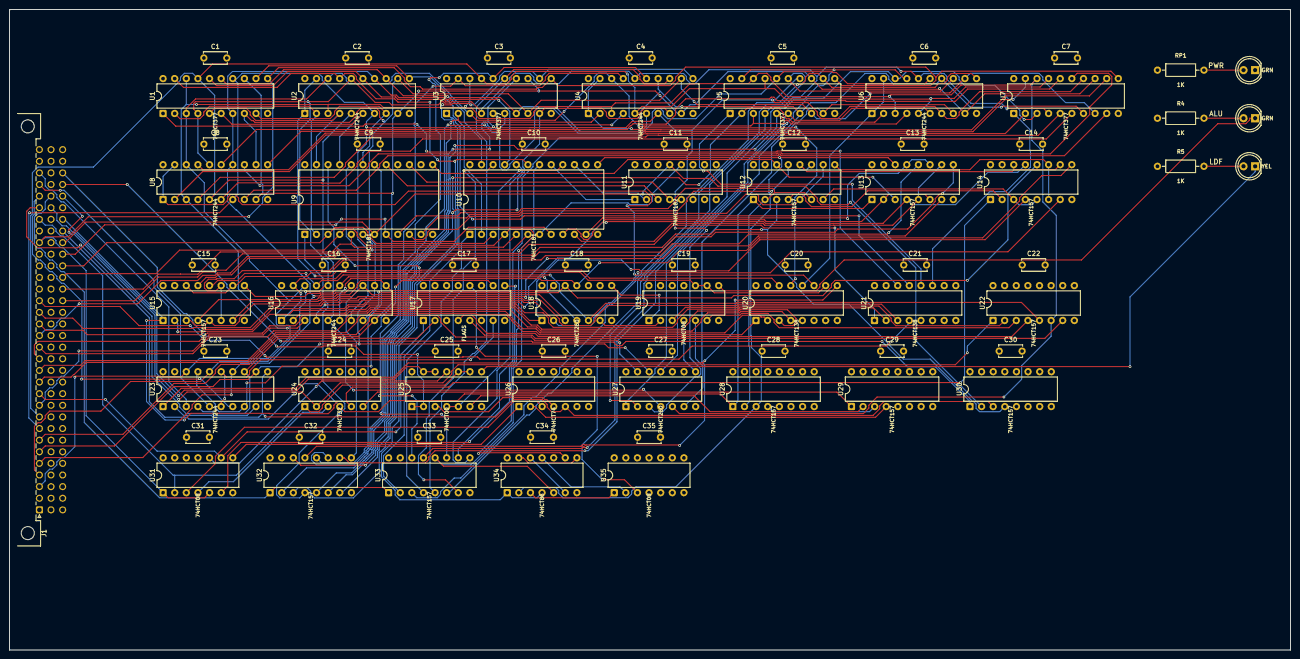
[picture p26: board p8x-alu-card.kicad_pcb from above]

Board: 4 copper layers, 280.0 x 140.0 mm, 77 parts (0 on the bottom side), 151 nets.

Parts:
C1, C2, C3, C4, C5, C6, C7, C8, C9, C10, C11, C12, C13, C14, C15, C16, C17, C18, C19, C20, C21, C22, C23, C24, C25, C26, C27, C28, C29, C30, C31, C32, C33, C34, C35: 100nF; C_Disc_D5.0mm_W2.5mm_P5.00mm
J1: MABC96R; DIN41612_C_3x32_Male_Horizontal_THT
LED3, LED4: GRN; LED_D5.0mm
LED5: YEL; LED_D5.0mm
R4, R5: 1K; R_Axial_DIN0207_L6.3mm_D2.5mm_P10.16mm_Horizontal
RP1: 1K; R_Axial_DIN0207_L6.3mm_D2.5mm_P10.16mm_Horizontal
U1, U3, U5, U7: 74HCT377; DIP-20_W7.62mm
U2, U4, U6, U8, U16, U23: 74HCT244; DIP-20_W7.62mm
U9, U10: 74HCT181; DIP-24_W15.24mm
U11: 74HCT182; DIP-16_W7.62mm
U12, U13, U14, U15, U22, U28, U29, U30, U32, U33: 74HCT157; DIP-16_W7.62mm
U17: FLAGS; DIP-16_W7.62mm
U18, U27: 74HCT260; DIP-14_W7.62mm
U19, U31, U35: 74HCT08; DIP-14_W7.62mm
U20, U21: 74HCT138; DIP-16_W7.62mm
U24: 74HCT32; DIP-14_W7.62mm
U25: 74HCT00; DIP-14_W7.62mm
U26: 74HCT74; DIP-14_W7.62mm
U34: 74HCT86; DIP-14_W7.62mm

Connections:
-CCLR: U26.1, U31.8
-CLRCb: U25.11, U31.10
-DOEA: U2.1, U2.19, U20.14
-DOEALU: U16.1, U16.19, U19.9, U19.10, U20.10
-DOEB: U4.1, U4.19, U20.13
-DOEFLG: U20.9, U23.1
-DOET: U6.1, U6.19, U20.12
-DOET2: U8.1, U8.19, U20.11
-LDA: U1.1, U21.14
-LDB: U3.1, U21.13
-LDT: U5.1, U21.12
-LDT2: U7.1, U21.11
-RES: J1.a11, U17.1, U31.9
-SETCb: U25.3, U26.4
ALUK: LED4.1, U19.8
ALUM: J1.c23, U9.8, U10.8
ALUS0: J1.c19, U9.6, U10.6
ALUS1: J1.c20, U9.5, U10.5
ALUS2: J1.c21, U9.4, U10.4, U34.9
ALUS3: J1.c22, U9.3, U10.3
AQ0: U1.2, U2.2, U9.2
AQ1: U1.5, U2.4, U9.23
AQ2: U1.6, U2.6, U9.21
AQ3: U1.9, U2.8, U9.19
AQ4: U1.12, U2.11, U10.2
AQ5: U1.15, U2.13, U10.23
AQ6: U1.16, U2.15, U10.21
AQ7: U1.19, U2.17, U10.19, U34.1, U34.4
BMX0: U9.1, U32.4
BMX1: U9.22, U32.7
BMX2: U9.20, U32.9
BMX3: U9.18, U32.12
BMX4: U10.1, U33.4
BMX5: U10.22, U33.7
BMX6: U10.20, U33.9
BMX7: U10.18, U33.12, U34.5
BQ0: U3.2, U4.2, U32.2
BQ1: U3.5, U4.4, U32.5
BQ2: U3.6, U4.6, U32.11
BQ3: U3.9, U4.8, U32.14
BQ4: U3.12, U4.11, U33.2
BQ5: U3.15, U4.13, U33.5
BQ6: U3.16, U4.15, U33.11
BQ7: U3.19, U4.17, U33.14
BSEL: J1.b28, U32.1, U33.1
CFLG: U10.16, U25.4, U25.5
CFLGI: U25.6, U29.2
CG0: U9.17, U11.3
CG1: U10.17, U11.1
CIN: J1.c24, U9.7, U11.13, U30.2
CLK: J1.a24, U1.11, U3.11, U5.11, U7.11, U31.1, U31.5
CLKFC: U26.3, U31.3
CLKFZN: U17.9, U31.6
CLRC: J1.b27, U25.12, U25.13
CNX: U10.7, U11.12
CP0: U9.15, U11.4
CP1: U10.15, U11.2
D0: J1.a3, U1.3, U2.18, U3.3, U4.18, U5.3, U6.18, U7.3, U8.18, U16.18, U23.18, U27.1
D1: J1.a4, U1.4, U2.16, U3.4, U4.16, U5.4, U6.16, U7.4, U8.16, U16.16, U23.16, U27.2
D2: J1.a5, U1.7, U2.14, U3.7, U4.14, U5.7, U6.14, U7.7, U8.14, U16.14, U23.14, U27.11
D3: J1.a6, U1.8, U2.12, U3.8, U4.12, U5.8, U6.12, U7.8, U8.12, U16.12, U23.12, U27.12
D4: J1.a7, U1.13, U2.9, U3.13, U4.9, U5.13, U6.9, U7.13, U8.9, U16.9, U27.13
D5: J1.a8, U1.14, U2.7, U3.14, U4.7, U5.14, U6.7, U7.14, U8.7, U16.7, U27.3
D6: J1.a9, U1.17, U2.5, U3.17, U4.5, U5.17, U6.5, U7.17, U8.5, U16.5, U27.4
D7: J1.a10, U1.18, U2.3, U3.18, U4.3, U5.18, U6.3, U7.18, U8.3, U16.3, U22.6, U27.5
DLD0: J1.a16, U21.1
DLD1: J1.a17, U21.2
DLD2: J1.a18, U21.3
DLD3: J1.a19, U21.4
DOE0: J1.a12, U20.1
DOE1: J1.a13, U20.2
DOE2: J1.a14, U20.3
DOE3: J1.a15, U20.4
F0: U9.9, U12.2, U12.6, U28.2
F1: U9.10, U12.5, U12.10
F2: U9.11, U12.11, U12.13
F3: U9.13, U12.14, U13.3
F4: U10.9, U13.2, U13.6
F5: U10.10, U13.5, U13.10
F6: U10.11, U13.11, U13.13
F7: U10.13, U13.14, U28.3, U34.2
FC: J1.a27, U23.9
FENZN: U24.3, U31.4
FN: J1.a29, U23.5
FQC: U23.2, U23.11, U26.5, U30.3
FQN: U17.7, U23.6, U23.15
FQV: U17.10, U23.8, U23.17
FQZ: U17.2, U23.4, U23.13
FV: J1.a30, U23.3
FZ: J1.a28, U23.7
G0: U12.4, U14.2
G1: U12.7, U14.3, U14.5
G2: U12.9, U14.6, U14.11
G3: U12.12, U14.10, U14.14
G4: U13.4, U14.13, U15.2
G5: U13.7, U15.3, U15.5
G6: U13.9, U15.6, U15.11
G7: U13.12, U15.10, U15.14
GND: C1.2, C2.2, C3.2, C4.2, C5.2, C6.2, C7.2, C8.2, C9.2, C10.2, C11.2, C12.2, C13.2, C14.2, C15.2, C16.2, C17.2, C18.2, C19.2, C20.2, C21.2, C22.2, C23.2, C24.2, C25.2, C26.2, C27.2, C28.2, C29.2, C30.2, C31.2, C32.2, C33.2, C34.2, C35.2, J1.a31, J1.a32, J1.b3, J1.b5, J1.b7, J1.b9, J1.b11, J1.b13, J1.b15, J1.b17, J1.b19, J1.b21, J1.b23, J1.b25, J1.b31, J1.b32, J1.c31, J1.c32, LED3.1, U1.10, U2.10, U3.10, U4.10, U5.10, U6.10, U7.10, U8.10, U9.12, U10.12, U11.8, U12.8, U12.15, U13.8, U13.15, U14.8, U14.15, U15.8, U15.15, U16.10, U17.8, U18.7, U18.9, U18.10, U19.7, U19.12, U19.13, U20.5, U20.8, U21.5, U21.8, U22.8, U22.15, U23.10, U23.19, U24.7, U24.9, U24.10, U24.12, U24.13, U25.7, U26.7, U26.11, U26.12, U27.7, U27.9, U27.10, U28.8, U28.15, U29.8, U29.15, U30.8, U30.15, U31.7, U31.12, U31.13, U32.8, U32.15, U33.8, U33.15, U34.7, U35.4, U35.5, U35.7, U35.9, U35.10, U35.12, U35.13
LDF: J1.a26, U24.1, U25.9, U25.10, U31.2
LDFK: LED5.1, U25.8
LDZN: J1.c28, U22.1, U24.2
LEDAL: LED4.2, R4.2
LEDLF: LED5.2, R5.2
LEDP: LED3.2, RP1.2
NC: U26.2, U29.4
NS2: U34.8, U34.13
NSRC: U17.5, U22.7
R0: U14.4, U16.2, U18.1
R1: U14.7, U16.4, U18.2
R2: U14.9, U16.6, U18.11
R3: U14.12, U16.8, U18.12
R4: U15.4, U16.11, U18.13
R5: U15.7, U16.13, U18.3
R6: U15.9, U16.15, U18.4
R7: U15.12, U16.17, U18.5, U22.5
SETC: J1.c30, U25.1, U25.2
SH0: J1.c25, U12.1, U13.1, U24.4, U28.1
SH1: J1.c26, U14.1, U15.1, U24.5
SHANY: U24.6, U29.1
SHCIN: J1.c29, U30.1
SHIN: U12.3, U15.13, U30.4
SHOUT: U28.4, U29.3
T2Q0: U7.2, U8.2
T2Q1: U7.5, U8.4
T2Q2: U7.6, U8.6
T2Q3: U7.9, U8.8
T2Q4: U7.12, U8.11
T2Q5: U7.15, U8.13
T2Q6: U7.16, U8.15
T2Q7: U7.19, U8.17
TQ0: U5.2, U6.2, U32.3
TQ1: U5.5, U6.4, U32.6
TQ2: U5.6, U6.6, U32.10
TQ3: U5.9, U6.8, U32.13
TQ4: U5.12, U6.11, U33.3
TQ5: U5.15, U6.13, U33.6
TQ6: U5.16, U6.15, U33.10
TQ7: U5.19, U6.17, U33.13
VCC: C1.1, C2.1, C3.1, C4.1, C5.1, C6.1, C7.1, C8.1, C9.1, C10.1, C11.1, C12.1, C13.1, C14.1, C15.1, C16.1, C17.1, C18.1, C19.1, C20.1, C21.1, C22.1, C23.1, C24.1, C25.1, C26.1, C27.1, C28.1, C29.1, C30.1, C31.1, C32.1, C33.1, C34.1, C35.1, J1.a1, J1.a2, J1.b1, J1.b2, J1.c1, J1.c2, R4.1, R5.1, RP1.1, U1.20, U2.20, U3.20, U4.20, U5.20, U6.20, U7.20, U8.20, U9.24, U10.24, U11.5, U11.6, U11.14, U11.15, U11.16, U12.16, U13.16, U14.16, U15.16, U16.20, U17.16, U18.14, U19.14, U20.6, U20.16, U21.6, U21.16, U22.16, U23.20, U24.14, U25.14, U26.10, U26.13, U26.14, U27.14, U28.16, U29.16, U30.16, U31.14, U32.16, U33.16, U34.10, U34.14, U35.14
VSRC: U17.12, U35.3
VX1: U34.3, U35.1
VX2: U34.6, U34.12
VX4: U34.11, U35.2
ZBH: U19.5, U27.6
ZBL: U19.4, U27.8
ZBUS: U19.6, U22.3
ZFLG: U19.3, U22.2
ZH: U18.6, U19.2
ZL: U18.8, U19.1
ZSRC: U17.4, U22.4

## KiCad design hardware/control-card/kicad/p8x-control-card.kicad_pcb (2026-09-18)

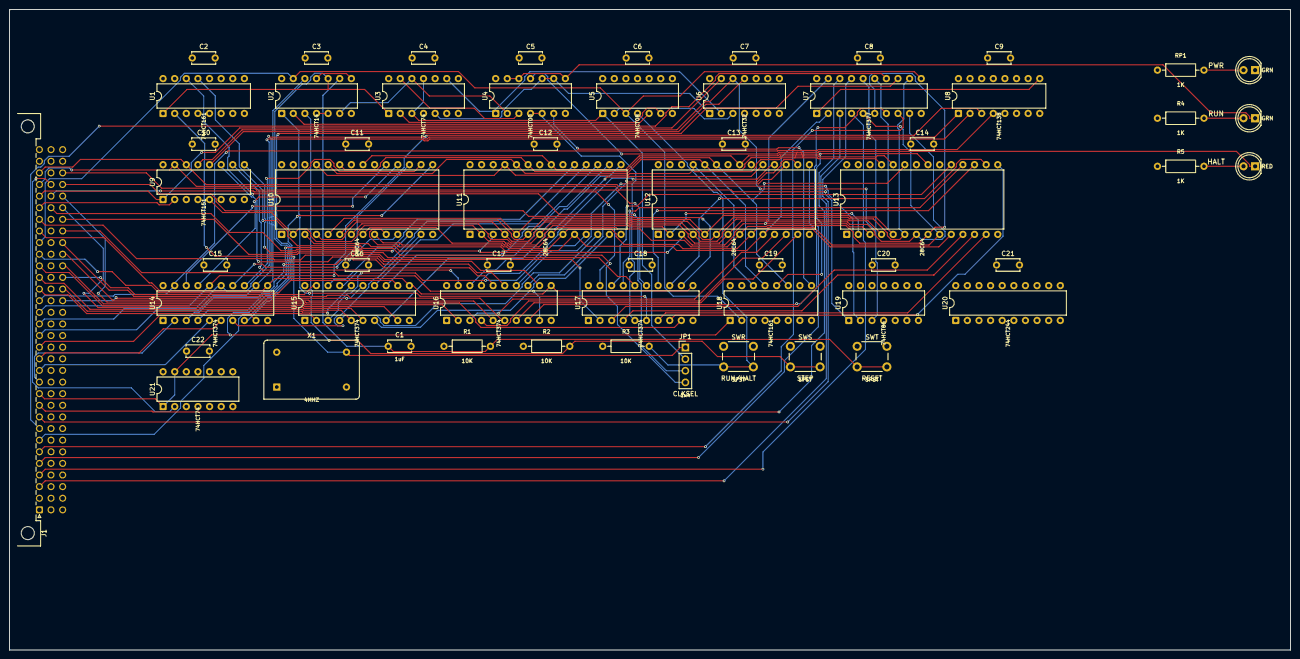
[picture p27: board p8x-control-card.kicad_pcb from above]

Board: 4 copper layers, 280.0 x 140.0 mm, 58 parts (0 on the bottom side), 120 nets.

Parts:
C1: 1uF; C_Disc_D5.0mm_W2.5mm_P5.00mm
C2, C3, C4, C5, C6, C7, C8, C9, C10, C11, C12, C13, C14, C15, C16, C17, C18, C19, C20, C21, C22: 100nF; C_Disc_D5.0mm_W2.5mm_P5.00mm
J1: MABC96R; DIN41612_C_3x32_Male_Horizontal_THT
JP1: 1x4; PinHeader_1x04_P2.54mm_Vertical
LED3, LED4: GRN; LED_D5.0mm
LED5: RED; LED_D5.0mm
R1, R2, R3: 10K; R_Axial_DIN0207_L6.3mm_D2.5mm_P10.16mm_Horizontal
R4, R5: 1K; R_Axial_DIN0207_L6.3mm_D2.5mm_P10.16mm_Horizontal
RP1: 1K; R_Axial_DIN0207_L6.3mm_D2.5mm_P10.16mm_Horizontal
SWR: SPST; SW_PUSH_6mm
SWS: SPST; SW_PUSH_6mm
SWT: SPST; SW_PUSH_6mm
U1, U18: 74HCT161; DIP-16_W7.62mm
U2: 74HCT14; DIP-14_W7.62mm
U3, U21: 74HCT74; DIP-14_W7.62mm
U4: 74HCT00; DIP-14_W7.62mm
U5: 74HCT08; DIP-14_W7.62mm
U6: 74HCT32; DIP-14_W7.62mm
U7: 74HCT377; DIP-20_W7.62mm
U8: 74HCT138; DIP-16_W7.62mm
U9: 74HCT151; DIP-16_W7.62mm
U10, U11, U12, U13: 28C64; DIP-28_W15.24mm
U14, U15, U16, U17: 74HCT374; DIP-20_W7.62mm
U19: 74HCT86; DIP-14_W7.62mm
U20: 74HCT244; DIP-20_W7.62mm
X1: 4MHZ; Oscillator_DIP-14

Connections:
-IRLD: U7.1, U8.9
-RES: J1.a11, U1.1, U2.10, U3.1, U18.1, U21.1, U21.13
-USTL: U4.6, U18.9
ALUM: J1.c23, U16.5
ALUS0: J1.c19, U15.15
ALUS1: J1.c20, U15.16
ALUS2: J1.c21, U15.19
ALUS3: J1.c22, U16.2
BSEL: J1.b28, U17.19
CIN: J1.c24, U16.6
CLK: J1.a24, U2.13, U5.3, U7.11, U18.2
CLKB: J1.a25, U2.12, U14.11, U15.11, U16.11, U17.11
CLKEN: U5.2, U6.3
CLKRAW: JP1.2, U3.3, U3.11, U5.1
CLRC: J1.b27, U17.16
CONDY: U9.5, U10.2, U11.2, U12.2, U13.2
D0: J1.a3, U7.3
D1: J1.a4, U7.4
D2: J1.a5, U7.7
D3: J1.a6, U7.8
D4: J1.a7, U7.13
D5: J1.a8, U7.14
D6: J1.a9, U7.17
D7: J1.a10, U7.18
DIVQA: JP1.3, U1.14
DIVQB: JP1.4, U1.13
DLD0: J1.a16, U8.1, U14.12
DLD1: J1.a17, U8.2, U14.15
DLD2: J1.a18, U8.3, U14.16
DLD3: J1.a19, U8.4, U14.19
DOE0: J1.a12, U14.2
DOE1: J1.a13, U14.5
DOE2: J1.a14, U14.6
DOE3: J1.a15, U14.9
FC: J1.a27, U9.2
FCOND0: U9.11, U16.16
FCOND1: U9.10, U16.19
FCOND2: U9.9, U17.2
FN: J1.a29, U9.15, U19.1
FV: J1.a30, U9.14, U19.2
FZ: J1.a28, U6.13, U9.1
GND: C1.2, C2.2, C3.2, C4.2, C5.2, C6.2, C7.2, C8.2, C9.2, C10.2, C11.2, C12.2, C13.2, C14.2, C15.2, C16.2, C17.2, C18.2, C19.2, C20.2, C21.2, C22.2, J1.a31, J1.a32, J1.b3, J1.b5, J1.b7, J1.b9, J1.b11, J1.b13, J1.b15, J1.b17, J1.b19, J1.b21, J1.b23, J1.b25, J1.b31, J1.b32, J1.c31, J1.c32, LED3.1, SWR.1, SWS.1, SWT.1, U1.3, U1.4, U1.5, U1.6, U1.8, U2.7, U3.7, U4.7, U5.7, U5.9, U5.10, U5.12, U5.13, U6.4, U6.5, U6.7, U6.9, U6.10, U7.10, U8.5, U8.8, U9.4, U9.7, U9.8, U10.14, U10.20, U10.22, U11.14, U11.20, U11.22, U12.14, U12.20, U12.22, U13.14, U13.20, U13.22, U14.1, U14.10, U15.1, U15.10, U16.1, U16.10, U17.1, U17.10, U18.3, U18.4, U18.5, U18.6, U18.8, U19.4, U19.5, U19.7, U19.9, U19.10, U19.12, U19.13, U20.2, U20.4, U20.6, U20.10, U20.11, U20.13, U20.15, U20.17, U21.3, U21.7, U21.11, U21.12, X1.7
HALT: U2.1, U17.6
HALTK: LED5.1, U4.11
HALTN: U2.2, U5.5
IRQ: J1.b29, U21.2
IRQ0: U7.2, U10.10, U11.10, U12.10, U13.10
IRQ1: U7.5, U10.9, U11.9, U12.9, U13.9
IRQ2: U7.6, U10.8, U11.8, U12.8, U13.8
IRQ3: U7.9, U10.7, U11.7, U12.7, U13.7
IRQ4: U7.12, U10.6, U11.6, U12.6, U13.6
IRQ5: U7.15, U10.5, U11.5, U12.5, U13.5
IRQ6: U7.16, U10.4, U11.4, U12.4, U13.4
IRQ7: U7.19, U10.3, U11.3, U12.3, U13.3
LDF: J1.a26, U16.15
LDZN: J1.c28, U17.9
LEDHL: LED5.2, R5.2
LEDP: LED3.2, RP1.2
LEDRN: LED4.2, R4.2
NV: U6.12, U9.13, U19.3
NVZ: U6.11, U9.12
OSCO: JP1.1, U1.2, X1.8
P14B0: U10.11, U14.3
P14B1: U10.12, U14.4
P14B2: U10.13, U14.7
P14B3: U10.15, U14.8
P14B4: U10.16, U14.13
P14B5: U10.17, U14.14
P14B6: U10.18, U14.17
P14B7: U10.19, U14.18
P15B0: U11.11, U15.3
P15B1: U11.12, U15.4
P15B2: U11.13, U15.7
P15B3: U11.15, U15.8
P15B4: U11.16, U15.13
P15B5: U11.17, U15.14
P15B6: U11.18, U15.17
P15B7: U11.19, U15.18
P16B0: U12.11, U16.3
P16B1: U12.12, U16.4
P16B2: U12.13, U16.7
P16B3: U12.15, U16.8
P16B4: U12.16, U16.13
P16B5: U12.17, U16.14
P16B6: U12.18, U16.17
P16B7: U12.19, U16.18
P17B0: U13.11, U17.3
P17B1: U13.12, U17.4
P17B2: U13.13, U17.7
P17B3: U13.15, U17.8
P17B4: U13.16, U17.13
P17B5: U13.17, U17.14
P17B6: U13.18, U17.17
P17B7: U13.19, U17.18
PDEC: J1.a23, U15.12
PINC: J1.a22, U15.9
PSEL0: J1.a20, U15.2
PSEL1: J1.a21, U15.5
PSEL2: J1.c27, U15.6
RSTP: U2.8, U2.11
RSTRAW: C1.1, R1.2, SWT.2, U2.9
RUND: U3.2, U5.6
RUNLK: LED4.1, U4.8, U4.12, U4.13
RUNQ: U3.5, U4.9, U4.10, U6.1
RUNSW: R3.2, SWR.2, U5.4
SETC: J1.c30, U17.15
SH0: J1.c25, U16.9
SH1: J1.c26, U16.12
SHCIN: J1.c29, U17.12
SQ0: U10.25, U11.25, U12.25, U13.25, U18.14
SQ1: U10.24, U11.24, U12.24, U13.24, U18.13
SQ2: U10.21, U11.21, U12.21, U13.21, U18.12
SQ3: U10.23, U11.23, U12.23, U13.23, U18.11
STEPCLR: U3.13, U4.3
STEPN: U2.4, U2.5
STEPP: U2.6, U3.12, U4.2
STEPQ: U3.9, U4.1, U6.2
STEPRAW: R2.2, SWS.2, U2.3
URST: U4.4, U4.5, U17.5
VCC: C2.1, C3.1, C4.1, C5.1, C6.1, C7.1, C8.1, C9.1, C10.1, C11.1, C12.1, C13.1, C14.1, C15.1, C16.1, C17.1, C18.1, C19.1, C20.1, C21.1, C22.1, J1.a1, J1.a2, J1.b1, J1.b2, J1.c1, J1.c2, R1.1, R2.1, R3.1, R4.1, R5.1, RP1.1, U1.7, U1.9, U1.10, U1.16, U2.14, U3.4, U3.10, U3.14, U4.14, U5.14, U6.14, U7.20, U8.6, U8.16, U9.3, U9.16, U10.27, U10.28, U11.27, U11.28, U12.27, U12.28, U13.27, U13.28, U14.20, U15.20, U16.20, U17.20, U18.7, U18.10, U18.16, U19.14, U20.1, U20.8, U20.19, U20.20, U21.4, U21.10, U21.14, X1.14

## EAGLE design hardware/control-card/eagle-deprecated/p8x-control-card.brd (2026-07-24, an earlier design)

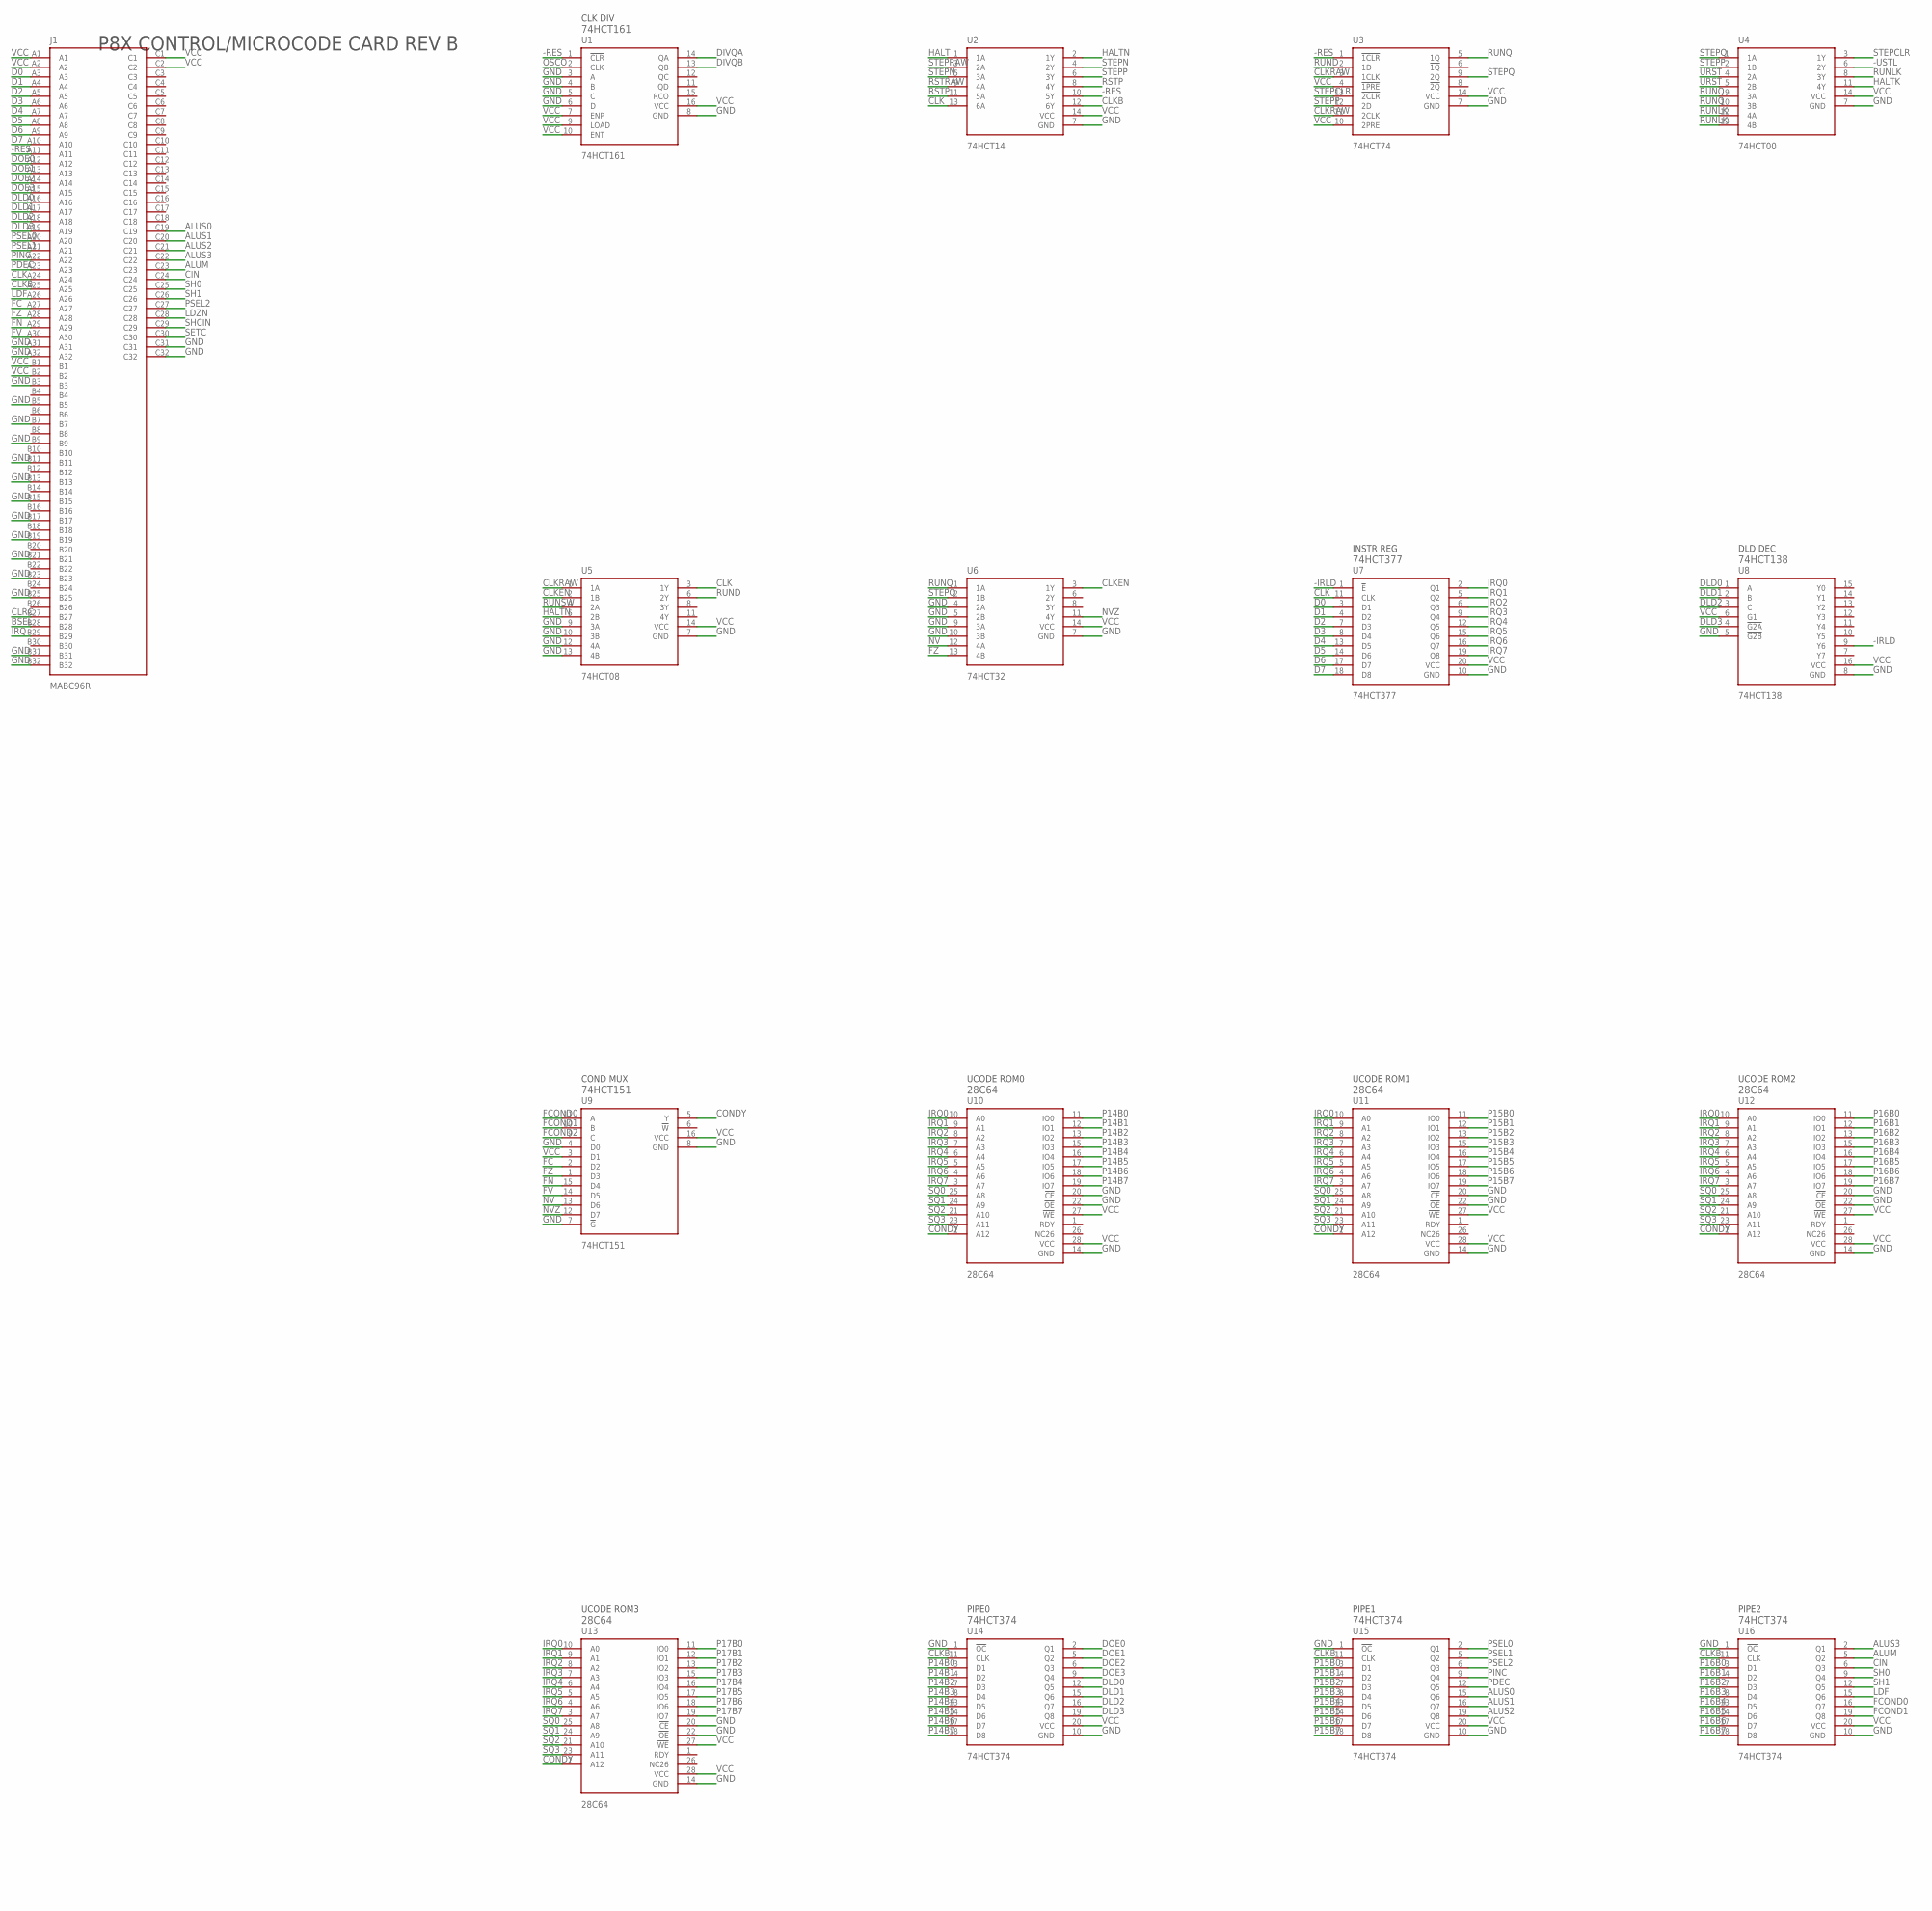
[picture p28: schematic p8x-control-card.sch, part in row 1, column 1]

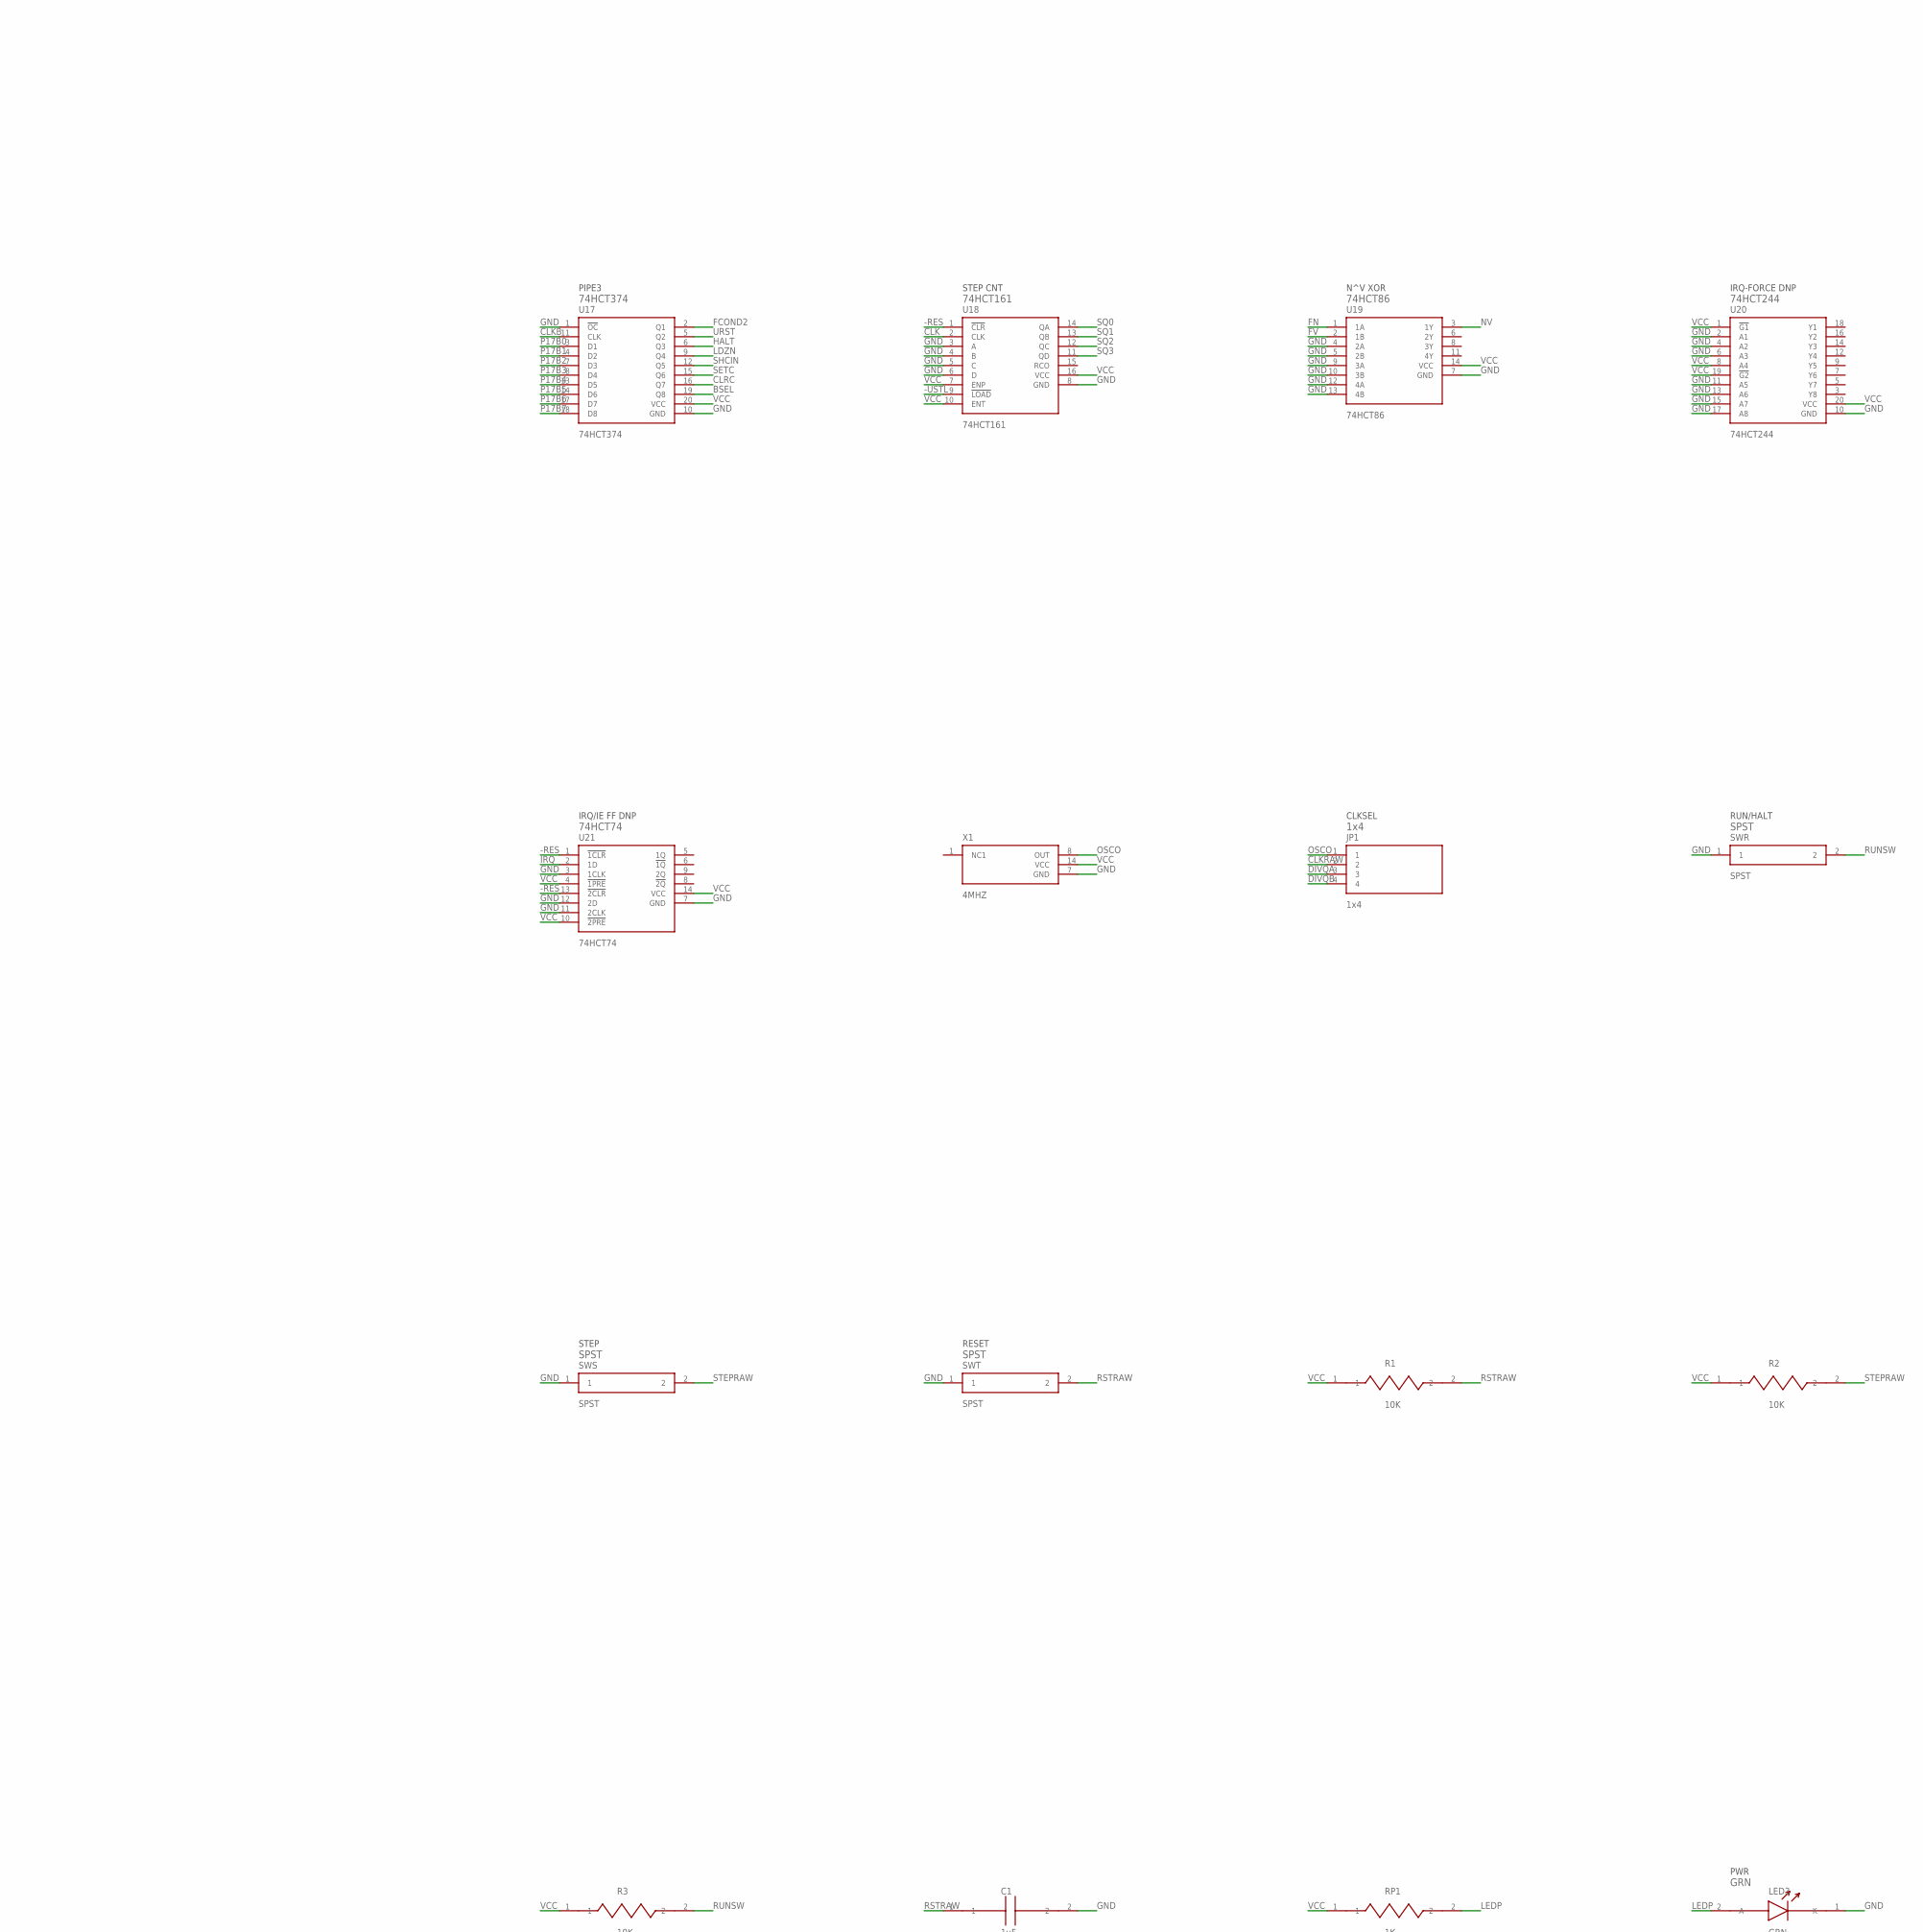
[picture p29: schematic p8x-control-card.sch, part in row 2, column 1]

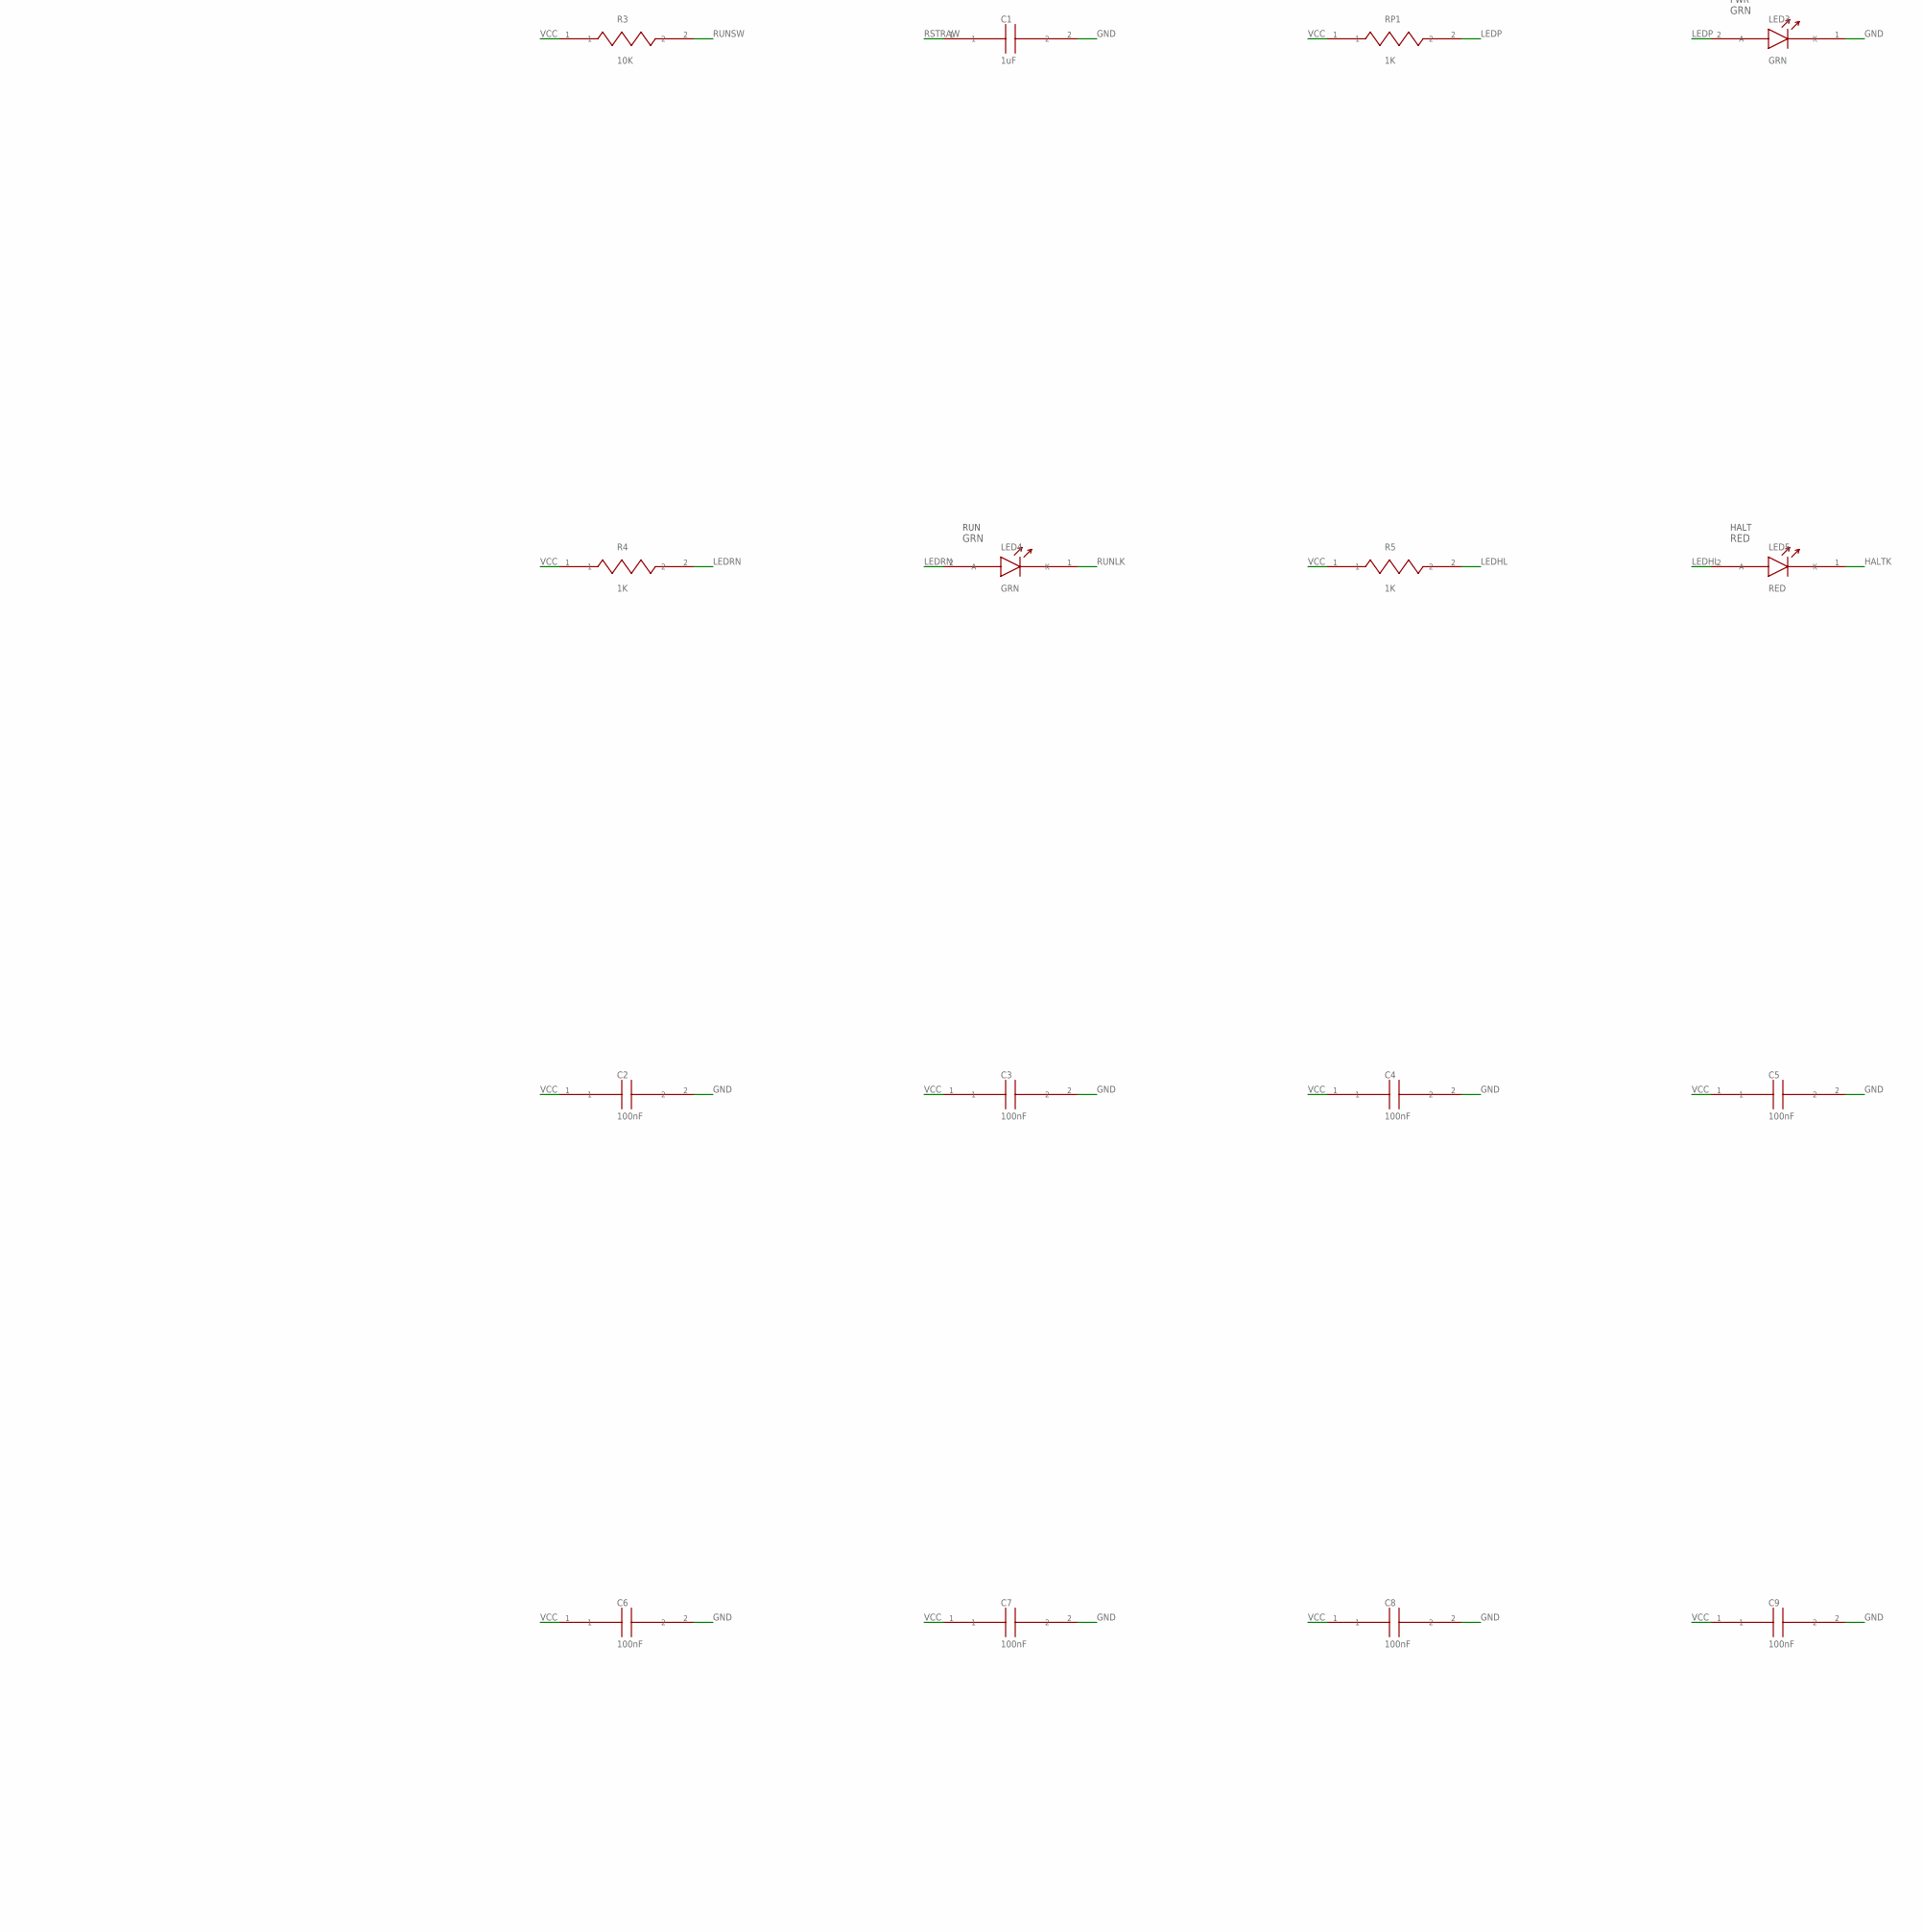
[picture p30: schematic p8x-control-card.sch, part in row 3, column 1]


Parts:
C1: 1uF; C_DISC
C2, C3, C4, C5, C6, C7, C8, C9, C10, C11, C12, C13, C14, C15, C16, C17, C18, C19, C20, C21, C22: 100nF; C_DISC1
J1: MABC96R
JP1: 1x4; HDR4
LED3, LED4: GRN; LED5
LED5: RED; LED5
R1, R2, R3: 10K; R_AXIAL
R4, R5: 1K; R_AXIAL
RP1: 1K; R_AXIAL
SWR: SPST; SW2P
SWS: SPST; SW2P
SWT: SPST; SW2P
U1, U18: 74HCT161; DIP16
U2: 74HCT14; DIP14
U3, U21: 74HCT74; DIP14
U4: 74HCT00; DIP14
U5: 74HCT08; DIP14
U6: 74HCT32; DIP14
U7: 74HCT377; DIP20
U8: 74HCT138; DIP16
U9: 74HCT151; DIP16
U10, U11, U12, U13: 28C64; DIP28W
U14, U15, U16, U17: 74HCT374; DIP20
U19: 74HCT86; DIP14
U20: 74HCT244; DIP20
X1: 4MHZ; OSC4

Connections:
-IRLD: U7.1 (!E), U8.9 (Y6)
-RES: J1.A11, U1.1 (!CLR), U2.10 (5Y), U3.1 (!1CLR), U18.1 (!CLR), U21.1 (!1CLR), U21.13 (!2CLR)
-USTL: U4.6 (2Y), U18.9 (!LOAD)
ALUM: J1.C23, U16.5 (Q2)
ALUS0: J1.C19, U15.15 (Q6)
ALUS1: J1.C20, U15.16 (Q7)
ALUS2: J1.C21, U15.19 (Q8)
ALUS3: J1.C22, U16.2 (Q1)
BSEL: J1.B28, U17.19 (Q8)
CIN: J1.C24, U16.6 (Q3)
CLK: J1.A24, U2.13 (6A), U5.3 (1Y), U7.11 (CLK), U18.2 (CLK)
CLKB: J1.A25, U2.12 (6Y), U14.11 (CLK), U15.11 (CLK), U16.11 (CLK), U17.11 (CLK)
CLKEN: U5.2 (1B), U6.3 (1Y)
CLKRAW: JP1.2, U3.3 (1CLK), U3.11 (2CLK), U5.1 (1A)
CLRC: J1.B27, U17.16 (Q7)
CONDY: U9.5 (Y), U10.2 (A12), U11.2 (A12), U12.2 (A12), U13.2 (A12)
D0: J1.A3, U7.3 (D1)
D1: J1.A4, U7.4 (D2)
D2: J1.A5, U7.7 (D3)
D3: J1.A6, U7.8 (D4)
D4: J1.A7, U7.13 (D5)
D5: J1.A8, U7.14 (D6)
D6: J1.A9, U7.17 (D7)
D7: J1.A10, U7.18 (D8)
DIVQA: JP1.3, U1.14 (QA)
DIVQB: JP1.4, U1.13 (QB)
DLD0: J1.A16, U8.1 (A), U14.12 (Q5)
DLD1: J1.A17, U8.2 (B), U14.15 (Q6)
DLD2: J1.A18, U8.3 (C), U14.16 (Q7)
DLD3: J1.A19, U8.4 (!G2A), U14.19 (Q8)
DOE0: J1.A12, U14.2 (Q1)
DOE1: J1.A13, U14.5 (Q2)
DOE2: J1.A14, U14.6 (Q3)
DOE3: J1.A15, U14.9 (Q4)
FC: J1.A27, U9.2 (D2)
FCOND0: U9.11 (A), U16.16 (Q7)
FCOND1: U9.10 (B), U16.19 (Q8)
FCOND2: U9.9 (C), U17.2 (Q1)
FN: J1.A29, U9.15 (D4), U19.1 (1A)
FV: J1.A30, U9.14 (D5), U19.2 (1B)
FZ: J1.A28, U6.13 (4B), U9.1 (D3)
GND: C1.2, C2.2, C3.2, C4.2, C5.2, C6.2, C7.2, C8.2, C9.2, C10.2, C11.2, C12.2, C13.2, C14.2, C15.2, C16.2, C17.2, C18.2, C19.2, C20.2, C21.2, C22.2, J1.A31, J1.A32, J1.B3, J1.B5, J1.B7, J1.B9, J1.B11, J1.B13, J1.B15, J1.B17, J1.B19, J1.B21, J1.B23, J1.B25, J1.B31, J1.B32, J1.C31, J1.C32, LED3.1 (K), SWR.1, SWS.1, SWT.1, U1.3 (A), U1.4 (B), U1.5 (C), U1.6 (D), U1.8 (GND), U2.7 (GND), U3.7 (GND), U4.7 (GND), U5.7 (GND), U5.9 (3A), U5.10 (3B), U5.12 (4A), U5.13 (4B), U6.4 (2A), U6.5 (2B), U6.7 (GND), U6.9 (3A), U6.10 (3B), U7.10 (GND), U8.5 (!G2B), U8.8 (GND), U9.4 (D0), U9.7 (!G), U9.8 (GND), U10.14 (GND), U10.20 (!CE), U10.22 (!OE), U11.14 (GND), U11.20 (!CE), U11.22 (!OE), U12.14 (GND), U12.20 (!CE), U12.22 (!OE), U13.14 (GND), U13.20 (!CE), U13.22 (!OE), U14.1 (!OC), U14.10 (GND), U15.1 (!OC), U15.10 (GND), U16.1 (!OC), U16.10 (GND), U17.1 (!OC), U17.10 (GND), U18.3 (A), U18.4 (B), U18.5 (C), U18.6 (D), U18.8 (GND), U19.4 (2A), U19.5 (2B), U19.7 (GND), U19.9 (3A), U19.10 (3B), U19.12 (4A), U19.13 (4B), U20.2 (A1), U20.4 (A2), U20.6 (A3), U20.10 (GND), U20.11 (A5), U20.13 (A6), U20.15 (A7), U20.17 (A8), U21.3 (1CLK), U21.7 (GND), U21.11 (2CLK), U21.12 (2D), X1.7 (GND)
HALT: U2.1 (1A), U17.6 (Q3)
HALTK: LED5.1 (K), U4.11 (4Y)
HALTN: U2.2 (1Y), U5.5 (2B)
IRQ: J1.B29, U21.2 (1D)
IRQ0: U7.2 (Q1), U10.10 (A0), U11.10 (A0), U12.10 (A0), U13.10 (A0)
IRQ1: U7.5 (Q2), U10.9 (A1), U11.9 (A1), U12.9 (A1), U13.9 (A1)
IRQ2: U7.6 (Q3), U10.8 (A2), U11.8 (A2), U12.8 (A2), U13.8 (A2)
IRQ3: U7.9 (Q4), U10.7 (A3), U11.7 (A3), U12.7 (A3), U13.7 (A3)
IRQ4: U7.12 (Q5), U10.6 (A4), U11.6 (A4), U12.6 (A4), U13.6 (A4)
IRQ5: U7.15 (Q6), U10.5 (A5), U11.5 (A5), U12.5 (A5), U13.5 (A5)
IRQ6: U7.16 (Q7), U10.4 (A6), U11.4 (A6), U12.4 (A6), U13.4 (A6)
IRQ7: U7.19 (Q8), U10.3 (A7), U11.3 (A7), U12.3 (A7), U13.3 (A7)
LDF: J1.A26, U16.15 (Q6)
LDZN: J1.C28, U17.9 (Q4)
LEDHL: LED5.2 (A), R5.2
LEDP: LED3.2 (A), RP1.2
LEDRN: LED4.2 (A), R4.2
NV: U6.12 (4A), U9.13 (D6), U19.3 (1Y)
NVZ: U6.11 (4Y), U9.12 (D7)
OSCO: JP1.1, U1.2 (CLK), X1.8 (OUT)
P14B0: U10.11 (IO0), U14.3 (D1)
P14B1: U10.12 (IO1), U14.4 (D2)
P14B2: U10.13 (IO2), U14.7 (D3)
P14B3: U10.15 (IO3), U14.8 (D4)
P14B4: U10.16 (IO4), U14.13 (D5)
P14B5: U10.17 (IO5), U14.14 (D6)
P14B6: U10.18 (IO6), U14.17 (D7)
P14B7: U10.19 (IO7), U14.18 (D8)
P15B0: U11.11 (IO0), U15.3 (D1)
P15B1: U11.12 (IO1), U15.4 (D2)
P15B2: U11.13 (IO2), U15.7 (D3)
P15B3: U11.15 (IO3), U15.8 (D4)
P15B4: U11.16 (IO4), U15.13 (D5)
P15B5: U11.17 (IO5), U15.14 (D6)
P15B6: U11.18 (IO6), U15.17 (D7)
P15B7: U11.19 (IO7), U15.18 (D8)
P16B0: U12.11 (IO0), U16.3 (D1)
P16B1: U12.12 (IO1), U16.4 (D2)
P16B2: U12.13 (IO2), U16.7 (D3)
P16B3: U12.15 (IO3), U16.8 (D4)
P16B4: U12.16 (IO4), U16.13 (D5)
P16B5: U12.17 (IO5), U16.14 (D6)
P16B6: U12.18 (IO6), U16.17 (D7)
P16B7: U12.19 (IO7), U16.18 (D8)
P17B0: U13.11 (IO0), U17.3 (D1)
P17B1: U13.12 (IO1), U17.4 (D2)
P17B2: U13.13 (IO2), U17.7 (D3)
P17B3: U13.15 (IO3), U17.8 (D4)
P17B4: U13.16 (IO4), U17.13 (D5)
P17B5: U13.17 (IO5), U17.14 (D6)
P17B6: U13.18 (IO6), U17.17 (D7)
P17B7: U13.19 (IO7), U17.18 (D8)
PDEC: J1.A23, U15.12 (Q5)
PINC: J1.A22, U15.9 (Q4)
PSEL0: J1.A20, U15.2 (Q1)
PSEL1: J1.A21, U15.5 (Q2)
PSEL2: J1.C27, U15.6 (Q3)
RSTP: U2.8 (4Y), U2.11 (5A)
RSTRAW: C1.1, R1.2, SWT.2, U2.9 (4A)
RUND: U3.2 (1D), U5.6 (2Y)
RUNLK: LED4.1 (K), U4.8 (3Y), U4.12 (4A), U4.13 (4B)
RUNQ: U3.5 (1Q), U4.9 (3A), U4.10 (3B), U6.1 (1A)
RUNSW: R3.2, SWR.2, U5.4 (2A)
SETC: J1.C30, U17.15 (Q6)
SH0: J1.C25, U16.9 (Q4)
SH1: J1.C26, U16.12 (Q5)
SHCIN: J1.C29, U17.12 (Q5)
SQ0: U10.25 (A8), U11.25 (A8), U12.25 (A8), U13.25 (A8), U18.14 (QA)
SQ1: U10.24 (A9), U11.24 (A9), U12.24 (A9), U13.24 (A9), U18.13 (QB)
SQ2: U10.21 (A10), U11.21 (A10), U12.21 (A10), U13.21 (A10), U18.12 (QC)
SQ3: U10.23 (A11), U11.23 (A11), U12.23 (A11), U13.23 (A11), U18.11 (QD)
STEPCLR: U3.13 (!2CLR), U4.3 (1Y)
STEPN: U2.4 (2Y), U2.5 (3A)
STEPP: U2.6 (3Y), U3.12 (2D), U4.2 (1B)
STEPQ: U3.9 (2Q), U4.1 (1A), U6.2 (1B)
STEPRAW: R2.2, SWS.2, U2.3 (2A)
URST: U4.4 (2A), U4.5 (2B), U17.5 (Q2)
VCC: C2.1, C3.1, C4.1, C5.1, C6.1, C7.1, C8.1, C9.1, C10.1, C11.1, C12.1, C13.1, C14.1, C15.1, C16.1, C17.1, C18.1, C19.1, C20.1, C21.1, C22.1, J1.A1, J1.A2, J1.B1, J1.B2, J1.C1, J1.C2, R1.1, R2.1, R3.1, R4.1, R5.1, RP1.1, U1.7 (ENP), U1.9 (!LOAD), U1.10 (ENT), U1.16 (VCC), U2.14 (VCC), U3.4 (!1PRE), U3.10 (!2PRE), U3.14 (VCC), U4.14 (VCC), U5.14 (VCC), U6.14 (VCC), U7.20 (VCC), U8.6 (G1), U8.16 (VCC), U9.3 (D1), U9.16 (VCC), U10.27 (!WE), U10.28 (VCC), U11.27 (!WE), U11.28 (VCC), U12.27 (!WE), U12.28 (VCC), U13.27 (!WE), U13.28 (VCC), U14.20 (VCC), U15.20 (VCC), U16.20 (VCC), U17.20 (VCC), U18.7 (ENP), U18.10 (ENT), U18.16 (VCC), U19.14 (VCC), U20.1 (!G1), U20.8 (A4), U20.19 (!G2), U20.20 (VCC), U21.4 (!1PRE), U21.10 (!2PRE), U21.14 (VCC), X1.14 (VCC)

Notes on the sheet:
P8X CONTROL/MICROCODE CARD REV B
N^V XOR
74HCT86
CLK DIV
74HCT161
INSTR REG
74HCT377
DLD DEC
74HCT138
COND MUX
74HCT151
UCODE ROM0
28C64
UCODE ROM1
UCODE ROM2
UCODE ROM3
PIPE0
74HCT374
PIPE1
PIPE2
PIPE3
STEP CNT
IRQ-FORCE DNP
74HCT244
IRQ/IE FF DNP
74HCT74
CLKSEL
1x4
RUN/HALT
SPST
STEP
RESET
PWR
GRN
RUN
HALT
RED

Board: 4 copper layers, 58 parts (0 on the bottom side), 120 nets, no tracks yet.

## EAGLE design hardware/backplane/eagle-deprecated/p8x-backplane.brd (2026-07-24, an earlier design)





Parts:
C1, C2, C3, C4, C5, C6, C7, C8, C9, C10: 100nF; C_DISC1
C11, C12: 470uF; CP_RADIAL
C13, C14: 150pF; C_DISC
J1: SLOT1; FABC96S
J2: SLOT2; FABC96S
J3: SLOT3; FABC96S
J4: SLOT4; FABC96S
J5: SLOT5; FABC96S
J6: SLOT6; FABC96S
J7: SLOT7; FABC96S
J8: SLOT8; FABC96S
J9: SLOT9; FABC96S
J10: SLOT10; FABC96S
J11: PWR-5V; TB4
LED1: PWR; LED5
R1: 1K; R_AXIAL
R2, R3: 100R; R_AXIAL
R4: 10K; R_AXIAL
RN1: 8X10K; SIP9

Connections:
-RES: J1.A11, J2.A11, J3.A11, J4.A11, J5.A11, J6.A11, J7.A11, J8.A11, J9.A11, J10.A11
A0: J1.C3, J2.C3, J3.C3, J4.C3, J5.C3, J6.C3, J7.C3, J8.C3, J9.C3, J10.C3
A1: J1.C4, J2.C4, J3.C4, J4.C4, J5.C4, J6.C4, J7.C4, J8.C4, J9.C4, J10.C4
A2: J1.C5, J2.C5, J3.C5, J4.C5, J5.C5, J6.C5, J7.C5, J8.C5, J9.C5, J10.C5
A3: J1.C6, J2.C6, J3.C6, J4.C6, J5.C6, J6.C6, J7.C6, J8.C6, J9.C6, J10.C6
A4: J1.C7, J2.C7, J3.C7, J4.C7, J5.C7, J6.C7, J7.C7, J8.C7, J9.C7, J10.C7
A5: J1.C8, J2.C8, J3.C8, J4.C8, J5.C8, J6.C8, J7.C8, J8.C8, J9.C8, J10.C8
A6: J1.C9, J2.C9, J3.C9, J4.C9, J5.C9, J6.C9, J7.C9, J8.C9, J9.C9, J10.C9
A7: J1.C10, J2.C10, J3.C10, J4.C10, J5.C10, J6.C10, J7.C10, J8.C10, J9.C10, J10.C10
A8: J1.C11, J2.C11, J3.C11, J4.C11, J5.C11, J6.C11, J7.C11, J8.C11, J9.C11, J10.C11
A9: J1.C12, J2.C12, J3.C12, J4.C12, J5.C12, J6.C12, J7.C12, J8.C12, J9.C12, J10.C12
A10: J1.C13, J2.C13, J3.C13, J4.C13, J5.C13, J6.C13, J7.C13, J8.C13, J9.C13, J10.C13
A11: J1.C14, J2.C14, J3.C14, J4.C14, J5.C14, J6.C14, J7.C14, J8.C14, J9.C14, J10.C14
A12: J1.C15, J2.C15, J3.C15, J4.C15, J5.C15, J6.C15, J7.C15, J8.C15, J9.C15, J10.C15
A13: J1.C16, J2.C16, J3.C16, J4.C16, J5.C16, J6.C16, J7.C16, J8.C16, J9.C16, J10.C16
A14: J1.C17, J2.C17, J3.C17, J4.C17, J5.C17, J6.C17, J7.C17, J8.C17, J9.C17, J10.C17
A15: J1.C18, J2.C18, J3.C18, J4.C18, J5.C18, J6.C18, J7.C18, J8.C18, J9.C18, J10.C18
ALUM: J1.C23, J2.C23, J3.C23, J4.C23, J5.C23, J6.C23, J7.C23, J8.C23, J9.C23, J10.C23
ALUS0: J1.C19, J2.C19, J3.C19, J4.C19, J5.C19, J6.C19, J7.C19, J8.C19, J9.C19, J10.C19
ALUS1: J1.C20, J2.C20, J3.C20, J4.C20, J5.C20, J6.C20, J7.C20, J8.C20, J9.C20, J10.C20
ALUS2: J1.C21, J2.C21, J3.C21, J4.C21, J5.C21, J6.C21, J7.C21, J8.C21, J9.C21, J10.C21
ALUS3: J1.C22, J2.C22, J3.C22, J4.C22, J5.C22, J6.C22, J7.C22, J8.C22, J9.C22, J10.C22
BSEL: J1.B28, J2.B28, J3.B28, J4.B28, J5.B28, J6.B28, J7.B28, J8.B28, J9.B28, J10.B28
CIN: J1.C24, J2.C24, J3.C24, J4.C24, J5.C24, J6.C24, J7.C24, J8.C24, J9.C24, J10.C24
CLK: J1.A24, J2.A24, J3.A24, J4.A24, J5.A24, J6.A24, J7.A24, J8.A24, J9.A24, J10.A24, R2.1
CLKB: J1.A25, J2.A25, J3.A25, J4.A25, J5.A25, J6.A25, J7.A25, J8.A25, J9.A25, J10.A25, R3.1
CLKB_T: C14.1, R3.2
CLK_T: C13.1, R2.2
CLRC: J1.B27, J2.B27, J3.B27, J4.B27, J5.B27, J6.B27, J7.B27, J8.B27, J9.B27, J10.B27
D0: J1.A3, J2.A3, J3.A3, J4.A3, J5.A3, J6.A3, J7.A3, J8.A3, J9.A3, J10.A3, RN1.2 (R1)
D1: J1.A4, J2.A4, J3.A4, J4.A4, J5.A4, J6.A4, J7.A4, J8.A4, J9.A4, J10.A4, RN1.3 (R2)
D2: J1.A5, J2.A5, J3.A5, J4.A5, J5.A5, J6.A5, J7.A5, J8.A5, J9.A5, J10.A5, RN1.4 (R3)
D3: J1.A6, J2.A6, J3.A6, J4.A6, J5.A6, J6.A6, J7.A6, J8.A6, J9.A6, J10.A6, RN1.5 (R4)
D4: J1.A7, J2.A7, J3.A7, J4.A7, J5.A7, J6.A7, J7.A7, J8.A7, J9.A7, J10.A7, RN1.6 (R5)
D5: J1.A8, J2.A8, J3.A8, J4.A8, J5.A8, J6.A8, J7.A8, J8.A8, J9.A8, J10.A8, RN1.7 (R6)
D6: J1.A9, J2.A9, J3.A9, J4.A9, J5.A9, J6.A9, J7.A9, J8.A9, J9.A9, J10.A9, RN1.8 (R7)
D7: J1.A10, J2.A10, J3.A10, J4.A10, J5.A10, J6.A10, J7.A10, J8.A10, J9.A10, J10.A10, RN1.9 (R8)
DLD0: J1.A16, J2.A16, J3.A16, J4.A16, J5.A16, J6.A16, J7.A16, J8.A16, J9.A16, J10.A16
DLD1: J1.A17, J2.A17, J3.A17, J4.A17, J5.A17, J6.A17, J7.A17, J8.A17, J9.A17, J10.A17
DLD2: J1.A18, J2.A18, J3.A18, J4.A18, J5.A18, J6.A18, J7.A18, J8.A18, J9.A18, J10.A18
DLD3: J1.A19, J2.A19, J3.A19, J4.A19, J5.A19, J6.A19, J7.A19, J8.A19, J9.A19, J10.A19
DOE0: J1.A12, J2.A12, J3.A12, J4.A12, J5.A12, J6.A12, J7.A12, J8.A12, J9.A12, J10.A12
DOE1: J1.A13, J2.A13, J3.A13, J4.A13, J5.A13, J6.A13, J7.A13, J8.A13, J9.A13, J10.A13
DOE2: J1.A14, J2.A14, J3.A14, J4.A14, J5.A14, J6.A14, J7.A14, J8.A14, J9.A14, J10.A14
DOE3: J1.A15, J2.A15, J3.A15, J4.A15, J5.A15, J6.A15, J7.A15, J8.A15, J9.A15, J10.A15
FC: J1.A27, J2.A27, J3.A27, J4.A27, J5.A27, J6.A27, J7.A27, J8.A27, J9.A27, J10.A27
FN: J1.A29, J2.A29, J3.A29, J4.A29, J5.A29, J6.A29, J7.A29, J8.A29, J9.A29, J10.A29
FV: J1.A30, J2.A30, J3.A30, J4.A30, J5.A30, J6.A30, J7.A30, J8.A30, J9.A30, J10.A30
FZ: J1.A28, J2.A28, J3.A28, J4.A28, J5.A28, J6.A28, J7.A28, J8.A28, J9.A28, J10.A28
GND: C1.2, C2.2, C3.2, C4.2, C5.2, C6.2, C7.2, C8.2, C9.2, C10.2, C11.2 (-), C12.2 (-), C13.2, C14.2, J1.A31, J1.A32, J1.B3, J1.B5, J1.B7, J1.B9, J1.B11, J1.B13, J1.B15, J1.B17, J1.B19, J1.B21, J1.B23, J1.B25, J1.B31, J1.B32, J1.C31, J1.C32, J2.A31, J2.A32, J2.B3, J2.B5, J2.B7, J2.B9, J2.B11, J2.B13, J2.B15, J2.B17, J2.B19, J2.B21, J2.B23, J2.B25, J2.B31, J2.B32, J2.C31, J2.C32, J3.A31, J3.A32, J3.B3, J3.B5, J3.B7, J3.B9, J3.B11, J3.B13, J3.B15, J3.B17, J3.B19, J3.B21, J3.B23, J3.B25, J3.B31, J3.B32, J3.C31, J3.C32, J4.A31, J4.A32, J4.B3, J4.B5, J4.B7, J4.B9, J4.B11, J4.B13, J4.B15, J4.B17, J4.B19, J4.B21, J4.B23, J4.B25, J4.B31, J4.B32, J4.C31, J4.C32, J5.A31, J5.A32, J5.B3, J5.B5, J5.B7, J5.B9, J5.B11, J5.B13, J5.B15, J5.B17, J5.B19, J5.B21, J5.B23, J5.B25, J5.B31, J5.B32, J5.C31, J5.C32, J6.A31, J6.A32, J6.B3, J6.B5, J6.B7, J6.B9, J6.B11, J6.B13, J6.B15, J6.B17, J6.B19, J6.B21, J6.B23, J6.B25, J6.B31, J6.B32, J6.C31, J6.C32, J7.A31, J7.A32, J7.B3, J7.B5, J7.B7, J7.B9, J7.B11, J7.B13, J7.B15, J7.B17, J7.B19, J7.B21, J7.B23, J7.B25, J7.B31, J7.B32, J7.C31, J7.C32, J8.A31, J8.A32, J8.B3, J8.B5, J8.B7, J8.B9, J8.B11, J8.B13, J8.B15, J8.B17, J8.B19, J8.B21, J8.B23, J8.B25, J8.B31, J8.B32, J8.C31, J8.C32, J9.A31, J9.A32, J9.B3, J9.B5, J9.B7, J9.B9, J9.B11, J9.B13, J9.B15, J9.B17, J9.B19, J9.B21, J9.B23, J9.B25, J9.B31, J9.B32, J9.C31, J9.C32, J10.A31, J10.A32, J10.B3, J10.B5, J10.B7, J10.B9, J10.B11, J10.B13, J10.B15, J10.B17, J10.B19, J10.B21, J10.B23, J10.B25, J10.B31, J10.B32, J10.C31, J10.C32, J11.3, J11.4, LED1.1 (K)
IRQ: J1.B29, J2.B29, J3.B29, J4.B29, J5.B29, J6.B29, J7.B29, J8.B29, J9.B29, J10.B29, R4.1
LDF: J1.A26, J2.A26, J3.A26, J4.A26, J5.A26, J6.A26, J7.A26, J8.A26, J9.A26, J10.A26
LDZN: J1.C28, J2.C28, J3.C28, J4.C28, J5.C28, J6.C28, J7.C28, J8.C28, J9.C28, J10.C28
LED_A: LED1.2 (A), R1.2
PDEC: J1.A23, J2.A23, J3.A23, J4.A23, J5.A23, J6.A23, J7.A23, J8.A23, J9.A23, J10.A23
PINC: J1.A22, J2.A22, J3.A22, J4.A22, J5.A22, J6.A22, J7.A22, J8.A22, J9.A22, J10.A22
PSEL0: J1.A20, J2.A20, J3.A20, J4.A20, J5.A20, J6.A20, J7.A20, J8.A20, J9.A20, J10.A20
PSEL1: J1.A21, J2.A21, J3.A21, J4.A21, J5.A21, J6.A21, J7.A21, J8.A21, J9.A21, J10.A21
PSEL2: J1.C27, J2.C27, J3.C27, J4.C27, J5.C27, J6.C27, J7.C27, J8.C27, J9.C27, J10.C27
SETC: J1.C30, J2.C30, J3.C30, J4.C30, J5.C30, J6.C30, J7.C30, J8.C30, J9.C30, J10.C30
SH0: J1.C25, J2.C25, J3.C25, J4.C25, J5.C25, J6.C25, J7.C25, J8.C25, J9.C25, J10.C25
SH1: J1.C26, J2.C26, J3.C26, J4.C26, J5.C26, J6.C26, J7.C26, J8.C26, J9.C26, J10.C26
SHCIN: J1.C29, J2.C29, J3.C29, J4.C29, J5.C29, J6.C29, J7.C29, J8.C29, J9.C29, J10.C29
SPARE11: J1.B30, J2.B30, J3.B30, J4.B30, J5.B30, J6.B30, J7.B30, J8.B30, J9.B30, J10.B30
SPARE12: J1.B4, J2.B4, J3.B4, J4.B4, J5.B4, J6.B4, J7.B4, J8.B4, J9.B4, J10.B4
SPARE13: J1.B6, J2.B6, J3.B6, J4.B6, J5.B6, J6.B6, J7.B6, J8.B6, J9.B6, J10.B6
SPARE14: J1.B8, J2.B8, J3.B8, J4.B8, J5.B8, J6.B8, J7.B8, J8.B8, J9.B8, J10.B8
SPARE15: J1.B10, J2.B10, J3.B10, J4.B10, J5.B10, J6.B10, J7.B10, J8.B10, J9.B10, J10.B10
SPARE16: J1.B12, J2.B12, J3.B12, J4.B12, J5.B12, J6.B12, J7.B12, J8.B12, J9.B12, J10.B12
SPARE17: J1.B14, J2.B14, J3.B14, J4.B14, J5.B14, J6.B14, J7.B14, J8.B14, J9.B14, J10.B14
SPARE18: J1.B16, J2.B16, J3.B16, J4.B16, J5.B16, J6.B16, J7.B16, J8.B16, J9.B16, J10.B16
SPARE19: J1.B18, J2.B18, J3.B18, J4.B18, J5.B18, J6.B18, J7.B18, J8.B18, J9.B18, J10.B18
SPARE20: J1.B20, J2.B20, J3.B20, J4.B20, J5.B20, J6.B20, J7.B20, J8.B20, J9.B20, J10.B20
SPARE21: J1.B22, J2.B22, J3.B22, J4.B22, J5.B22, J6.B22, J7.B22, J8.B22, J9.B22, J10.B22
SPARE22: J1.B24, J2.B24, J3.B24, J4.B24, J5.B24, J6.B24, J7.B24, J8.B24, J9.B24, J10.B24
SPARE23: J1.B26, J2.B26, J3.B26, J4.B26, J5.B26, J6.B26, J7.B26, J8.B26, J9.B26, J10.B26
VCC: C1.1, C2.1, C3.1, C4.1, C5.1, C6.1, C7.1, C8.1, C9.1, C10.1, C11.1 (+), C12.1 (+), J1.A1, J1.A2, J1.B1, J1.B2, J1.C1, J1.C2, J2.A1, J2.A2, J2.B1, J2.B2, J2.C1, J2.C2, J3.A1, J3.A2, J3.B1, J3.B2, J3.C1, J3.C2, J4.A1, J4.A2, J4.B1, J4.B2, J4.C1, J4.C2, J5.A1, J5.A2, J5.B1, J5.B2, J5.C1, J5.C2, J6.A1, J6.A2, J6.B1, J6.B2, J6.C1, J6.C2, J7.A1, J7.A2, J7.B1, J7.B2, J7.C1, J7.C2, J8.A1, J8.A2, J8.B1, J8.B2, J8.C1, J8.C2, J9.A1, J9.A2, J9.B1, J9.B2, J9.C1, J9.C2, J10.A1, J10.A2, J10.B1, J10.B2, J10.C1, J10.C2, J11.1, J11.2, R1.1, R4.2, RN1.1 (COM)

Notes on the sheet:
P8X 10-SLOT BACKPLANE REV C


Board: 4 copper layers, 300.0 x 128.0 mm, 31 parts (0 on the bottom side), 77 nets.

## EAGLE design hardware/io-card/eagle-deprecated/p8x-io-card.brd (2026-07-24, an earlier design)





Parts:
BT1: CR2032; CP_RADIAL
C2, C3, C4, C5: 1uF; C_DISC
C6, C7, C8, C9, C10, C11, C12, C13, C14, C15, C16, C17, C18, C19, C20, C21: 100nF; C_DISC1
J1: MABC96R
J2, J3: 1x3; HDR3
LA1: 8-LED BAR; DIP16
LED3: GRN; LED5
LED4: YEL; LED5
LM1: A0-7; DIP16
LM2: A8-15; DIP16
LM3: D0-7; DIP16
R4: 1K; R_AXIAL
RL1: 8X330R; SIP16
RM1, RM2, RM3: 8X330R; SIP16
RNP: 8X10K; SIP9
RP1: 1K; R_AXIAL
SW1: INPUT; DIP16
U1: 74HCT30; DIP14
U2, U3, U4: 74HCT138; DIP16
U5: 74HCT32; DIP14
U6: 74HCT08; DIP14
U7: 74HCT161; DIP16
U8: MAX232; DIP16
U9, U11, U12, U13: 74HCT244; DIP20
U10: 74HCT374; DIP20
U14: 6850; DIP24W
U15: 74HCT00; DIP14
U16: DS1302; DIP8
X2: 2.4576MHZ; OSC4
X3: 32.768KHZ; C_DISC

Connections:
-MEMW: U4.7 (Y7), U5.5 (2B), U5.13 (4B), U14.13 (RW)
-P0: U2.15 (Y0), U5.1 (1A)
-P1: U2.14 (Y1), U5.4 (2A)
-P2: U2.13 (Y2), U14.9 (!CS2), U15.4 (2A), U15.5 (2B)
-RD: U3.7 (Y7), U5.2 (1B), U5.12 (4A)
-RES: J1.A11
-SWOE: U5.3 (1Y), U9.1 (!G1), U9.19 (!G2)
A0: J1.C3, U11.2 (A1), U14.11 (RS)
A1: J1.C4, U2.1 (A), U11.4 (A2)
A2: J1.C5, U2.2 (B), U11.6 (A3)
A3: J1.C6, U2.3 (C), U11.8 (A4)
A4: J1.C7, U11.11 (A5)
A5: J1.C8, U11.13 (A6)
A6: J1.C9, U11.15 (A7)
A7: J1.C10, U11.17 (A8)
A8: J1.C11, U1.1 (A), U12.2 (A1)
A9: J1.C12, U1.2 (B), U12.4 (A2)
A10: J1.C13, U1.3 (C), U12.6 (A3)
A11: J1.C14, U1.4 (D), U12.8 (A4)
A12: J1.C15, U1.5 (E), U12.11 (A5)
A13: J1.C16, U1.6 (F), U12.13 (A6)
A14: J1.C17, U1.11 (G), U12.15 (A7)
A15: J1.C18, U1.12 (H), U12.17 (A8)
ACCP: U6.10 (3B), U15.11 (4Y)
BCLK: U7.11 (QD), U14.3 (RXCLK), U14.4 (TXCLK)
BOEISH: U5.11 (4Y), U15.12 (4A), U15.13 (4B)
BOSC: U7.2 (CLK), X2.8 (OUT)
C1MN: C2.2, U8.3 (C1M)
C1PN: C2.1, U8.1 (C1P)
C2MN: C3.2, U8.5 (C2M)
C2PN: C3.1, U8.4 (C2P)
CLKB: J1.A25, U6.5 (2B), U15.1 (1A), U15.2 (1B)
CLKBN: U5.10 (3B), U15.3 (1Y)
D0: J1.A3, U9.18 (Y1), U10.3 (D1), U13.2 (A1), U14.22 (D0)
D1: J1.A4, U9.16 (Y2), U10.4 (D2), U13.4 (A2), U14.21 (D1)
D2: J1.A5, U9.14 (Y3), U10.7 (D3), U13.6 (A3), U14.20 (D2)
D3: J1.A6, U9.12 (Y4), U10.8 (D4), U13.8 (A4), U14.19 (D3)
D4: J1.A7, U9.9 (Y5), U10.13 (D5), U13.11 (A5), U14.18 (D4)
D5: J1.A8, U9.7 (Y6), U10.14 (D6), U13.13 (A6), U14.17 (D5)
D6: J1.A9, U9.5 (Y7), U10.17 (D7), U13.15 (A7), U14.16 (D6)
D7: J1.A10, U9.3 (Y8), U10.18 (D8), U13.17 (A8), U14.15 (D7)
DLD0: J1.A16, U4.1 (A)
DLD1: J1.A17, U4.2 (B)
DLD2: J1.A18, U4.3 (C)
DLD3: J1.A19, U4.4 (!G2A)
DOE0: J1.A12, U3.1 (A)
DOE1: J1.A13, U3.2 (B)
DOE2: J1.A14, U3.3 (C)
DOE3: J1.A15, U3.4 (!G2A)
EEN: U6.6 (2Y), U14.14 (E)
GND: BT1.2 (-), C4.2, C5.2, C6.2, C7.2, C8.2, C9.2, C10.2, C11.2, C12.2, C13.2, C14.2, C15.2, C16.2, C17.2, C18.2, C19.2, C20.2, C21.2, J1.A31, J1.A32, J1.B3, J1.B5, J1.B7, J1.B9, J1.B11, J1.B13, J1.B15, J1.B17, J1.B19, J1.B21, J1.B23, J1.B25, J1.B31, J1.B32, J1.C31, J1.C32, J2.3, LA1.9 (K8), LA1.10 (K7), LA1.11 (K6), LA1.12 (K5), LA1.13 (K4), LA1.14 (K3), LA1.15 (K2), LA1.16 (K1), LED3.1 (K), LED4.1 (K), LM1.9 (K8), LM1.10 (K7), LM1.11 (K6), LM1.12 (K5), LM1.13 (K4), LM1.14 (K3), LM1.15 (K2), LM1.16 (K1), LM2.9 (K8), LM2.10 (K7), LM2.11 (K6), LM2.12 (K5), LM2.13 (K4), LM2.14 (K3), LM2.15 (K2), LM2.16 (K1), LM3.9 (K8), LM3.10 (K7), LM3.11 (K6), LM3.12 (K5), LM3.13 (K4), LM3.14 (K3), LM3.15 (K2), LM3.16 (K1), SW1.9 (B8), SW1.10 (B7), SW1.11 (B6), SW1.12 (B5), SW1.13 (B4), SW1.14 (B3), SW1.15 (B2), SW1.16 (B1), U1.7 (GND), U2.5 (!G2B), U2.8 (GND), U3.5 (!G2B), U3.8 (GND), U4.5 (!G2B), U4.8 (GND), U5.7 (GND), U6.1 (1A), U6.2 (1B), U6.7 (GND), U7.3 (A), U7.4 (B), U7.5 (C), U7.6 (D), U7.8 (GND), U8.15 (GND), U9.10 (GND), U10.1 (!OC), U10.10 (GND), U11.1 (!G1), U11.10 (GND), U11.19 (!G2), U12.1 (!G1), U12.10 (GND), U12.19 (!G2), U13.1 (!G1), U13.10 (GND), U13.19 (!G2), U14.1 (GND), U14.23 (!DCD), U14.24 (!CTS), U15.7 (GND), U16.4 (GND), X2.7 (GND)
IOPG: U1.8 (Y), U2.4 (!G2A), U15.9 (3A), U15.10 (3B)
IOPGN: U6.9 (3A), U15.8 (3Y)
LCK: U5.8 (3Y), U10.11 (CLK)
LED4A: LED4.2 (A), R4.1
LEDP: LED3.2 (A), RP1.2
LP0: RL1.1 (A1), U10.2 (Q1)
LP1: RL1.3 (A2), U10.5 (Q2)
LP2: RL1.5 (A3), U10.6 (Q3)
LP3: RL1.7 (A4), U10.9 (Q4)
LP4: RL1.9 (A5), U10.12 (Q5)
LP5: RL1.11 (A6), U10.15 (Q6)
LP6: RL1.13 (A7), U10.16 (Q7)
LP7: RL1.15 (A8), U10.19 (Q8)
LR0: LA1.1 (A1), RL1.2 (B1)
LR1: LA1.2 (A2), RL1.4 (B2)
LR2: LA1.3 (A3), RL1.6 (B3)
LR3: LA1.4 (A4), RL1.8 (B4)
LR4: LA1.5 (A5), RL1.10 (B5)
LR5: LA1.6 (A6), RL1.12 (B6)
LR6: LA1.7 (A7), RL1.14 (B7)
LR7: LA1.8 (A8), RL1.16 (B8)
LW1: U5.6 (2Y), U5.9 (3A)
MA0: RM1.1 (A1), U11.18 (Y1)
MA1: RM1.3 (A2), U11.16 (Y2)
MA2: RM1.5 (A3), U11.14 (Y3)
MA3: RM1.7 (A4), U11.12 (Y4)
MA4: RM1.9 (A5), U11.9 (Y5)
MA5: RM1.11 (A6), U11.7 (Y6)
MA6: RM1.13 (A7), U11.5 (Y7)
MA7: RM1.15 (A8), U11.3 (Y8)
MA8: RM2.1 (A1), U12.18 (Y1)
MA9: RM2.3 (A2), U12.16 (Y2)
MA10: RM2.5 (A3), U12.14 (Y3)
MA11: RM2.7 (A4), U12.12 (Y4)
MA12: RM2.9 (A5), U12.9 (Y5)
MA13: RM2.11 (A6), U12.7 (Y6)
MA14: RM2.13 (A7), U12.5 (Y7)
MA15: RM2.15 (A8), U12.3 (Y8)
MD0: RM3.1 (A1), U13.18 (Y1)
MD1: RM3.3 (A2), U13.16 (Y2)
MD2: RM3.5 (A3), U13.14 (Y3)
MD3: RM3.7 (A4), U13.12 (Y4)
MD4: RM3.9 (A5), U13.9 (Y5)
MD5: RM3.11 (A6), U13.7 (Y6)
MD6: RM3.13 (A7), U13.5 (Y7)
MD7: RM3.15 (A8), U13.3 (Y8)
ML0_0: LM1.1 (A1), RM1.2 (B1)
ML0_1: LM1.2 (A2), RM1.4 (B2)
ML0_2: LM1.3 (A3), RM1.6 (B3)
ML0_3: LM1.4 (A4), RM1.8 (B4)
ML0_4: LM1.5 (A5), RM1.10 (B5)
ML0_5: LM1.6 (A6), RM1.12 (B6)
ML0_6: LM1.7 (A7), RM1.14 (B7)
ML0_7: LM1.8 (A8), RM1.16 (B8)
ML1_0: LM2.1 (A1), RM2.2 (B1)
ML1_1: LM2.2 (A2), RM2.4 (B2)
ML1_2: LM2.3 (A3), RM2.6 (B3)
ML1_3: LM2.4 (A4), RM2.8 (B4)
ML1_4: LM2.5 (A5), RM2.10 (B5)
ML1_5: LM2.6 (A6), RM2.12 (B6)
ML1_6: LM2.7 (A7), RM2.14 (B7)
ML1_7: LM2.8 (A8), RM2.16 (B8)
ML2_0: LM3.1 (A1), RM3.2 (B1)
ML2_1: LM3.2 (A2), RM3.4 (B2)
ML2_2: LM3.3 (A3), RM3.6 (B3)
ML2_3: LM3.4 (A4), RM3.8 (B4)
ML2_4: LM3.5 (A5), RM3.10 (B5)
ML2_5: LM3.6 (A6), RM3.12 (B6)
ML2_6: LM3.7 (A7), RM3.14 (B7)
ML2_7: LM3.8 (A8), RM3.16 (B8)
P2P: U6.4 (2A), U15.6 (2Y)
RTCCE: J3.1, U16.5 (CE)
RTCIO: J3.3, U16.6 (IO)
RTCSCLK: J3.2, U16.7 (SCLK)
RTCX1: U16.2 (X1), X3.1
RTCX2: U16.3 (X2), X3.2
RXD: U8.12 (R1OUT), U14.2 (RXD)
SELP: R4.2, U6.8 (3Y)
SIN: J2.2, U8.13 (R1IN)
SOUT: J2.1, U8.14 (T1OUT)
SWN0: RNP.2 (R1), SW1.1 (A1), U9.2 (A1)
SWN1: RNP.3 (R2), SW1.2 (A2), U9.4 (A2)
SWN2: RNP.4 (R3), SW1.3 (A3), U9.6 (A3)
SWN3: RNP.5 (R4), SW1.4 (A4), U9.8 (A4)
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

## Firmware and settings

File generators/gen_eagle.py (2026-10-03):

#!/usr/bin/env python3
"""P8X Eagle generator. Emits schematic+board pairs for all 7 boards, each in its
own subdirectory:
  backplane/p8x-backplane.sch/.brd      (rev C, NSLOT slots; KiCad build is the routed one)
  memory-card/p8x-memory-card.sch/.brd  (rev C, placed + planes, signals unrouted)
  control-card/p8x-control-card.sch/.brd
  regbank-card/p8x-regbank-card.sch/.brd
  alu-card/p8x-alu-card.sch/.brd
  io-card/p8x-io-card.sch/.brd
  cf-card/p8x-cf-card.sch/.brd
Board stack: Top(1) signals / Route2(2) GND plane / Route15(15) +5V plane / Bottom(16) signals.
Output: each board's .sch/.brd pair goes in its own subdirectory of the current
working directory (e.g. control-card/p8x-control-card.sch), so run from hardware/.
NOTE: new device pin numbers require a datasheet verification pass before fab (tracked in BACKLOG)."""

import os
G=2.54; PIN_X=17.78; STUB=5.08

# ===================== BUS =====================================================
def busnet(pin):
    r,n=pin[0],int(pin[1:])
    if n in (1,2): return "VCC"
    if n in (31,32): return "GND"
    if r=="B":
        if n in (27,28,29,30): return {27:"CLRC",28:"BSEL",29:"IRQ",30:"SPARE11"}[n]
        # B3-26: alternate ground guard (odd pins) / spare line (even pins). The
        # odd-pin grounds still shield between the data bus (row A) and address
        # bus (row C); the 12 even pins are SPARE12..23 — usable later with no
        # backplane respin.
        if 3<=n<=26 and n%2==0: return "SPARE%d"%(12+(n-4)//2)
        return "GND"
    if r=="A":
        if 3<=n<=10: return "D%d"%(n-3)
        if n==11: return "-RES"
        if 12<=n<=15: return "DOE%d"%(n-12)
        if 16<=n<=19: return "DLD%d"%(n-16)
        return {20:"PSEL0",21:"PSEL1",22:"PINC",23:"PDEC",24:"CLK",25:"CLKB",26:"LDF",
                27:"FC",28:"FZ",29:"FN",30:"FV"}.get(n)
    if 3<=n<=18: return "A%d"%(n-3)
    if 19<=n<=22: return "ALUS%d"%(n-19)
    # rev C3: C27-30 + B27 carry the rev-B control signals. B28=BSEL (rev C: ALU
    # B-input mux select); B29=IRQ (rev C, reserved for the interrupt controller);
    # SPARE11 remains on B30
    return {23:"ALUM",24:"CIN",25:"SH0",26:"SH1",
            27:"PSEL2",28:"LDZN",29:"SHCIN",30:"SETC"}.get(n,"SPARE%d"%(n-27+4))

ALLPINS=["%s%d"%(r,n) for r in "ABC" for n in range(1,33)]

# Only write/validate the .sch/.brd files when this module is RUN directly.
# Importing it (renderers use busnet/DEV/CARDS) must have NO filesystem side
# effects — otherwise an `import gen_eagle` from any CWD scatters board files.
# The net/CARDS data is still built on import; only the file emission is gated.
EMIT = (__name__ == "__main__")

# ===================== PACKAGES ================================================
def dip_pads(n,rowsep):
    half=n//2; p=[]
    for k in range(1,n+1):
        if k<=half: x,y=0,-G*(k-1)
        else: x,y=rowsep,-G*(n-k)
        p.append((str(k),x,y,0.8128,1.6))
    return p

PKG={
 "DIP8":  dip_pads(8,7.62),
 "DIP14": dip_pads(14,7.62), "DIP16": dip_pads(16,7.62),
 "DIP20": dip_pads(20,7.62), "DIP24W": dip_pads(24,15.24),
 "DIP28W": dip_pads(28,15.24), "DIP40": dip_pads(40,15.24),  # 600-mil DIP-40 (ATmega1284P)
 # 300-mil skinny DIP-28. NOT interchangeable with DIP28W (600 mil): the
 # MCP23S17-E/SP is SPDIP, so DIP28W would leave it unable to reach its pads.
 "DIP28N": dip_pads(28,7.62),
 # Pico module on 2x20 headers: 0.1" pitch, rows 0.7" (17.78 mm) apart.
 # dip_pads numbering matches the board: 1-20 down the left, 21-40 up the right.
 "PICO40": dip_pads(40,17.78),
 # DIN 41612 96-pin footprints from Eagle's con-vg library (geometry baked in so
 # the generator stays self-contained). Rows A/B/C at x=-2.54/0/+2.54, 32 positions
 # from y=+39.37 at 2.54mm pitch; octagon pads drill 0.9144 (round here — cosmetic);
 # two mounting holes at x=-0.3048, y=±45.0, drill 2.794. Backplane = FABC96S
 # (female vertical), card = MABC96R (male right-angle); both share this pad map.
 "FABC96S": [(pin,{"A":-2.54,"B":0.0,"C":2.54}[pin[0]],39.37-G*(int(pin[1:])-1),0.9144,1.524) for pin in ALLPINS]
            + [("MH1",-0.3048,45.0,2.794,2.794),("MH2",-0.3048,-45.0,2.794,2.794)],
 "MABC96R": [(pin,{"A":-2.54,"B":0.0,"C":2.54}[pin[0]],39.37-G*(int(pin[1:])-1),0.9144,1.524) for pin in ALLPINS]
            + [("MH1",-0.3048,45.0,2.794,2.794),("MH2",-0.3048,-45.0,2.794,2.794)],
 "SIP9":  [(str(k),0,-G*(k-1),0.8,1.6) for k in range(1,10)],
 "SIP16": [(str(k),0,-2.54*k,0.8,1.6) for k in range(1,17)],
 "R_AXIAL": [("1",0,0,0.8,1.6),("2",10.16,0,0.8,1.6)],
 "C_DISC":  [("1",0,0,0.9,1.8),("2",0,-5.08,0.9,1.8)],   # 0.2" (5.08mm) lead pitch
 "C_DISC1": [("1",0,0,0.9,1.8),("2",0,-2.54,0.9,1.8)],   # 0.1" (2.54mm) lead pitch — 100nF bypass caps
 "CP_RADIAL":[("1",0,0,0.9,1.8),("2",0,-5.08,0.9,1.8)],
 "TB4":  [(str(k+1),0,-5.08*k,1.3,3.0) for k in range(4)],
 "LED5": [("2",0,0,0.9,1.8),("1",2.54,0,0.9,1.8)],
 "OSC4": [("1",0,0,0.8,1.6),("7",0,-15.24,0.8,1.6),("8",7.62,-15.24,0.8,1.6),("14",7.62,0,0.8,1.6)],
 "HDR4": [(str(k+1),0,-2.54*k,0.9,1.8) for k in range(4)],
 "HDR3": [(str(k+1),0,-2.54*k,0.9,1.8) for k in range(3)],
 "SW2P": [("1",0,0,1.0,1.9),("2",5.08,0,1.0,1.9)],
 "HDR40": [(str(k+1),2.54*(k%2),-2.54*(k//2),0.9,1.7) for k in range(40)],
 "HDR10": [(str(k+1),2.54*(k%2),-2.54*(k//2),0.9,1.7) for k in range(10)],
 # peripheral-card connectors (stage 2). DSUB9 = DE9 pin pattern (5 top / 4 bottom
 # staggered); HDR2X3 = 2col x 3row (row-major, left col = 1,3,5); MINIDIN6 = a
 # 1x6 header stand-in for the PS/2 socket (SUB -- real MiniDIN-6 land later).
 "DSUB9": [(str(k),2.77*(k-1),0,1.0,2.0) for k in range(1,6)]
        + [(str(k),2.77*(k-6)+1.385,-2.84,1.0,2.0) for k in range(6,10)],
 "HDR2X3": [(str(k+1),2.54*(k%2),-2.54*(k//2),0.9,1.7) for k in range(6)],
 "MINIDIN6": [(str(k+1),0,-2.54*k,0.9,1.8) for k in range(6)],
}

# Extra silkscreen geometry per package, beyond the standard >NAME/>VALUE text.
# Layer 21 = tPlace (top silkscreen). CP_RADIAL gets a '+' beside pad 1 (the
# positive pin, pm "+"->"1") so electrolytic / coin-cell polarity is on the board.
PKG_SILK={
 "CP_RADIAL":[
   '<wire x1="1.90" y1="0" x2="3.30" y2="0" width="0.3048" layer="21"/>',
   '<wire x1="2.60" y1="-0.70" x2="2.60" y2="0.70" width="0.3048" layer="21"/>'],
}

# ===================== DEVICES =================================================
def gates14():
    return dict(L=["1A","1B","2A","2B","3A","3B","4A","4B"],
                R=["1Y","2Y","3Y","4Y","VCC","GND"],
                pm={"1A":"1","1B":"2","1Y":"3","2A":"4","2B":"5","2Y":"6","GND":"7",
                    "3Y":"8","3A":"9","3B":"10","4Y":"11","4A":"12","4B":"13","VCC":"14"},pkg="DIP14")

DEV={
 "MEM28K8": dict(L=["A%d"%i for i in range(15)],
   R=["IO%d"%i for i in range(8)]+["!CE","!OE","!WE","VCC","GND"],
   pm={"A14":"1","A12":"2","A7":"3","A6":"4","A5":"5","A4":"6","A3":"7","A2":"8","A1":"9","A0":"10",
       "IO0":"11","IO1":"12","IO2":"13","GND":"14","IO3":"15","IO4":"16","IO5":"17","IO6":"18","IO7":"19",
       "!CE":"20","A10":"21","!OE":"22","A11":"23","A9":"24","A8":"25","A13":"26","!WE":"27","VCC":"28"},
   pkg="DIP28W"),
 "74245": dict(L=["DIR"]+["A%d"%i for i in range(8)]+["!OE"],
   R=["B%d"%i for i in range(8)]+["VCC","GND"],
   pm={"DIR":"1","A0":"2","A1":"3","A2":"4","A3":"5","A4":"6","A5":"7","A6":"8","A7":"9","GND":"10",
       "B7":"11","B6":"12","B5":"13","B4":"14","B3":"15","B2":"16","B1":"17","B0":"18","!OE":"19","VCC":"20"},
   pkg="DIP20"),
 "7430": dict(L=list("ABCDEFGH"),R=["Y","VCC","GND"],
   pm={"A":"1","B":"2","C":"3","D":"4","E":"5","F":"6","GND":"7","Y":"8","G":"11","H":"12","VCC":"14"},pkg="DIP14"),
 "74138": dict(L=["A","B","C","G1","!G2A","!G2B"],
   R=["Y%d"%i for i in range(8)]+["VCC","GND"],
   pm={"A":"1","B":"2","C":"3","!G2A":"4","!G2B":"5","G1":"6","Y7":"7","GND":"8","Y6":"9","Y5":"10",
       "Y4":"11","Y3":"12","Y2":"13","Y1":"14","Y0":"15","VCC":"16"},pkg="DIP16"),
 "GATES14": gates14(),
 "DIN96": dict(L=["A%d"%i for i in range(1,33)]+["B%d"%i for i in range(1,33)],
   R=["C%d"%i for i in range(1,33)],pm={p:p for p in ALLPINS},pkg="FABC96S"),
 "CAP":  dict(L=["1"],R=["2"],pm={"1":"1","2":"2"},pkg="C_DISC"),
 # 100nF bypass/decoupling caps: identical symbol to CAP, but 0.1" lead pitch.
 "CAP1": dict(L=["1"],R=["2"],pm={"1":"1","2":"2"},pkg="C_DISC1"),
 "CAPP": dict(L=["+"],R=["-"],pm={"+":"1","-":"2"},pkg="CP_RADIAL"),
 # rev C RTC (DS1302, DIP8) + its 32.768kHz tuning-fork crystal and backup coin
 # cell. XTAL32/COIN reuse generic 2-pin THT footprints as placeholders — VERIFY
 # the physical land pattern against the parts you buy before fab.
 "DS1302": dict(L=["X1","X2","CE","IO","SCLK"],R=["VCC2","GND","VCC1"],
   pm={"VCC2":"1","X1":"2","X2":"3","GND":"4","CE":"5","IO":"6","SCLK":"7","VCC1":"8"},pkg="DIP8"),
 "XTAL32": dict(L=["1"],R=["2"],pm={"1":"1","2":"2"},pkg="C_DISC"),
 "COIN":   dict(L=["+"],R=["-"],pm={"+":"1","-":"2"},pkg="CP_RADIAL"),
 "RES":  dict(L=["1"],R=["2"],pm={"1":"1","2":"2"},pkg="R_AXIAL"),
 "SIP9": dict(L=["COM"],R=["R%d"%i for i in range(1,9)],
   pm=dict([("COM","1")]+[("R%d"%i,str(i+1)) for i in range(1,9)]),pkg="SIP9"),
 "TB4":  dict(L=["1","2"],R=["3","4"],pm={str(k):str(k) for k in range(1,5)},pkg="TB4"),
 "LED":  dict(L=["A"],R=["K"],pm={"A":"2","K":"1"},pkg="LED5"),
}

def D(name,L,R,pm,pkg): DEV[name]=dict(L=L,R=R,pm=pm,pkg=pkg)

# Card edge connector: same electrical part as the backplane DIN96, but the
# MABC96R (male right-angle) footprint instead of FABC96S (female vertical).
DEV["DIN96C"]={**DEV["DIN96"],"pkg":"MABC96R"}

D("74161",["!CLR","CLK","A","B","C","D","ENP","!LOAD","ENT"],
  ["QA","QB","QC","QD","RCO","VCC","GND"],
  {"!CLR":"1","CLK":"2","A":"3","B":"4","C":"5","D":"6","ENP":"7","GND":"8","!LOAD":"9",
   "ENT":"10","QD":"11","QC":"12","QB":"13","QA":"14","RCO":"15","VCC":"16"},"DIP16")
D("74169",["UD","CLK","A","B","C","D","!ENP","!LOAD","!ENT"],
  ["QA","QB","QC","QD","!RCO","VCC","GND"],
  {"UD":"1","CLK":"2","A":"3","B":"4","C":"5","D":"6","!ENP":"7","GND":"8","!LOAD":"9",
   "!ENT":"10","QD":"11","QC":"12","QB":"13","QA":"14","!RCO":"15","VCC":"16"},"DIP16")
PM374={"!OC":"1","Q1":"2","D1":"3","D2":"4","Q2":"5","Q3":"6","D3":"7","D4":"8","Q4":"9",
 "GND":"10","CLK":"11","Q5":"12","D5":"13","D6":"14","Q6":"15","Q7":"16","D7":"17","D8":"18",
 "Q8":"19","VCC":"20"}
D("74374",["!OC","CLK"]+["D%d"%i for i in range(1,9)],
  ["Q%d"%i for i in range(1,9)]+["VCC","GND"],PM374,"DIP20")
PM377=dict(PM374); PM377["!E"]=PM377.pop("!OC")
D("74377V2",["!E","CLK"]+["D%d"%i for i in range(1,9)],
  ["Q%d"%i for i in range(1,9)]+["VCC","GND"],PM377,"DIP20")
D("74151",["A","B","C"]+["D%d"%i for i in range(8)]+["!G"],
  ["Y","!W","VCC","GND"],
  {"D3":"1","D2":"2","D1":"3","D0":"4","Y":"5","!W":"6","!G":"7","GND":"8","C":"9","B":"10",
   "A":"11","D7":"12","D6":"13","D5":"14","D4":"15","VCC":"16"},"DIP16")
D("HEX14",["1A","2A","3A","4A","5A","6A"],["1Y","2Y","3Y","4Y","5Y","6Y","VCC","GND"],
  {"1A":"1","1Y":"2","2A":"3","2Y":"4","3A":"5","3Y":"6","GND":"7","4Y":"8","4A":"9",
   "5Y":"10","5A":"11","6Y":"12","6A":"13","VCC":"14"},"DIP14")
D("7474",["!1CLR","1D","1CLK","!1PRE","!2CLR","2D","2CLK","!2PRE"],
  ["1Q","!1Q","2Q","!2Q","VCC","GND"],
  {"!1CLR":"1","1D":"2","1CLK":"3","!1PRE":"4","1Q":"5","!1Q":"6","GND":"7","!2Q":"8",
   "2Q":"9","!2PRE":"10","2CLK":"11","2D":"12","!2CLR":"13","VCC":"14"},"DIP14")
D("7402",["1A","1B","2A","2B","3A","3B","4A","4B"],["1Y","2Y","3Y","4Y","VCC","GND"],
  {"1Y":"1","1A":"2","1B":"3","2Y":"4","2A":"5","2B":"6","GND":"7","3A":"8","3B":"9",
   "3Y":"10","4A":"11","4B":"12","4Y":"13","VCC":"14"},"DIP14")
D("7410",["1A","1B","1C","2A","2B","2C","3A","3B","3C"],["1Y","2Y","3Y","VCC","GND"],
  {"1A":"1","1B":"2","2A":"3","2B":"4","2C":"5","2Y":"6","GND":"7","3Y":"8","3A":"9",
   "3B":"10","3C":"11","1Y":"12","1C":"13","VCC":"14"},"DIP14")
D("28C64",["A%d"%i for i in range(13)],
  ["IO%d"%i for i in range(8)]+["!CE","!OE","!WE","RDY","NC26","VCC","GND"],
  {"RDY":"1","A12":"2","A7":"3","A6":"4","A5":"5","A4":"6","A3":"7","A2":"8","A1":"9",
   "A0":"10","IO0":"11","IO1":"12","IO2":"13","GND":"14","IO3":"15","IO4":"16","IO5":"17",
   "IO6":"18","IO7":"19","!CE":"20","A10":"21","!OE":"22","A11":"23","A9":"24","A8":"25",
   "NC26":"26","!WE":"27","VCC":"28"},"DIP28W")
D("74139",["!G1","A1","B1","!G2","A2","B2"],
  ["1Y0","1Y1","1Y2","1Y3","2Y0","2Y1","2Y2","2Y3","VCC","GND"],
  {"!G1":"1","A1":"2","B1":"3","1Y0":"4","1Y1":"5","1Y2":"6","1Y3":"7","GND":"8",
   "2Y3":"9","2Y2":"10","2Y1":"11","2Y0":"12","B2":"13","A2":"14","!G2":"15","VCC":"16"},"DIP16")
D("74257",["S","A1","B1","A2","B2","A3","B3","A4","B4","!OE"],
  ["Y1","Y2","Y3","Y4","VCC","GND"],
  {"S":"1","A1":"2","B1":"3","Y1":"4","A2":"5","B2":"6","Y2":"7","GND":"8","Y3":"9",
   "B3":"10","A3":"11","Y4":"12","B4":"13","A4":"14","!OE":"15","VCC":"16"},"DIP16")
D("74244",["!G1","A1","A2","A3","A4","!G2","A5","A6","A7","A8"],
  ["Y1","Y2","Y3","Y4","Y5","Y6","Y7","Y8","VCC","GND"],
  {"!G1":"1","A1":"2","Y8":"3","A2":"4","Y7":"5","A3":"6","Y6":"7","A4":"8","Y5":"9",
   "GND":"10","A5":"11","Y4":"12","A6":"13","Y3":"14","A7":"15","Y2":"16","A8":"17",
   "Y1":"18","!G2":"19","VCC":"20"},"DIP20")
D("74157",["S","A1","B1","A2","B2","A3","B3","A4","B4","!G"],
  ["Y1","Y2","Y3","Y4","VCC","GND"],
  {"S":"1","A1":"2","B1":"3","Y1":"4","A2":"5","B2":"6","Y2":"7","GND":"8","Y3":"9",
   "B3":"10","A3":"11","Y4":"12","B4":"13","A4":"14","!G":"15","VCC":"16"},"DIP16")
D("74175",["!CLR","CLK","D1","D2","D3","D4"],
  ["Q1","!Q1","Q2","!Q2","Q3","!Q3","Q4","!Q4","VCC","GND"],
  {"!CLR":"1","Q1":"2","!Q1":"3","D1":"4","D2":"5","!Q2":"6","Q2":"7","GND":"8","CLK":"9",
   "Q3":"10","!Q3":"11","D3":"12","D4":"13","!Q4":"14","Q4":"15","VCC":"16"},"DIP16")
D("74260",["A1","B1","C1","D1","E1","A2","B2","C2","D2","E2"],["Y1","Y2","VCC","GND"],
  # SN74x260 datasheet pinout (the input/output split is non-obvious):
  #   1=1A 2=1B 3=2A 4=2B 5=2C 6=2Y 7=GND 8=1Y 9=2D 10=2E 11=1C 12=1D 13=1E 14=VCC
  {"A1":"1","B1":"2","A2":"3","B2":"4","C2":"5","Y2":"6","GND":"7","Y1":"8","D2":"9",
   "E2":"10","C1":"11","D1":"12","E1":"13","VCC":"14"},"DIP14")
D("74181",["A0","B0","A1","B1","A2","B2","A3","B3","S0","S1","S2","S3","M","CN"],
  ["F0","F1","F2","F3","CN4","!P","!G","AEB","VCC","GND"],
  {"B0":"1","A0":"2","S3":"3","S2":"4","S1":"5","S0":"6","CN":"7","M":"8","F0":"9",
   "F1":"10","F2":"11","GND":"12","F3":"13","AEB":"14","!P":"15","CN4":"16","!G":"17",
   "B3":"18","A3":"19","B2":"20","A2":"21","B1":"22","A1":"23","VCC":"24"},"DIP24W")
D("74182",["!P0","!G0","!P1","!G1","!P2","!G2","!P3","!G3","CN"],
  ["CNX","CNY","CNZ","!P","!G","VCC","GND"],
  {"!G1":"1","!P1":"2","!G0":"3","!P0":"4","!G3":"5","!P3":"6","!P":"7","GND":"8",
   "CNZ":"9","!G":"10","CNY":"11","CNX":"12","CN":"13","!P2":"14","!G2":"15","VCC":"16"},"DIP16")
D("6850",["D%d"%i for i in range(8)]+["CS0","CS1","!CS2","RS","RW","E"],
  ["TXD","RXD","TXCLK","RXCLK","!RTS","!CTS","!DCD","!IRQ","VCC","GND"],
  {"GND":"1","RXD":"2","RXCLK":"3","TXCLK":"4","!RTS":"5","TXD":"6","!IRQ":"7","CS0":"8",
   "!CS2":"9","CS1":"10","RS":"11","VCC":"12","RW":"13","E":"14","D7":"15","D6":"16",
   "D5":"17","D4":"18","D3":"19","D2":"20","D1":"21","D0":"22","!DCD":"23","!CTS":"24"},"DIP24W")
D("MAX232",["C1P","C1M","C2P","C2M","T1IN","T2IN","R1OUT","R2OUT"],
  ["VP","VM","T1OUT","T2OUT","R1IN","R2IN","VCC","GND"],
  {"C1P":"1","VP":"2","C1M":"3","C2P":"4","C2M":"5","VM":"6","T2OUT":"7","R2IN":"8",
   "R2OUT":"9","T2IN":"10","T1IN":"11","R1OUT":"12","R1IN":"13","T1OUT":"14","GND":"15",
   "VCC":"16"},"DIP16")
D("OSC",["NC1"],["OUT","VCC","GND"],{"NC1":"1","GND":"7","OUT":"8","VCC":"14"},"OSC4")
D("HDR4",["1","2","3","4"],[],{str(k):str(k) for k in range(1,5)},"HDR4")
D("HDR3",["1","2","3"],[],{str(k):str(k) for k in range(1,4)},"HDR3")
D("SW2",["1"],["2"],{"1":"1","2":"2"},"SW2P")
D("DIP8SW",["A%d"%i for i in range(1,9)],["B%d"%i for i in range(1,9)],
  dict([("A%d"%i,str(i)) for i in range(1,9)]+[("B%d"%i,str(17-i)) for i in range(1,9)]),"DIP16")
D("RNISO8",["A%d"%i for i in range(1,9)],["B%d"%i for i in range(1,9)],
  dict([("A%d"%i,str(2*i-1)) for i in range(1,9)]+[("B%d"%i,str(2*i)) for i in range(1,9)]),"SIP16")
# Same electrical part as RNISO8 (8 isolated resistors) but in a 16-pin DIP: R_i
# between pin i and pin (17-i), the standard isolated-DIP-network pinout (same as
# DIP8SW / LEDARR8). Used for LED-current-limit and other 8-way isolated banks.
D("RNISO8D",["A%d"%i for i in range(1,9)],["B%d"%i for i in range(1,9)],
  dict([("A%d"%i,str(i)) for i in range(1,9)]+[("B%d"%i,str(17-i)) for i in range(1,9)]),"DIP16")
D("LEDARR8",["A%d"%i for i in range(1,9)],["K%d"%i for i in range(1,9)],
  dict([("A%d"%i,str(i)) for i in range(1,9)]+[("K%d"%i,str(17-i)) for i in range(1,9)]),"DIP16")
D("IDE40",[str(k) for k in range(1,41,2)],[str(k) for k in range(2,41,2)],
  {str(k):str(k) for k in range(1,41)},"HDR40")
# ---- peripheral-card connectors + MCU (stage 2) -----------------------------
D("DSUB9F",[str(k) for k in range(1,10)],[],{str(k):str(k) for k in range(1,10)},"DSUB9")  # DB9 female (socket)
D("MINIDIN6",[str(k) for k in range(1,7)]+["SH"],[],{**{str(k):str(k) for k in range(1,7)},"SH":"SH"},"MINIDIN6")  # PS/2 mini-DIN-6 (+ shield tabs)
D("JMP2X3",[str(k) for k in range(1,7)],[],{str(k):str(k) for k in range(1,7)},"HDR2X3")    # RX/TX swap block
# ATmega328P (DIP-28 narrow): PS/2 signal processor. Standard AVR DIP pinout.
D("ATMEGA328",
  ["!RESET","PD0","PD1","PD2","PD3","PD4","PB6","PB7","PD5","PD6","PD7",
   "PB0","PB1","PB2","PB3","PB4","PB5","AREF","PC0","PC1","PC2","PC3","PC4","PC5"],
  ["VCC","AVCC","GND","GND2"],
  {"!RESET":"1","PD0":"2","PD1":"3","PD2":"4","PD3":"5","PD4":"6","VCC":"7","GND":"8",
   "PB6":"9","PB7":"10","PD5":"11","PD6":"12","PD7":"13","PB0":"14","PB1":"15","PB2":"16",
   "PB3":"17","PB4":"18","PB5":"19","AVCC":"20","AREF":"21","GND2":"22","PC0":"23","PC1":"24",
   "PC2":"25","PC3":"26","PC4":"27","PC5":"28"},"DIP28N")
# 74HC688 8-bit magnitude comparator -- the PS/2 window ($FF58-5F) address compare.
D("74688",["!G","P0","Q0","P1","Q1","P2","Q2","P3","Q3","Q4","P4","Q5","P5","Q6","P6","Q7","P7"],
  ["!PEQ","VCC","GND"],
  {"!G":"1","P0":"2","Q0":"3","P1":"4","Q1":"5","P2":"6","Q2":"7","P3":"8","Q3":"9","GND":"10",
   "Q4":"11","P4":"12","Q5":"13","P5":"14","Q6":"15","P6":"16","Q7":"17","P7":"18","!PEQ":"19","VCC":"20"},"DIP20")
# ATmega1284P (PDIP-40, 0.6"): PS/2 signal processor. 32 GPIO (4 full ports) leaves
# ~12 spare after the bus bridge -- enough to drive the status LEDs straight off the
# MCU and leave room for host->device TX + an IRQ line (no 74123 one-shot needed).
# SPI/ICSP is on PB5(MOSI)/PB6(MISO)/PB7(SCK). Internal RC osc -> XTAL pins unused.
D("ATMEGA1284",
  ["PB0","PB1","PB2","PB3","PB4","PB5","PB6","PB7","!RESET","XTAL2","XTAL1",
   "PD0","PD1","PD2","PD3","PD4","PD5","PD6","PD7","PC0","PC1","PC2","PC3","PC4","PC5",
   "PC6","PC7","AREF","PA7","PA6","PA5","PA4","PA3","PA2","PA1","PA0"],
  ["VCC","GND","AVCC","GND2"],
  {"PB0":"1","PB1":"2","PB2":"3","PB3":"4","PB4":"5","PB5":"6","PB6":"7","PB7":"8",
   "!RESET":"9","VCC":"10","GND":"11","XTAL2":"12","XTAL1":"13","PD0":"14","PD1":"15",
   "PD2":"16","PD3":"17","PD4":"18","PD5":"19","PD6":"20","PD7":"21","PC0":"22","PC1":"23",
   "PC2":"24","PC3":"25","PC4":"26","PC5":"27","PC6":"28","PC7":"29","AVCC":"30","GND2":"31",
   "AREF":"32","PA7":"33","PA6":"34","PA5":"35","PA4":"36","PA3":"37","PA2":"38","PA1":"39",
   "PA0":"40"},"DIP40")

# ---- bustest-card parts -----------------------------------------------------
# MCP23S17: 16-bit SPI I/O expander, per-pin direction + per-pin pull-up, 5 V.
# Pinout verified against the Microchip datasheet (DS20001952): GPB0-7 = 1-8,
# VDD 9, VSS 10, CS 11, SCK 12, SI 13, SO 14, A0-2 = 15-17, RESET 18, INTB 19,
# INTA 20, GPA0-7 = 21-28. Package is SPDIP (300 mil) -> DIP28N, NOT DIP28W.
D("MCP23S17",
  ["!CS","SCK","SI","A0","A1","A2","!RESET"],
  ["GPA%d"%i for i in range(8)]+["GPB%d"%i for i in range(8)]+["SO","!INTA","!INTB","VDD","VSS"],
  dict([("GPB%d"%i,str(i+1)) for i in range(8)]
     + [("VDD","9"),("VSS","10"),("!CS","11"),("SCK","12"),("SI","13"),("SO","14"),
        ("A0","15"),("A1","16"),("A2","17"),("!RESET","18"),("!INTB","19"),("!INTA","20")]
     + [("GPA%d"%i,str(i+21)) for i in range(8)]),
  "DIP28N")

# Raspberry Pi Pico (RP2040) as a socketed 2x20 module. Power pins verified
# against the official pinout: VBUS 40, VSYS 39, 3V3_EN 37, 3V3(OUT) 36,
# AGND 33, GND 3/8/13/18/23/28/38, pin 1 = GP0.
D("PICO",
  ["VBUS","VSYS","!RUN","3V3EN"],
  ["GP%d"%i for i in range(23)]+["GP26","GP27","GP28","3V3OUT","ADCVREF","AGND","GND"],
  dict([("GP0","1"),("GP1","2"),("GND","3"),("GP2","4"),("GP3","5"),("GP4","6"),
        ("GP5","7"),("GP6","9"),("GP7","10"),("GP8","11"),("GP9","12"),
        ("GP10","14"),("GP11","15"),("GP12","16"),("GP13","17"),
        ("GP14","19"),("GP15","20"),("GP16","21"),("GP17","22"),
        ("GP18","24"),("GP19","25"),("GP20","26"),("GP21","27"),
        ("GP22","29"),("!RUN","30"),("GP26","31"),("GP27","32"),("AGND","33"),
        ("GP28","34"),("ADCVREF","35"),("3V3OUT","36"),("3V3EN","37"),
        ("VSYS","39"),("VBUS","40")]),
  "PICO40")

# 2x5 probe header: 8 high-Z probe lines + 2 GND, ribbon fanned to grabbers.
D("HDR10",[str(k) for k in range(1,11)],[],{str(k):str(k) for k in range(1,11)},"HDR10")
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

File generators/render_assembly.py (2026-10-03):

#!/usr/bin/env python3
"""render_assembly.py -- 3D render of the assembled P8X: the backplane with every
plug-in card standing in its DIN 41612 slot.

Runs under KiCad 10's bundled Python (it imports pcbnew). Driver:
hardware/assembly/build.sh.

    render_assembly.py [--scratch DIR] [--out DIR] [--quality basic|high] [--reuse]

--reuse keeps card STEPs already in the scratch directory (for trying camera
views; drop it after a board changes).

GENERATORS ARE CANON: the real boards are only READ. Every board is copied into
the scratch directory first; all intermediate files (card STEPs, measurement
STLs, the assembly board) live there. Only the finished PNGs are written to the
output directory (default hardware/assembly/).

How the assembly is put together
--------------------------------
1. Each card is exported as a STEP with its component models, silkscreen and
   solder mask (kicad-cli pcb export step --subst-models).
2. A scratch copy of the backplane gets one extra footprint per slot whose only
   content is that card's STEP as a 3D model. The footprint sits at the board
   origin with no rotation, so the model's (offset, rotate) carry the whole
   card-to-backplane transform.
3. The transform is derived, not placed by eye:
   * X/Y come from the pads (pcbnew): the card's J1 pad a1 must land on the
     slot connector's pad a1, its pin rows a..c on the socket's columns a..c,
     and its pins 1..32 along the socket's pins 1..32. The slot is the backplane
     footprint whose value is "SLOT<n>".
   * The insertion depth comes from the two connector models (STL exports of
     J1 alone, measured below): the card sits fully mated, with the top face
     of the female socket against the inner face of the male connector's
     shroud (the face its pins come out of).
   * The rotation is the one proper rotation (no mirroring) that maps the
     card's "away from the connector edge" direction to the backplane's up
     direction, its pin-1 -> pin-32 direction to the socket's, and its
     row-a -> row-c direction (the card's component-side normal; row a is the
     row nearest the card surface) to the socket's. KiCad's 3D-model rotation
     angles are then solved for that matrix.
4. kicad-cli pcb render draws the assembly board from the VIEWS below.
"""
import argparse, collections, itertools, math, os, shutil, struct, subprocess, sys

ROOT = os.path.abspath(os.path.join(os.path.dirname(__file__), ".."))
CLI = "/Applications/KiCad/KiCad.app/Contents/MacOS/kicad-cli"

# Slot order. No card is tied to a slot electrically (every slot sees the same
# bus); this is the order of the CPU data path, peripherals after it, and the
# bring-up bus test card in the last slot.
SLOTS = [
    (1, "control-card"),
    (2, "regbank-card"),
    (3, "alu-card"),
    (4, "memory-card"),
    (5, "io-card"),
    (6, "cf-card"),
    (7, "ps2-card"),
    (8, "bustest-card"),
]

# Camera views: (file name, kicad-cli render arguments). The pivot (the point
# the camera turns about) is set to the middle of the card cage in main().
VIEWS = [
    ("p8x-assembly-render.png",        # 3/4 view from above, onto the component sides
     ["--rotate", "-45,0,-20", "--zoom", "0.68", "--perspective", "--floor",
      "-w", "2400", "-h", "1600"]),
    ("p8x-assembly-render-low.png",    # low view along the slots: connectors and seating
     ["--rotate", "-65,0,-25", "--zoom", "0.72", "--perspective", "-w", "2400", "-h", "1600"]),
    ("p8x-assembly-render-side.png",   # orthographic elevation looking along the sockets
     ["--rotate", "-90,0,0", "--zoom", "0.8", "-w", "1800", "-h", "1600"]),
]
RENDER = ["--background", "opaque"]


def run(*args):
    r = subprocess.run(args, stdout=subprocess.PIPE, stderr=subprocess.STDOUT, text=True)
    if r.returncode != 0:
        sys.exit("command failed: %s\n%s" % (" ".join(args), r.stdout[-2000:]))
    return r.stdout


# ---------------------------------------------------------------- STL geometry
def read_stl(fn):
    """Triangles of an STL file (binary or ASCII) as [(v0, v1, v2), ...]."""
    d = open(fn, "rb").read()
    pts = []
    if d[:5] == b"solid" and b"facet" in d[:400]:
        for line in d.decode().splitlines():
            line = line.strip()
            if line.startswith("vertex"):
                pts.append(tuple(map(float, line.split()[1:4])))
    else:
        n = struct.unpack("<I", d[80:84])[0]
        for i in range(n):
            v = struct.unpack("<12f", d[84 + i * 50:84 + i * 50 + 48])
            pts += [v[3:6], v[6:9], v[9:12]]
    return [pts[i:i + 3] for i in range(0, len(pts), 3)]


def planar_faces(tris, axis):
    """Triangles lying in a plane perpendicular to `axis`, grouped by position."""
    faces = collections.defaultdict(list)
    for t in tris:
        a = [v[axis] for v in t]
        if max(a) - min(a) < 1e-3:
            faces[round(a[0], 3)].append(t)
    return faces


def extent(tris, axis):
    a = [v[axis] for t in tris for v in t]
    return min(a), max(a)


def export_j1_stl(pcb, out):
    run(CLI, "pcb", "export", "stl", "--subst-models", "--no-board-body",
        "--component-filter", "J1", "-f", "-o", out, pcb)
    return read_stl(out)


def measure_male(tris, edge_x):
    """Male right-angle DIN 41612 on a card (STL frame: x = card x, y = -card y,
    z up from the card's underside). Returns (z of the row-a pin axis, x of the
    shroud's inner face)."""
    # Mating pins: the only geometry strictly inside the shroud, between its
    # front face and the face the pins come out of.
    xf = planar_faces(tris, 0)
    beyond = {x: ts for x, ts in xf.items() if x < edge_x + 0.5}
    front = min(beyond)
    # the inner face is pierced by all 96 pins: the most finely meshed one
    inner = max((x for x in beyond if x != front), key=lambda x: len(beyond[x]))
    pinz = [v[2] for t in tris for v in t if front + 0.2 < v[0] < inner - 0.2]
    zmin = min(pinz)
    row_a = [z for z in pinz if z < zmin + 1.0]       # the lowest pin row
    return (min(row_a) + max(row_a)) / 2.0, inner


def measure_female(tris):
    """Vertical female DIN 41612 on the backplane (STL frame). Returns the
    height of its top face above its seating plane (the underside of the
    housing: the lowest horizontal face as wide as the whole housing)."""
    x0, x1 = extent(tris, 0)
    zf = planar_faces(tris, 2)
    seat = min(z for z, ts in zf.items()
               if abs(extent(ts, 0)[0] - x0) < 0.05 and abs(extent(ts, 0)[1] - x1) < 0.05)
    return extent(tris, 2)[1] - seat


# ---------------------------------------------------------------- rotations
def mat_mul(a, b):
    return [[sum(a[i][k] * b[k][j] for k in range(3)) for j in range(3)] for i in range(3)]
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

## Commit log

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2026-06-12 Memory card: ROM/RAM/RD/WR access LEDs replace SEL; traditional schematic PDFs; backlog + standards updates
    - Select LEDs gated with -BOE (real accesses, not idle decode); spare U8/U9 gates as drivers
    - Standards sec.9 allows finer-grained LED sets; fab checklist updated
    - New traditional-style schematic PDFs + their render scripts (generators/)
    - Backlog: DIN flange holes, board mounting holes, backplane PWR LED placement review
    [p8x-memory-card.brd, p8x-memory-card.sch]
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2026-06-16 chore: regenerate all docs PDFs; fix generator output paths
    All PDF generators were hardcoded to /mnt/user-data/outputs/ (Claude
    sandbox path). Updated each to write to docs/ relative to the repo root
    so they run locally. Also added the missing __main__ entry point to
    render_traditional_auto.py so all five card schematics can be
    regenerated in one pass.
    Regenerated: bus-definition, programmers-guide, backplane-schematic,
    memory-card-schematic, control/regbank/alu/io/cf-card schematics.
    [gen_bus_pdf.py, render_bp_traditional.py, render_traditional_auto.py]
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2026-06-16 chore: merge gen_eagle_full.py and gen_p8x_cards.py into single gen_eagle.py
    Consolidates all Eagle board generation into one file (gen_eagle.py):
    shared library, memory card, backplane, and all 5 plug-in cards.
    Updates render_traditional_auto.py import; removes the two old files.
    All 14 sch/brd files re-validated (0 errors) from hardware/eagle/.
    [p8x-io-card.brd, p8x-io-card.sch]
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2026-06-17 hw(rev B): reg-bank — 3-bit PSEL decode + PT scratch pointer
    Phase 2, step 3. Select decode U33 becomes a 74138 (3-bit PSEL -> -SEL0..4,
    so PSEL=4 no longer aliases to P0); count decode moves to a new 74139
    (U39, P0-P3 only). U40 (74HCT32) gates the P0-P3 load decoder off when
    PSEL2=1 and derives the PT load strobes (-LDL4 = -LDL|-SEL4, etc.). PT
    itself is two 74377 latches (U41/U42) loaded from D0-7, driven onto the
    pointer bus by two 74244 buffers (U43/U44) when -SEL4 — so it reaches the
    address bus and readback path like any pointer. Card retitled REV B.
    Validates clean (pin/pad level; not yet electrically DRC'd).
    [p8x-regbank-card.brd, p8x-regbank-card.sch]
2026-06-17 hw(rev B): ALU conventional-carry inverter; scope flag-reg redesign
    Phase 2, step 4 (partial). The C flag is now conventional active-high:
    the raw 74181 Cn+4 (active-low) is inverted by a spare U25 NAND gate
    before the flag mux, matching the rev-B emulator/microcode.
    The rest of the ALU rev-B work (LDZN independent Z/N latching, SETC/CLRC
    forcing C, and the carry-coupled shifter) is one interlocking flag-
    register redesign — it needs splitting C onto its own flip-flop and
    source/clock muxes, ~6 chips that can only be pin-validated here, not
    DRC'd. Scoped in detail in BACKLOG rather than bolted on unverified.
    Functional behaviour is already proven in the emulator.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
    [p8x-alu-card.brd, p8x-alu-card.sch]
2026-06-17 fix(rev C3): propagate the bus reallocation everywhere it was missed
    Consistency audit caught three places the rev-C3 spare reallocation
    hadn't reached:
    - backplane BOARD routing hardcoded the B-row trace names as SPARE8-11;
    now derived from busnet() so B27's trace is CLRC (matching its pin).
    - backplane-design.md pinout table still showed SPARE4-8 on C27-30/B27;
    updated to PSEL2/LDZN/SHCIN/SETC + CLRC.
    - stale "B27-B30 = SPARE8-11" notes in system-design.md, gen_bus_pdf.py,
    and the render_bp_traditional caption.
    Audit confirmed the rest is self-consistent: ISA tests pass (microcode/
    emulator/assembler agree), all CAD regenerates byte-identical (generators
    canon), the microcode word l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
    [p8x-backplane.brd]
2026-06-17 hw(rev B): ALU flag-register redesign — completes Phase 2
    Splits the flag register so the rev-B controls work in hardware:
    - C flag on its own 7474 (U26), clocked CLK&LDF; SETC/CLRC drive its
    async preset/clear (via U25 NAND inverters + U31 AND with -RES).
    - C source mux (U28/U29 74157): shifted-out bit (F7 if SH0, F0 if SH1)
    when shifting, else the inverted Cn+4 (conventional carry).
    - shifter shift-in mux (U30 74157): current C when SHCIN else CIN.
    - Z/N/V kept in U17 (74175), clocked CLK&(LDF|LDZN); on LDZN their source
    mux U22 selects a 74260 bus zero-detect (U27) and D7 instead of the ALU
    result, so loads set Z/N without disturbing C/V. The unused flag-restore
    (DLD=5) mux wa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
    [p8x-alu-card.brd, p8x-alu-card.sch]
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2026-06-18 hw: per-IC 100nF decoupling caps on every card
    card standards sec.5 requires a decoupling cap per IC; only the backplane had
    them. gen_eagle's card() now generates one 100nF cap (CDn, C_DISC footprint)
    per IC on the five plug-in cards, placed next to its IC and wired VCC<->GND;
    the memory card's separate build does the same for U1-U9.
    Caps added: control 18, regbank 44, alu 31, io 15, cf 8, memory 9. All 7
    boards regenerate with 0 validation errors; card schematic PDFs refreshed.
    Placement is approximate (caps sit just below each IC) pending Fusion routing.
    Clears a pre-fab blocker from the backlog.
    [p8x-alu-card.brd, p8x-alu-card.sch, p8x-cf-card.brd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]
2026-06-18 hw: fix 74260 pinout (ALU zero-detect); datasheet pinout audit
    Audited all ~25 device pin maps in gen_eagle's library against standard
    datasheet pinouts. Found one real error: 74260 (dual 5-input NOR, used as the
    ALU bus zero-detect U27) had a scrambled pin map — gate-1 C1 on pin 3 (should
    be 11) and the Y1/Y2 outputs swapped (6<->8). Corrected to the datasheet
    (1=1A 2=1B 3=2A 4=2B 5=2C 6=2Y 7=GND 8=1Y 9=2D 10=2E 11=1C 12=1D 13=1E 14=VCC);
    netlist uses logical pin names so it's unchanged, and the zero-detect now wires
    to the right pins. All other devices matched. Boards + PDFs regenerated, 0
    validation errors.
    Left a VERIFY note to confirm against physical datasheets before fab.
    Co-Autho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
    [p8x-alu-card.brd, p8x-alu-card.sch]
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2026-06-18 feat(hw): ROM write-protect jumper on memory card (rev C)
    Add a 3-pin select header (JWP, HDR3) in the 28C256 !WE path so the ROM can
    be hardware write-protected after the monitor is stable:
    jumper 1-2 -> -WE (writable, default)
    jumper 2-3 -> VCC (write-protected, !WE held high)
    The 62256 RAM stays on -WE unconditionally, so protecting the ROM does not
    affect RAM writes. Memory card regenerates with 0 validation errors.
    Assembly note: a jumper must be installed (1-2 by default); an open header
    floats the ROM !WE.
    [p8x-memory-card.brd, p8x-memory-card.sch]
2026-06-18 feat: V flag + signed comparison branches (rev C)
    Implement signed overflow (V) and signed-compare branches end to end, so the
    machine can do signed ordering (C alone only gives unsigned).
    Hardware (the old "one 7486 from carry-in vs carry-out of bit 7" plan was not
    feasible: a 74181 4-bit group doesn't expose carry-into-bit-7). Sign-bit method:
    V = (A7 ^ F7) & (A7 ^ B7 ^ ~ALUS2)
    (B7 = muxed B operand, F7 = raw ALU result sign; isADD = ~S2). Ungated by M,
    so V is valid after ADD/SUB/CMP.
    - ALU card: U34 (74HCT86) + U35 (74HCT08) derive V into the flag register
    (was tied low). FV already bused, no bus change.
    - control card: U19 (74HCT86) -> N^V on cond-mux D6; spare U6 OR gate ->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
    [p8x-alu-card.brd, p8x-alu-card.sch, p8x-control-card.brd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]
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2026-06-18 feat(hw): board placement-view PDF renderer (render_board_pdf.py)
    Add a per-board placement PDF for all 7 boards, drawn from the .brd files (real
    board x/y + outline) and the canonical PKG pad geometry, so it can't drift.
    Shows: board outline + dimensions, every footprint (pads with drill holes, pin 1
    as a square pad), reference designators + values, and DNP parts greyed/dashed.
    Pages auto-size to the full part extent; cards whose auto-placed parts spill past
    the board edge get a flagged note (placement is a rough grid -- real arrangement
    happens when routing).
    NOT a routed layout: the generator only places parts + emits the netlist, so
    there is no copper. This is a pre-route sanity check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
    [render_board_pdf.py]
2026-06-18 feat(hw): footprint-aware placement (no component overlaps) + overlap guard
    The old auto-placer used a fixed 13.97x25.4mm grid that was tighter than real
    footprints — tall DIPs collided with the row below and per-IC caps were buried.
    - card(): place by each part's real pad-extent + clearance, flowing in rows that
    wrap at the board width and stack downward (J1 hugs the left edge). Guarantees
    no overlaps. Dense cards (ALU, regbank) now run past the 160x100 outline — they
    genuinely don't fit at safe pitch; arrange by hand when routing (the placement
    PDF flags the overflow).
    - memory card: relocate the 9 decoupling caps to a clear bottom strip (they sat
    under the tall DIP-28W ICs)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
    [p8x-alu-card.brd, p8x-cf-card.brd, p8x-control-card.brd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]
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2026-06-18 fix(bom): card DIN connectors were undercounted (1 -> 6); label them FABC96R
    Two fixes:
    - card() built CARDS[name] from `allp`, which omitted J1 — so the 5 plug-in
    cards' DIN41612 edge connectors never reached the BOM (it showed qty 1, only
    the memory card's J1). Include J1 in allp (the schematic renderer already
    filters J1 by name, so rendering is unchanged). BOM now correctly shows 6 card
    connectors + 10 backplane receptacles.
    - Card edge connector is FABC96R (user-specified): set the value label on every
    card J1 and name it in the BOM; backplane receptacles noted as the mating part.
    Regenerated all boards + PDFs + BOM; all 6 test suites pass.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
    [p8x-alu-card.brd, p8x-alu-card.sch, p8x-bom.csv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]
2026-06-18 feat(hw): card DIN connector mounting holes (DIN96C, standard DIN 41612)
    The card edge connector (FABC96R) needs board mounting holes; the footprint had
    only the 96 signal pins. Split the connector into two packages so cards and the
    backplane don't share holes:
    - DIN96C (card): 96 pins + 2 mounting holes on the centreline (x=2.54), 94.0mm
    apart, drill 2.8mm for M2.5. Emitted as non-plated <hole> elements (new
    lib_xml branch for MH* entries). DEV["DIN96C"] = DIN96 pins, pkg DIN96C.
    - DIN96 (backplane receptacle): pins only, unchanged.
    Card J1 (all 6: 5 plug-in via card() + memory) now uses DIN96C; backplane slots
    keep DIN96. Fixed card() to honor the J1 package on the board side and in CA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
    [p8x-alu-card.brd, p8x-bom.csv, p8x-cf-card.brd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]
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2026-06-19 fix(hardware): connect IC power pins on the card()-built boards
    Schematic-review fix. card() wired the edge-connector and decoupling-cap pins to
    VCC/GND but never added each IC's own VCC/GND supply pin, so on control, regbank,
    ALU, I/O, and CF the chips' power pads were not members of the power pours and
    would not have been powered. (The hand-built memory card already did this; the
    backplane has no ICs. validate() couldn't catch it — it checks pin-name legality,
    not connectivity.)
    - card(): append (ref,"VCC")/(ref,"GND") for every IC, skipping any pin already
    wired by hand (idempotent — avoids duplicate pinrefs, e.g. ALU U16 GND)
    - regenerated all 7 boards (.sch/.brd), 0 validation er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
    [p8x-alu-card.brd, p8x-alu-card.sch, p8x-cf-card.brd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]
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2026-06-19 feat(backplane): row-B even pins become spare bus lines (SPARE12-23)
    Row B was a solid ground guard (B3-26 all GND). Per request, B3-26 now ALTERNATE:
    odd pins stay GND (still a guard between most signal pairs), and the 12 even pins
    (B4,B6,..,B26) become spare bus lines SPARE12-SPARE23, routed slot-to-slot — so
    new signals can be added later without re-spinning the backplane. B27-30
    (CLRC/BSEL/IRQ/SPARE11) unchanged.
    - busnet() updated in all three copies (gen_eagle, gen_bus_pdf, gen_bus_card)
    - backplane .brd routes the 12 new spares (mirrors the B27-30 routing); odd-pin
    grounds remain on the GND pour
    - every card regenerated: their connectors no longer tie the even B pins to GND
    (th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
    [p8x-alu-card.brd, p8x-alu-card.sch, p8x-backplane.brd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]
2026-06-19 refactor(generators): make gen_eagle import-safe (no file writes on import)
    Importing gen_eagle (renderers and consistency checks do, for busnet/DEV/CARDS)
    used to regenerate every board into the current directory as a side effect — so
    an `import gen_eagle` from the repo root scattered board files there (hit twice
    during routine work). Gated all write_sch/write_brd/validate calls behind
    EMIT = (__name__ == "__main__"); the net/CARDS data is still built on import,
    only file emission is now main-only.
    Verified: importing from the repo root populates CARDS with no stray files;
    running directly from hardware/ still emits all 8 boards (0 errors); the
    renderers still work. BACKLOG housekeeping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
    [gen_eagle.py]
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2026-06-19 refactor(generators): build the memory card through card() like every other card
    The memory card was the last board still hand-built (its own coordinate-laden
    parts dicts + mnet + manual caps/power/connector + separate board layout) — a
    leftover from before the card() helper existed. Converted it to card(): it now
    declares only its functional netlist (via the local mnet helper) and hands it to
    card(), which supplies the DIN96C connector, per-IC decoupling, IC power pins,
    and the J1 bus/power wiring from used_bus + busnet(). Placement is auto (final
    layout happens in Fusion/Eagle anyway).
    This also FIXES a latent short the rev-D bus change introduced: the memory card
    hand-wired every row-B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
    [p8x-memory-card.brd, p8x-memory-card.sch]
2026-06-22 feat(generators): faithful Eagle/Fusion output (values, layers, smashed parts)
    Make the generated .sch/.brd match how Eagle itself writes files, so Fusion
    displays everything correctly (was mis-mapping names/values to scratch layers):
    - devicesets get uservalue="yes" so the `value` field is honored at all (it was
    silently ignored before — no card's value ever displayed)
    - emit the COMPLETE standard Eagle layer table (62 layers) in every drawing, so
    Fusion has nothing to remap on import
    - board elements are now smashed="yes" with explicit NAME (tNames/25) and VALUE
    (tValues/27) attributes — refdes + part number show reliably
    - add std <attributes>/<variantdefs> board sections + boa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
    [p8x-alu-card.brd, p8x-alu-card.sch, p8x-backplane.brd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]
2026-06-22 feat(generators): roll out part-number values + function labels to all cards
    Apply the value=part-number / function-as-label convention across every card
    (was proven on the LED card). A device->part-number map (PN) + a small resolver
    in card() do it automatically:
    - logic/memory ICs -> generic type numbers (74HCT138, 74HCT244, 28C64, 6850,
    MAX232, ...); the old per-part function text becomes the placed schematic label
    - LEDs -> value = colour (GRN/YEL/RED), function -> label (POWER, RUN, HALT, ...)
    - switches -> SPST, function -> label (RUN/HALT, STEP, RESET)
    - headers -> 1x3 / 1x4, function -> label (CLKSEL, RTC 3-WIRE, SERIAL)
    - gate arrays / passives / connectors keep their value (74HC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
    [p8x-alu-card.brd, p8x-alu-card.sch, p8x-cf-card.brd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]
2026-06-22 feat(generators): unplaced boards by default for all plug-in cards
    card() now defaults brd_unplaced=True, so every plug-in card's .brd ships as
    board outline + parts parked off-board + ratsnest (no auto-placement, no copper)
    — placement and routing are done in Fusion, so the generated layout was throwaway
    anyway. The backplane is hand-built (not via card()) and keeps its placed,
    routed layout. All 8 boards validate (0 errors).
    [p8x-alu-card.brd, p8x-cf-card.brd, p8x-control-card.brd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]
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2026-06-22 feat(hardware): use con-vg DIN 41612 footprints (MABC96R card / FABC96S backplane)
    Replace the hand-rolled DIN96/DIN96C connector packages with the real Eagle
    con-vg DIN 41612 footprints (geometry baked into the generator so it stays
    self-contained): card edge = MABC96R (male right-angle), backplane = FABC96S
    (female vertical) — both A/B/C @ 2.54mm, drill 0.9144, two M2.5 mounting holes
    at y=+/-45. Card value -> MABC96R; pin->pad names unchanged (A1..C32) so the
    netlist is intact.
    con-vg centres the pad field on the element origin, so the backplane (hand-
    placed/routed) was re-derived: slots dropped to y=54.6 to centre the pin field
    on the 109mm board (pads now on-board), bus traces re-ro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
    [p8x-alu-card-full.brd, p8x-alu-card.brd, p8x-alu-card.sch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]
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2026-06-22 fix(backplane): clear the FABC96S placement overlaps
    The taller FABC96S connector (mounting holes reach y~99.6) crowded the
    terminator/LED strips. Resolved with no remaining overlaps:
    - power LED (RL1/LED1) + its trace dropped to the bottom strip (y=3), clear of J1
    - clock terminators raised out of the slot-hole band (RT1/CT1 y->103.5,
    RT2/CT2 y->106.5) with their CLK/CLKB termination routing shifted to match
    - CT2 (whose C_DISC pads span 5.1mm) slid into the slot-8/9 gap (x=207) so its
    lower pad no longer clips J9's A-column
    All 8 boards validate with 0 errors and 0 footprint-overlap warnings.
    [p8x-backplane.brd]
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2026-06-22 docs: render US passive symbols in the backplane schematic PDF
    render_bp_traditional drew every part as a box. Import gen_eagle (EMIT-gated,
    writes nothing on import) to borrow the shared PASSIVE_ART geometry and add a
    disc() drawer that maps each symbol's pin ends onto twopart's existing stub
    positions — so the clock terminators (RT1/RT2 + CT1/CT2), bulk caps CB1/CB2,
    per-slot decoupling C1-C10, bleed resistor RL1, and power LED1 now render as
    proper US symbols. Connectors (J1-J10, J11) and the RN1 resistor network stay
    boxes, the correct convention for those. Spaced out the power section and the
    second clock terminator so labels no longer collide.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
    [render_bp_traditional.py]
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2026-06-22 feat(hardware): M3 mounting holes on the backplane
    Add 3 M3 mounting holes (drill 3.2mm) along each long (280mm) edge, evenly
    spaced at 100mm pitch and symmetric about board centre (x = 40/140/240).
    - write_brd gains a `holes` param that emits board-level <hole> elements in the
    <plain> section (mechanical, non-plated) — generic, available to any board.
    - Backplane height raised 109.22 -> 116.0mm so the top-edge holes (y=111) clear
    the decoupling-cap row at y=104.14; bottom holes (y=5) sit in the margin below
    the slot pad field.
    - render_board_pdf draws plain mounting holes (drill + keepout ring) so they
    show in the placement view.
    Validation: 0 errors, 0 footprint overlaps.
    Co-A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
    [p8x-backplane.brd]
2026-06-22 feat(hardware): widen backplane, clear bottom holes + RN1 from connectors
    - Lift the whole slot field and its routing up 7mm (YOFF) to open a bottom
    margin: the bottom mounting holes were only ~4.6mm above the connectors' own
    mount holes; now they sit in a clean band below them. RL1/LED1 and the LED_A
    net stay pinned to the bottom edge.
    - Widen the board 280 -> 290mm (and height 116 -> 123 from the lift) so the
    end-zone cluster has room.
    - Move RN1 off slot 10 (246.38 -> 252.0; gap to the C column 2.5 -> 8.2mm) and
    extend the row-3..10 A-row D-bus traces to follow it so its R1..R8 pads still
    land on them. Clock risers/terminators shifted right to keep clearances.
    - Mounting holes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
    [p8x-backplane.brd]
2026-06-22 feat(hardware): open front bay on backplane for power entry
    Shift the slot field + routing right by XOFF=16mm to open a front (left) bay, and
    keep the power-entry cluster pinned to the front edge:
    - More room for J11 (power terminal) and the bulk caps between the front edge and
    slot 1 (gap ~7.6 -> ~24mm).
    - CB1/CB2 470uF caps spread farther apart (~10 -> 23mm).
    - RL1/LED1 (power LED + bleed resistor) brought forward to the front-left corner.
    Board 290 -> 306mm wide; right-side cluster (RN1, terminators) and mounting holes
    shift with the slot field. Validation: 0 errors, 0 footprint overlaps.
    [p8x-backplane.brd]
2026-06-22 feat(hardware): cap polarity silkscreen + nudge backplane decoupling caps
    - Add a '+' polarity mark to the CP_RADIAL footprint silkscreen (layer 21) beside
    pad 1, so polarized parts are unambiguous on the board: the backplane bulk caps
    CB1/CB2 and the io card's RTC backup coin cell. Done via a new PKG_SILK table
    emitted by lib_xml, and drawn in the placement PDF too.
    - Move the backplane per-slot 100nF decoupling caps up off the slot connectors
    (y 104.14 -> 109.0); top mounting holes raised to y=123 and board height
    123 -> 128mm so the caps still clear the holes.
    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
    [p8x-backplane.brd, p8x-backplane.sch, p8x-io-card-full.brd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]
2026-06-22 fix(hardware): more spacing between backplane LED1 and RL1
    Move the power LED right (LED1 x 18.0 -> 21.0) so it isn't crowded against the
    bleed resistor RL1; extend the LED_A trace to match. Validation: 0 errors, 0
    footprint overlaps.
    [p8x-backplane.brd]
2026-06-22 fix(hardware): trim backplane to 300mm wide
    Reduce the front-bay shift (XOFF 16 -> 10) so the slot field and end-zone cluster
    move left, and bring the power connector J11 + bulk caps CB1/CB2 in toward slot 1
    (x 5.08 -> 9.0). Board 306 -> 300mm wide; mounting holes land at symmetric 50mm
    margins. Validation: 0 errors, 0 footprint overlaps.
    [p8x-backplane.brd]
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2026-06-23 feat(hardware): RAM2 bank-activity LED on the memory card (rev D)
    Add a yellow RAM2 LED (LED7 + RS5) that lights when the new $4000-$7FFF bank
    (U10) is addressed. Driven by U7's last spare NAND wired as an inverter, which
    flips -RAM2CE to active-high and sources the LED through RS5. It's a bank-select
    indicator (not -BOE-gated like the ROM/RAM/RD/WR LEDs — that would need another
    spare gate, and only one remained). Validation: 0 errors, 0 overlaps; full
    emulator suite still passes. Docs: memory-card README + theory.
    [p8x-memory-card-full.brd, p8x-memory-card.brd, p8x-memory-card.sch]
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2026-06-23 docs: fix remaining stale memory-map references (rev D / OS @ $4000)
    A currency sweep after the rev-D / OS-$4000 / v2-only work turned up a few
    spots still showing the old $0000-7FFF ROM / $8000 OS-load:
    - CLAUDE.md memory-map line -> rev D (16K ROM / 48K RAM, OS @ $4000, P8XFS v2).
    - gen_isa_card.py memory line -> rev D; regenerated docs/p8x-isa-card.pdf.
    - memory-card theory block diagram -> A15/A14 decode (ROM $0000-3FFF, U10
    $4000-7FFF, U2 $8000-FEFF), -WE feeds U2/U10.
    - p8xasm.py --base help examples: "loaded to $8000" -> "$4000".
    Verified no remaining stale old-map / v1-filesystem / OS@$8000 references in
    code, comments, help text, READMEs, or PDF generators (the $8000-FEFF RAM ba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
    [gen_isa_card.py]
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2026-06-23 feat(apps): native two-pass assembler ASM (TPA program)
    Completes the on-target toolchain: RUN ASM.BIN SRC.ASM OUT.BIN reads a source
    from disk and writes a runnable binary. Supports labels, equates, all
    instruction operand shapes, the LDPn pseudo, .org/.byte/.word/.ascii/.asciiz/
    .fill, and $/decimal/'c'/symbol expressions with +/- and </> — a subset of the
    host assembler with identical encodings.
    The opcode table is generated from genucode.OPC (generators/gen_p8xopc.py) and
    concatenated after the assembler logic at build time, so encodings can't drift
    from the microcode. Conventions: P1 is the source cursor preserved across
    helpers; P3 (system stack) is untouched; errors long-jump to th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
    [gen_p8xopc.py]
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
